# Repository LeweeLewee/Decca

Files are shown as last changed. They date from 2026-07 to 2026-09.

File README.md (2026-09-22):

# Decca music-centre restoration

ESP32 firmware, hardware and mechanical design for restoring a 1960s Decca
music centre while preserving its original controls and appearance.

The ESP32 provides control and user interface only. Audio remains outside it:
the locked Phase 2 path is **WiiM Pro → Fosi Audio ZA3 → passive speakers**.

## Current state

- Installed firmware is **v0.28.6-s1**, deployed by authenticated OTA on
  2026-09-21. TX power explicitly requests 20 dBm (19.5 dBm readback); Wi-Fi
  sleep remains disabled. Packet loss remains open as **FW-WIFI-01**. The
  following physical acceptance was recorded on v0.28.4. Digital and vinyl audio, metadata, volume/app
  synchronisation, left/right channels, logical standby/resume, source response,
  network recovery and direct WiiM-to-ZA3 trigger acceptance pass. The owner confirmed all formal noise/interference checks passed with no
  issues on 2026-09-21, completing Phase 2 physical acceptance.
- Security resource-limit update is deployed; fresh version discovery and OTA
  authentication rejection passed. The owner confirmed physical checks passed on 2026-09-22. See
  [deployment record](docs/OTA%20Candidate.md).
- Safe board initialisation and authenticated local-network OTA are implemented.
- Four analogue controls and the SH1106 OLED are bench-verified.
- The reliable VHF contact is the sole source input:
  VHF latched = Digital Streamer; every other selector position = Vinyl.
- GPIO25/D25 is assigned to the Stereo/Mono contact as a lighting request:
  Stereo open = lights on immediately; Mono closed = lights off immediately
  after the 25 ms debounce. Firmware logic is correct,
  but the retained physical switch is faulty and remains open as HW-SW-01.
- The display, buttons, pots, settings, lighting and logical power modules are
  implemented and independently tested.
- The Phase 2 WiiM module is implemented as a background HTTPS worker for source,
  direct absolute volume over a reusable connection, power-state and metadata
  coordination. Logical power-on sends a safe one-step downward volume pulse,
  then restores the requested value, so a stopped network session wakes the
  WiiM trigger without starting playback or exceeding the selected volume.
- The OLED reports controller Wi-Fi strength in the top-left header and
  distinguishes controller-network loss from an unresponsive WiiM. Passive
  telemetry updates while already in standby do not wake the sleeping panel.
- Production coordinates power, all four pots, the VHF-derived source state and
  the accepted OLED views, and 85% Stereo/off Mono dial lighting while
  continuously servicing authenticated OTA.
- USB-to-OTA, GPIO14 power, GPIO26 VHF source selection and the fitted display
  are complete. The DFR0457 replacement stage is installed and its initial
  steady-light test resolved the flicker. Firmware v0.28.4 retains immediate
  lighting transitions. Physical transition verification after HW-SW-01, WAGO
  distribution, pot stability, temperature and current remain open as
  HW-LGT-01. Normal Stereo lighting is 85%; Mono and logical standby request off.
- v0.27.4 removes the fade engine: Stereo/Mono and logical power changes now
  apply the required LED duty immediately.
- ESP32 controller housing Rev C was printed, fitted, wired and installed as a
  prototype on 2026-09-07. Its CAD/mesh gates pass; seven prototype and two
  installation gates remain before production release.
- IEC C14 mounting plate Rev B is the active corrected-profile design. Its
  15/15 CAD checks pass and the owner confirmed the profile drawing; physical
  fit remains pending. Rev A is rejected.
- The completed 2026-09-06 ADC/PWM noise report and its 12,000-row raw capture
  are retained under `diagnostics/` as historical v0.27.1 evidence.

Read [Development Handover](docs/Development%20Handover.md) before continuing
firmware work, then check [Open Issues](docs/Open%20Issues.md).

## Locked controller map

| Function | ESP32 | Status |
|---|---:|---|
| Volume | GPIO32/D32 | Bench-verified |
| Bass | GPIO33/D33 | Bench-verified |
| Treble | GPIO34/D34 | Bench-verified |
| Balance | GPIO35/D35 | Bench-verified |
| VHF source contact | GPIO26/D26 | Physically verified |
| OLED SDA | GPIO21/D21 | Bench-verified |
| OLED SCL | GPIO22/D22 | Bench-verified |
| On/off | GPIO14/D14 | Physically verified |
| Stereo/Mono lighting request | GPIO25/D25 | Firmware logic verified; physical switch fault open under HW-SW-01 |
| Dial lighting PWM | GPIO18/D18 | DFR0457 installed and operating; final checks open under HW-LGT-01 |

Final OLED loom: Brown GND, Red 3V3/VCC, Orange SCL and Yellow SDA.

## Repository guide

- [Specification](docs/Specification.md)
- [Firmware architecture](docs/Firmware%20Architecture.md)
- [Hardware architecture](docs/Hardware%20Architecture.md)
- [Authoritative wiring](docs/Wiring.md)
- [Build and commissioning guide](docs/Build%20Guide.md)
- [Parts list](docs/Parts%20List.md)
- [Decision records](docs/adr/)
- [Development handover](docs/Development%20Handover.md)
- [Open issues](docs/Open%20Issues.md)
- [Branch disposition register](docs/Branch%20Disposition.md)
- `src/`: firmware modules
- `test/`: PlatformIO suites
- `hardware/`: BOM, wiring and electrical design
- `mechanical/`: CAD, drawings and print files
- `diagnostics/`: completed diagnostic evidence; not production firmware

## Windows build tools

If `pio` is not recognised in PowerShell, use the executable installed by the
PlatformIO VS Code extension:

```powershell
$pio = "$env:USERPROFILE\.platformio\penv\Scripts\platformio.exe"
& $pio --version
& $pio run -e esp32dev
& $pio test -e esp32dev
```

The first OTA bootstrap and commissioning procedure is in the
[Build Guide](docs/Build%20Guide.md). Never commit `src/secrets.h`.

## Engineering rules

Firmware modules remain independent and are coordinated in `main.cpp`. Update
paths must be non-blocking, persisted state belongs in `settings`, and hardware
changes must be reconciled across the pin map, wiring, BOM and revision history.

See [CONTRIBUTING.md](CONTRIBUTING.md) for code and commit conventions.

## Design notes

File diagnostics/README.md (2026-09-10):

# Diagnostics archive

## ADC/PWM noise capture — 2026-09-06

The report, device summary and 12,000-row raw capture preserve the completed
controlled comparison between 85%/1 kHz PWM and constant-high operation. The
test ran diagnostic firmware v0.27.1 on the former GPIO25 lighting route.

The result is historical evidence, not current firmware: PWM switching was a
modest contributor to raw ADC noise, while the normal filter/deadband path
produced no UI-sized filtered excursions in either phase. No brightness or
production-filter change was justified by the result.

Current production firmware is v0.27.4, lighting PWM is on GPIO18, and all fade
logic has been removed. The diagnostic-only firmware hooks were intentionally
not copied into production because they depend on the superseded fade API and
old GPIO route. The report and raw data are the authoritative retained record.

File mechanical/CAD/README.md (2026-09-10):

# CAD

Source (editable, parametric) mechanical design files.

## ESP32 controller housing — Rev C installed prototype

Rev C is the current housing geometry. The owner printed, fitted, wired and
installed it on 2026-09-07; it fitted first time. The package remains a
prototype rather than a production release because seven prototype gates and
two installation gates remain open in the v1.7 specification.

- `Decca_ESP32_Controller_Housing_fusion.py` is the parametric generator.
- `Decca_ESP32_Controller_Housing_verify.py` independently verifies the STLs.
- `Decca_ESP32_Controller_Housing_slice.py` records slicer evidence.
- `Decca_ESP32_Controller_Housing.f3d` and the STEP files are the editable and
  neutral CAD deliverables.

Rev A and Rev B are superseded. The controlling documents are
`../Drawings/Decca_ESP32_Controller_Housing_Spec_v1.0.md` (content revision
v1.7) and `../Drawings/Decca_ESP32_Controller_Housing_Build_Report_revC.md`.

## IEC C14 mounting plate — Rev B active prototype

Rev B replaces the rejected rectangular Rev A opening with the measured
six-sided C14 profile. Its generated STEP/STL passed all 15 CAD checks and the
owner confirmed the drawn profile. Physical inlet/cabinet fit and rear terminal
clearance remain mandatory before release. Rev A sources are retained only for
traceability and must not be used for installation.

**Intended contents**
- Fusion 360 archives (`.f3d`) and/or OpenSCAD (`.scad`) source.
- Neutral exchange formats (STEP `.step`) for interop.

**Conventions**
- Keep source here; export print-ready meshes to `../STL/`.
- Parametric source is preferred so parts can be re-derived if dimensions change.
- Record revisions in `docs/Revision History.md`.

## Display bezel — current revision: **Q — COMPLETE, signed off 2026-08-31**

**Rev Q is bezel-only. The released Rev P.5 carrier is FROZEN and unchanged.**

Rev Q replaces the two Rev N side locating rails with **one continuous inset
masking wall** around the complete inside perimeter of the Perspex opening —
left, right, top, bottom and all four corners. The wall conceals the visible
cut edge and locates the bezel on an **interference fit on both axes**. It is
not a snap, not a clamp and carries no load. The two Rev N recessed adhesive
pads are DELETED at owner instruction, so retention is by the fit alone; if
adhesive is still wanted it goes on the flat seating face.

Built to brief commit `7b107f2` ("require two-loop inset wall"), then moved on
by four owner changes made on the model. Every wall carries **at least two
0.40 mm extrusion loops** — a minimum applied per side, not a fixed count.

> **THE PERSPEX OPENING HAS BEEN MEASURED, and it is not what this project
> believed.** For six revisions the model carried 35.20 × 15.30 from Rev C — a
> figure no released part had ever checked, because Rev N located on two side
> rails only. The owner printed the 35.400 × 15.450 insert, used it as a gauge
> block and read the slop: **1.34 mm horizontal, 1.00 mm vertical**. The opening
> is **36.74 × 16.45**, and the insert is now DERIVED from it:
> `insert outer = measured opening + declared interference`. Re-measuring is a
> two-number edit. Treat the reading as ±0.2 mm; a second iteration is expected.
> Build report §3.10.

| File | Role |
|---|---|
| `Decca_Display_Bezel_revQ_fusion.py` | **the generator — single source of truth for every Rev Q dimension** |
| `Decca_Display_Bezel_revQ_verify.py` | independent offline verification of the exported STL (numpy only) |
| `Decca_Display_Bezel_revQ_frozen_check.py` | proves the six frozen Rev P.5 files still match the Rev Q brief — run before and after any Rev Q work. Hashes text files as-is, forced LF and forced CRLF, so a line-ending difference cannot masquerade as tampering |
| `Decca_Display_Bezel_revQ.f3d` | **editable source** — named parameters, derived values written as real formulas |
| `Front_Bezel_revQ.step` | the bezel alone |
| `Decca_Display_Bezel_revQ_assembly.step` | bezel + measured Perspex + OLED glass proxy + the **unchanged Rev P.5 carrier**. Does **not** overwrite `Decca_Display_Mount_revP_assembly.step` |
| `Bezel_Fit_Gauge_revQ.step` | five-tab interference fit gauge — **print this before the bezel** |

Key dimensions, each verified by two independent tools:

| | mm |
|---|---:|
| Bezel face opening, at the front face | **34.440 × 15.000**, R3.000 |
| Aperture | a **straight bore** — identical at the front face and the seating plane, taper 0.00° |
| **Perspex opening, MEASURED 2026-08-31** | **36.740 × 16.450** |
| Inset-wall outer envelope | **36.940 × 16.600** — derived, opening + fit |
| Inset-wall inner envelope (derived) | 34.440 × 15.000 — **flush with the face opening on all four sides** |
| Wall | **1.250 sides** (3.125 loops) / **0.800 top+bottom** (2.000 loops) |
| Outer / inner corner radius | **R4.250** / R3.000 (derived from the side wall) |
| Wall depth | **2.800** into the 3.00 mm Perspex — 2.300 tried and reverted |
| Horizontal fit | **0.100 INTERFERENCE per side** |
| Vertical fit | **0.075 INTERFERENCE per side** |
| Entry lead-in | 0.200 × 45°, outer rear edge only — tip is 0.100 / 0.125 mm per side UNDER the opening |
| Rearmost material | z = **+0.200** — 0.200 clear of the Perspex rear face |
| Clearance to the OLED glass | **0.500** — the brief minimum, and the released Rev N/P value |
| Minimum distance to the Rev P.5 carrier | **0.339** — carry this forward |
| Effective clear optical opening | **34.440 × 15.000**, R3.000 |
| Seating face | one unbroken annulus, 210.867 mm² (adhesive pads deleted) |
| Volume | 0.5951 cm³ ≈ 0.76 g in PETG |

**52/52 gates PASS** in Fusion; **47/47 PASS** offline from the mesh. One shell,
one lump, zero slivers, no degenerate triangles; the wall's cross-section area
matches the analytic value to four decimals at three depths and in every region
including the corners; the interference is exactly 0.100 mm per side across and
0.075 mm up, nowhere more, and vanishes when the declared relief is applied;
zero interference with the OLED glass or the carrier; nothing behind the
Perspex rear face.

> ## Signed off — 2026-08-31
>
> **The bezel is complete.** Confirmed on printed parts: the interference
> fit, the opening corner (R4.25 a good match) and the opening dimensions
> themselves. A 2.30 mm insert depth was tried and **reverted** when the
> bottoming-out that prompted it turned out to be a printing issue rather
> than the geometry — the depth is back at the proven Rev N 2.80 mm.
>
> **Not separately reported at sign-off:** the slicer two-loop preview and
> the powered visibility test. Parts printed and fitted, so the wall
> evidently laid, but neither was run as a check.
>
> **One figure to carry forward:** the bezel passes within **0.339 mm** of
> the frozen Rev P.5 carrier. Zero interference, and it has been assembled,
> but worth re-checking if either part is reprinted on a different machine.
> Build report §3.11–§3.12.

> **The fit is the primary gate.** 0.100 / 0.075 mm per side is an ordinary
> press fit on paper, but acrylic is brittle and takes up interference by
> storing stress rather than deforming, the 1.25 mm side wall is ≈31× stiffer
> in bending than the original 0.40 mm, and **print tolerance is the same size
> as the fit** — ±0.10 mm on a small external dimension, so 0.100 mm intended
> arrives anywhere between 0.00 and 0.25 mm. No CAD check can touch that.
> **Print `Bezel_Fit_Gauge_revQ` first** — five tabs at
> 0.00/0.05/0.10/0.15/0.20 mm, which now brackets the declared value two either
> side, each carrying the real wall section, the full 16.60 mm height, the
> 2.80 mm depth and both R4.25 corners — and the sweep brackets the ±0.2 mm
> **measurement** error as well as the fit. Also plan on adhesive: **PETG
> creeps**, so a press fit slackens over months. Build report §8.1, §8.4.

> **The loop rule is a PRODUCTION gate, not a CAD one.** CAD proves the
> geometry admits the loops: sides 1.250/0.400 = 3.125, top and bottom
> 0.800/0.400 = 2.000 exactly, measured at all 720 stations (min 0.7950, max
> 1.2500) including 368 corner stations, loop centrelines 0.400 apart with
> corner radii 4.050 and 3.650 and no cusp — the easiest to slice at any issue.
> Only the slicer preview can prove it lays them. Build report §7.1 and §10
> Stage 0b.

> **The opening corner is largely closed — by a printed part.** The owner offered
> the R4.25 insert into the real opening and reports the corner **a good match**,
> retracting an earlier appearance-based revert in as many words. At R4.25
> against the measured opening the **flanks set the fit for every plausible
> opening corner**: penetration never leaves 0.100 mm from a sharp corner all the
> way to R4.00. `panel_open_corner_r` stays 0.00 in the model, because a
> qualitative match is evidence rather than a measurement and modelling the
> opening sharp keeps every figure at its worst case. Build report §8.3.

> **Seven owner changes on top of the brief, each recorded and each reversible.**
> (1) adhesive pads **deleted**; (2) outer corner **R2.00 → R3.00**; (3) aperture
> made **flush** on the left and right, loop rule clarified to **at least** two
> per side; (4) the **interference-fit refinement**, which appeared not to fit;
> (5) the **pull-back**; (6) the corner **reverted to R3.00** on the render;
> (7) **the opening measured** — which restored the corner to R4.25 on physical
> evidence, showed the recorded opening was 1.54 × 1.15 mm small, and made the
> insert derive from the measurement; (8) **the depth cut 2.80 → 2.30** after a
> printed part bottomed out before seating; and (9) that cut **reverted** when
> the cause proved to be a printing issue, followed by **sign-off**. Build report
> §3.5 to §3.12.

> **The wall no longer costs lit screen height.** The clear opening is
> 34.44 × 15.00, controlled by the skirt on all four sides with the face
> opening flush to it, and the visible active band goes 8.100 → **8.150 mm** —
> **above Rev N for the first time**, because the opening was always bigger than
> recorded. What is worth judging instead is the noticeably slimmer black
> border: the bezel flange is now 1.530 mm at the sides. Build report §5.

> **The aperture does not taper.** With the face opening flush to the skirt on
> all four sides there is nothing to blend, so the bore is straight from the
> front face through to the wall tip — no ledge, no set-back, no corner
> crescent. The forced Y taper earlier issues carried is designed out, and the
> generator **refuses to build** if the face opening drifts away from the skirt
> inner envelope. The window edge break is a 0.40 chamfer rather than the Rev N
> R0.40 fillet, because Fusion refuses a fillet on that edge at every radius.
> Build report §3.3 and §3.4.

### Rebuilding Rev Q

Inside Fusion (Utilities → Add-Ins → Scripts), point `OUT_DIR` at this clone's
`mechanical` folder and run `main()`, `import_carrier()`, `coupon()`,
`fit_study()`, `validate()`, `export()` and `snapshots()`. `main()` creates its
own new document and never opens, modifies or saves the Rev N, Rev O or Rev P
documents; `export()` refuses, in code, to write any path whose basename
contains `revN`, `revO` or `revP`. Then, offline:

```bash
python mechanical/CAD/Decca_Display_Bezel_revQ_verify.py
python mechanical/CAD/Decca_Display_Bezel_revQ_frozen_check.py
```

`Front_Bezel_revN.step` remains the last **released** bezel and is untouched.

---

## Display mount — current revision: **P.5 — RELEASED**

**The Rev P.5 carrier has been manufactured, installed and physically tested,
and every test passed:** Perspex fit and tolerances; OLED front insertion and
removal; all four sprung posts and retention; no collision with the original
Decca lighting unit; bottom / open connector-side clearance; the reduced
6.00 mm thickness; the enlarged 14.00 × 4.19 mm connector opening; the rear
closure and light-blocking features; the original fasteners and captive nuts;
49.00 mm horizontal pitch; the mounting points 7.00 mm lower giving the
required OLED position; and installed fit, screen position, stiffness,
retention, clearance and powered operation.

Rev P.2 is the corrected **flush-side-insertion** architecture, and it **passed**
its physical OLED-retention and Perspex-fit tests. **Rev P.3** amended only the
radio-side interface: the lighting-unit clearance cut and the original Decca
bolt / captive-nut interface that replaces the deleted M2 heat-set inserts.
**Rev P.4** makes two bounded corrections on top of that:

- the **synthetic lighting-unit keepout is deleted** — component, body,
  generator function, derived geometry, intersection checks and exports. Its
  boundary was asserted from the carrier's own pedestals, not measured off the
  radio, so it proved nothing and misrepresented the assembly. Nothing replaces
  it, and the physical rail cut it was invented to justify is kept exactly as
  printed. **Installed clearance is proven by physical test only** — see the
  build review §20.6;
- the **rear of the OLED bay is closed** by a 1.20 mm integral opaque light
  shield, part of the carrier, with a single local four-pin/header opening —
  build review §24.

**Rev P.5** is a mandatory amendment that changes load-bearing numbers:

- both **plain locating posts are deleted** and replaced by sprung
  locating-and-retaining posts — all four PCB mounting holes now hold a split
  sprung post, and no plain-post parameter, body, branch or probe survives;
- the complete OLED reference is rotated **180° in plane**, so the four-pin
  connector is at the **bottom**. The panel-fixed holes do not move. **The open
  lighting-unit end of the carrier travelled with the module, +Y → −Y**;
- both carrier fixing centres then move **7.00 mm toward that bottom** relative
  to the OLED group (`carrier_fix_y_from_previous = -7.00 mm`). The Perspex
  holes are untouched, so the equivalent — and the only implementation that
  lands the carrier holes *on* them — is to raise the OLED bay **+7.00 mm**.
  This **supersedes** the earlier active-area-bottom-to-opening-bottom rule and
  every PASS based on it;
- the carrier drops to **6.00 mm** deep, the finished rear opening grows 25 % to
  **14.00 × 4.19 mm**, and two integral **light-block** baffles are added
  beside it, running out into the sprung pedestals.

Nothing numeric is inherited: the depth reduction shortens every cantilever, so
the split slot goes 0.70 → 1.20 mm and the root relief 3.20 → 2.00 mm. Build
review §25.3 has the recalculation.

> **The screen is no longer fully visible.** Only **8.30 mm** of the 14.70 mm
> active height falls inside the Perspex opening; about **6.40 mm — 44 % —**
> sits behind the fascia above it, and the lowest 7.00 mm of the opening shows
> unlit board. Both tools **report** this and neither passes a check on it.
> Whether the intended screen information is still readable is a question only
> the powered fit test can answer. Build review §28.3.

> **The bonded-glass boundary is now THE print gate.** The two converted posts
> put a nose ahead of the PCB at holes the plain posts never reached, and the
> modelled glass envelope — which has never been measured, and which puts the
> glass over the mounting holes — says it fouls by 0.40 mm. Both tools report
> those checks as **BLOCKED**, not passed and not failed. Measure the boundary,
> enter it, set `oled_glass_measured` / `GLASS_MEASURED`, and they become
> ordinary hard gates. Build review §25.4.

The `.f3d` is the source of truth; the STEPs and the STL are derived exports.

| File | Role |
|---|---|
| `Decca_Display_Mount_revP.f3d` | **editable source of truth** — fully parametric, 192 named user parameters |
| `Decca_Display_Mount_revP_fusion.py` | the generator that builds the `.f3d`; single source of truth for every dimension |
| `Decca_Display_Mount_revP_verify.py` | independent offline verification of the exported STL (numpy only) |
| `Rear_Display_Carrier_revP.step` | the one structural part |
| `Decca_Display_Mount_revP_assembly.step` | carrier + Perspex + OLED + bezel + **original nuts / bolt envelope** references. **No lighting-unit keepout proxy** — Rev P.4 deleted it, and both tools assert its absence |
| `Hex_Pocket_Fit_Coupon_revP.step` | five-station captive-nut pocket fit coupon — print this **before** the carrier |
| `Front_Bezel_revN.step` | cosmetic bezel — **unchanged, still the file of record for Rev P**. Superseded for new work by the signed-off Rev Q above |

Rev N files are retained as the last front-loaded design:
`Decca_Display_Mount_revN.f3d`, `Decca_Display_Mount_revN_assembly.step`,
`Rear_Display_Carrier_revN.step`, `Retainer_Bar_revN.step`. The Rev P
architecture deletes the retainer bar, so `Retainer_Bar_*` has no Rev P
equivalent.

### Rebuilding

Inside Fusion (Utilities → Add-Ins → Scripts), point `OUT_DIR` at this clone's
`mechanical` folder and run `main()`, `validate()`, `import_bezel()`,
`snapshots()`, `export()`, and `coupon()`. `main()` creates its own new document
and never modifies the Rev N or Rev O files; `snapshots()` regenerates the five
Drawings PNGs from the live model; `coupon()` builds and exports the hex-pocket
fit coupon in its own document. Then, offline:

```bash
python mechanical/CAD/Decca_Display_Mount_revP_verify.py
```

It reads only the exported STL and exits non-zero on failure, so it works as a
gate. See `../Drawings/Decca_OLED_Display_Mount_CAD_Build_revP.md` §13 for why
it is deliberately not a second run of the same recipe — and for the silent
Fusion `createTorus` failure it caught.

> **Rev P.5 is RELEASED.** Every item that was outstanding here — the
> bonded-glass clearance, the original nut and bolt fit, the hex-pocket
> allowance, installed lighting-unit clearance, the light-leak test and the
> powered fit — was closed by the built and tested prototype. Both tools record
> them as `[TEST]`, and neither check was changed to get there.

> **What is still a modelling caveat, and is not a blocker.** Two inputs in
> the parameter table were never measured, and the prototype passing did not
> measure them:
>
> - `oled_glass_w` / `_h` / `_off_y` — the bonded-glass envelope is still the
>   placeholder that puts glass over the mounting holes. The built part clears
>   the real glass; the **model** does not describe it. `oled_glass_measured`
>   stays `False`;
> - *(resolved 2026-08-30 — `original_nut_hex_width` was here; the 3.80 mm
>   across-flats reading is **confirmed**, so it is a measured value now)*
> - the original bolt length under the head. The bolts engage and clamp; the
>   length itself was not recorded.
>
> These matter only if the geometry is regenerated with changed dimensions. As
> built, the part is proven. Anyone changing a post, a nose, the glass keep-out
> or the nut pocket must measure first.

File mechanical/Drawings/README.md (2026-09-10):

# Drawings

Dimensioned engineering drawings for fabrication, measurement, and reference.

## ESP32 controller housing — Rev C installed prototype

`Decca_ESP32_Controller_Housing_Spec_v1.0.md` is the controlling v1.7
specification. `Decca_ESP32_Controller_Housing_Build_Report_revC.md` records the
verified build and the owner's 2026-09-07 printed, fitted, wired and installed
prototype. It fitted first time, but seven prototype and two installation gates
remain open. The Rev B report is retained as superseded history.

## IEC C14 mounting plate — Rev B active / physical fit pending

`Decca_IEC_C14_Mounting_Plate_Spec_revB.md` and its Rev B build report control
the corrected six-sided inlet profile. All 15 CAD checks pass and the owner
confirmed the profile drawing. Rev A is rejected; its specification, report and
view remain only as an explicit failure record. Do not print or install Rev A.

**Intended contents**
- PDF drawings with critical dimensions and tolerances.
- Reference sketches for cabinet fit and mounting.

## Active OLED mount design direction

`Decca_OLED_Display_Mount_CAD_Review_revO.md` is the authoritative carrier
architecture brief. It includes the 2026-08-29 Rev P physical-retention
correction: flush-side insertion onto fixed rear PCB datums, positive sprung-post
handling retention, and no release until the corrected print passes physical
retention tests. The 2026-08-29 integration amendment additionally makes the
original Decca lighting unit a mandatory physical clearance interface and
deletes the continuous carrier end rail / cable-tie projection below the
sprung-post pair as installed.
The same open Rev P correction now also deletes the M2 heat-set inserts and
replacement M2 screws: the original non-standard-thread Decca front bolts and
their matching six-sided captive nuts are reused at the unchanged 49.00 mm pitch.
The Rev P.3 follow-up rejects the unmeasured synthetic lighting-unit keepout
component and requires an integral opaque rear wall over the OLED bay, with only
a local four-pin/header opening, to prevent cabinet-light contamination.
The Rev P.5 packaging correction reduces carrier depth from 8.00 to 6.00 mm,
enlarges the finished pin opening by 25% in both axes to 14.00 × 4.19 mm, adds
two internal side light blocks within the back-plate envelope, places the
four-pin side at the bottom and moves both carrier fixing points 7.00 mm toward
that bottom relative to the OLED group. The original Perspex holes remain fixed
at 49.00 mm pitch, so this raises the screen 7.00 mm relative to the earlier
bottom-edge-aligned datum.
The same Rev P.5 amendment converts the two remaining plain locating posts to
sprung retaining posts, giving four sprung posts subject to measured glass
clearance, combined-force, PCB-bow and deliberate-release validation.

The released Rev P.5 carrier is now frozen. The active follow-on work is the
**Rev Q bezel-only amendment** in
`Decca_OLED_Display_Bezel_CAD_Brief_revQ.md`: replace the Rev N side-only
locating rails with a continuous inset masking wall around the complete Perspex
opening. A brief amendment and four owner changes have since re-scoped it — to
an interference fit with rounded corners and a larger visible opening, to a wall
carrying **at least two continuous 0.40 mm loops per side** rather than the
single loop the original 0.40 mm wall produced, and finally to an aperture that
is **flush with the skirt on all four sides**. Rev Q must not change the
carrier.

## Display bezel — Rev Q, **COMPLETE — signed off 2026-08-31**

**Rev Q is built, modelled, validated, printed, fitted and signed off by the
owner on 2026-08-31.** Built to brief commit `7b107f2` ("require two-loop
inset wall") plus four owner changes made on the model. The bezel is one
connected manifold solid: the Rev N face, envelope and external radii are
carried over, and the two Rev N side rails are replaced by a single continuous
inset masking wall, 2.30 mm deep, around all four sides and all four corners.
The wall is **1.25 mm on the sides** — thick enough for its inner face to sit
flush with the face opening, with no set-back — and **0.80 mm top and bottom**.
The bezel face opening is flush with the skirt on all four sides, so the
aperture is a straight bore with no taper. The two Rev N recessed adhesive pads
are deleted at owner instruction, so the underside is one unbroken seating face.

> **The opening has been measured, and it was not what the project believed.**
> 36.74 × 16.45, not the 35.20 × 15.30 carried from Rev C — which no released part
> had ever checked. The skirt is now **36.94 × 16.60**, derived from that
> measurement plus 0.100 mm per side across and 0.075 mm per side up. Treat the
> reading as ±0.2 mm; a further iteration is expected. Build report §3.10.
>
> **It fits, and it is signed off.** Confirmed on printed parts: the fit, the
> opening corner and the opening dimensions. A 2.30 mm depth was tried and
> reverted — the bottoming-out was a printing issue, not the geometry. The slicer
> two-loop preview and the powered test were not run as checks and are recorded
> as not-run rather than passed. Build report §3.11–§3.12.

| File | Role |
|---|---|
| `Decca_OLED_Display_Bezel_CAD_Brief_revQ.md` | **governing Rev Q brief** — the controlled requirement |
| `Decca_OLED_Display_Bezel_revQ_Build_Report.md` | **Rev Q build report and validation record — start here** |
| `Decca_OLED_Display_Bezel_revQ_front.png` | front view |
| `Decca_OLED_Display_Bezel_revQ_rear.png` | rear view |
| `Decca_OLED_Display_Bezel_revQ_oblique.png` | oblique |
| `Decca_OLED_Display_Bezel_revQ_lip_oblique.png` | rear three-quarter — the wall as a continuous closed ring |
| `Decca_OLED_Display_Bezel_revQ_assembly.png` | seated on the measured Perspex, clear of both fixing holes |
| `Decca_OLED_Display_Bezel_revQ_section.png` | section on x = 0 |
| `Decca_OLED_Display_Bezel_revQ_section_detail.png` | **the wall masking the Perspex cut edge** |
| `Decca_OLED_Display_Bezel_revQ_optical.png` | the lit OLED area behind the aperture, to scale |

The eight PNGs are generated by `snapshots()` in the Rev Q generator, so they
document the geometry that is actually in `Decca_Display_Bezel_revQ.f3d`.

Validation: **52/52 gates PASS** in Fusion and **47/47 PASS** in the independent
offline mesh verifier. One shell, one lump, zero slivers, no degenerate
triangles. Continuity is proved by **cross-section area**, which matches the
analytic value to four decimals at three depths and in every region including
the four R4.25 corners — a stronger proof than point sampling, since any gap or
thin spot anywhere removes area.

| | mm |
|---|---:|
| Bezel face opening, at the front face | **34.440 × 15.000**, R3.000 |
| Inset-wall outer / inner envelope | **36.940 × 16.600** / 34.440 × 15.000 (flush, all four sides) |
| Wall / corner radii | **1.250 sides / 0.800 top+bottom** / R4.250 outer, R3.000 inner |
| Insert depth | **2.800** — 2.300 tried and reverted, the cause was a print issue |
| Aperture | a straight bore — taper 0.00° |
| Fit | **0.100 interference** per horizontal side, **0.075 interference** per vertical side |
| **Effective clear optical opening** | **34.440 × 15.000** |

> **Three things the prototype must settle, and CAD cannot.**
>
> 1. **The fit.** 0.100 / 0.075 mm per side is ordinary on paper, but acrylic
>    stores stress rather than deforming, the 1.25 mm side wall is about **31×
>    stiffer in bending** than the original 0.40 mm, and **print tolerance is the
>    same size as the fit**. Print `Bezel_Fit_Gauge_revQ` first; it is mandatory,
>    not advisable. Build report §8.1.
> 2. **The opening measurement**, at ±0.2 mm — twice the interference it sets.
>    The gauge sweep brackets it, so one print resolves both. The opening
>    **corner** is largely closed: the owner's offer-up found R4.25 a good match,
>    and at R4.25 the flanks set the fit for every plausible corner. Build report
>    §8.3, §8.4.
> 3. **The optical result.** The clear opening is 32.90 × 13.85, the lit band
>    goes 8.100 → **8.150 mm** — above Rev N for the first time. Judge the
>    noticeably slimmer black border instead. A powered-test decision. Build
>    report §5.

> **A forced modelling decision, since designed out.** While the face opening
> was taller than the whole wall, a straight-walled aperture would have left the
> top and bottom wall runs detached from the bezel face, so the aperture tapered
> in Y. Making the face opening flush with the skirt on all four sides removed
> the condition: the aperture is now a straight bore, and the generator refuses
> to build if the two drift apart. Build report §3.3.

> **Eight owner changes on top of the brief, each recorded and each reversible.**
> The adhesive pads **deleted**; the outer corner **R2.00 → R3.00**; the aperture
> made **flush on the left and right** with the loop rule clarified to **at
> least** two per side; the **interference-fit refinement**; the **pull-back**;
> the corner **reverted to R3.00** on the render; **the opening measured** —
> which restored R4.25 on physical evidence and made the insert derive from
> the measurement; the **depth cut 2.80 → 2.30 mm** after a printed part fitted
> but bottomed out; and that cut **reverted** when the cause proved to be a
> printing issue, followed by **sign-off**. Build report §3.5 to §3.12.

## Display mount

| File | Role |
|---|---|
| `Decca_OLED_Display_Mount_Spec_v1.0.md` | approved specification, **now at v1.2** (the filename keeps `v1.0` for link stability). §2 holds the **measured and locked** Decca interface geometry: opening 35.20 × 15.30, fixing pitch **49.00 mm**. §4 opens the Rev Q bezel-only amendment. |
| `Decca_OLED_Display_Bezel_CAD_Brief_revQ.md` | **governing Rev Q bezel brief** — continuous thin masking lip around the complete Perspex opening; Rev P.5 carrier frozen |
| `Decca_OLED_Display_Mount_CAD_Review_revN.md` | last front-loaded build (Rev N) |
| `Decca_OLED_Display_Mount_CAD_Review_revO.md` | **the governing brief**, as amended 2026-08-29 by the Rev P physical-retention correction |
| `Decca_OLED_Display_Mount_Topology_revP.md` | Rev P pre-CAD topology gate. **Rev P.2 corrected topology** — flush-side insertion, fixed rear datum pads, positive stops in both axial directions; §13 the Rev P.4 rear light shield; §14–§16 the Rev P.5 four-post conversion, 180° datum and 6.00 mm depth |
| `Decca_OLED_Display_Mount_CAD_Build_revP.md` | **Rev P.5 build review and validation record** — start here |
| `Decca_OLED_Display_Mount_revP_posts.png` | **Rev P.5 carrier from the front — FOUR split sprung posts, one in every PCB mounting hole. Connector at the bottom; the two light blocks flank the four-pin opening and run out into the bottom pedestals** |
| `Decca_OLED_Display_Mount_revP_views.png` | **Rev P.5 assembly, straight on through the Perspex — where the active area actually sits in the opening after the 7.00 mm mounting correction. Rendered with appearances so it can be read: green active area, translucent fascia** |
| `Decca_OLED_Display_Mount_revP_rear.png` | **Rev P.5 rear three-quarter — the continuous integral light shield, the four post relief bores, the enlarged 14.00 × 4.19 mm four-pin opening at the bottom, and the two fixing bosses sitting LOW relative to the connector-side carrier after the 7.00 mm correction. No lighting keepout component is present** |
| `Decca_OLED_Display_Mount_revP_sections.png` | Rev P.5 section at x = +15, through a sprung locating post, with the Perspex, glass and PCB |
| `Decca_OLED_Display_Mount_revP_nut.png` | Rev P.5 half-section through a fixing centre — the bolt bore, hex head seat, retaining ridge and the original nut |

The five PNGs are generated by `snapshots()` in the Rev P generator, so they
always document the geometry that is actually in the `.f3d`.

Current mechanical revision: **P.5 — RELEASED**.

**The carrier has been manufactured, installed and physically tested, and every
test passed:**

| Test | Result |
|---|---|
| Perspex fit and tolerances | **PASS** |
| OLED front insertion and removal | **PASS** |
| All four sprung posts, retention | **PASS** |
| No collision with the original Decca lighting unit | **PASS** |
| Bottom / open connector-side clearance | **PASS** |
| Reduced 6.00 mm carrier thickness | **PASS** |
| Enlarged 14.00 × 4.19 mm four-pin connector opening | **PASS** |
| Rear closure and light-blocking features | **PASS** |
| Original fasteners and captive nuts | **PASS** |
| Horizontal mounting-hole pitch 49.00 mm | **PASS** |
| Mounting points 7.00 mm lower — required OLED position | **PASS** |
| Installed fit, screen position, stiffness, retention, clearance | **PASS** |
| Powered operation | **PASS** |

Everything below is the design and validation trail that got here. Where it
describes a check as open, blocked or awaiting a test, **that item is closed by
the prototype** — build review §29.

**Rev P.2 passed physically** for OLED retention and Perspex fit. That
architecture — flush-side insertion, fixed rear datum pads, plain and sprung
locating posts, the snap retention and release, the OLED Z position and 0.30 mm
gap, active-area centring, the 35.20 × 15.30 aperture, the exact 49.00 mm pitch,
the carrier-to-Perspex hard stops and the existing bezel — is carried forward
**unchanged**.

**Rev P.3** was a bounded amendment to the radio-side interface only:

1. the continuous end rail below the sprung-post pair and its integral cable-tie
   projection collided with the retained original Decca lighting unit, and are
   **deleted** — the carrier is now an open-ended frame (build review §20);
2. the original front bolts have a **non-standard thread**, so the M2 heat-set
   insert architecture is **deleted** and the original bolts and their matching
   nuts are reused in captive hex pockets (build review §21).

**Rev P.4** corrects two things in Rev P.3, again without touching the validated
OLED architecture:

3. the **synthetic lighting-unit keepout is deleted** — `build_light_keepout()`,
   `REF_Lighting_Keepout`, `LIGHTING_UNIT_KEEPOUT`, the derived geometry that
   placed it, its intersection checks, the fastener checks against it and every
   mention in the drawings and exports. Its boundary was asserted from the
   carrier's own pedestals rather than measured off the radio, so it could never
   fail and it misrepresented the assembly. Nothing replaces it; the proven rail
   cut is kept exactly as printed (build review §20.6);
4. the **rear of the OLED bay is closed** by a 1.20 mm integral opaque light
   shield, part of the carrier, with a single local 11.20 × 3.35 mm
   four-pin/header opening and no other penetration (build review §24).

**Rev P.5** is a mandatory amendment, and unlike its predecessors it changes
load-bearing numbers:

5. both **plain locating posts are deleted** and replaced by sprung
   locating-and-retaining posts — **four sprung posts**, one per PCB mounting
   hole (build review §25);
6. the module is rotated **180° in plane**: connector at the **bottom**,
   panel-fixed holes unmoved. The carrier's open lighting-unit end travelled
   with it, +Y → −Y (§26);
7. the carrier drops to **6.00 mm**, the finished rear opening grows 25 % to
   **14.00 × 4.19 mm**, and two integral **light-block** baffles are added
   beside it (§27).

The depth reduction shortens every cantilever, so the split slot goes
0.70 → 1.20 mm and the root relief 3.20 → 2.00 mm; worst-case post strain rises
to 2.42 % against a 3.00 % limit and combined insertion force is 28.6 N.

8. both carrier fixing centres then move **7.00 mm toward that bottom**
   relative to the OLED group (`carrier_fix_y_from_previous = -7.00 mm`). The
   Perspex holes are untouched, so the equivalent — and the only implementation
   that lands the carrier holes *on* them — is to raise the OLED bay
   **+7.00 mm**. This **supersedes** the active-area-bottom-to-opening-bottom
   rule and every PASS based on it (§28).

**The screen is not fully visible, by design.** Only **8.30 mm** of the
14.70 mm active height falls inside the Perspex opening; about **6.40 mm —
44 %** — sits behind the fascia above it, and the lowest 7.00 mm of the opening
shows unlit board. Both tools report that geometry and neither passes a check on
it. **The powered fit test confirmed the resulting position is the required
one** and that the intended screen information is visible (§28.3).

*These were the gates before the build; all are now closed by the prototype.*
The powered fit and screen-position test (§28.3), the
bonded-glass boundary at all four holes (§25.4), the
nut across flats **and** across corners (§21.6), the original bolt length
(§21.6), and the hex-pocket fit coupon (§21.7). Gating release: installed
lighting-unit clearance (a **re-test**, not a regression check), rack/twist of
the open frame, the captive-nut and bolt tests, the four-post
seat/retain/release test, and the **powered light-leak test** with the carrier
printed in opaque black (§14.22).

**Neither CAD nor the mesh verifier proves the bonded-glass boundary,
lighting-unit clearance or freedom from light leakage.** None of the three was
ever measured — and all three were settled by the physical prototype instead,
which is what both tools always said would be required.

> **Modelling caveat, not a blocker.** The bonded-glass envelope and the
> original bolt length remain unmeasured placeholders in the parameter table.
> The built part works; the model does not describe those two. Measure before
> regenerating any post, nose or glass keep-out.
>
> The nut across-flats figure of **3.80 mm was confirmed on 2026-08-30** and is
> no longer a caveat.

Module preparation is unchanged — front-side solder protrusion ≤ 1.00 mm.

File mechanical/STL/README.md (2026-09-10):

# STL

Print-ready meshes exported from the CAD sources.

## ESP32 controller housing — Rev C installed prototype

Use `ESP32_Controller_Housing_Base.stl`,
`ESP32_Controller_Housing_Lid.stl`, and two copies of
`ESP32_Controller_Cabinet_Fastener_Cap.stl`. This set was printed, fitted,
wired and installed on 2026-09-07. It remains a prototype until the open gates
in the Rev C build report are closed.

## IEC C14 mounting plate — Rev B active prototype

Use `Decca_IEC_C14_Mounting_Plate_revB.stl` only for the next fit check. Rev B
is CAD-passed but physical-fit pending. `Decca_IEC_C14_Mounting_Plate_revA.stl`
is retained solely as the rejected physical-review record and must not be
printed for installation.

**Intended contents**
- `.stl` (or `.3mf`) files ready to slice and print.
- Optional print notes (orientation, supports, material) alongside each part.

**Conventions**
- STLs are derived artefacts — the editable source lives in `../CAD/`.
- Name files to match their CAD source and revision.

## Display bezel — current revision: **Q — COMPLETE, signed off 2026-08-31**

**Rev Q is bezel-only. The Rev P.5 carrier mesh below is FROZEN and unchanged.**

| File | Print notes |
|---|---|
| `Bezel_Fit_Gauge_revQ_GAUGE_I{000,005,010,015,020}.stl` | **Print these FIRST, with the production profile.** PETG, front face flat on the bed, no supports. Five end-tabs, notch-numbered 1…5, at **0.00 / 0.05 / 0.10 / 0.15 / 0.20 mm horizontal interference per side** — which brackets the declared 0.100 mm two either side. Each is the complete right-hand end of the real Rev Q wall — full **16.60 mm** height, both **R4.25** corners, the real **1.25 mm** side wall, the real **2.80 mm** depth. The sweep brackets the **±0.2 mm opening measurement** as well as the fit, so one print resolves both: a tab that drops in loose says the opening is bigger than measured, one that will not enter says it is smaller, and the notch number says by how much. ≈1.80 cm³ ≈ 2.3 g for all five. |
| `Front_Bezel_revQ.stl` | PETG, matt/satin **black**. **FRONT FACE FLAT ON THE BED, wall pointing up. No supports.** 40.00 × 20.30 × **4.00 mm**, 0.5951 cm³ ≈ 0.76 g. Every wall must slice as **at least two 0.40 mm loops** — see print gate 1. 4+ top/bottom layers or ironing on the bed face; it is the only surface anyone sees. |

> ### The fit, in one line
>
> The opening was **re-measured on 2026-08-31** and is **36.74 × 16.45**, not the
> 35.20 × 15.30 this project carried for six revisions — a figure no released part
> had ever checked. The inset wall is now **36.94 × 16.60**, derived from it:
> **0.100 mm per side across and 0.075 mm per side up**, both interference, with
> the 0.20 mm lead-in leaving the tip 0.100 / 0.125 mm per side *under* the
> opening so the part locates before it engages.
>
> Treat the measurement as **±0.2 mm** — twice the interference it sets. The fit
> gauge below brackets it. Build report §3.10, §8.4.
>
> **SIGNED OFF 2026-08-31.** The insert fits — confirmed on a printed part. A
> 2.30 mm depth was tried and reverted when the bottoming-out that prompted it
> proved to be a printing issue, so the depth is back at the proven Rev N
> **2.80 mm** and the part is 4.00 mm deep overall. Build report §3.11–§3.12.
>
> The **slicer two-loop preview** and the **powered test** below were not run as
> checks before sign-off. Parts printed and fitted, so the wall evidently laid,
> but the gates are recorded as not-run rather than passed — worth doing if the
> part is ever reprinted on a different machine or profile.

> ### Rev Q print gate 1 — AT LEAST TWO CONTINUOUS WALL LOOPS
>
> At 0.40 mm the slicer resolved the wall as a single loop, which is what the
> owner correction rejected. The rule is a **minimum of two, applied per side**;
> the sides and the top/bottom need not carry the same number, and they do not.
>
> | Setting | Value |
> |---|---|
> | Nozzle / extrusion width | **0.40 mm** |
> | Layer height | 0.15–0.20 mm |
> | Perimeters in the wall | **at least 2 on every side** — the sides take 3 (1.25 mm), the top and bottom 2 (0.80 mm) |
> | Thin-wall / gap fill | **OFF** if the slicer allows; 0.80 is a whole multiple and needs none |
> | Arachne / variable width | **acceptable and often helpful** — the two wall thicknesses differ, so a variable-width generator handles the 1.25 mm sides cleanly. Still confirm it lays ≥ 2 loops everywhere and does not merge either wall into one wide extrusion |
> | External perimeter speed | **≤ 25 mm/s** through the wall |
> | Cooling | 100 % |
> | Supports | **none** — the aperture is a straight bore and the wall is vertical |
>
> **Step through every layer of the wall in the slicer preview before
> printing.** Confirm at least two continuous 0.40 mm loops around the complete
> perimeter — three on the side runs, two on the top and bottom, and never fewer
> than two through **all four R4.25 corners**. **Reject** the profile on any of:
> a single variable-width wall, a missing second loop, gap fill substituted for
> a loop, or two loops locally merged into one wide extrusion. Fix the slicer —
> do not thicken `bezel_lip_wall_y` to work around it without recording why.
>
> **If your extrusion width is not 0.40 mm**, set `bezel_lip_wall_y` to at least
> **two** *actual* extrusion widths and regenerate; the side wall is derived
> from the flush requirement and is not yours to set. The inner envelope, corner
> radii, aperture and optical opening all follow, and the generator refuses to
> build any wall carrying fewer than two loops.

> ### Rev Q print gate 2 — THE INTERFERENCE FIT
>
> The wall is **0.100 mm per horizontal side and 0.075 mm per vertical side
> WIDER than the hole**. On paper that is an ordinary press fit. Three things
> keep it a physical gate: acrylic is **brittle** and takes up interference by
> storing stress rather than deforming; the 1.25 mm side wall is about **31×
> stiffer in bending** than the original 0.40 mm; and **print tolerance is the
> same size as the fit** — ±0.10 mm on a small external dimension means an
> intended 0.100 mm can arrive anywhere between 0.00 and 0.25 mm. Print the
> gauge first, find the largest interference that seats by hand and releases
> without marking or whitening the Perspex, and set `bezel_lip_outer_w` and
> `bezel_lip_outer_h` from the physical result before printing a bezel.
>
> **Plan on adhesive too.** PETG creeps, so a press fit that is snug on the day
> slackens over months. The recessed pads were deleted, so if the bezel must not
> drop out, adhesive goes on the flat seating face.

> ### Rev Q print gate 3 — THE OPENING CORNER
>
> **Largely closed.** The owner offered the printed R4.25 insert into the real
> opening and found the corner **a good match** — the first physical information
> about it in this project. At R4.25 against the measured opening the flanks set
> the fit for every plausible opening corner, from sharp all the way to R4.00, so
> the corner can no longer decide whether the part seats.
>
> Still worth a look on the offer-up: if a tab rocks on the corner rather than
> bedding on the flanks, the opening corner is larger than R4.25 and
> `bezel_lip_corner_r` has to go up again.

> ### What this print does optically
>
> The clear opening is **34.44 × 15.00 mm**, controlled by the skirt on all four
> sides with the bezel face opening flush to it — **larger than Rev N in both
> axes**. The visible lit band goes 8.100 → **8.150 mm**, above Rev N for the
> first time. Judge the noticeably slimmer black border instead: the bezel
> flange is 1.530 mm at the sides. The
> aperture corner is **R3.00**, restored with the R4.25 outer corner on the
> physical evidence of the offer-up.
>
> Full detail, the fit study and the test procedure:
> `../Drawings/Decca_OLED_Display_Bezel_revQ_Build_Report.md`.

> ### Nine owner changes since the brief
>
> 1. The two **recessed adhesive pads are deleted** — the underside is one
>    unbroken seating face. **Re-check removability** on the prototype.
> 2. The inset-wall outer corner went **R2.00 → R3.00**.
> 3. The aperture was made **flush on the left and right** — face opening out
>    1.00 mm per side to 32.90, side wall derived from it — and the loop rule was
>    clarified to **at least** two per side.
> 4. The **interference-fit refinement** added a loop outward on each side and
>    moved the top and bottom walls 1.00 mm out each. It overshot: 36.20 × 17.20
>    could not enter a 35.20 × 15.30 opening.
> 5. The **pull-back**: width −0.80, height −1.75, outer corner +25% to R4.25,
>    giving the 35.40 × 15.45 built here.
> 6. The corner **reverted to R3.00** on sight of the front view.
> 7. **The opening was measured** — 36.74 × 16.45, not 35.20 × 15.30 — which
>    restored the corner to R4.25 on physical evidence and made the insert derive
>    from the measurement.
> 8. **The depth was cut 2.80 → 2.30** after a printed part fitted but bottomed
>    out before the face seated.
> 9. That cut was **reverted** — the cause was a printing issue, not the geometry
>    — and the bezel was signed off. Build report §3.5 to §3.12.

`Front_Bezel_revN.stl` remains the last **released** bezel mesh and is
unchanged. The first issue's `Bezel_Corner_Gauge_revQ_*` meshes are deleted —
the corner radius is now set by the owner at R4.25, so the fit gauge
replaces the corner gauge.

---

## Display mount — current revision: **P.5 — RELEASED**

| File | Print notes |
|---|---|
| `Hex_Pocket_Fit_Coupon_revP.stl` | **Print this FIRST.** PETG, rear face flat on the bed, no supports. Five captive-nut pockets at 0.10/0.15/0.20/0.25/0.30 mm fit allowance, notch-numbered. Sets `nut_pocket_fit_allowance` from a physical part. 4.570 cm³. |
| `Rear_Display_Carrier_revP.stl` | PETG **in OPAQUE BLACK**. **Rear face flat on the bed, building forward.** No supports. 4+ top layers or ironing on the Perspex seating face. Print the **four** Ø2.80 split sprung posts slowly — they stand 4.40 mm tall on a 0.80 mm half-section (exactly two 0.40 mm perimeters). **Print the 1.20 mm rear light shield fully solid** — it is the first 6 layers, flat on the bed; solid perimeters, never sparse infill and never a single translucent skin. The two light blocks grow up off it. 56.60 × 39.15 × **6.00 mm**, 4.411 cm³ ≈ 5.6 g. |
| `Front_Bezel_revN.stl` | PETG, matt/satin black. **Unchanged for Rev P** — no revP-named file exists. Superseded for new work by the signed-off Rev Q above. |

> ## Rev P.5 is RELEASED — this mesh has been printed and tested
>
> The carrier printed from this mesh has been installed in the radio and passed
> every physical test: Perspex fit, OLED insertion and removal, four-post
> retention, lighting-unit clearance, connector-side clearance, the 6.00 mm
> thickness, the enlarged connector opening, the rear closure and light blocks,
> the original captive-nut fasteners, 49.00 mm pitch, the 7.00 mm lower
> mounting points and powered operation.
>
> Print it **in opaque black** with the rear light shield solid — that is a
> functional requirement, not a finish choice.
>
> <details><summary>The pre-build gates, retained for the record</summary>
>
> The **Rev P.2** print **passed** its OLED retention and Perspex-fit tests. This
> mesh is **Rev P.5**. Rev P.3 amended
> the radio-side interface — the lighting-unit-side end rail and cable-tie
> projection are deleted, and the M2 heat-set inserts are replaced by captive
> pockets for the original Decca nuts. Rev P.4 then deleted the synthetic
> lighting-unit keepout reference (it was asserted, never measured) and **closed
> the rear of the OLED bay** with a 1.20 mm integral opaque light shield,
> leaving only a local four-pin/header opening.
>
> **Rev P.5 then changed load-bearing numbers.** Both plain locating posts are
> deleted and replaced by sprung retaining posts — **four sprung posts now, one
> per mounting hole**. The module is rotated **180°**, putting the connector at
> the **bottom**, and both carrier fixing centres then move **7.00 mm toward
> that bottom** relative to the OLED group — which, with the Perspex holes
> untouched, raises the screen 7.00 mm in the assembly.
> The carrier drops to **6.00 mm**, the finished opening grows to
> **14.00 × 4.19 mm**, and two light blocks flank it. The shorter carrier forces
> the split slot to 1.20 mm and the root relief to 2.00 mm; worst-case post
> strain rises from 1.66 % to **2.42 %** against a 3.00 % limit, and combined
> insertion force is **28.6 N** across the four posts.
>
> **Four measurements gate this print**, and all four are in
> `../Drawings/Decca_OLED_Display_Mount_CAD_Build_revP.md`:
>
> 1. the OLED glass envelope at the two header-side mounting holes — at least
>    2.10 mm from each hole centre to the nearest bonded-glass edge (§9);
> 2. the original nut **across flats and across corners** — 3.80 mm is modelled
>    as across flats (§21.6);
> 3. the original bolt length under the head — between 5.00 and 15.00 mm (§21.6);
> 4. the **hex-pocket fit coupon**, printed first (§21.7);
> 5. **the powered fit and screen-position test (§28.3).** Install on the
>    original Perspex holes with the original bolts, confirm the open connector
>    side is at the bottom and both holes align without forcing or slotting,
>    power the OLED and **photograph** the visible active-area edges. Only
>    **8.30 mm** of the 14.70 mm active height falls inside the opening — about
>    **6.40 mm sits above it** and the lowest 7.00 mm of the opening shows
>    unlit board. CAD reports that; only the powered part can say whether it is
>    acceptable;
> 6. **the bonded-glass boundary at ALL FOUR holes (§25.4) — this one blocks the
>    print.** The two converted posts put a retaining nose ahead of the PCB at
>    holes the plain posts never reached. The modelled glass envelope says the
>    far pair fouls by 0.40 mm — and the same model puts the glass over the
>    mounting holes, which is impossible for a screw-mounted board. Measure hole
>    centre to nearest glass edge at all four holes, model it, and re-run both
>    tools. Until then the glass checks report **BLOCKED**, not passed.
>
> Then the carrier may be printed as an integration prototype — **in opaque
> black**, which is a functional requirement, not a finish choice: the rear
> light shield only works if the material does not transmit the cabinet
> lighting. If your nozzle or extrusion width is not 0.40 mm, raise
> `rear_light_shield_t` to at least three *actual* extrusion widths and
> regenerate before slicing.
>
> Release still needs, on a real part: installed clearance against the lighting
> unit — a **RE-TEST**, not a regression check, because the 180° transform moved
> the carrier's open end to the other side of the fixing bolts — a rack/twist
> check on the open frame, the captive-nut and bolt tests, the **four-post
> seat / retain / release test (§12.28)**, and the **powered light-leak test** — cabinet LEDs through their usable
> brightness range with the OLED showing black, dim and normal content, checking
> for rear glow, edge leakage, a bright patch at the pin opening, Perspex
> illumination around the aperture and any contrast loss.
>
> **No CAD or mesh check in this repository proves the bonded-glass boundary,
> lighting-unit clearance or freedom from light leakage.** None of the three has
> ever been measured; the synthetic keepout that implied otherwise was deleted
> at Rev P.4.
>
> </details>

**All six gates above are now closed by the built and tested part.** Both tools
record them as `[TEST]` and neither check was changed to get there.

> **What is still a modelling caveat, and is not a blocker.** The bonded-glass
> envelope and the original bolt length were never measured. The built part
> works; the **model** still carries placeholders for those two, and
> `oled_glass_measured` / `GLASS_MEASURED` stay `False`. Measure before
> regenerating any post, nose or glass keep-out.
>
> The nut across-flats figure of **3.80 mm was confirmed on 2026-08-30** and is
> no longer a caveat — the nut pocket can be regenerated as it stands.
>
> **One mandatory assembly-preparation step:** nothing on the OLED's display-side
> face may stand more than **1.00 mm** proud. The budget is
> `optical gap 0.30 + glass proud 0.80 = 1.10 mm`; 1.10 is the hard ceiling, aim
> for 1.00 or less. Preferred method — remove the pin header and solder the leads
> from the rear with the front-side joints dressed flush. This is a module
> preparation step, not a carrier issue: the carrier clears the tips at any
> length. See the build review §11.

Hardware is the **two original Decca bolts and their two original matching
nuts**. There are no heat-set inserts, no replacement screws and no adhesive.

Rev N meshes (`Rear_Display_Carrier_revN.stl`, `Retainer_Bar_revN.stl`) are
retained as the last front-loaded design. Rev P has no retainer bar.

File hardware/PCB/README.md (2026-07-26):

# PCB

PCB layouts and fabrication outputs for any **new** boards (e.g. a controller
carrier board), plus documentation of retained original boards.

> **Retained original selector PCB.** The original radio/source selector PCB is
> **retained in place as the mechanical carrier** for the interlocked selector
> mechanism (see ADR-0001 and `docs/Wiring.md`). It is **not disposable** and is
> not re-fabricated. Only its existing usable contact pairs are tapped.

**Intended contents (new boards only)**
- Source layout files (e.g. KiCad `.kicad_pcb`).
- Gerbers and drill files (zipped per revision) for fabrication.
- Optional 3D exports (STEP) for mechanical fit checks.

**Conventions**
- One subfolder or zip per fabrication revision; never overwrite a released set.
- Cross-reference the matching schematic revision.

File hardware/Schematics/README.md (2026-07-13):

# Schematics

Circuit schematics for the decca electronics.

**Intended contents**
- Source schematics (KiCad `.kicad_sch` / project files preferred; EasyEDA or
  other tools acceptable if noted).
- Exported PDFs for quick review without the CAD tool.

**Conventions**
- Keep source and exported PDF together and named consistently.
- Reflect any change here in `docs/Hardware Architecture.md` and, where it
  affects the ESP32, in `docs/Wiring.md` and `src/hardware.h`.
- Record revisions in `docs/Revision History.md`.

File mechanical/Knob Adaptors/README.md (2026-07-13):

# Knob Adaptors

Adaptors that mate the original front-panel knobs to modern potentiometer and
encoder shafts — preserving the period controls while using current parts
underneath.

**Intended contents**
- Parametric CAD source for each adaptor (shaft size, knob broach, tolerances).
- Print-ready STLs and per-part print notes.

**Conventions**
- Parametrise shaft diameter and fit so a variant can be produced quickly for a
  different knob or pot.

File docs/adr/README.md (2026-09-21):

# Architecture Decision Records (ADRs)

Short, immutable records of significant decisions. Each ADR captures the context,
the decision, and its consequences at the time it was made. Supersede rather than
rewrite: if a decision changes, add a new ADR and mark the old one `Superseded`.

Format: lightweight (Nygard). Status is one of `Proposed`, `Accepted`,
`Superseded`, `Deprecated`.

| ADR  | Title | Status |
|---|---|---|
| 0001 | Retain the original selector PCB as mechanical carrier | Accepted |
| 0002 | Use four 10k analogue potentiometers as position sensors | Accepted |
| 0003 | Reuse the original on/off switch and cable as a low-voltage input | Accepted |
| 0004 | Reuse VHF, MW, LW and Gram; defer SW | Superseded |
| 0005 | Leave Stereo/Mono unwired in Phase 1 | Superseded |
| 0006 | Keep WiiM Pro integration in Phase 2 | Accepted |
| 0007 | Present logical function and now-playing context | Accepted |
| 0008 | Lock WiiM Pro with separate power amplification | Accepted |
| 0009 | Omit legacy button labels from user-facing display views | Accepted |
| 0010 | Lock Fosi ZA3 and system power-control architecture | Accepted; lighting transitions superseded by 0017 and trigger implementation by 0018 |
| 0011 | Use Gram as the sole two-state source selector | Superseded |
| 0012 | Use authenticated local-network ArduinoOTA | Accepted |
| 0013 | Use VHF as the authoritative two-state source selector | Superseded |
| 0014 | Use TX2 Stereo/Mono as the dial-lighting command | Superseded |
| 0015 | Reassign dry-contact inputs for terminal-adapter routing | Superseded |
| 0016 | Finalise controller GPIO routing | Accepted |
| 0017 | Remove dial-lighting fades | Accepted |
| 0018 | Use the WiiM Pro trigger output for the ZA3 | Accepted |

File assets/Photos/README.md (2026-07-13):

# Photos

Build progress and reference photography — the visual record of the restoration.

**Intended contents**
- Before/after and in-progress build photos.
- Reference shots of original components, labels, and wiring as found.

**Conventions**
- Prefer descriptive, dated filenames (e.g. `2025-05-01-dial-removed.jpg`).

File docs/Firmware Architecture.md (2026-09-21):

# Firmware Architecture

This document defines how the decca firmware is organised and the rules that
keep it maintainable. It is the reference for both human contributors and
AI-assisted editing.

## Design Principles

1. **Independent modules.** Each module owns one responsibility and exposes a
   small, explicit interface. A change to one peripheral touches one module.
2. **No lateral coupling.** Modules do not call each other. Input modules
   (`buttons`, `pots`) never talk to output modules (`display`, `lighting`)
   directly. Coordination happens in `main`; shared state lives in `settings`.
3. **Non-blocking.** Every `update()` returns quickly. No `delay()` in the main
   path; timing is handled with millis()-style scheduling.
4. **Local-first.** The device is fully functional with no network. Networked
   features are strictly additive.
5. **Documented interfaces.** The header is the contract. Behaviour and
   dependencies are described in each `.h` file.

## Module Set

| Module | Responsibility | Depends on |
|---|---|---|
| `hardware` | Pin map and board-level init | — |
| `settings` | Persisted config + shared runtime state (NVS) | — |
| `buttons`  | Debounced on/off, sole VHF source selector and Stereo/Mono lighting request | `hardware`  |
| `pots` | Filtered ADC1 reads of the four position pots (Balance, Treble, Bass, Volume) | `hardware` |
| `display`  | OLED rendering and idle pixel protection | `hardware`, `settings`|
| `lighting` | Warm dial illumination (immediate PWM via MOSFET) | `hardware` |
| `power` | Pure logical on/standby state handling | — |
| `wiim` | WiiM Pro local-HTTPS control and status worker | `settings`, Wi-Fi |
| `ota` | Authenticated Wi-Fi firmware update service | Wi-Fi |

> The WiiM interface is implemented for Phase 2. Network requests run on a
> dedicated core-0 worker so local inputs, lighting, display and OTA coordination
> remain responsive when the streamer is slow or unavailable.

### Module notes (confirmed Phase 1 build)

- **`buttons`** reads the retained on/off switch on GPIO14/D14, the sole
  active-low VHF contact on GPIO26/D26 and the active-low Stereo/Mono contact on
  GPIO25/D25 with 25 ms software debounce. The on/off and VHF routes are
  physically verified. Stereo/Mono firmware logic is correct, while the faulty
  retained switch remains open as HW-SW-01. It exposes the stable VHF-derived source mode:
  closed = Digital Streamer; open = Vinyl. Press events do not repeat while held.
  The other interlocked positions release VHF and therefore select Vinyl
  (ADR-0016).
- **`pots`** treats the four pots as **position sensors only** (not in the audio
  path). It applies calibration, smoothing, deadband, and optional inversion, and
  emits values suitable for stable display updates (FR-POT-01..05). Sampling is
  fixed at 100 Hz; an integer low-pass filter precedes normalisation and output
  deadband so `update()` remains deterministic and non-blocking.
- **`lighting`** drives the warm dial illumination only (dial, not cabinet) via a
  logic-level N-channel MOSFET on GPIO18/D18 under PWM, with immediate duty
  updates, configurable idle brightness, and a safe boot state. It starts at
  duty 0. `main` selects the stored normal duty only when logically on and
  Stereo is requested; every change is written immediately. There is no fade
  state machine or lighting timer.
  `lighting` does not read buttons or power state directly.
- **`display`** drives the purchased 1.3-inch 128×64 SH1106 panel at I²C
  address 0x3C. Its presentation contract is defined by ADR-0007: a short
  non-blocking monochrome Decca-logo startup animation whose final frame shows
  the firmware version; standby; transient
  control views; diagnostics; and an explicit SW unavailable message. The
  production coordinator supplies all four pot values and persistent source
  state. Volume is presented as 0–100%; Bass/Treble use centred −50..0..+50;
  Balance uses L50..0..R50; each transient includes a compact monochrome icon.
  In Phase
  2 the default on-state view prioritises now-playing metadata, falls back to
  the mapped logical function, and omits legacy fascia labels from user-facing
  views under ADR-0009. The display consumes coherent state supplied by `main`;
  it does not call input or WiiM modules. It redraws only when its semantic
  frame changes, an animation frame advances, or a transient expires. Mapped
  names and metadata use fixed-size copied text fields, so Phase 2 can supply
  them without allocation or changing the display interface. The installed
  panel is rendered at Adafruit GFX rotation 2 (180 degrees) and contrast 0x80.
  Physical calibration established viewport X4–123/Y10–61; production content
  uses Y24–60 to avoid the upper viewing-angle/parallax zone. The accepted UI
  presents one priority at a time: identity/standby, a control value and bar,
  source confirmation, status, or title/artist metadata. A small bottom-right
  triangle or two-bar glyph communicates playing or paused without repeating a
  text label. A three-level controller Wi-Fi-strength glyph occupies the
  top-left header; long titles clip to its reserved text area. Connectivity
  status distinguishes controller Wi-Fi loss from an unresponsive WiiM. To
  limit OLED uneven ageing, activity runs at contrast 0x80, the
  panel dims to 0x20 after 60 seconds, and its pixels turn off after five minutes
  without activity. Standby is shown for ten seconds before pixels turn off.
  A power transition wakes the panel, and on-state activity keeps it current;
  passive telemetry changes while already in standby are retained without
  waking the sleeping panel. The
  non-blocking full-canvas calibration frame remains available as a service
  diagnostic and is subject to the same protection timer.
- **`power`** owns only the requested logical state. It converts the debounced
  on/off request supplied by `main` into On or Standby and reports transitions;
  it owns no GPIO and does not call display, lighting or network modules.
- **`wiim`** maps VHF to `switchmode:wifi`, released VHF to
  `switchmode:line-in`, the volume pot to 0-100 WiiM volume, and logical OFF to
  `stop`. It polls player state and active metadata over local HTTPS. Its worker
  owns all potentially blocking network operations; `main` exchanges only
  fixed-size requests and snapshots through short critical sections. Missing
  metadata falls back to the mapped function, and network failure never blocks
  local control.

## Data Flow

```
buttons ─┐                         ┌─> display
pots ────┼─> main ──> settings ──> ┤
         │   (glue)   (shared      └─> lighting
         │            state)
         └─────────────────────────────┘
```

- Input modules produce events/values.
- `main` interprets them and updates `settings`.
- Output modules render from `settings` (and from values `main` passes them).
- `settings` persists state to NVS; no module writes NVS directly.

## Interface Convention

Every module lives in the `decca::<module>` namespace and exposes at least:

```cpp
void init();     // one-time setup; call from setup() in dependency order
void update();   // non-blocking; call once per loop()
```

Modules add a small number of typed accessors (e.g. `buttons::nextEvent()`,
`pots::value()`, `lighting::setBrightness()`). See the headers in `src/`.

## Initialisation Order

`hardware` → `settings` → input modules → output modules. Enforced in
`main.cpp::setup()`.

## Phase Mapping

- **Phase 1 (Local control):** `hardware`, `settings`, `buttons`, `pots`,
  `display`, `lighting`; authenticated `ota` is brought forward before enclosure.
- **Phase 2 (WiiM):** the WiiM interface module makes VHF select digital playback,
  released VHF selects Line-In for Vinyl, and the phone controls digital
  content. Its core-0 worker reuses the secure control connection, resets it only
  on a real request/network failure, prioritises new physical source commands
  over wake activity, bypasses stale retry cooldown for revised controls and
  reconciles reported Line-In mode. Volume and metadata route through `settings`.
- **Phase 3 (Advanced):** configuration menus, automatic post-boot OTA rollback
  validation, richer UI and additional legacy controls.

## Evolving Toward `lib/`

Modules currently live in `src/`. As interfaces stabilise, self-contained
modules may migrate to `lib/` as PlatformIO libraries with their own unit tests
under `test/`, further enforcing independence. This is an intended path, not a
requirement for Phase 1.

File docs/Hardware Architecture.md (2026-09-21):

# Hardware Architecture

> **Status:** active. Reflects the confirmed Phase 1 physical build plus the
> locked Phase 2 audio and power-control architecture. Pot inputs GPIO32–35,
> OLED I²C GPIO21/22, on/off GPIO14, VHF GPIO26 and lighting PWM GPIO18 are
> physically verified. Stereo/Mono uses GPIO25/D25; firmware logic is correct,
> while the retained switch fault remains open as HW-SW-01.
> The MOSFET/lamp electrical load is physically installed and operating;
> other pins are unassigned. See
> `docs/Wiring.md` for the authoritative
> controller interconnect detail and ADR-0008 / ADR-0010 for the streamer,
> amplifier and power-control decisions.

Describes the electrical system: the boards, how power flows, and how the ESP32
connects to the front panel, display, lighting, streamer and external audio path.

## Scope Boundary

The ESP32 is a **control and user-interface system only**. It **must not process
or carry audio**. All potentiometers are position sensors read by the ADC; the
audio signal path is separate from the controller.

## System Block Diagram

```
                 ┌──────────────────────────────────────────┐
                 │                ESP32 DevKit               │
                 │        (control + UI only, no audio)      │
                 └───┬───────┬───────┬────────┬───────┬──────┘
       ADC1 (H1) │       │ H2    │ H3     │ H4    │ H5 (PWM)
        4× 10k   │       │ on/off│ source │ I²C   │ MOSFET gate
     ┌───────────┴──┐ ┌──┴───┐ ┌─┴─────┐ ┌┴─────┐ ┌┴──────────┐
     │ Balance/Treble│ │orig. │ │ VHF   │ │ OLED │ │ 3× 5V     │
     │ Bass/Volume   │ │switch│ │contact│ │128x64│ │ E10 LEDs  │
     │ (position)    │ │Red/Grn│ │2-state│ │ SH1106│ │ (N-ch FET)│
     └───────────────┘ └──────┘ └───────┘ └──────┘ └───────────┘

                  local network control / metadata
                 ESP32  <-------------------->  WiiM Pro
                                                   │
                                                   │ line-level audio
                                                   ▼
                                             Fosi Audio ZA3
                                                   │
                                                   ▼
                                           Passive speakers

                 WiiM Pro trigger out -> trigger lead/adaptor -> ZA3 trigger in
```

## Locked Audio Architecture

The audio-path architecture is locked by ADR-0008 and ADR-0010 as:

`WiiM Pro -> Fosi Audio ZA3 -> passive speakers`

- **Streamer:** WiiM Pro, specifically. This is a locked model decision.
- **Power amplifier:** **Fosi Audio ZA3 stereo amplifier**, locked.
- **Dual monoblocks:** rejected for the current build unless requirements change.
- **Integrated WiiM amplifier variants:** WiiM Amp / Amp Pro are not substitutes
  for the selected architecture without a new ADR.
- **Cabinet thermal constraint:** none for normal hi-fi amplifier selection. The
  Decca cabinet has ample rear ventilation, so thermal performance is not a
  differentiating selection criterion beyond the amplifier's normal operating
  requirements.
- The ESP32 communicates with the WiiM Pro only for control and metadata. It never
  sits in the audio signal path.
- User volume is controlled by the original Decca volume potentiometer as an ESP32
  position input, with the ESP32 commanding WiiM output volume. The ZA3 volume/gain
  control is set during commissioning as a fixed hardware ceiling rather than used
  as the normal user volume control.

## Power

- Controller/lighting architecture is locked to a **single regulated 5 V control
  rail** plus **3.3 V** from the ESP32 board regulator for logic, ADC references
  and the OLED where applicable.
- The 5 V rail powers the ESP32 board input and the three dial-lighting lamps.
- The dial lighting does **not** receive a separate 6 V or 6.3 V rail. A dedicated
  lamp-only supply is explicitly rejected unless a later hardware constraint
  requires an ADR change.
- The 5 V supply is **selected and installed**: **Phihong PSA15R-050P** switching
  adapter, rated **5.0 V DC at 3.0 A (15 W)**. Its enclosed mains side remains
  intact; its low-voltage output lead is soldered directly into the Decca wiring
  through the reused inline fuse holder. The former panel DC socket route is
  obsolete.
- ESP32 and dial-lighting **grounds are common**.
- The original Decca on/off switch remains a **low-voltage ESP32 input only**; it
  does not carry 230 V mains.

### Whole-system mains distribution — active implementation

- The rear inlet is the acquired IEC C14 part measured by the owner. Its
  corrected Rev B six-sided mounting plate passes 15/15 CAD checks and the owner
  confirmed the profile drawing; physical fit and rear terminal clearance remain
  open before release.
- The external UK C13 lead and enclosed Masterplug four-gang internal distribution
  block are ordered. Their delivery, secure mounting, cable routing, earthing and
  final inlet connection remain installation gates.
- Rev A of the C14 plate is rejected and must not be installed.
- The original front-panel switch remains a logical input; it does not interrupt
  the mains feed.

### WiiM Pro power behaviour — locked

- The **WiiM Pro remains continuously powered** from its own supply in normal use.
- The WiiM is **not hard power-cycled** by the Decca front-panel on/off control.
- WiiM **automatic standby** is the preferred idle/off-state behaviour so that the
  unit remains network-aware and can wake without a full boot cycle.
- Turning the Decca on does not require mains switching of the WiiM. Playback or a
  supported WiiM/network control action may wake it from standby.
- Phase 2 firmware issues supported source, volume and stop commands over the
  local HTTPS API. The hardware design does not depend on hard power cycling.
- On Decca off, the ESP32 should stop playback or issue an appropriate supported
  control action where useful, then allow WiiM auto-standby to provide the normal
  idle state.

### Fosi Audio ZA3 power behaviour — locked

- The ZA3 is the locked stereo power amplifier for this build.
- The ZA3 is **not mains-switched by the original Decca switch**.
- Its PSU may remain energised; amplifier operating state is controlled through
  the ZA3's **12 V trigger input**.
- The WiiM Pro trigger output connects directly to the ZA3 trigger input through
  the correct trigger lead/adaptor (ADR-0018).
- The ESP32 has no electrical connection to the 12 V trigger line.
- No ESP32-controlled 230 V relay is required for the amplifier in the locked
  architecture.

### Front-panel power-state behaviour — locked

The original Decca on/off control is a **system-state command**, not a mains
switch.

**ON sequence**
1. Original switch closes and the ESP32 detects the active state.
2. ESP32 restores the selected WiiM source and volume over the local network.
3. WiiM playback/wake state asserts its direct trigger output to the ZA3.
4. ESP32 switches the three dial lamps to their stored commissioning brightness.
5. ESP32 enables the OLED and runs the normal startup/dashboard sequence.

**OFF sequence**
1. ESP32 detects the original switch opening.
2. ESP32 stops playback / sends an appropriate WiiM control action where useful;
   WiiM then uses its own automatic standby behaviour.
3. ESP32 switches the dial lamps immediately to zero.
4. ESP32 blanks the OLED.
5. WiiM standby removes its direct trigger output so the ZA3 enters standby; the
   observed delay is a physical acceptance item.
6. ESP32 and its 5 V control supply remain powered so the next switch-on can be
   detected immediately.

The cabinet's existing rear ventilation is adequate and imposes no additional
thermal-design restriction.

## Controller

- **ESP32 DevKit** (dual-core, Wi-Fi, LEDC PWM, ADC).
- The physical board used is the **30-pin DevKit V1 / DOIT-style layout** on a
  matching 30-pin screw-terminal adapter. Documentation therefore records both
  the logical GPIO number and the **silkscreen label printed on the board**.
- **ADC1 is used for all analogue inputs** because Wi-Fi is enabled in Phase 2
  and **ADC2 is unavailable while Wi-Fi is active** (Specification `HW-02`).
- Strapping pins (0, 2, 5, 12, 15) are avoided for driven/reset-sensitive lines
  (`HW-03`). GPIO34–39 are input-only with no internal pull-ups (`HW-04`).

## Inputs

### Potentiometers (H1)
Four installed **AB Elektronik / TT Electronics ABW1 10K linear** pots (CPC
order code **RE04644**) for Balance, Treble, Bass and Volume, wired GND / wiper /
3.3 V (Brown / White / Red). Wipers read on ADC1. Firmware applies calibration,
smoothing, deadband, and optional inversion (see Firmware Architecture).
Bench-verified assignments and board labels are:

| Control | GPIO | Printed board label |
|---|---|---|
| Volume  | GPIO32 | **D32** |
| Bass | GPIO33 | **D33** |
| Treble  | GPIO34 | **D34** |
| Balance | GPIO35 | **D35** |

Each channel measured 0 anticlockwise, approximately 2047 at centre, and 4095
clockwise on 2026-08-24, so the default 0–4095 calibration remains applicable.

### On/off switch (H2)
Retained original switch and cable, active conductors **Red** and **Green**. A
simple open/close contact read as a **low-voltage digital input** with the ESP32
**internal pull-up** enabled on physically verified GPIO14, board label **D14**.
**Not a mains switch.** Closed = logical ON; open = logical STANDBY. Both
directions were physically accepted on 2026-08-30. Its logical state drives the
locked system-power sequence documented above.

### Source button bank (H3)
The original selector PCB and interlocked mechanism are retained as the
mechanical carrier (ADR-0001), but unreliable soldering/contact behaviour makes
multi-button electrical reuse unsuitable.

Only the reliable VHF-derived dry-contact state is connected to GPIO26 / D26
with the internal pull-up and software debounce. Closed/latched VHF selects
Digital Streamer; every other interlocked position releases VHF and selects
Vinyl. GPIO13, GPIO16, GPIO17, GPIO19 and GPIO23 are released. A new button panel remains
a deferred fallback (ADR-0016).

The Stereo/Mono contact uses GPIO25/D25 with the internal pull-up. Open/HIGH in
Stereo requests dial lights on and closed/LOW in Mono requests them off. It is a command input
only; GPIO18 and the lighting load remain separately gated. The switch behaviour
was physically accepted on the previous GPIO17/TX2 route. GPIO25 input logic is
correct, but the retained switch requires repair under HW-SW-01 (ADR-0016).

## Outputs

### OLED display (H4)
Purchased Pi Hut 1.3-inch white 128×64 SH1106 I²C panel (SKU 105630), powered
from 3.3 V at address 0x3C. SDA GPIO21 / board label **D21** and SCL GPIO22 /
board label **D22** were bench-verified on 2026-08-25 with the on-target display
suite and a visual layout inspection.

The fitted panel uses firmware protection against uneven OLED ageing: normal
contrast dims after 60 seconds without activity, pixels turn off after five
minutes, and the standby confirmation turns off after ten seconds. Activity
wakes the panel immediately; this does not remove power from the ESP32.

### Dial lighting (H5)
The purchased lamp set is **ShuoHui ASIN B0CFTLZFGT**: ten E10 miniature
screw LEDs rated 6 V AC/DC, 0.2 W and 3000 K; three are required. The lamps were
bench-confirmed functional at **5 V** on 2026-08-29, validating compatibility with
the locked 5 V lighting rail. The assembled three-lamp electrical path passed
PWM testing on 2026-08-31. Physical holder fit, final brightness and measured
three-lamp current remain commissioning checks.

The final switch is one **DFRobot Gravity MOSFET Power Controller, DFR0457**,
now installed. It accepts the 5 V lamp rail and 3.3 V logic/control, with a
specified switching range of 0–1 kHz. GPIO18/D18 drives the controller input and
firmware PWM is set to 1 kHz. The initial steady-light test resolved the visible
flicker. The earlier v0.27.1 fade observations are superseded because installed
LEDs held brightness until a delayed final switch. Deployed v0.27.4 removes the
fade engine and applies changed duties immediately. Immediate-transition, WAGO
distribution, pot-stability, temperature and current checks remain under
HW-LGT-01. The previously tested DAOKAI pack is retained as superseded test
stock.

Brightness is a commissioning/configuration value rather than a permanent front-
panel user control. The owner-approved normal value is 85% / duty 217. Firmware
stores it in non-volatile settings and applies it only while logically on and in
Stereo. Debounced Stereo/Mono and logical power changes apply duty 217 or zero
immediately. The unused aerial control may be used as a
temporary commissioning input if convenient, but it is not reserved as a
permanent lighting control. Behaviours: immediate switching, configurable stored
brightness and safe boot state.

### ZA3 trigger connection
The WiiM Pro **12 V trigger output** connects directly to the ZA3 trigger input
with the correct 2.5 mm-to-3.5 mm lead/adaptor (ADR-0018). The ESP32 must not
source, receive or sense this trigger line. Final installation requires physical
verification of polarity, wake, standby and silence.

## Networking (Phase 2)

Wi-Fi is used now for authenticated local-network firmware updates and in Phase
2 for **WiiM Pro local API** integration. OTA uses the ESP32 standard dual-app
partition layout and requires no additional hardware. Digital service, station,
playlist and track selection remain in the WiiM app. This is the reason ADC1 is mandated
for all analogue inputs. See Firmware Architecture → WiiM interface, ADR-0006,
ADR-0008 and ADR-0010.

## Revisions

Track board/electrical revisions in [Revision History](Revision History.md).

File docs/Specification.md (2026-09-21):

# decca — Project Specification

## Document Control

| Field | Value |
|---|---|
| Project  | decca — ESP32 music centre restoration |
| Status | Draft. Firmware v0.28.4 from source commit `3195c95` is installed by authenticated OTA. Digital and vinyl audio, metadata, volume/app synchronisation, channel, logical-power, source-response, direct-trigger and outage-recovery acceptance pass. Phase 2 physical acceptance is complete: the owner confirmed all formal noise/interference checks passed with no issues on 2026-09-21. Phase 1 lighting and retained-switch issues remain tracked separately. |
| Version  | 0.28.4 |
| Owner | LeweeLewee |
| Related  | `README.md`, `docs/Development Handover.md`, `docs/Firmware Architecture.md`, `docs/Hardware Architecture.md`, `docs/Wiring.md`, `docs/adr/` |

Requirements are identified as `FR-*` (functional), `NFR-*` (non-functional),
`HW-*` (hardware), and `IF-*` (interface). IDs are stable once assigned so they
can be referenced from issues, commits, and tests.

---

## 1. Purpose

Define what the decca system must do, the constraints it must respect, and the
criteria by which each build phase is judged complete. This specification is the
agreed scope against which design, implementation, and testing are measured.

## 2. Scope

decca converts a restored 1960s Decca music centre into a modern, network-capable
audio appliance while preserving the original cabinet, controls, and dial. The
system covers the ESP32 firmware, the supporting electronics, and the mechanical
integration. It does **not** cover the audio amplification path or speakers,
which remain analogue and outside the controller's responsibility except where a
networked source is introduced in Phase 2.

## 3. System Overview

An ESP32 reads the restored front-panel controls, drives an OLED behind the dial
glass and the warm dial illumination, and persists user state. The ESP32 handles
**control and user interface only and does not process or carry audio**. From
Phase 2 it also controls a WiiM Pro streamer over its local API. The firmware is
built from independent modules coordinated by a top-level scheduler, as defined
in `docs/Firmware Architecture.md`.

Confirmed Phase 1 front-panel controls:

- Four rotary controls as 10 kΩ position sensors: **Balance, Treble, Bass, Volume**.
- Retained original **on/off switch** (low-voltage logic input).
- Original **source button bank** retained mechanically. Only **VHF** provides a reliable electrical state: VHF latched = **Digital Streamer**; every other selector position = **Vinyl**.
- Original **Stereo/Mono** contact assigned to GPIO25/D25: Stereo open requests
  lights on; Mono closed requests lights off. Firmware logic is correct, but the
  retained switch requires repair under HW-SW-01.
- **OLED** display and **warm dial illumination**.

See `docs/Wiring.md` and the ADRs in `docs/adr/` for the confirmed detail.

## 4. Definitions

| Term | Meaning |
|---|---|
| Module | A self-contained firmware unit with one responsibility |
| Front panel | The original, restored physical controls of the music centre |
| Streamer | WiiM Pro networked audio source (Phase 2+) |
| NVS | ESP32 non-volatile storage used for persisted settings |
| Local-first | Full core function without any network or companion device |

---

## 5. Functional Requirements

### 5.1 Core / System

| ID | Requirement | Phase |
|---|---|---|
| FR-SYS-01 | The system shall initialise all modules in dependency order at power-on. | 1 |
| FR-SYS-02 | The system shall run a non-blocking main loop; no operation may stall it. | 1 |
| FR-SYS-03 | Local hardware controls shall remain usable without a network; digital content and track selection are delegated to the WiiM app. | 1 |
| FR-SYS-04 | The system shall restore its last persisted state on boot. | 1 |
| FR-SYS-05 | The system shall degrade gracefully if the streamer is unavailable. | 2 |

### 5.2 Buttons

| ID | Requirement | Phase |
|---|---|---|
| FR-BTN-01 | The system shall debounce the retained on/off switch and the sole VHF source contact. | 1 |
| FR-BTN-02 | The system shall expose the stable VHF state continuously and emit one event per confirmed press without hold repeats. | 1 |
| FR-BTN-03 | Closed/latched VHF shall select Digital Streamer; open/released VHF shall select Vinyl. | 1 |
| FR-BTN-04 | SW, MW, LW and Gram shall have no individual ESP32 input; their authoritative effect is to release VHF and select Vinyl through the original interlock. A replacement button panel is a deferred fallback only. | 1 |
| FR-BTN-05 | The system shall debounce the Stereo/Mono contact on GPIO25 and expose its stable lighting request continuously: Stereo open/high = on; Mono closed/low = off. | 1 |

> Digital service, station, playlist and track selection remain in the WiiM app.
> In Phase 2 the ESP32 maps Vinyl to WiiM Line-In and Digital Streamer to the
> phone-controlled network playback path (ADR-0016).

### 5.3 Potentiometers

| ID | Requirement | Phase |
|---|---|---|
| FR-POT-01 | The system shall read the four rotary controls (Balance, Treble, Bass, Volume) as position sensors via ADC1. | 1 |
| FR-POT-02 | Pot readings shall be filtered (smoothing) so a settled knob yields a stable value. | 1 |
| FR-POT-03 | Pot values shall be exposed on a normalised scale (0–1000). | 1 |
| FR-POT-04 | The system shall support per-pot calibration, deadband, and optional inversion. | 1 |
| FR-POT-05 | Pot changes shall produce stable display updates without flicker or jitter.  | 1 |

> The potentiometers are **position sensors only** and are **not in the audio
> path** (ADR-0002).

### 5.4 Display

| ID | Requirement | Phase |
|---|---|---|
| FR-DSP-01 | The system shall render system on/off state and the four control values (volume, bass, treble, balance). | 1 |
| FR-DSP-02 | The system shall show a transient control view for approximately 2 s when a pot is adjusted. Volume uses 0–100%; Bass and Treble use a centred −50..0..+50 scale; Balance uses L50..0..R50. Each view includes a control icon and bar. Source/function changes shall receive transient confirmation and diagnostic messages shall remain available. | 1 |
| FR-DSP-03 | While a streaming source is playing, the default on-state view shall show available now-playing information, including mapped function/source, title and artist. If metadata is absent, it shall fall back to the mapped function rather than a blank or stale now-playing view. | 2 |
| FR-DSP-04 | The display shall render configuration menus. | 3 |
| FR-DSP-05 | The display shall present SW as **unavailable / no function**, not as a working selector. | 1 |
| FR-DSP-06 | Cold startup and OTA reboot shall show a short, non-blocking monochrome Decca-logo animation, followed by the firmware version in the calibrated visible area. Logical standby/wake shall not replay it. | 1 |
| FR-DSP-07 | The display shall identify the mapped logical function prominently. Legacy fascia button labels shall not consume space in normal, now-playing or function-confirmation views. | 2 |
| FR-DSP-08 | The OLED shall reduce uneven ageing by dimming after inactivity, turning pixels off after extended inactivity and while logically off, and waking immediately on relevant user/system activity. Passive telemetry changes while already in standby shall not wake it. | 1 |
| FR-DSP-09 | The normal header shall show controller Wi-Fi strength without obscuring source/title text, and connectivity diagnostics shall distinguish controller Wi-Fi loss from an unresponsive streamer. | 2 |

### 5.5 Lighting

| ID | Requirement | Phase |
|---|---|---|
| FR-LGT-01 | The system shall drive the warm dial illumination via PWM through a logic-level N-channel MOSFET. | 1 |
| FR-LGT-02 | Lighting shall support configurable idle brightness and standby dimming. | 1 |
| FR-LGT-03 | Every lighting transition shall apply its requested PWM duty immediately, without a fade or delayed final step. | 1 |
| FR-LGT-04 | Lighting shall adopt a defined safe state at boot. | 1 |
| FR-LGT-05 | While logically on, a debounced Stereo change shall apply the stored normal dial-light duty immediately and Mono shall apply duty 0 immediately. Logical power-on and standby shall likewise apply their lighting duty immediately. | 1 |

> Confirmed Phase 1 lighting is the **dial illumination** only. Cabinet lighting
> is not part of the confirmed Phase 1 build.

### 5.6 Settings

| ID | Requirement | Phase |
|---|---|---|
| FR-SET-01 | The system shall persist volume and brightness to NVS. Source shall be derived from the physical VHF state and shall not be persisted. | 1 |
| FR-SET-02 | Settings shall be the single point through which modules exchange state. | 1 |
| FR-SET-03 | Persistence shall be write-limited to protect flash endurance. | 1 |

### 5.7 Streamer Integration (WiiM)

| ID | Requirement | Phase |
|---|---|---|
| FR-WIM-01 | The system shall connect to the WiiM Pro over the local network. | 2 |
| FR-WIM-02 | VHF shall select the phone-controlled digital playback path; every other selector position shall select WiiM Line-In for Vinyl. | 2 |
| FR-WIM-03 | Front-panel volume and streamer volume shall be synchronised. | 2 |
| FR-WIM-04 | The system shall retrieve and display now-playing metadata. | 2 |

### 5.8 Advanced (Phase 3)

| ID | Requirement | Phase |
|---|---|---|
| FR-ADV-01 | The system shall provide on-device configuration menus. | 3 |
| FR-ADV-02 | The system shall support authenticated local-network OTA firmware updates. Interrupted or rejected transfers shall leave the running firmware bootable. | 1 |
| FR-ADV-03 | The system shall support reuse of additional original controls. | 3 |
| FR-ADV-04 | The system shall automatically roll back after a fully received firmware image fails post-update boot validation. | 3 |

---

## 6. Non-Functional Requirements

| ID | Requirement |
|---|---|
| NFR-01 | Main loop responsiveness: a button press shall register within 50 ms. |
| NFR-02 | The firmware shall use no dynamic allocation in the steady state. |
| NFR-03 | Modules shall have no lateral coupling (see `docs/Firmware Architecture.md`). |
| NFR-04 | The codebase shall build with `pio run` with no errors or warnings. |
| NFR-05 | Each module shall have a unit-test suite exercising its public interface. |
| NFR-06 | Builds shall be reproducible via the pinned PlatformIO toolchain. |
| NFR-07 | Public interfaces shall be documented in their headers. |
| NFR-08 | The device shall reach an operable state within 3 s of power-on (Phase 1). |
| NFR-09 | Network features shall never block core local control. |
| NFR-10 | No secrets (Wi-Fi credentials, tokens) shall be committed to the repository. |

---

## 7. Hardware Requirements & Constraints

| ID | Requirement |
|---|---|
| HW-01  | Controller shall be an ESP32 DevKit (dual-core, Wi-Fi, ≥ 4 MB flash). |
| HW-02  | **All potentiometers shall be wired to ADC1 pins (GPIO 32–39).** ADC2 is unavailable while Wi-Fi is active and must not be used for analogue inputs. |
| HW-03  | Buttons and any pin driven at reset shall avoid ESP32 strapping pins (0, 2, 5, 12, 15). |
| HW-04  | Input-only pins (GPIO 34–39) shall be used only for inputs and require external pull-ups where needed. |
| HW-05  | Lighting outputs shall use LEDC (hardware PWM) channels. |
| HW-06  | The pin map in `src/hardware.h` shall match `docs/Wiring.md` at all times. |
| HW-07  | Power supply shall provide stable 5 V and 3.3 V rails sized to the load budget. |
| HW-08  | Original controls shall be preserved and reused; modifications shall be reversible where practical. |
| HW-09  | The retained on/off switch shall be interfaced as a **low-voltage logic input only** (internal pull-up). It shall **not** switch 230 V mains. |
| HW-10  | The original source-selector **PCB shall be retained** as the mechanical carrier for the interlocked selector mechanism (ADR-0001); it shall not be discarded. |
| HW-11  | Proposed GPIO assignments (see `docs/Wiring.md`) shall be treated as **proposed** until bench-verified, and `src/hardware.h` reconciled to them (HW-06). |
| HW-12  | Dial lighting shall be switched by a logic-level N-channel MOSFET under ESP32 PWM, with ESP32 and lighting grounds common. |

---

## 8. External Interfaces

| ID | Interface |
|---|---|
| IF-01  | **Front panel:** four 10 kΩ pots on ADC1; retained on/off switch on GPIO14/D14; sole debounced VHF source contact on GPIO26/D26; pulled-up Stereo/Mono lighting-request contact on GPIO25/D25. VHF closed = Digital Streamer; VHF open = Vinyl. Stereo open/high = lights requested on; Mono closed/low = off. The retained Stereo/Mono switch fault is tracked as HW-SW-01. |
| IF-02  | **Display:** purchased Pi Hut 1.3-inch white 128×64 **SH1106** OLED over **I²C** at address 0x3C, powered from 3.3 V and mounted behind the dial glass. |
| IF-03  | **Lighting:** GPIO18/D18 PWM-driven warm dial illumination via logic-level N-channel MOSFET (dial only in Phase 1). |
| IF-04  | **WiiM Pro local API (Phase 2):** two-state Line-In/digital-path switching, volume control, and metadata/playback-state feedback. Digital content selection remains in the WiiM app. |
| IF-05  | **Serial console:** 115200 baud for diagnostics and bring-up. |

---

## 9. Constraints & Assumptions

- The original cabinet, dial, and controls are available and restorable.
- The WiiM Pro exposes a stable local HTTP API on the same LAN as the ESP32.
- Wi-Fi credentials are provisioned locally and never committed (see NFR-10).
- The amplifier and speaker path remain analogue and outside firmware control.
- One ESP32 handles all responsibilities; no secondary microcontroller is assumed.

## 10. Out of Scope

- Audio DSP, equalisation, or amplification within the firmware.
- Cloud services, remote/off-LAN control, or mobile applications.
- Multi-unit / multi-room orchestration (may be revisited post-Phase 3).

---

## 11. Acceptance Criteria

### Phase 1 — Local Control
- FR-SYS-01..04, all FR-BTN, FR-POT, FR-DSP-01/02/05/06/08, FR-LGT, FR-SET satisfied.
- Local controls and vinyl selection remain available without a network; digital content selection requires the WiiM app/network.
- **Confirmed 2026-08-30:** all eight `esp32dev` on-target suites passed, 53/53 tests after power, controls, VHF source integration and OLED protection.
- **Confirmed 2026-08-30:** after TX2 Stereo/Mono integration, the release build
  passed and all eight on-target suites passed 55/55 (buttons 11, display 15,
  hardware 3, lighting 7, OTA 5, pots 6, power 5, settings 3).
- **Confirmed 2026-08-30:** one USB bootstrap flash and one authenticated OTA upload both succeeded; after reboot serial reported `[OTA] ready at 192.168.x.x (decca.local)`.
- Interrupted-transfer behaviour is verified to retain the previous bootable firmware.
- **Confirmed 2026-08-30:** the final `esp32dev` release build passed cleanly (RAM 49,760 bytes / 15.2%; flash 833,321 bytes / 63.6%).

### Phase 2 — WiiM Integration
- FR-WIM-01..04 and FR-DSP-03/07 satisfied.
- VHF-to-digital and released-VHF-to-Line-In switching, volume sync and metadata are verified against a live WiiM Pro.
- Loss of the streamer does not impair local control (FR-SYS-05, NFR-09).
- **Confirmed 2026-09-11:** the acquired WiiM Pro answered live HTTPS
  `getStatusEx` and `getPlayerStatus` requests. The idle player reported no
  active mode, `status=none`, volume 35 and unmuted; idle `getMetaInfo` returned
  an empty response body.
- **Confirmed 2026-09-11:** active TIDAL playback reported `vendor=Tidal`,
  `mode=10`, `status=play`, 96 kHz structured metadata, and matching title and
  artist through both hex player fields and plain-text `getMetaInfo` fields.
  The published mode table is not used to identify TIDAL because this live
  firmware reports mode 10 rather than the documented historical mode 32.
- **Confirmed 2026-09-12:** v0.28.0 from source commit `d06e357` built at
  52,328 bytes RAM (16.0%) and 1,017,193 bytes flash (77.6%); all nine target
  suites compiled, authenticated OTA passed and the controller returned without
  USB intervention. Live tests passed both source directions, matching OLED
  metadata/play state, direct absolute volume/app reflection through a reusable
  HTTPS connection, logical standby/resume and persistent outage/recovery
  behavior. Exact 10%, 20% and 30% volume targets matched in WiiM Home, and the
  owner confirmed the final response was much more responsive.
- **Confirmed 2026-09-19:** v0.28.0 from source commit `36d84d1` built at
  52,328 bytes RAM (16.0%) and 1,016,977 bytes flash (77.6%), uploaded to 100%
  by authenticated OTA and returned without USB intervention. Digital TIDAL
  audio and correct left/right routing pass through the ZA3 and B&W DM601 S3
  speakers. With WiiM automatic standby set to 30 seconds, OFF removes the
  direct trigger. ON uses a safe one-step downward volume pulse followed by
  requested-volume restoration to wake the WiiM and ZA3 without app interaction
  or automatic playback.
- **Confirmed 2026-09-20:** v0.28.4 from source commit `3195c95` built at
  52,336 bytes RAM (16.0%) and 1,018,373 bytes flash (77.7%), passed authenticated
  OTA and returned on the unique `decca-esp32` hostname. Vinyl playback passed.
  After an installed 30–60+ second source-delay regression, the worker restored
  secure-connection reuse, prioritised physical source commands, bypassed stale
  retry cooldown for new input and reconciled Line-In state; the owner confirmed
  approximately one-second switching. The top-left header now shows controller
  Wi-Fi strength and distinguishes controller-network loss from an unresponsive
  WiiM. Standby shows for ten seconds, blanks, and remains off despite passive
  telemetry updates. WiiM and display target suites compiled without execution.
- **Confirmed by the owner 2026-09-21:** all formal noise checks passed with no
  hum, buzz, clipping, switching thumps or OLED/control interference. Phase 2
  physical acceptance is complete. The owner approved PR #11 for review and explicitly authorised merge on 2026-09-21.

### Phase 3 — Advanced Features
- FR-ADV-01, FR-ADV-03, FR-ADV-04 and FR-DSP-04 satisfied.
- OTA update demonstrated with a successful rollback.

---

## 12. Traceability

- **Requirements → design:** `docs/Firmware Architecture.md` (modules, phase map).
- **Key decisions:** `docs/adr/` (ADR-0001 retained PCB, 0002 pots as sensors, 0003 on/off input, 0004 superseded multi-button plan, 0005 superseded Stereo/Mono deferral, 0006 WiiM Phase 2, 0007 display presentation, 0008 streamer/separate-amplifier architecture, 0009 function-only display hierarchy, 0010 Fosi ZA3 and system power, 0011 superseded Gram-only source selection, 0012 authenticated local OTA, 0013 VHF-authoritative two-state selection, 0014 superseded TX2 Stereo/Mono routing, 0015 superseded interim routing, 0016 final controller routing).
- **Requirements → hardware:** `docs/Hardware Architecture.md`, `docs/Wiring.md`.
- **Requirements → verification:** test suites under `test/`, one per module.
- **Change history:** `docs/Revision History.md`.

Requirement IDs should be cited in commit messages and pull requests when work
implements or verifies them (e.g. `feat(pots): filtered ADC reads [FR-POT-02]`).

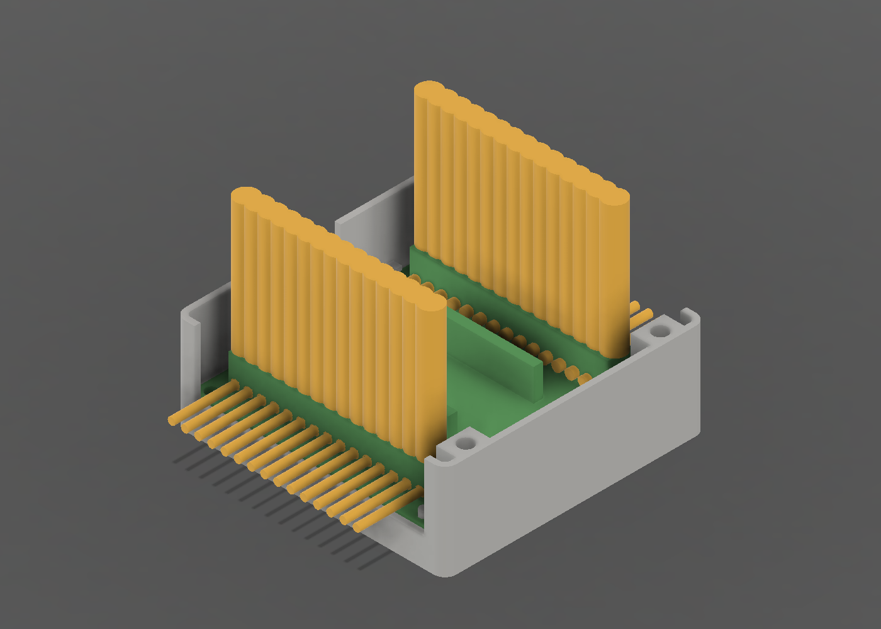
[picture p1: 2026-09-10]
mechanical/Drawings/Decca_ESP32_Controller_Housing_revC_08b_screw_access_iso.png

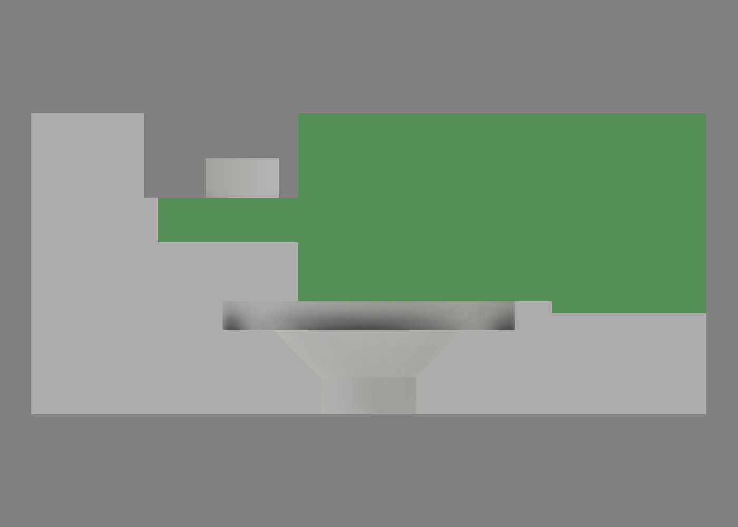
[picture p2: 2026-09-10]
mechanical/Drawings/Decca_ESP32_Controller_Housing_revC_12b_cabinet_fixing_section.png

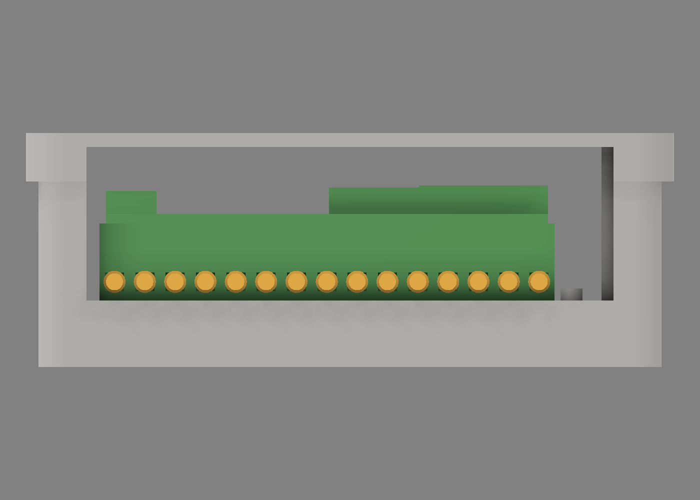
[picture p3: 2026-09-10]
mechanical/Drawings/Decca_ESP32_Controller_Housing_revC_06_terminal_entry_long_side.png

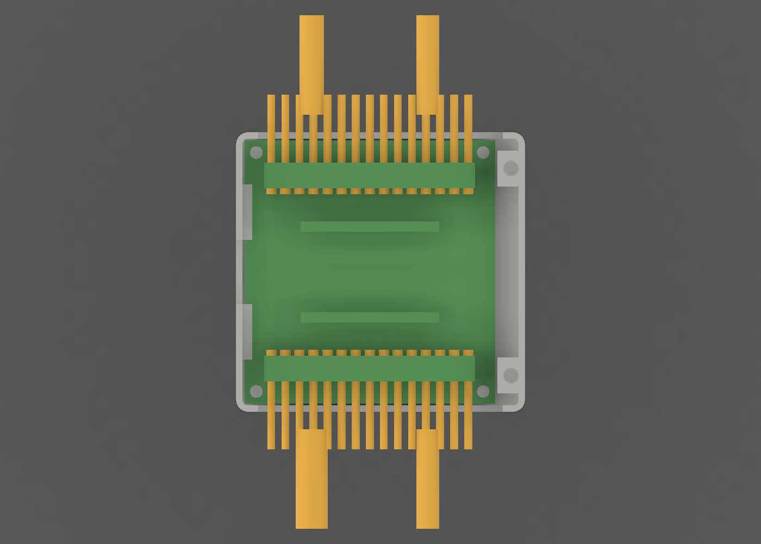
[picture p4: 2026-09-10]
mechanical/Drawings/Decca_ESP32_Controller_Housing_revC_10_harness_grouping.png

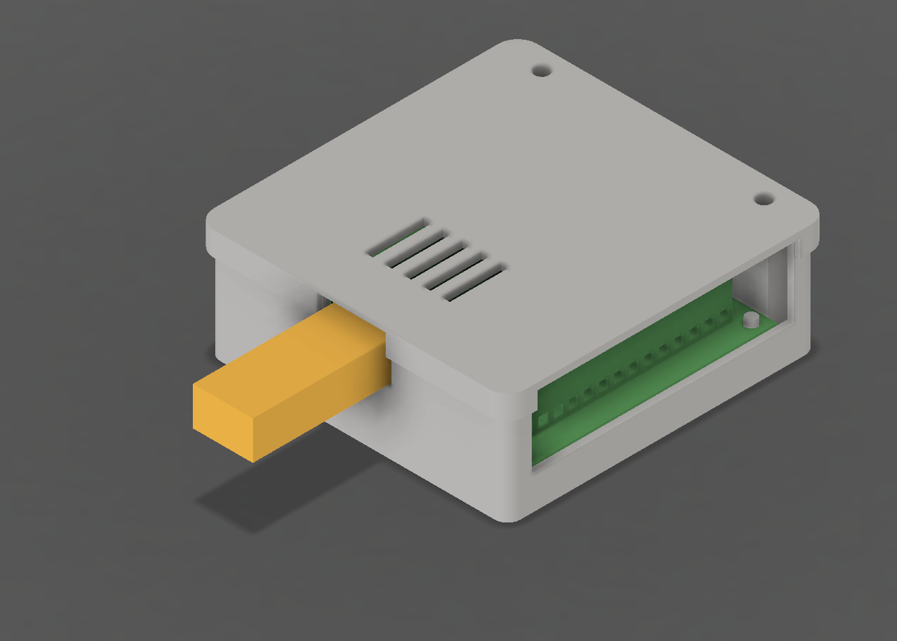
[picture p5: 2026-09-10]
mechanical/Drawings/Decca_ESP32_Controller_Housing_revC_11_usb_access.png

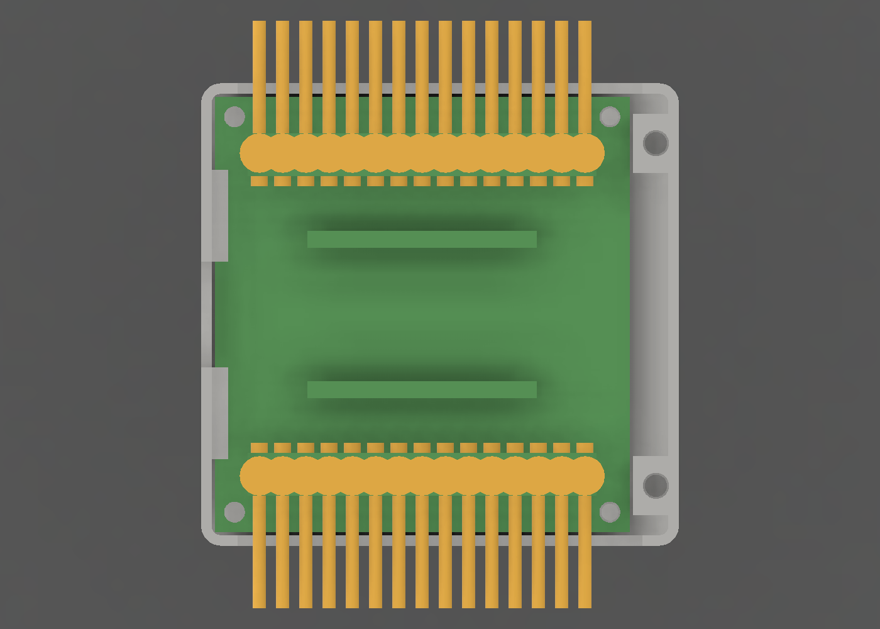
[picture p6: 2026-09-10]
mechanical/Drawings/Decca_ESP32_Controller_Housing_revC_08_screw_access_top.png

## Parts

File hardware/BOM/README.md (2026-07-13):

# BOM

Formal bills of materials for ordering and assembly.

**Intended contents**
- Machine-readable BOM (`.csv`) with designators, values, quantities, and
  supplier/part numbers.
- Optional supplier-specific import files.

**Conventions**
- The `.csv` here is authoritative; `docs/Parts List.md` is the readable summary
  and must be kept consistent with it.

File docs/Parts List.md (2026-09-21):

# Parts List

> **Status:** active. Human-readable summary; the formal BOM lives in
> `hardware/BOM/`. Reflects the confirmed build decisions. A selected model that
> has not yet been bought is kept separate from a genuinely open selection.

## Electronics (Phase 1)

Status meanings: **OPEN** = selection or purchase is still required; **CHECK** =
the named item is already selected or purchased but a physical or electrical
validation remains.

| Item | Qty | Status | Spec / Notes | Source |
|---|-----|---|---|---|
| ESP32 DevKit | 1 | **ACQUIRED — USB→OTA VERIFIED** | 30-pin DevKit V1 / DOIT-style board. Authenticated `esp32dev-ota` upload and post-reboot readiness were physically verified on 2026-08-30; dual application partitions are in use. | Existing stock |
| ESP32 screw-terminal adapter | 1 | **ACQUIRED** | Matching 30-pin terminal adapter used for the installed controller. | Existing stock |
| ABW1 10K linear potentiometers | 4 | **INSTALLED / VERIFIED** | AB Elektronik / TT Electronics ABW1 10K, CPC order code RE04644. Position sensors for Balance, Treble, Bass and Volume; not in the audio path. | CPC |
| OLED display | 1 | **INSTALLED / VERIFIED** | Pi Hut SKU 105630; 1.3-inch white 128×64 SH1106, four-pin I²C, 3.3 V. | The Pi Hut |
| DAOKAI MOSFET driver modules | Pack of 10; 1 previously tested | **RETAINED TEST STOCK — SUPERSEDED** | ASIN B09YYH2BTF. One module passed the earlier GPIO25 bench test on 2026-08-31. Retain the pack as test stock; DFR0457 is selected for the final installation. | Amazon / DAOKAI |
| DFRobot Gravity MOSFET Power Controller | 1 | **INSTALLED — FLICKER PASS / IMMEDIATE SWITCH + FINAL CHECKS OPEN** | DFR0457; control input is on GPIO18/D18. Earlier v0.27.1 fade observations are superseded because the installed LEDs held brightness until a delayed final switch. v0.27.4 removes the fade engine. Mono/off re-verification after HW-SW-01, immediate power-transition verification, pot stability, temperature and current remain before closure. | The Pi Hut |
| ShuoHui E10 warm-white LED lamps | Pack of 10; 3 required | **THREE-LAMP ELECTRICAL LOAD VERIFIED / FIT CHECK** | ASIN B0CFTLZFGT; E10, AC/DC 6 V, 0.2 W, 3000 K. Three parallel lamps passed even 5 V PWM illumination on 2026-08-31. Physical holder fit, final brightness and total bank current remain open. | Amazon / ShuoHui |
| 5 V regulated control supply | 1 | **CONNECTED — SHARED RAIL / USB REMOVED** | Phihong PSA15R-050P switching adapter; 5.0 V DC at 3.0 A (15 W). Now feeds the ESP32 at VIN/5V and the lighting rail; USB was removed before external power was connected. Previously powered the accepted three-lamp PWM test on 2026-08-31. | Existing stock |
| TopHomer panel-mount DC input sockets | Pack of 5 | **PURCHASED — OBSOLETE / NOT REQUIRED** | ASIN B08HGXYS4J; previously intended for the Phihong input. The installed PSU output is soldered directly into the low-voltage wiring, so no panel DC socket is used. | Amazon / TopHomer |
| Low-voltage inline fuse holder | 1 | **REUSED / IMPLEMENTED** | Original Decca holder installed in the +5 V conductor immediately after the soldered PSU output connection and before distribution. | Original Decca hardware |
| 2 A fuse | 2 | **PURCHASED** | One fitted and one spare. Recheck the final rating against measured lamp current during commissioning. | Purchased |
| WAGO 221-415 five-way distribution connectors | Pack of 3; 2 required | **ORDERED — DELIVERY / INSTALLATION CHECK** | Pi Hut SKU 104130. Use one connector as the +5 V star point and one as the common-GND star point; retain the third as a spare. Each five-way connector makes every port common and accepts the selected 22–24 AWG wiring. | The Pi Hut |
| Lyeteung JST-XH 4-pin harness set | 15 pairs | **PURCHASED — CHECK PHYSICAL STOCK** | ASIN B0CBWX98NF; 2.54 mm male/female connectors with 150 mm 22 AWG leads. Use where a four-way removable low-voltage harness is suitable. | Amazon / Lyeteung |
| 22–24 AWG stranded power wire and ferrules | 1 lot | **CHECK STOCK** | Orange for +5 V and Brown for GND; ferrules sized for the ESP32 terminal adapter and distribution connectors. | Existing stock / _TBD_ |
| IEC C14 panel-mount mains inlet | 1 | **ACQUIRED / MEASURED — REV B FIT CHECK OPEN** | 250 V AC, 10 A class. The owner supplied the physical profile dimensions and confirmed the Rev B drawing; the corrected six-sided Rev B plate passes 15/15 CAD checks. Verify inlet fit, both fixing patterns, flat clamping and rear terminal/wire clearance before mains energisation. | Amazon |
| UK mains to IEC C13 lead | 1 | **ORDERED — DELIVERY CHECK** | Appropriately fused BS 1363 UK plug to IEC C13 female lead for the rear C14 inlet. | Amazon |
| Internal 4-gang mains distribution block | 1 | **ORDERED — INSTALLATION DESIGN OPEN** | Enclosed Masterplug four-socket extension block. Retain its enclosure and verify secure mounting, routing, earthing and the final C14 connection before energisation. | Amazon / Masterplug |

## Reused Original Components (Phase 1)

| Item | Notes |
|---|---|
| Original on/off switch  | Retained with original solder joints and cable. Low-voltage logic input only (Red/Green). Not switching mains. |
| Original selector PCB | **Retained** as mechanical carrier for the interlocked selector (ADR-0001). Not disposable. |
| Original source buttons | Original mechanism retained. Only VHF has a reliable electrical state: closed = Digital Streamer, open = Vinyl. SW/MW/LW/Gram mechanically release VHF and have no individual GPIO; replacement panel deferred (ADR-0016). |
| Original Stereo/Mono control | Retained on GPIO25/D25. Open Stereo requests lights on; closed Mono requests lights off. Firmware logic is correct, but the physical switch contact is faulty and open under HW-SW-01 (ADR-0016). |
| Original Decca knobs | Retained via mechanical adaptor strategy (see `mechanical/Knob Adaptors/`). |

## Audio Path / Phase 2

| Item | Qty | Decision / procurement status | Notes | Source |
|---|-----|---|---|---|
| WiiM Pro | 1 | **ACQUIRED / INSTALLED / API VERIFIED** | Delivered 2026-09-10 and commissioned on the live local API. EQ is off and the WiiM volume limit is set to 70%. ESP32 restores the digital path when VHF is latched and selects Line-In for Vinyl when VHF is released; phone controls digital content. Continuously powered with automatic standby. Do not substitute WiiM Amp / Amp Pro without a new ADR. | Amazon |
| Fosi Audio ZA3 | 1 | **ACQUIRED / INSTALLED** | Delivered 2026-09-10 with the 48 V / 5 A supply. WiiM Pro line output feeds the ZA3; its gain/volume becomes a commissioning ceiling and its operating state is controlled by the 12 V trigger. | Amazon |
| B&W DM601 S3 speakers | 2 | **ACQUIRED / MOUNTED / FIT VERIFIED** | Installed in the original speaker bays on spikes. The front ports and tweeters are aligned with openings in the retained speaker-cover construction; the surrounding bay air space is intentionally left unpacked. | Used purchase |
| ZA3 12 V trigger driver and source | 0 | **REMOVED — NOT REQUIRED** | Superseded by direct WiiM Pro trigger-out to ZA3 trigger-in connection under ADR-0018. The ESP32 is not electrically connected to the trigger. | n/a |
| WiiM-to-ZA3 trigger lead/adaptor | 1 | **INSTALLED / ACCEPTED** | Direct 2.5 mm-to-3.5 mm connection under ADR-0018. Thirty-second standby and switch-only wake passed; no ESP32 electrical connection to the 12 V line. | WiiM / Fosi |
| Stereo RCA interconnect | 1 | **ACQUIRED / ACCEPTED** | Supplied WiiM stereo RCA lead retained for the WiiM Pro line-output connection to the ZA3; no audiophile replacement is required unless a fault, interference or unsuitable final length is found. | Supplied with WiiM Pro |
| Turntable-to-WiiM analogue interconnect | 1 | **PURCHASED / DELIVERED / IN USE** | UGREEN RCA-to-3.5 mm stereo phono/mini-jack lead, 1 m, ASIN B015PZ7QO2. Connects the turntable analogue output to the WiiM Pro Line-In. Replacement cable ordered for £6.28 after the first example was returned as defective; delivered 2026-09-15. | Amazon / UGREEN |
| QED Profile 79 Strand speaker cable | 3 × 1 m | **PURCHASED / DELIVERED — TERMINATION / INSTALLATION CHECK** | Black 2 × 2.5 mm² OFC cable, model C-79/100B-1M. Three separate 1 m lengths purchased for the two short ZA3-to-speaker runs plus one spare; delivered 2026-09-16. Order total £6.30 with free postage. | eBay / Inta Audio |
| QED Screwloc Forte banana plugs | 4 | **PURCHASED / DELIVERED — INSTALLATION CHECK** | Gold-plated 4 mm Screwloc Forte plugs for amplifier/speaker binding posts; delivered 2026-09-18. Four plugs are sufficient to terminate one end of both stereo runs; the opposite ends remain bare wire unless four additional plugs are later purchased. | Amazon |
| Monoblock power amplifiers | 2 | **REJECTED** | Added cost and complexity are not justified for the current build. | n/a |

**Locked signal architecture:** `WiiM Pro -> Fosi Audio ZA3 -> passive speakers`.

See ADR-0008 and ADR-0010 for the locked streamer, amplifier and system-power
decisions.

## Whole-system mains boundary

The Phihong adapter's enclosed mains side remains intact. Its isolated 5 V output
lead is soldered directly into the Decca low-voltage wiring, through the reused
inline fuse holder; the purchased TopHomer panel DC socket is obsolete.

The whole-system one-mains-lead arrangement is now an active implementation:
an IEC C14 inlet, UK C13 lead and enclosed Masterplug four-gang distribution
block are ordered. The corrected Rev B C14 mounting plate has passed CAD checks
but remains physical-fit pending; mains wiring, earthing, secure mounting and
rear terminal clearance must be verified before energisation.

## Mechanical / Fasteners

- Knob adaptors (printed — see `mechanical/Knob Adaptors/`)
- Display mount / bezel
- ESP32 controller housing Rev C: printed, fitted, wired and installed as a
  prototype on 2026-09-07; it fitted first time. Seven prototype and two
  installation gates remain before production release.
- IEC C14 mounting plate Rev B: 15/15 CAD checks pass and the owner confirmed
  the corrected profile drawing; physical fit remains open. Rev A is rejected.
- Standoffs, screws, brackets

## Consumables / Harness

- Wire per the colour standard in `docs/Wiring.md` (Brown GND, Red 3.3 V, Orange 5 V, White signal), except the installed H4 OLED loom: Orange = SCL and Yellow = SDA; both are signals and must never be connected to 5 V
- Removable connectors at the controller end (harnesses H1–H6), including the purchased Lyeteung JST-XH 4-pin set where appropriate
- Heat-shrink, solder, ferrules and strain-relief materials

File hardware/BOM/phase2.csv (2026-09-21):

designator | item | quantity | manufacturer | model | status | notes
A1 | Network streamer | 1 | WiiM | WiiM Pro | ACQUIRED-INSTALLED-API-VERIFIED | Delivered 2026-09-10 and commissioned against the live local API. EQ off; volume limit 70%. Line-level source only; continuously powered with automatic standby. Do not substitute WiiM Amp/Amp Pro without a new ADR.
A2 | Stereo power amplifier | 1 | Fosi Audio | ZA3 | ACQUIRED-INSTALLED | Delivered 2026-09-10 with 48 V / 5 A power supply. Separate analogue power amp; gain/volume is fixed as the commissioning ceiling while user volume is controlled through WiiM. Power-state control remains through the locked 12 V-trigger architecture.
A3L/A3R | Passive speakers | 2 | Bowers & Wilkins | DM601 S3 | ACQUIRED-MOUNTED-FIT-VERIFIED | Installed in the original speaker bays on spikes. Front ports and tweeters are aligned with openings in the retained speaker-cover construction; surrounding bay air space is intentionally left unpacked.
A4 | ZA3 trigger driver and 12 V source | 0 | Not required | Not required | REMOVED | Superseded by ADR-0018. Do not connect the ESP32 to the 12 V trigger line.
A5 | WiiM-to-ZA3 trigger lead or adaptor | 1 | WiiM/Fosi | 2.5-mm-to-3.5-mm trigger connection | INSTALLED-ACCEPTED | Direct WiiM Pro trigger out to ZA3 trigger in under ADR-0018. Physical acceptance passed: 30-second standby and switch-only wake. No ESP32 electrical connection to the 12 V line.
A6 | Stereo RCA interconnect | 1 | WiiM | Supplied stereo RCA lead | ACQUIRED-ACCEPTED | Retained for WiiM Pro line output to ZA3 input. No audiophile replacement is required unless a fault, interference or unsuitable final length is found.
A6B | Turntable-to-WiiM analogue interconnect | 1 | UGREEN | RCA to 3.5 mm stereo phono/mini-jack lead 1 m (ASIN B015PZ7QO2) | PURCHASED-DELIVERED-IN-USE | Connects the turntable analogue output to WiiM Pro Line-In. Replacement cable ordered for GBP6.28 after the first example was returned as defective; delivered 2026-09-15.
A7 | Speaker cable and internal harness | 3 x 1 m | QED | Profile 79 Strand C-79/100B-1M | PURCHASED-DELIVERED-INSTALLATION-CHECK | Black 2 x 2.5 mm2 OFC cable; three separate 1 m lengths provide two short ZA3-to-speaker runs plus one spare. Delivered 2026-09-16 from Inta Audio via eBay; GBP6.30 total with free postage.
A7B | Speaker cable plugs | 4 | QED | Screwloc Forte 4 mm gold-plated banana plugs | PURCHASED-DELIVERED-INSTALLATION-CHECK | Pack of four delivered 2026-09-18 from Amazon; sufficient to terminate one end of both stereo runs. Opposite ends remain bare wire unless four additional plugs are purchased.
A8 | Turntable | 1 | Audio-Technica | AT-LP120X | ACQUIRED-EXISTING | Existing turntable selected for the Decca installation; no turntable purchase required. Verify physical fit and final mounting/clearance in the original turntable bay before installation.

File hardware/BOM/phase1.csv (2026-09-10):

item | quantity | specification | supplier | part_number | status
ESP32 DevKit | 1 | 30-pin DevKit V1 / DOIT-style; Wi-Fi; at least 4 MB flash; control/UI only; authenticated OTA bootstrap implemented, physical USB-to-OTA acceptance pending | Existing stock | TBD | acquired-ota-acceptance-pending
ESP32 screw-terminal adapter | 1 | matching 30-pin terminal adapter for installed controller | Existing stock | TBD | acquired
10 kOhm linear potentiometer | 4 | ABW1 10K linear position sensor; Balance, Treble, Bass and Volume; not in audio path | CPC / AB Elektronik / TT Electronics | ABW1 10K / CPC RE04644 | installed-and-verified
OLED display | 1 | 1.3-inch; white; 128x64; SH1106; four-pin I2C; 3.3 V | The Pi Hut | SKU 105630 | installed-and-verified
N-channel MOSFET driver module (existing test stock) | 10 (1 previously tested) | DAOKAI 3.3 V / 5 V PWM MOSFET driver module with cable; one module passed the earlier GPIO25 bench test on 2026-08-31; retained as test stock but superseded for the final installation by DFR0457 | Amazon / DAOKAI | ASIN B09YYH2BTF | retained-test-stock-superseded
MOSFET power controller | 1 | DFRobot Gravity MOSFET Power Controller installed on GPIO18/D18 for final dial-lamp switching; 5-36 V DC load input; 3.3-10 V logic/control; 1 kHz and 85% duty; steady illumination passed without flicker; deployed firmware v0.27.4 removes the ineffective fade engine and applies changed duties immediately; immediate power-transition and Mono/off re-verification after HW-SW-01 plus pot-stability, temperature and current pending | The Pi Hut | DFRobot DFR0457 | installed-immediate-firmware-deployed-final-checks-pending
E10 warm-white LED lamps | 10 (3 required) | ShuoHui AC/DC E10 miniature screw LED bulbs; 6 V; 0.2 W; 3000 K; 5 V operation verified; ten purchased and required lamps fitted | Amazon / ShuoHui | ASIN B0CFTLZFGT | purchased-and-fitted
5 V regulated control supply | 1 | Phihong switching adapter; input 100-240 V AC 50-60 Hz 0.5 A; output 5.0 V DC 3.0 A (15 W); PSU output lead is now soldered directly into the Decca low-voltage wiring, eliminating the panel DC socket; shared 5 V control rail feeds the ESP32 at VIN/5V with USB removed; previously powered the accepted three-lamp PWM test on 2026-08-31 | Phihong | PSA15R-050P | soldered-direct-shared-rail-usb-removed
Panel-mount DC input socket | 5 (1 required) | TopHomer two-terminal threaded-nut female panel sockets; 5.5 mm OD x 2.1 mm ID; previously intended for the Phihong input but no longer required because the PSU output is soldered directly into the Decca low-voltage wiring | Amazon / TopHomer | ASIN B08HGXYS4J | obsolete-not-required
Low-voltage inline fuse holder | 1 | original Decca inline fuse holder reused in the +5 V conductor immediately after the soldered PSU output connection and before distribution | Original Decca hardware | TBD | implemented
2 A fuse | 2 | one fitted and one spare; recheck final rating against measured lamp current during bench commissioning | Purchased | TBD | purchased
5 V and GND distribution connectors | 3 (2 required) | WAGO 221-415 five-way lever connectors; use one as the +5 V star point and one as the common-GND star point, with the third retained as a spare; accepts the selected 22-24 AWG wiring | The Pi Hut | WAGO 221-415 / SKU 104130 | ordered-pending-delivery-verification
JST-XH removable connector harnesses | 15 pairs | Lyeteung 4-pin male/female JST-XH 2.54 mm connectors with 150 mm 22 AWG leads; use where a four-way removable low-voltage harness is suitable | Amazon / Lyeteung | ASIN B0CBWX98NF | ordered-pending-delivery-verification
22-24 AWG stranded power wire and ferrules | 1 lot | stranded production-build power wiring and suitable ferrules for ESP32 terminal adapter and distribution connectors | The Pi Hut / TBD | TBD | ordered-pending-delivery-verification
IEC C14 panel-mount mains inlet | 1 | rear-panel IEC C14 male appliance inlet; 250 V AC; 10 A class; acquired part measured by the owner for the corrected six-sided Rev B mounting profile; Rev B passes 15/15 CAD checks and the owner confirmed the profile drawing; physical inlet fit, fixing alignment, flat clamping, insulation and rear terminal/wire clearance remain mandatory before mains energisation | Amazon | TBD | acquired-measured-revb-cad-pass-physical-fit-pending
UK mains to IEC C13 lead | 1 | BS 1363 UK plug to IEC C13 female detachable mains lead; appropriately fused UK plug; provides removable external mains connection to rear C14 inlet | Amazon | TBD | ordered-pending-delivery-verification
Internal 4-gang mains distribution block | 1 | Masterplug four-socket 13 A UK extension block for internal distribution to the Decca mains-powered modules; retain intact enclosure and confirm secure mounting, cable routing, earthing and final connection method to the C14 inlet before installation | Amazon / Masterplug | TBD | ordered-pending-delivery-verification

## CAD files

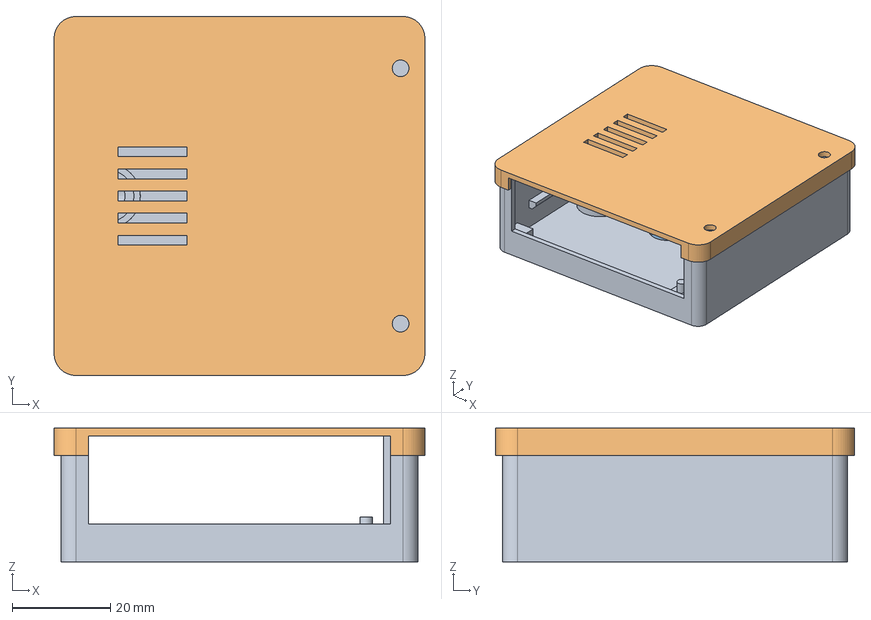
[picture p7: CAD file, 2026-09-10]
mechanical/CAD/Decca_ESP32_Controller_Housing_assembly.step
75.5 x 73.1 x 27.2 mm
Housing_Base
Housing_Lid
Cabinet_Fastener_Caps

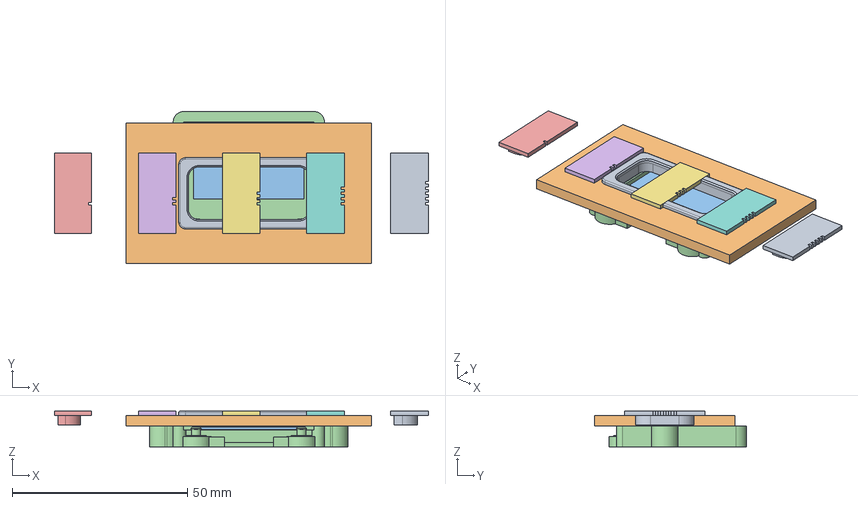
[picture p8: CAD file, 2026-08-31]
mechanical/CAD/Decca_Display_Bezel_revQ_assembly.step
106.6 x 43.3 x 10.2 mm
Front_Bezel_revQ
REF_Decca_Panel
REF_OLED_Glass
Rear_Display_Carrier
Bezel_Fit_Gauge_revQ

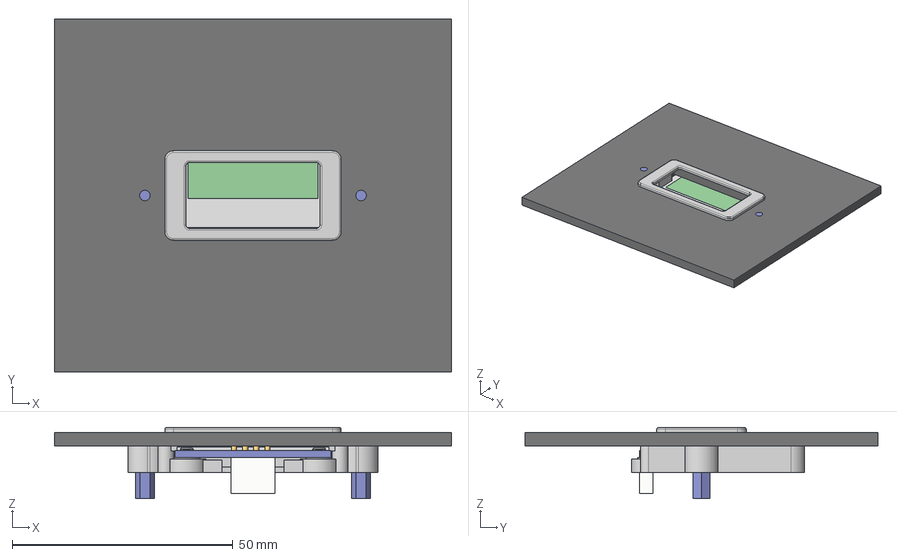
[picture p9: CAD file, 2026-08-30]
mechanical/CAD/Decca_Display_Mount_revP_assembly.step
90.0 x 80.0 x 16.2 mm
REF_Decca_Panel
REF_SH1106_1P3
Rear_Display_Carrier
REF_Decca_Fasteners
REF_Front_Bezel_revN

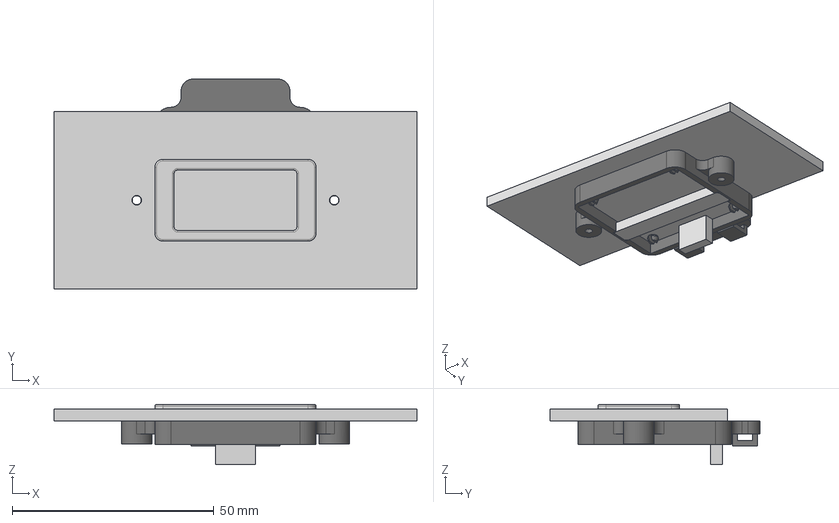
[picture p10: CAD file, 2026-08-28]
mechanical/CAD/Decca_Display_Mount_revN_assembly.step
90.0 x 52.0 x 15.0 mm
REF_Decca_Panel
Front_Bezel
REF_SH1106_1P3
Rear_Display_Carrier
Retainer_Bar

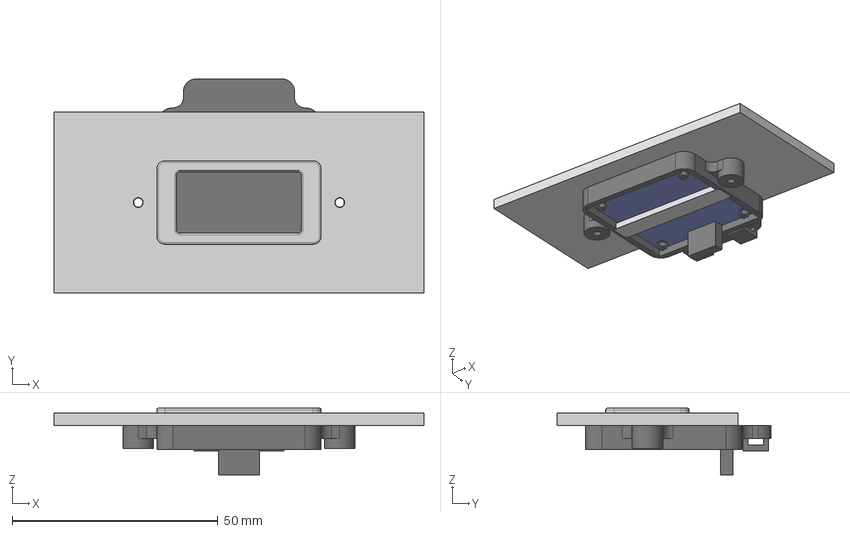
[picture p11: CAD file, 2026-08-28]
mechanical/CAD/Decca_Display_Mount_revL_assembly.step
90.0 x 52.0 x 16.2 mm
REF_Decca_Panel
Front_Bezel
REF_SH1106_1P3
Rear_Display_Carrier
Retainer_Bar

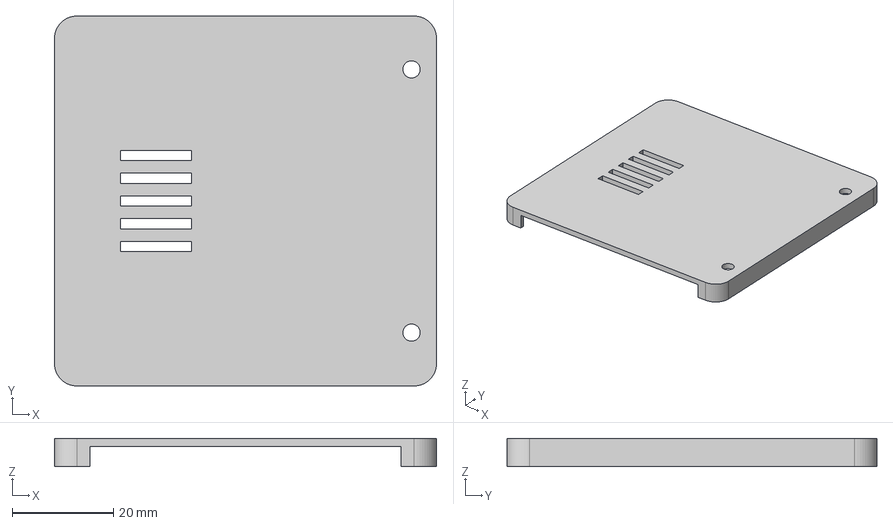
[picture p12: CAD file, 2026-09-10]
mechanical/CAD/ESP32_Controller_Housing_Lid.step
75.5 x 73.1 x 5.60 mm

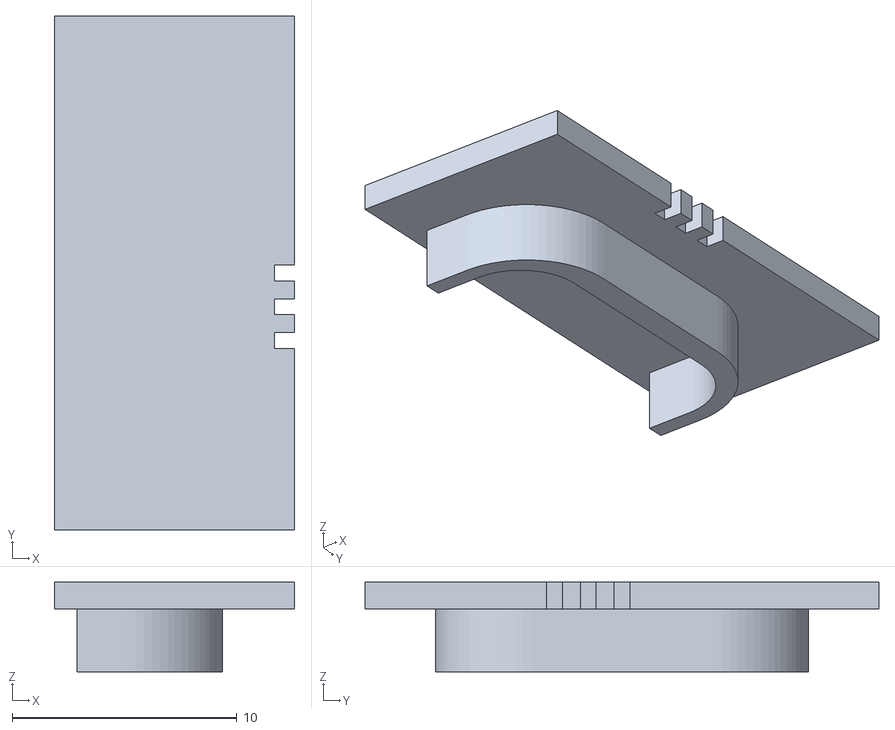
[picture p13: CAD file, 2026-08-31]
mechanical/STL/Bezel_Fit_Gauge_revQ_GAUGE_I010.stl
10.7 x 22.9 x 4.00

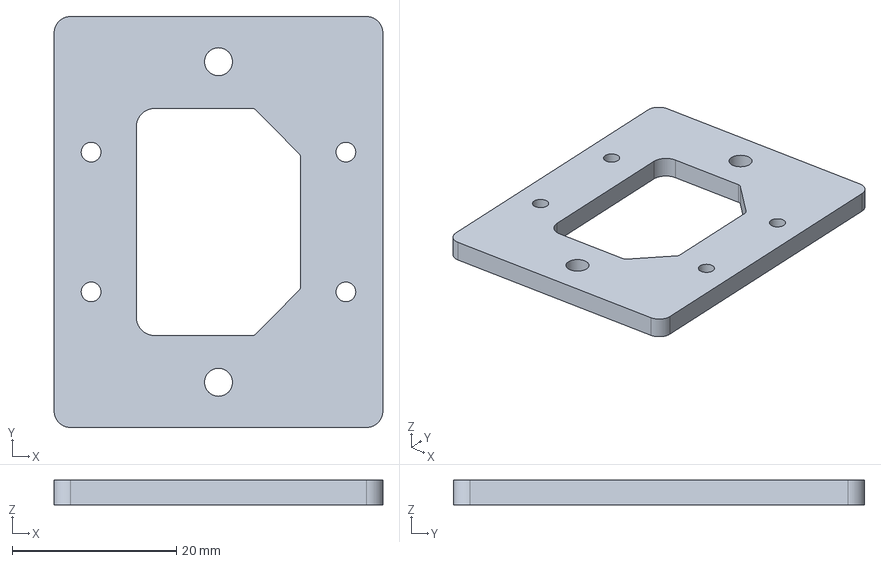
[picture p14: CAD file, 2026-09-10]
mechanical/CAD/Decca_IEC_C14_Mounting_Plate_revB.step
40.0 x 50.0 x 3.00 mm

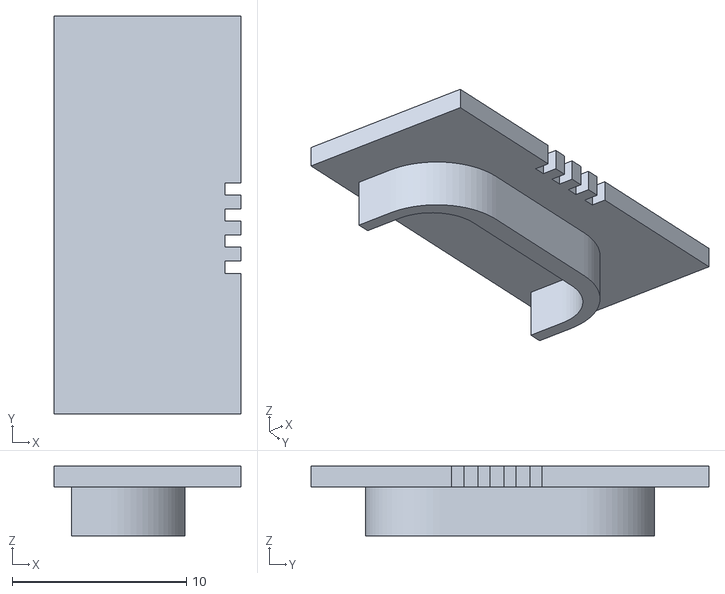
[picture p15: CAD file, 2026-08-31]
mechanical/STL/Bezel_Fit_Gauge_revQ_GAUGE_I015.stl
10.7 x 22.9 x 4.00

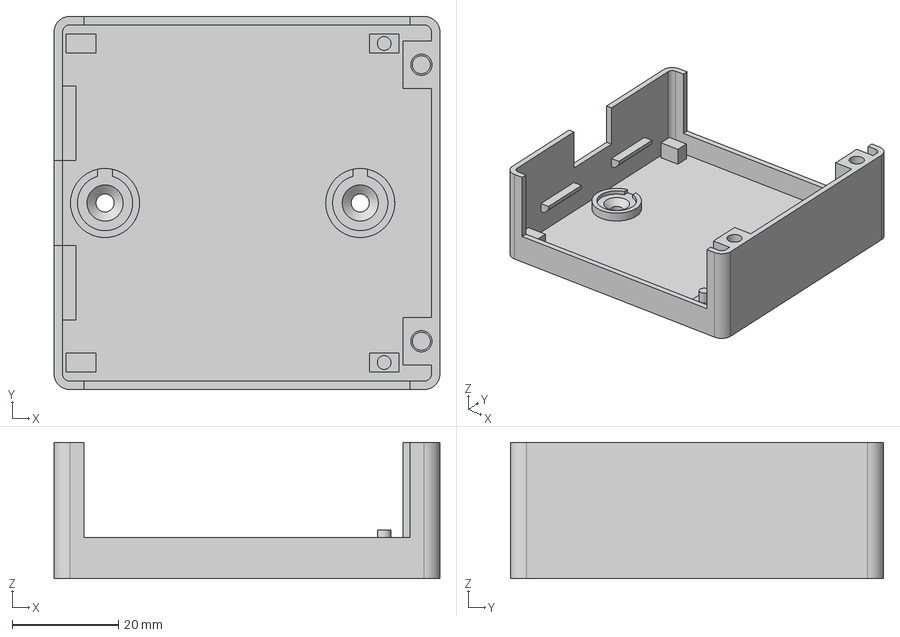
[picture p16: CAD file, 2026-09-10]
mechanical/CAD/ESP32_Controller_Housing_Base.step
72.6 x 70.2 x 25.6 mm

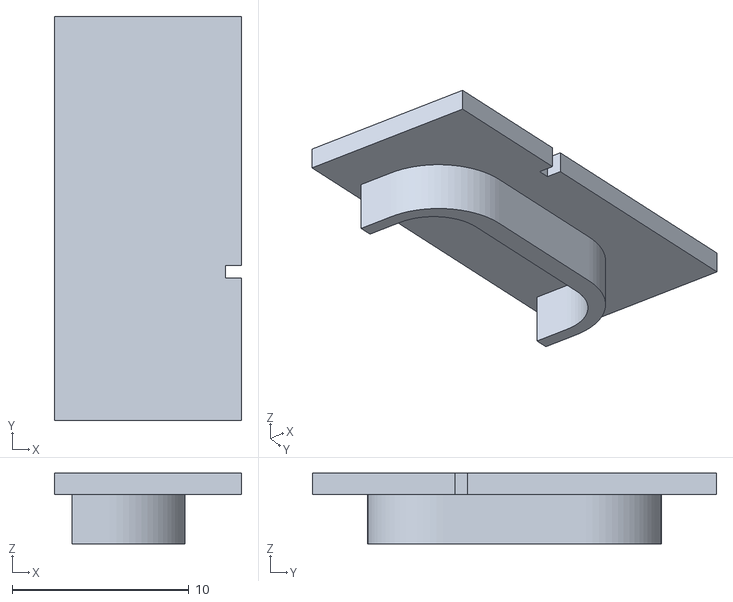
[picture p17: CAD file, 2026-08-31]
mechanical/STL/Bezel_Fit_Gauge_revQ_GAUGE_I000.stl
10.6 x 22.9 x 4.00

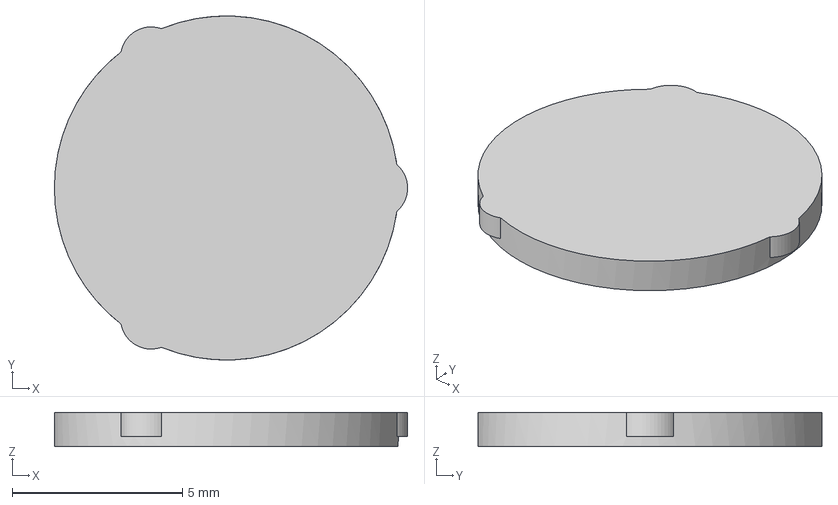
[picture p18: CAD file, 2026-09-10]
mechanical/CAD/ESP32_Controller_Cabinet_Fastener_Cap.step
10.4 x 10.1 x 1.00 mm

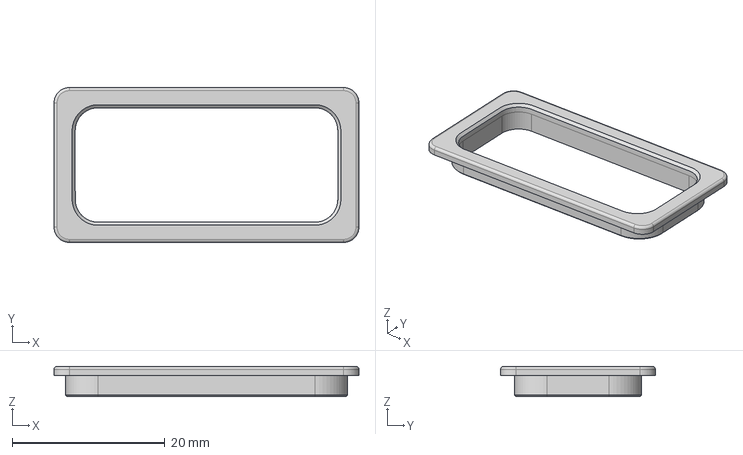
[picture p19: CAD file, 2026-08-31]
mechanical/CAD/Front_Bezel_revQ.step
40.0 x 20.3 x 4.00 mm

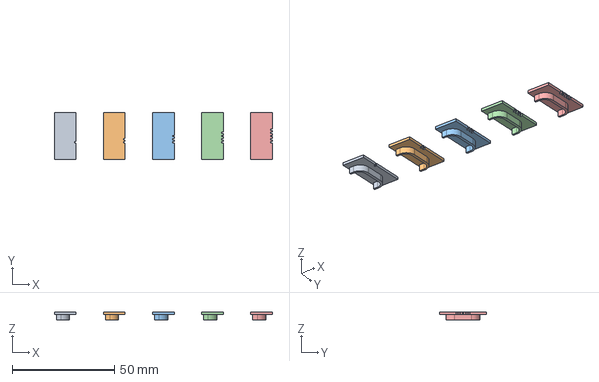
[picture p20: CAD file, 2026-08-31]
mechanical/CAD/Bezel_Fit_Gauge_revQ.step
106.6 x 22.9 x 4.00 mm

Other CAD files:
mechanical/STL/Bezel_Fit_Gauge_revQ_GAUGE_I020.stl
mechanical/STL/Bezel_Fit_Gauge_revQ_GAUGE_I005.stl
mechanical/CAD/Rear_Display_Carrier_revP.step
mechanical/CAD/Hex_Pocket_Fit_Coupon_revP.step
mechanical/CAD/Decca_Display_Bezel_revQ.f3d
mechanical/CAD/Decca_Display_Mount_revN.f3d
mechanical/CAD/Decca_Display_Mount_revP.f3d
mechanical/CAD/Decca_ESP32_Controller_Housing.f3d
mechanical/CAD/Decca_IEC_C14_Mounting_Plate_revA.step
mechanical/CAD/Front_Bezel_revE.step
mechanical/CAD/Front_Bezel_revN.step
mechanical/CAD/Rear_Display_Carrier_revL.step
mechanical/CAD/Rear_Display_Carrier_revN.step
mechanical/CAD/Retainer_Bar_revL.step
mechanical/CAD/Retainer_Bar_revM.step
mechanical/CAD/Retainer_Bar_revN.step
mechanical/STL/Decca_IEC_C14_Mounting_Plate_revA.stl
mechanical/STL/Decca_IEC_C14_Mounting_Plate_revB.stl
mechanical/STL/ESP32_Controller_Cabinet_Fastener_Cap.stl
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

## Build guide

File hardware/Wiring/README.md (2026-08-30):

# Wiring

Harness and interconnect diagrams — how modules physically connect inside the
cabinet.

**Intended contents**
- Point-to-point wiring diagrams and harness drawings for H1–H5.
- Connector pinout tables.

**Harnesses** (see `docs/Wiring.md` for the authoritative detail)
- H1 — potentiometer harness
- H2 — original on/off switch harness
- H3 — radio/source button harness
- H4 — OLED harness
- H5 — dial-lighting harness

**Conventions**
- The authoritative textual pin map and colour standard live in `docs/Wiring.md`
  and must be reconciled with `src/hardware.h` before any build. Diagrams here
  illustrate that map.
- Colour standard: Brown = GND, Red = 3.3 V, Orange = 5 V, White = signal. The
  original on/off switch keeps its original Red/Green conductors as a documented
  exception.
- H4 OLED loom exception: Orange = SCL (GPIO22) and Yellow = SDA (GPIO21).
  Both are signal conductors; never connect either to 5 V.

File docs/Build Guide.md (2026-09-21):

# Build Guide

> **Status:** placeholder. Populate as the physical build progresses.

Step-by-step guide to reproducing the decca build, from bare cabinet to working
music centre. This document should let a competent maker rebuild the project
from parts.

## 1. Before You Start
- Tools required
- Skills assumed (soldering, basic CAD/printing, PlatformIO)
- Safety notes (mains, dust, original finish)

## 2. Preparing the Cabinet
- Assessment and restoration of the original piece
- What is preserved vs. replaced
- Cleaning and refinishing notes

## 3. Electronics Assembly
- ESP32 and peripheral mounting
- Wiring the front-panel controls
- Power supply and rails
- Cross-references: [Wiring](Wiring.md), [Parts List](Parts List.md)

## 4. Mechanical Fit-Out
- Display mounting behind the dial glass
- Knob adaptors (see `mechanical/Knob Adaptors/`)
- Lighting placement

## 5. Firmware Flashing and OTA Bootstrap

Complete both the USB and wireless uploads before mounting the ESP32 where USB
access is difficult. OTA code being present is not proof that the installed
network and credentials work.

### 5.1 Prepare PlatformIO on Windows

In a normal PowerShell window, `pio` may not be on PATH even when the
PlatformIO VS Code extension is installed. Use its executable directly:

```powershell
$pio = "$env:USERPROFILE\.platformio\penv\Scripts\platformio.exe"
& $pio --version
& $pio device list
```

If the first command fails, install or repair the PlatformIO IDE extension in
VS Code before continuing.

### 5.2 Create the private configuration

```powershell
git pull origin main
if (-not (Test-Path src\secrets.h)) {
    Copy-Item src\secrets.example.h src\secrets.h
}
notepad src\secrets.h
```

Replace the four placeholders locally. Use a long unique OTA password. Never
commit, paste into chat or publish `src/secrets.h`; it is gitignored.

### 5.3 Test and flash once by USB

Connect the ESP32 and rerun `device list`. Set the real port shown by
PlatformIO. The example below assumes COM5. Do **not** type the literal
placeholder `COM_PORT`, and do not add a backslash before the port name.

```powershell
$port = "COM5"
& $pio test -e esp32dev -f test_ota
& $pio run -e esp32dev -t upload --upload-port $port
& $pio device monitor --port $port -b 115200
```

Wait for:

```text
[OTA] ready at 192.168.x.x (decca.local)
```

Record the IP address, then exit the serial monitor with Ctrl+C.

### 5.4 Prove authenticated wireless upload

Set the same private OTA password used in `src/secrets.h`, perform one wireless
upload, then clear it from the PowerShell process:

```powershell
$env:DECCA_OTA_PASSWORD = "THE SAME PRIVATE OTA PASSWORD"
& $pio run -e esp32dev-ota -t upload
Remove-Item Env:DECCA_OTA_PASSWORD
```

If mDNS cannot resolve `decca.local`, use the address printed by the ESP32:

```powershell
$env:DECCA_OTA_PASSWORD = "THE SAME PRIVATE OTA PASSWORD"
& $pio run -e esp32dev-ota -t upload --upload-port 192.168.x.x
Remove-Item Env:DECCA_OTA_PASSWORD
```

The computer and Decca must be on the same local network. Guest-network
isolation or a VPN may block OTA. Do not expose the OTA service to the internet.

Pass criteria:

- `test_ota` passes on the ESP32;
- the USB bootstrap upload succeeds;
- serial reports `[OTA] ready`;
- an authenticated wireless upload succeeds and the ESP32 reboots;
- the device reports ready again after the OTA reboot.

Recorded result (2026-08-30): the authenticated `esp32dev-ota` upload succeeded.
After the ESP32 rebooted, serial reported
`[OTA] ready at 192.168.x.x (decca.local)`. USB-to-OTA physical acceptance is
complete.

The dual application slots protect against interrupted or rejected transfers.
Automatic rollback after a fully received image fails to boot remains a Phase 3
hardening item, so preserve a practical USB recovery route even after OTA passes.

Recorded result (2026-09-12): firmware v0.28.0 from source commit `d06e357`
passed the credential-enabled build and authenticated OTA. One upload interrupted
while the controller was also polling the WiiM; the previous image remained
bootable, and the retry completed with the WiiM temporarily powered off. The
streamer and controller currently share an mDNS label, so the commissioning
upload used the controller's reserved address without recording it in Git.
The installed build reuses its secure WiiM connection for direct absolute-volume
commands; exact 10%, 20% and 30% setpoints were confirmed in WiiM Home.

Recorded result (2026-09-19): source commit `36d84d1` built at 52,328 bytes RAM
(16.0%) and 1,016,977 bytes flash (77.6%) and was installed by authenticated
OTA; the transfer reached 100% and the controller returned without USB
intervention. The final logical-power acceptance used a 30-second WiiM standby
timer. OFF removed the direct trigger and placed the ZA3 in standby. ON sent a
safe one-step downward volume pulse, restored the requested value and woke the
WiiM and ZA3 without app interaction or automatic playback.

## 6. First Power-On
- Bring-up checklist
- Smoke-test procedure
- Common issues

## 7. Commissioning

### 7.1 Potentiometer bench verification

This procedure passed on 2026-08-24, confirming the four GPIO assignments. Keep
it as the commissioning method after any harness rework or controller
replacement. Keep the Decca disconnected from mains; power only the ESP32 and
the low-voltage pot harness by USB during this test.

1. With the harness disconnected, measure each 10 kΩ linear pot:
   - resistance between the two outside lugs should remain approximately 10 kΩ;
   - resistance from centre wiper to each outside lug should change smoothly
     and in opposite directions through the full travel.
2. Viewed from the rear of each installed pot, connect left lug to GND (Brown),
   centre wiper to its ADC1 pin (White), and right lug to 3.3 V (Red). On the
   30-pin ESP32 DevKit used in this build, the terminal adapter exposes the same
   printed labels as the board. Use the **printed board label** shown below when
   locating each ADC terminal:

   | Control | Bench-verified GPIO | Printed board label |
   |---------|---------------------|---------------------|
   | Volume  | GPIO32              | **D32**             |
   | Bass    | GPIO33              | **D33**             |
   | Treble  | GPIO34              | **D34**             |
   | Balance | GPIO35              | **D35**             |

   Therefore the four White wiper wires connect to **D32, D33, D34 and D35**
   respectively. The Red wires go to 3V3 and the Brown wires go to GND.
3. Set all four controls fully anticlockwise, connect the ESP32 by USB, and run:

   ```powershell
   pio test -e esp32dev -f test_pots
   ```

4. Record the four raw readings from the line beginning `POT_SNAPSHOT`.
5. Repeat with all four controls centred, then fully clockwise.
6. Verify direction and channel identity with four more runs: set one control
   fully clockwise and the other three fully anticlockwise, changing the
   clockwise control each run.

Pass criteria:

- each named reading responds only to its matching physical control;
- readings change monotonically through the travel without large discontinuities;
- each control reaches at least below 250 and above 3800 raw counts;
- the midpoint is broadly central (typically 1600–2500 raw counts);
- the physical snapshot test and all five deterministic behavioural tests in
  the suite pass on the ESP32.

Record the observed low/high endpoints before applying per-pot calibration.
If a control is electrically sound but its value falls as it turns clockwise,
use the firmware's per-pot `inverted` calibration option rather than placing the
ESP32 in any audio path.

Recorded result (2026-08-24):

| Control | GPIO | Board label | Anticlockwise | Approx. centre | Clockwise | Direction |
|---|---|---|---|---|---|---|
| Volume  | 32 | D32 | 0 | 2047 | 4095 | Increasing clockwise |
| Bass | 33 | D33 | 0 | 2047 | 4095 | Increasing clockwise |
| Treble  | 34 | D34 | 0 | 2047 | 4095 | Increasing clockwise |
| Balance | 35 | D35 | 0 | 2047 | 4095 | Increasing clockwise |

All six `test_pots` cases passed. Midpoint variation is expected because the
controls have no centre detent. The default 0–4095 calibration is retained with
no inversion.

### 7.2 VHF two-state source verification

Only the reliable VHF-derived two-Black-conductor pair is used. Keep the Decca
disconnected from mains and power only the ESP32 by USB.

1. Connect one Black conductor of the VHF-derived pair to GPIO26 / board label
   D26 and the other Black conductor to GND; the dry-contact pair may be
   swapped. This routing was physically verified on 2026-09-08.
2. Leave SW, MW, LW and Gram conductors disconnected and individually insulated.
   Do not connect them to GPIO13, GPIO16, GPIO17, GPIO19 or GPIO23.
3. Run:

   ```powershell
   pio test -e esp32dev -f test_buttons
   ```

4. With VHF latched, expect:

   ```text
   BUTTON_SNAPSHOT pressed onoff=<0-or-1> vhf=1 source=digital
   ```

5. Press any other fascia source button to release VHF and rerun. Expect
   `vhf=0 source=vinyl`.

Pass criteria:

- VHF closed reports Digital Streamer;
- VHF open reports Vinyl;
- all nine behavioural tests pass;
- SW, MW, LW and Gram have no individual reported input.

The former LW solder repair is no longer required. If the VHF contact itself
later becomes unreliable, the deferred fallback is a purpose-built replacement
button panel.

### 7.3 Original on/off switch verification

This procedure passed on GPIO19/D19 on 2026-08-30 and on the final GPIO14/D14
route on 2026-09-08, confirming the retained H2 Red/Green cable. Keep the Decca disconnected from mains and power only the
low-voltage ESP32 controller by USB.

1. Connect H2 Red to GPIO14 / board label D14 and H2 Green to GND. GPIO14 uses
   the ESP32 internal pull-up; do not connect either conductor to 3.3 V or 5 V.
2. Run:

   ```powershell
   pio test -e esp32dev -f test_buttons
   pio test -e esp32dev -f test_power
   ```

3. Restore the production firmware, open the 115200-baud serial monitor and move
   the retained switch through both positions.

Pass criteria:

- closed reports `[POWER] state=ON` and shows the normal on-state display;
- open reports `[POWER] state=STANDBY` and shows the standby confirmation;
- returning to closed wakes the display immediately;
- all button and power tests pass without using the switch for mains voltage.

Recorded result: both switch directions were physically accepted on D14 with
v0.27.3. No logical inversion is required.

### 7.4 OLED bench verification

This procedure passed on 2026-08-25, confirming GPIO21 and GPIO22. Keep it as
the commissioning method after any display, harness or controller replacement.
Keep the Decca disconnected from mains and power only the ESP32 by USB.

1. Read the labels printed beside the delivered OLED header. Do not infer its
   physical pin order from another module or online photograph.
2. Connect the purchased Pi Hut SH1106 panel:
   - OLED GND → ESP32 GND (Brown);
   - OLED VCC → ESP32 3V3 (Red), never 5 V for this build;
   - OLED SDA → GPIO21 / board label D21 (Yellow);
   - OLED SCL → GPIO22 / board label D22 (Orange).

   H4 is a documented colour-standard exception: its Orange conductor is SCL
   and its Yellow conductor is SDA. Both are signals; never connect either to
   the 5 V rail.
3. In the PlatformIO terminal run:

   ```powershell
   git pull origin main
   pio test -e esp32dev -f test_display
   ```

4. Confirm the OLED reveals the `DECCA` wordmark from left to right over roughly
   1 s, then holds `MUSIC CENTRE v0.27.4` for roughly 2.2 s in the lower
   calibrated area before showing `VINYL` prominently without a legacy button
   label and a local dashboard with Volume 75% and the other three controls at
   50%.
5. Confirm the output contains:

   ```text
   DISPLAY_SNAPSHOT controller=SH1106 address=0x3C ready=1
   ```

Pass criteria:

- the panel is detected at 0x3C;
- all five startup frames and the dashboard are upright, complete and not
  offset;
- white pixels are clear with no persistent noise or clipped columns;
- all fifteen display tests pass, including inactivity dim, pixel-off sleep and
  immediate wake behaviour.

Production protection policy: contrast 0x80 while active, contrast 0x20 after
60 seconds without activity, pixels off after five minutes, and standby pixels
off after ten seconds. Relevant state/control/status activity wakes the panel.

Recorded result (2026-08-25): the purchased SH1106 panel was detected at 0x3C,
all ten `test_display` cases passed, and the animated startup and revised
dashboard were upright, complete, unclipped and free of persistent display
artefacts. GPIO21 (SDA) and GPIO22 (SCL) are bench-verified. Final loom
orientation was physically confirmed on 2026-08-30: Brown = GND, Red = VCC,
Orange = SCL and Yellow = SDA.

Fitted-aperture refinement (2026-08-30): photographs through the final Perspex
opening established a logical visible viewport of X4–123 and Y10–61. Normal UI
content deliberately uses the more conservative Y24–60 band because the upper
part becomes difficult to read at the installed viewing angle. Firmware rotates
the output 180 degrees, sets panel contrast to 0x80 to reduce optical bloom and
uses focused single-purpose views rather than a crowded permanent dashboard.
The accepted layouts cover identity/standby, control value and bar, source
confirmation, status/diagnostics, and title/artist metadata with a bottom-right
play or pause glyph. The full 128×64 calibration pattern remains available as a
service diagnostic but is not shown during normal startup.

If the panel is blank, disconnect USB before checking VCC/GND order and the
SDA/SCL labels.

### 7.5 Stereo/Mono input verification

Keep GPIO18 and the lamp load disconnected for this input-only test.

1. Connect the Stereo/Mono contact between GPIO25 / board label D25 and GND. Do
   not connect 3.3 V or 5 V to the switch.
2. Connect the ESP32 by USB and run:

   ```powershell
   pio test -e esp32dev -f test_buttons
   ```

3. Capture the `BUTTON_SNAPSHOT` once in each stable position. Stereo must show
   `stereo_mono_contact=0 lights=on`; Mono must show
   `stereo_mono_contact=1 lights=off`.
4. Confirm all eleven button tests pass. If the two physical positions are
   reversed, stop and correct the documented contact/polarity before enabling
   any lighting output.

Recorded result (2026-09-08): GPIO25 firmware logic is correct, but the retained
switch did not produce the Mono closed/LOW state. Repair the switch under
HW-SW-01, then repeat steps 3–4 before accepting end-to-end operation.

### 7.6 Dial-lighting bench verification

GPIO18 is the installed DFR0457 PWM route. Keep the Decca disconnected
from mains. Use only the isolated low-voltage 5 V lighting supply and USB power
for the ESP32.

1. Check the MOSFET stage before applying power:
   - GPIO18 / board label D18 connects only to the DFR0457 control input;
   - the MOSFET source connects to GND;
   - the dial-light negative lead connects to the MOSFET drain;
   - the dial-light positive lead connects to 5 V;
   - the ESP32 and 5 V lighting supply share GND.
2. Confirm there is no direct connection from the dial-light load to GPIO18 and
   no connection to the Decca mains wiring.
3. Connect the ESP32 by USB and run:

   ```powershell
   pio test -e esp32dev -f test_lighting
   ```

4. Observe the dial lighting. It should switch immediately from off to the test
   duty and immediately back to off, without flashing at full brightness or
   waiting before the final change.
5. Confirm the output contains `LIGHTING_SNAPSHOT duty=217`, the lamps hold at
   the approved 85% duty for five seconds, and all six tests pass.

Pass criteria:

- the light starts and finishes fully off;
- brightness changes immediately in both directions;
- no full-brightness flash occurs at reset or test start;
- the MOSFET and wiring remain cool;
- all six behavioural tests pass.

Recorded result (2026-08-31): GPIO25, the DAOKAI MOSFET stage and the three-lamp
electrical load passed. Brightness comparisons at 70%, 80% and 100% resulted in
owner approval of 90% / duty 230. The lamps fade smoothly, hold evenly and fade
fully off with no flash, flicker, abnormal heat or smell.

Current route (2026-09-08): the installed DFR0457 control input is on GPIO18.
Firmware v0.27.3 established safe-off before other setup, authenticated OTA
succeeded, the device returned at `decca.local`, and the owner confirmed the D18
path reached the fully-on target. Mono/off re-verification awaits HW-SW-01.

Current firmware (2026-09-09): v0.27.4 removes all fades and was deployed by
authenticated OTA from commit `19c16b6`; `decca.local` returned at
its reserved address. Physical immediate-transition verification remains open.

### 7.7 Remaining commissioning

- Confirming final holder fit and measuring the installed three-lamp current

### Wi-Fi reliability update — 2026-09-21 (v0.28.5)

The installed controller is the 30-pin ESP32 DevKit V1/DOIT-style board using
Arduino/PlatformIO, not ESPHome or ESP32-C3. The current OTA target is
`decca-esp32.local`; the older `decca.local` examples above are historical.

Power saving was already disabled and remains intentionally disabled with
`WiFi.setSleep(false)` / `WIFI_PS_NONE` (equivalent to ESPHome
`power_save_mode: none`). TX power was previously implicit. v0.28.5 requests an
explicit **20.0 dBm ceiling** through `esp_wifi_set_max_tx_power(80)` after
association and on reconnection, to improve Wi-Fi reliability in the permanently
mains-powered installation. The installed ESP-IDF 4.4.7 header documents 80 in
quarter-dBm units as the maximum 20 dBm level. Actual RF output remains subject
to PHY, modulation and country limits. No credentials or unrelated settings change.

The existing `_arduino._tcp` service advertises `firmware`, `tx_power_qdbm`,
`power_save`, `rssi_at_connect` and `uptime_ms_at_connect`. These are snapshots
when the OTA service starts, not continuous telemetry; power-save value 0 means
`WIFI_PS_NONE`, and TX value 80 means 20 dBm. Getter failures omit the respective
field. Setter failures are logged on serial. No new remote control endpoint is added.

Baseline: the authenticated OTA service was reachable; four ping replies had
0% loss, 32–224 ms (mean 164 ms). Numeric RSSI, runtime TX/power-save readback
and uptime were not exposed by v0.28.4. Source inspection confirms sleep disabled,
but is not a runtime measurement. Authenticated OTA succeeded (114.14 s, uploader result OK). The rebooted
`decca-esp32.local` advertised firmware 0.28.5, power_save=0 and TX readback
78 quarter-dBm = **19.5 dBm** despite the accepted 20 dBm request. Thus 20 dBm
is the requested ceiling; the running radio clamps it to 19.5 dBm. Do not claim
20 dBm actual output, or an increase over the old implicit TX setting: no old
runtime readback exists. Connection-time RSSI was **-48 dBm**, at uptime 1321 ms.
The readbacks demonstrate the new application booted and reached connected OTA
service state. ESPHome/API checks do not apply to this Arduino firmware.

Validation: credential-enabled production build passed (52,336 bytes RAM,
1,020,161 bytes flash); test_ota compiled successfully without upload/execution.
Private Phase 2 settings were preserved and remain gitignored. No USB was used.
Serial boot/watchdog/power logs are not available over this firmware's LAN
interface; absence of those faults cannot be certified from discovery and ping.
Before/after numeric RSSI comparison is unavailable. Continue monitoring for
reconnects and control/audio symptoms; RSSI alone does not prove improvement.

Post-update observation: first 30 pings returned 28 replies (2 lost), 5-327 ms,
mean 108 ms. A second 30 returned 26 replies (4 lost), 7-646 ms, mean 154 ms.
Combined loss was 6/60 (10%). Fresh mDNS queries through 13:24 local time
continued to return v0.28.5 and the same connection snapshot. No persistent
outage was observed, but reliability is NOT resolved. The four-packet baseline
is too small to establish improvement or regression. Next diagnostic: compare
access-point client retry/disconnect counters and a longer simultaneous LAN
latency sample; inspect antenna placement/interference if loss persists. Obtain
boot/watchdog/power logs if resets or functional symptoms occur. Do not increase
power beyond the driver-supported ceiling or make unrelated recovery changes.

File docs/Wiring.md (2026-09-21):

# Wiring

> **Status:** active. This is the authoritative interconnect reference. Pin
> assignments marked **(proposed)** are documented intent and have **not** been
> bench-verified. Confirmed items reflect the physical build.

Records every physical connection so the build is reproducible. The firmware pin
map (`src/hardware.h`) must be reconciled against this document before any build
(see Specification `HW-06`). `hardware.h` matches the status recorded below: the
four pot inputs, OLED I²C GPIO21/22, on/off GPIO14, VHF GPIO26 and lighting PWM
GPIO18 are physically verified. Stereo/Mono firmware logic is assigned to
GPIO25; the retained switch fault remains open under HW-SW-01.

## Wiring Colour Standard

New control wiring follows a fixed colour standard:

| Colour  | Meaning |
|---|---|
| Brown | GND |
| Red | 3.3 V |
| Orange  | 5 V |
| White | Analogue signal / controlled return where documented |

**Exception — original on/off switch.** The retained original on/off switch uses
its original conductors, **Red** and **Green**. These are pre-existing and are
**not** to be recoloured or reinterpreted under the general loom standard above.
See the on/off section.

**Exception — H3 VHF dry-contact pair.** The installed VHF source-selector pair
uses **two Black conductors**. They form an isolated dry contact, so colour does
not distinguish signal from return and either Black conductor may be connected
to GPIO26 with the other connected to GND. See the H3 section.

**Exception — H4 OLED harness.** The installed and bench-verified screen loom
uses **Orange for SCL** and **Yellow for SDA**. These are signal conductors in H4
and must **never** be connected to the 5 V rail. H4 retains Red for 3.3 V and
Brown for GND. This final orientation was physically confirmed on 2026-08-30. See the OLED section.

H3 now uses only the reliable VHF-derived dry-contact pair. It has its own
return and no common-return conductor. All other selector conductors are left
disconnected and individually insulated at the controller end.

## Harnesses

Each harness is removable at the controller end where practical.

| ID  | Harness |
|-----|---|
| H1  | Potentiometer harness |
| H2  | Original on/off switch harness |
| H3  | Radio/source button harness |
| H4  | OLED harness |
| H5  | Dial-lighting harness |
| H6  | WiiM-to-ZA3 trigger lead |

## Pin Map

All ESP32 pin numbers below are **(proposed)** unless stated otherwise. The
**Board label** column records the silkscreen text printed beside the pin on the
30-pin ESP32 DevKit used in this build. For the four ADC inputs the printed
labels are simply `D32`, `D33`, `D34` and `D35` respectively.

| Signal | ESP32 Pin | Board label | Type | Harness | Notes |
|---|---|---|---|---|---|
| Volume pot wiper | GPIO32 (bench-verified) | **D32** | ADC1 | H1 | ADC1 required (Wi-Fi in Phase 2) |
| Bass pot wiper | GPIO33 (bench-verified) | **D33** | ADC1 | H1 | ADC1 required |
| Treble pot wiper | GPIO34 (bench-verified) | **D34** | ADC1, in-only | H1 | ADC1; input-only pin, no pull-up needed  |
| Balance pot wiper | GPIO35 (bench-verified) | **D35** | ADC1, in-only | H1 | ADC1; input-only pin |
| On/off switch (Red) | GPIO14 (physically verified) | D14 | Digital in | H2 | Internal pull-up; closed = ON |
| Source selector: VHF | GPIO26 (physically verified) | D26 | Digital in, pull-up | H3 | Closed = Digital Streamer; open = Vinyl |
| SW / MW / LW / Gram  | — | — | No individual GPIO | H3 | Mechanical positions release VHF and select Vinyl |
| Stereo/Mono | GPIO25 (logic verified; switch fault open) | D25 | Digital in, pull-up | H3 | Open Stereo = lights requested on; closed Mono = off |
| OLED SDA | GPIO21 (bench-verified) | D21 | I²C | H4 | Pi Hut SH1106, address 0x3C |
| OLED SCL | GPIO22 (bench-verified) | D22 | I²C | H4 | Pi Hut SH1106, address 0x3C |
| Dial lighting PWM | GPIO18 (physically verified) | D18 | PWM (LEDC), 1 kHz | H5 | Installed DFRobot DFR0457 control input; three-lamp bank |

> GPIO14, GPIO25 and GPIO26 support the required internal pull-ups and avoid the
> project's excluded ESP32 strapping pins GPIO0, GPIO2, GPIO5, GPIO12 and
> GPIO15. GPIO13, GPIO16, GPIO17, GPIO19 and GPIO23 are released; do not connect the unreliable
> source-selector contacts to them.

## H1 — Potentiometers

Four modern **10 kΩ linear** potentiometers used as **position sensors only**.
They are **not in the audio path**. Original Decca knobs are retained via a
mechanical adaptor strategy.

Controls: **Balance, Treble, Bass, Volume.**

Each potentiometer uses three conductors. Viewed from the **rear** of the
installed potentiometer:

| Lug | Conductor | Function |
|---|---|---|
| Left | Brown | GND |
| Centre  | White | Wiper / analogue signal |
| Right | Red | 3.3 V |

At the ESP32 terminal adapter, connect each **White centre/wiper conductor** to
the terminal carrying both the GPIO number and matching DevKit silkscreen label:

| Control | ESP32 GPIO | Printed board label |
|---|---|---|
| Volume  | GPIO32 | **D32** |
| Bass | GPIO33 | **D33** |
| Treble  | GPIO34 | **D34** |
| Balance | GPIO35 | **D35** |

Termination (confirmed): ends soldered directly to the lugs, insulated with
heat-shrink, mechanically strain-relieved, and terminated through a removable
connector at the controller end.

Bench verification completed 2026-08-24 with each control connected to its
named ADC1 channel. All readings increased clockwise and the on-target
`test_pots` suite passed all six test cases.

| Control | GPIO | Board label | Anticlockwise | Approx. centre | Clockwise |
|---|---|---|---|---|---|
| Volume  | 32 | D32 | 0 | 2047 | 4095 |
| Bass | 33 | D33 | 0 | 2047 | 4095 |
| Treble  | 34 | D34 | 0 | 2047 | 4095 |
| Balance | 35 | D35 | 0 | 2047 | 4095 |

The controls have no centre detent, so the centre readings vary slightly with
manual positioning. The observed endpoints match the firmware's default
0–4095 calibration; no per-pot endpoint override or inversion is required.

In Phase 2, the **Volume** position is translated by the ESP32 into WiiM output
volume. The Fosi ZA3's own level control is set during commissioning as a fixed
hardware ceiling and is not the normal user-volume control.

## H2 — Original On/Off Switch

The original Decca on/off switch is retained, including its **original solder
joints and original cable**. It is a simple open/close switch.

- Active conductors (confirmed): **Red** and **Green**.
- Interface (physically verified): **Red → ESP32 GPIO14 / board label D14** input
  with **internal pull-up enabled**; **Green → GND**.
- This is a **low-voltage logic input only**. It does **not** switch 230 V mains.
- Confirmed logic: closed/active-low = ON; open = STANDBY. Both directions were
  physically accepted on the former D19 route on 2026-08-30 and on D14 with
  v0.27.3 on 2026-09-08.
- The switch is a **system-state command**. ON makes the ESP32 restore the WiiM
  source/volume, illuminate the dial and enable the OLED. OFF stops WiiM playback,
  reverses the local actions and allows WiiM automatic standby to remove its
  direct trigger output to the ZA3.

## H3 — Radio/Source Button Bank

The original PCB and interlocked selector mechanism are retained mechanically
(ADR-0001). Repeated soldering and contact tests showed that multi-button
electrical reuse is not reliable. ADR-0016 retains the VHF behaviour established
by ADR-0013 while superseding its GPIO routing.

Only the physically accepted **VHF-derived two-Black-wire dry-contact pair** is
connected:

| VHF-derived pair | ESP32 termination | Status |
|---|---|---|
| Black conductor | GPIO26 / board label D26 | **Physically verified 2026-09-08** |
| Black conductor | GND | Existing dry-contact return; physically verified |

The two Black conductors may be swapped because this is an isolated dry contact.
GPIO26 uses the ESP32 internal pull-up and 25 ms software debounce. Do not connect
either conductor to 3.3 V or 5 V.

Authoritative source logic:

| Debounced VHF state | Logical source | Phase 2 WiiM action |
|---|---|---|
| Closed / latched | Digital Streamer | Restore phone-controlled digital playback |
| Open / released | Vinyl | Select Line-In |

Pressing SW, MW, LW or Gram releases VHF through the retained interlock. Those
positions have no individual ESP32 input; the open VHF state authoritatively
selects Vinyl. Their former conductors are disconnected and individually
insulated at the controller end. GPIO13, GPIO16, GPIO17, GPIO19 and GPIO23 are not
assigned.

A purpose-built replacement button panel is a deferred fallback if the two-state
scheme later proves insufficient. No LW solder repair is required for the
current design.

## Stereo/Mono Control

**GPIO25 / D25** is the active-low digital input with the ESP32
internal pull-up. Wire the isolated contact only:

| Stereo/Mono contact | ESP32 termination |
|---|---|
| Contact that closes in Mono | GPIO25 / board label D25 |
| Common / return | GND |

Do not connect either contact to 3.3 V or 5 V. Open/HIGH means **Stereo** and
requests dial lights on; closed/LOW means **Mono** and requests them off. The
switch behaviour was accepted on the previous GPIO17/TX2 route on 2026-08-30.
The GPIO25 firmware input and requested lighting logic are correct, but the
retained switch does not currently close in Mono; repair is open as HW-SW-01.
GPIO18 and the lamp load are commissioned separately. See ADR-0016.

## H4 — OLED Display

Purchased panel: Pi Hut SKU 105630, 1.3-inch white 128×64 **SH1106 I²C** OLED
with a pre-soldered four-pin header. Expected address: **0x3C**.

- VCC → 3.3 V (Red)
- GND → GND (Brown)
- SDA → GPIO21 / board label **D21** (Yellow, bench-verified)
- SCL → GPIO22 / board label **D22** (Orange, bench-verified)

The H4 Orange and Yellow signal colours are a documented exception to the
general loom colour standard. Orange is the SCL signal and Yellow is the SDA
signal; neither conductor is a power rail.

Check the labels printed on the delivered module before applying power because
four-pin OLED modules do not all use the same physical pin order.

Bench verification completed 2026-08-25. The panel responded as an SH1106 at
0x3C on GPIO21/GPIO22, all ten on-target `test_display` cases passed, and visual
inspection confirmed the startup and revised dashboard were upright, complete,
unclipped and free of persistent display artefacts. Final loom orientation was
physically confirmed on 2026-08-30: Brown = GND, Red = VCC, Orange = SCL and
Yellow = SDA.

## H5 — Dial Illumination

- Purchased lamp set: **ShuoHui E10 miniature screw LEDs**, ASIN
  **B0CFTLZFGT**, pack of 10; **6 V AC/DC, 0.2 W, 3000 K**. Three are required.
- The three-lamp bank is electrically accepted from the locked 5 V rail.
  Final holder fit, operating brightness and measured total current remain
  installation/commissioning checks.
- Wire the three validated lamps **in parallel**.
- Installed final switch: one **DFRobot Gravity MOSFET Power Controller,
  DFR0457**. Its 3.3 V control input is driven by ESP32 **GPIO18 / board label
  D18** and firmware PWM is set to its 1 kHz DC switching limit.
- Steady-light testing reports no flicker. The earlier v0.27.1 fade observations
  are superseded: installed LEDs held brightness and then switched only after the
  delay. Deployed v0.27.4 removes the fade engine and writes on/off duties
  immediately. Repeat the immediate transition, pot-stability, temperature and
  lamp-current checks before closing HW-LGT-01.
- The previously tested DAOKAI pack is retained as test stock but is superseded
  for the final installation.
- ESP32 and lighting grounds are **common**.
- Normal brightness is owner-approved at **85% / duty 217**, stored in
  non-volatile settings and treated as a setup value rather than a normal user
  control. Mono and logical standby command zero. The unused
  aerial control may be used temporarily for commissioning if convenient, but is
  not reserved permanently for lighting.

Expected behaviours: immediate Stereo/Mono and logical power response,
stored/configurable brightness and safe boot state. Firmware
support is implemented. GPIO18, the MOSFET stage and the
three-lamp electrical load passed the dial-lighting bench procedure on
2026-08-31. Subsequent 70%, 80% and 100% comparisons established the approved
normal level is now 85%; Mono and standby are off. Final DFR0457 integration and
installed-holder checks remain open.

## H6 — Fosi ZA3 12 V Trigger

- The **Fosi Audio ZA3** is the locked stereo power amplifier.
- H6 connects the WiiM Pro **12 V trigger output** directly to the ZA3 trigger
  input using the correct 2.5 mm-to-3.5 mm lead/adaptor (ADR-0018).
- The ESP32 must **not** connect to, source or sense the trigger voltage.
- WiiM awake/activity asserts the trigger and enables the ZA3; WiiM automatic
  standby removes it. Physical acceptance on 2026-09-19 passed with a 30-second
  WiiM standby timer. Firmware commit `36d84d1` creates safe wake activity with
  a one-step downward volume pulse and immediately restores the requested value.
- No ESP32-controlled 230 V mains relay is required for the amplifier.

## Power Distribution

The approved low-voltage controller path is:

`external Phihong adapter -> soldered low-voltage connection -> reused inline 2 A fuse on +5 V -> +5 V / GND distribution -> ESP32 and H5 lighting`

- Locked controller architecture: **one regulated 5 V control rail**, with 3.3 V
  derived by the ESP32 board regulator for logic/ADC and the OLED as documented.
- Selected/acquired supply: **Phihong PSA15R-050P**, **5.0 V DC at 3.0 A
  (15 W)**.
- The adapter's enclosed mains side remains intact. Its isolated low-voltage
  output lead is soldered directly into the Decca low-voltage wiring; the
  purchased TopHomer panel DC sockets are obsolete and must not be fitted for
  this route.
- The original Decca inline fuse holder is implemented in the +5 V conductor
  immediately after that soldered connection and before distribution. One 2 A
  fuse is fitted and one is retained as a spare; recheck the rating against
  measured total lamp current during commissioning.
- Use two **WAGO 221-415 five-way lever connectors** from Pi Hut pack SKU
  **104130**: one as the +5 V star point and one as the common-GND star point.
  Retain the third connector in the pack as a spare.
- The +5 V distribution branches to the ESP32 **5V/VIN** terminal and the positive
  side of all three E10 lamps. Never connect this rail to the ESP32 **3V3**
  terminal.
- The GND distribution branches to ESP32 GND and the lighting MOSFET source/GND.
  The lamp negatives return through the MOSFET switched output; they must never
  be driven directly from GPIO18.
- Use 22–24 AWG stranded Orange wire for +5 V and Brown wire for GND, with
  correctly sized ferrules at screw and lever terminals.
- **No dedicated 6 V/6.3 V lighting rail** is required or planned.
- The WiiM Pro remains continuously powered and uses its own automatic standby.
- The Fosi ZA3 PSU may remain energised; the amplifier state is controlled by the
  direct WiiM-to-ZA3 H6 trigger connection.
- The single-mains-lead cabinet arrangement is an active implementation using an
  acquired IEC C14 inlet, an ordered UK C13 lead and an ordered enclosed
  Masterplug four-gang distribution block. The Rev B mounting plate is the only
  active plate design; it is CAD-passed but physical-fit pending. Do not use the
  rejected Rev A plate, and do not energise mains until inlet fit, fixing
  alignment, flat clamping, enclosure retention, earthing, terminal insulation
  and rear wire clearance have been verified.
- The ESP32 remains powered when the Decca front-panel switch is OFF so it can
  detect the next state change.
- The ESP32 carries **control and UI only**. It does **not** process or carry
  audio.

## Diagrams

Point-to-point harness diagrams are held in `hardware/Wiring/`.

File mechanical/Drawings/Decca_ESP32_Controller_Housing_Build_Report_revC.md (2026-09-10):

# Decca ESP32 Controller Housing — Rev C build report

> **Status: PROTOTYPE — PRINTED AND FITTED, NOT PRODUCTION APPROVED.**
> **PROTOTYPE PRINTED, FITTED AND INSTALLED — 2026-09-07.** See §10.
> Rev C is the first housing revision with measured hardware in it and the
> first ever to be printed. It fitted first time. It is **not production
> approved**: v1.7 §14 acceptance is outstanding, seven prototype gates and
> two installation gates remain open, and several §3 values it was built
> on are still starting values rather than measurements.

**Controlling document:** `Decca_ESP32_Controller_Housing_Spec_v1.0.md` — whose
content is specification revision **v1.7**. The filename is retained for link
stability.
**Generator:** `../CAD/Decca_ESP32_Controller_Housing_fusion.py`
**Independent verifier:** `../CAD/Decca_ESP32_Controller_Housing_verify.py`
**Slicer harness:** `../CAD/Decca_ESP32_Controller_Housing_slice.py`
**Date:** 2026-09-06 · **Material:** PETG / PETG-HF · **Method:** FDM, 0.40 mm
nozzle, 0.20 mm layers, **no support material on any part**

**Rev A and Rev B are both superseded. Their build report, exports and renders
are design history only and must not be printed.**

---

## 1. Why Rev C exists

Rev A was rejected for bulk: 105.00 × 77.00 × 38.30 mm and about 68 cm³ to hold
a board 66 × 63 mm, with all eighteen of its gates passing.

Rev B was rejected for something worse. It passed thirty gates and **could not
be wired**. It routed grouped harnesses over the tops of the terminal blocks,
because nobody had established how the acquired DORHEA adapter actually
connects. It connects from the **sides**: fifteen green screw terminals per long
side, screws operated from above, external conductors entering **horizontally**
through outward-facing ports. The two black vertical sockets carry the ESP32 and
are not wiring points at all.

Twice now a revision has satisfied every check it was given and still been the
wrong design, because the checks were written against the wrong picture. Rev C
starts from measured hardware.

## 2. What is measured, and what is not

The first housing revision with any measured hardware in it.

| Dimension | Value | Source |
|---|---:|---|
| Complete adapter + fitted ESP32, overall height | **20.00 mm** | owner, 2026-09-05 |
| Adapter PCB outline | **63 mm along the rows × 66 mm across them** | owner, 2026-09-06, axis corrected same day |
| Terminal blocks, outer face to outer face | **55.00 mm** | owner, 2026-09-06 |
| Terminal-block row length | **53.00 mm** | owner, 2026-09-06 |
| Terminal-block height | **9.00 mm** | owner, 2026-09-06 |
| Mounting-hole centre pitch | **60 mm across × 57 mm along** | owner, 2026-09-06; re-measured the same day, superseding 58 × 56 |
| Corner mounting-hole size | **M3** | owner, 2026-09-06 |
| Conductor entry position | just above the block base | owner, 2026-09-06 |

**The 66 mm is measured across the board, from one connector side to the
other**, and the 63 mm runs along the rows. Rev C as first built had these two
the wrong way round; the owner corrected it the same day, and the corrected
reading is also the self-consistent one:

| | correct | the wrong way round |
|---|---:|---:|
| Clear board outboard of each block face | (66 − 55) ÷ 2 = **5.50 mm** | (63 − 55) ÷ 2 = 4.00 mm |
| Clear board beyond each row end | (63 − 53) ÷ 2 = **5.00 mm** | (66 − 53) ÷ 2 = 6.50 mm |

Two ~5 mm margins is what a real board looks like. One 4.00 and one 6.50 was the
tell, and it was there to be noticed before the correction arrived.

Rev B had all three of these wrong anyway: blocks starting *at* the edge,
10.00 mm tall, spanning 49.00 mm.

Everything else — PCB thickness, the below-board protrusion, block depth in Y,
the USB position, conductor and ferrule sizes, the heat-set insert, the cabinet
screw head — remains a **STARTING** value, tagged as such in the generator's own
`STARTING` tuple and listed in §7.

### 2.1 Three assumptions, recorded so they cannot pass as measurements

| Assumption | If it is wrong |
|---|---|
| The terminal rows are centred along the 63.00 mm along-row dimension | the 5.00 mm clear ends move; one parameter |
| The USB connector is centred on its short edge | the notch is cut 16.00 mm wide against a 14.00 mm requirement to absorb it |
| The 9.00 mm block height is the block's own body height | if it was taken from the resting surface the block top drops, and the long walls are unaffected either way, because they are set by the board top face |

### 2.2 The hole pitch, first recorded as 58 × 56, re-measured as 60 × 57

The pitch was first given as 58 across × 56 along, on the grounds that it put
all four mounting holes at an equal inset from the nearest board edge. It did
not quite: on a 66 × 63 board that pair gives 4.00 mm across and 3.50 mm along,
0.50 mm short of equal, which meant one of the four numbers had to be 1.00 mm
out. Rather than pick one, the discrepancy was recorded and the owner re-took
the reading against a dimensioned top view.

**60.00 mm across × 57.00 mm along.** It closes exactly:

| | inset from the nearest edge |
|---|---:|
| across — (66 − 60) ÷ 2 | **3.00 mm** |
| along — (63 − 57) ÷ 2 | **3.00 mm** |

Equal on both axes with nothing left over — and it is the only resolution that
corrects both numbers at once instead of adjusting one of the four by 1.00 mm.
The holes also land clear of the terminal blocks in both directions: each hole
centre sits 2.50 mm outboard of the nearest block face, since the block faces
are 5.50 mm inboard of the long edges.

**No geometry moved.** `mount_pitch_x` and `mount_pitch_y` are recorded values
only — they appear in the generator's measured block and in the verifier's
constants, and are referenced by no derivation, no body and no gate. Retention
was the fixed ledge and an adjustable clamp on the short edges. Under v1.7
§4.6 the clamp is gone and the +X end is located by two posts through these
holes — see §2.4 and §5.3.

### 2.3 The holes take M3, and the corner clearance is better than it looks

Reported by the owner on 2026-09-06. That is the **screw size, not a calliper
reading of the bore**, so `mount_hole_d` is recorded as a 3.20 mm starting value
— Ø3.00 is equally common and nothing here distinguishes them. Nothing in this
design uses it.

The orthogonal margins understate the real clearance, and it is worth writing
down why. A hole centre sits 2.00 mm beyond the row end and 2.50 mm outboard of
the block face — but it is outboard on **both** axes at once, so the nearest
block material is the block's **corner**, 3.202 mm away diagonally:

| At a corner hole | to the block corner | to the board edge |
|---|---:|---:|
| M3 socket cap, Ø5.50 | **+0.45 mm** | +0.25 mm |
| M3 pan, Ø5.60 | +0.40 mm | +0.20 mm |
| M3 countersunk, Ø6.00 | +0.20 mm | 0.00 mm |
| M3 with a DIN 125 washer, Ø7.00 | **−0.30 mm** | −0.50 mm |

So a plain M3 head fits and a washer does not. Separately — and this was not
designed in — **the four existing support pads already sit under the four
mounting holes.** Each pad spans x 23.00–31.00, y 28.75–31.75; each hole centre
is at (28.50, 30.00), inside that footprint. §2.4 is what was done about it.

### 2.4 The clearance that actually decided it — and it is not the block

The M3 reading made screw-down retention look obvious, and the terminal block
does not stop it. What stops it is the **outermost conductor**.

The last terminal in each row sits at x 24.733 and the corner hole at 28.500 —
**3.767 mm apart**. Against the declared 2.60 mm ferrule:

| At a corner hole | clear of the outermost conductor |
|---|---:|
| M3 pan head, r 2.80 | **−0.33 mm** |
| M3 socket cap, r 2.75 | **−0.28 mm** |
| M2.5 socket cap, r 2.25 | +0.22 mm |
| **Ø2.60 locating post, r 1.30** | **+1.17 mm** |

No M3 head fits, and the M2.5 margin of 0.22 mm is not a margin at all when the
wire and ferrule sizes are themselves starting values. A post does fit, with
room to spare. So **the holes are used for location, not fastening** — v1.7
§4.6a now records the prohibition and the reason, so nobody re-proposes screws
without re-deriving this number against the conductors actually installed.

## 3. The one design move that decides everything

The owner reported the entry as "just above the base of the terminal block" and
ruled the port bore and internal depth out of scope, because they do not drive
housing geometry. **That is correct, and it is better than a measurement,
because it removes the dependency instead of pinning it.**

The only thing a port height was ever needed for was *how high can the long-side
wall rise before it stands in front of a terminal mouth*. "Just above the base"
answers it: **no useful wall height exists above the board on the long sides at
all.**

So v1.7 §5.3 requires the housing to clear the **entire 9.00 mm block height,
across the full 53.00 mm row, on both long sides.** Wherever the port actually
sits inside that block, nothing this housing owns is ever in front of it. **A
later port measurement cannot invalidate the geometry**, and the cost is nil,
because a wall in that band was never available.

Everything else follows:

- the base's long walls **stop at z 6.10**, the adapter's top face, leaving
  **17.90 mm of open side** above them;
- the lid carries **no long-side skirt** — one would have to be dragged through
  the fitted conductors to get the lid off;
- **all** retention, fastening and lid support move to the two short ends, into
  the 5.00 mm of clear board the measured rows leave there.

What replaces the port measurement is a **declared routing value** this design
owns: `straight_run` = **12.00 mm** from the block's outward face before a
conductor may bend. It is parameterised, gated and reported. The conductor
envelope follows the wire and ferrule actually installed, not the terminal bore.

## 4. Envelope and material

| Metric | Rev A | Rev B | Rev C, clamped | **Rev C, v1.7** | limit | preferred |
|---|---:|---:|---:|---:|---:|---:|
| Outside length | 105.00 | 81.60 | 78.10 | **75.50 mm** | ≤85 | — |
| Outside width | 77.00 | 70.10 | 73.10 | **73.10 mm** | ≤75 | — |
| Closed height | 38.30 | 35.30 | 27.20 | **27.20 mm** | ≤36 | — |
| Housing_Base | 49.66 | 16.85 | 18.65 | **17.94 cm³** | — | ≤15 |
| Housing_Lid | 14.84 | 16.07 | 9.56 | **9.25 cm³** | — | ≤18 |
| PCB_Clamp_Adjustable | 1.58 | 1.12 | 0.99 | **deleted** | — | — |
| Cabinet_Fastener_Cap × 2 | — | 0.16 | 0.16 | **0.16 cm³** | — | — |
| **Production total** | **67.93** | **34.20** | 29.36 | **27.36 cm³** | **≤35** | **≤30** |
| **Full-solid PETG mass** | **86.3** | **43.4** | 37.3 | **34.7 g** | **≤45** | **≤38** |

**Three production parts, not four**, and comfortably inside the preferred
targets rather than scraping them: 27.36 cm³ against a 30 cm³ preference and
34.7 g against 38 g. Rev A's 68 cm³ is down by 60%.

The length came from deleting the clamp. The +X floor beyond the board was a
7.50 mm clamp zone sized by a slot, the material beyond it, wall clearance at
full travel and an insert bore. With the clamp gone it carries nothing but the
two lid-screw bosses, so it is sized by **them** and nothing else — 5.40 mm, the
7.00 mm boss less the 1.60 mm end wall it merges into.

### 4.3 The 0.50 mm that was hiding in the lid-screw boss

Found while answering a question about the heat-set insert, and **it predates
the retention change** — Rev C carried it from the day it was built.

The boss was 6.00 mm deep with its screw 3.50 mm in from the outer face. That
leaves 1.50 mm of wall outboard of a Ø4.00 insert bore and **0.50 mm inboard** —
about one extrusion width, on the boss's free face. A heat-set insert expands
the plastic radially as it is driven in, so that face is exactly where the boss
splits, and this is the least proven fastener in the design.

The screw is now **centred** in a **7.00 mm** boss: **1.50 mm of wall in every
direction**, against a new v1.7 §4.12 minimum of 1.20 mm, gated in gate 12. It
costs 1.00 mm of enclosure length — 74.50 to 75.50 mm — against 9.50 mm of
remaining headroom to the 85 mm limit. Cheap.

The width is still the tightest dimension at 73.10 mm against a 75 mm limit,
because the 66 mm runs across the board and the terminal corridors are on that
axis.

The height did it. Rev B's 35.30 mm closed height came from an unverified
24.00 mm "above PCB" assumption; the measured 20.00 mm overall, applied from the
assembly's own lowest underside feature, gives **27.20 mm** — 8.10 mm shorter,
and the lid falls from 16.07 to 9.56 cm³ because it is a flat cover instead of a
deep box.

### 4.1 Height chain, from the measured 20.00 mm

```
floor 1.60 | datum A 2.00 | PCB 4.50–6.10 | block top 15.10
          | assembly top 22.00 | cavity 24.00 | lid top 25.60
```

Datum A is the assembly's own lowest underside feature — the surface it rests on
— and the measured 20.00 mm runs from there to its highest point. **It is not
converted into an above-PCB value**, and Rev B's `assembly_above_pcb_h` does not
exist in this generator in any form.

### 4.2 Real slicer evidence

The solid-volume figure above is a conservative **design gate** and stays one. It
is not spool consumption. The set was sliced with the Bambu Studio CLI via
`../CAD/Decca_ESP32_Controller_Housing_slice.py` against a declared profile:
**Bambu Lab P1S, Generic PETG-HF, 0.40 mm nozzle, 0.20 mm layers, 3 perimeters,
15% infill, no supports, textured PEI plate**, each part in its stated
orientation.

| Part | Qty | Filament each | g total | Print time each |
|---|---:|---:|---:|---:|
| Housing_Base | 1 | 20.65 g | 20.65 | 1 h 7 m 44 s |
| Housing_Lid | 1 | 11.30 g | 11.30 | 22 m 57 s |
| Cabinet_Fastener_Cap | 2 | 0.19 g | 0.38 | 2 m 22 s |
| **Production total** | | | **32.33 g** | **1 h 35 m 25 s** |

**Support usage: none.** `enable_support = 0` and the slicer emitted **zero
support features on all three parts**, which is the operational confirmation of
the geometric claim in §6. Every slice returned `return_code 0, "Success."` with
no warnings.

## 5. Architecture as built

**Housing_Base**, printed floor-down. Ten structures, each with a stated purpose
and a numbered gate. There is nothing else on the part.

| # | Feature | Purpose | Gate |
|---|---|---|---|
| 1 | Continuous 1.60 mm insulating floor | isolates the carrier from the cabinet | 2 |
| 2 | **Low long walls, stopping at z 6.10** | the whole architecture: nothing in front of a terminal mouth | 7, 8, 22 |
| 3 | Full-height short end walls + four corner returns | carry the lid, clear of the rows by 1.00 mm | 12, 17 |
| 4 | Four support pads at (±28.50, ±30.00) | carry the board, **centred on the measured mounting holes** | 3, 13 |
| 5 | One integral fixed ledge, −X, 2.00 mm grip | retains the −X short edge | 13, 15 |
| 6 | **Two Ø2.60 locating posts, +X** | locate the carrier by its own mounting holes | 5, 13, 14, 15 |
| 7 | Two lid-screw bosses, **vertical** M3 inserts, screw **centred**, 1.50 mm wall, **2.00 mm bolt relief beneath** | lid retention at +X | 12, 17 |
| 8 | Two locating rebates, −X | lid location and capture | 17 |
| 9 | USB notch, open to the end-wall top | ≥14 × 9 service access with no bridge | 10 |
| 10 | Two recessed, capped cabinet fixings | cabinet mounting inside the footprint | 2, 16, 25, 26 |

### 5.3 Retention: one ledge, two posts, and no fastener at all

The −X short edge sits under the fixed ledge, 0.20 mm clear of the board top.
The +X end drops onto **two Ø2.60 posts through the two measured mounting
holes**. That is the whole retention system.

| | |
|---|---:|
| Post diameter in a bore reported as M3 | Ø2.60, **0.30 mm** radial clearance at 3.20 — and 0.20 at 3.00 |
| Engagement through the carrier | 1.60 mm, its full thickness |
| Proud of the carrier top | 1.40 mm |
| Clear of the outermost conductor | **1.17 mm** |
| Fitting tilt needed to clear the posts | 2.73°, lifting the ledge end **0.095 mm** inside its 0.20 mm gap |

**Only the +X pair carries a post, and that is not an economy.** The −X edge has
to slide in under the ledge at its final height, and it cannot do that with a
post already standing in a hole. The two −X holes are left empty, and the
assembly keep-out over them is left solid on purpose, so a stray feature there
still fails gate 5. The posts are bored out of that keep-out only where the
design is permitted to occupy it.

Fitting is: tilt the +X end up about 3 mm, slide the −X edge under the ledge,
lower the +X end onto the posts. Removal is the reverse — a deliberate two-part
motion, which is why the board is not going to walk off the posts on its own.

**What this deleted:** the whole `PCB_Clamp_Adjustable` part, two plinths, two
slotted M3 screws, two heat-set inserts, the clamp slot, the clamp travel, the
carrier-width range and 3.60 mm of enclosure length. Gate 15 is now a stronger
statement than it was: no fastener bears on this board anywhere, so there is
nothing left that could be over-tightened onto it.

**Housing_Lid**, printed **top-face-down**: flat 1.60 mm cover, skirts at the
**short ends and corners only**, two vertical M3 screws at +X (y ±26.00), two
locating lugs at −X, a USB notch open at the skirt's free edge, and five modest
top vents clear of the antenna keep-out.

**The lid screws are vertical.** Rev B had to use horizontal inserts because its
base wall was shallow; here the short end walls are full height, so the least
proven fastener in the whole programme is simply not needed.

### 5.1 Terminal entry, in detail

| | |
|---|---|
| Terminals | 15 per side, **3.533 mm pitch** over a measured 53.00 mm row |
| Block faces | 5.50 mm inboard of the long PCB edge, from the measured 55.00 mm across a 66.00 mm board |
| Corridor | the **whole** 9.00 mm block height, z 6.10 → 15.10, over the **whole** row, from the block face out past the enclosure |
| Long wall top | z 6.10, the board top face, leaving 17.90 mm of open side |
| Declared straight run | 12.00 mm to y 39.50; the outermost enclosure face is at 36.55, so a conductor is clear of the housing after **9.05 mm** and free for the remaining 2.95 |
| Grouping | conductors stay individual to y ±39.50; the four named bundles begin only beyond that |
| Screw access | 30 Ø6.00 mm corridors from z 15.10 upward, none obstructed, with representative wires fitted |

All **thirty** terminals are modelled with corridors and conductors, not only
the ones `docs/Wiring.md` uses, because the physical left-to-right terminal order
has not been recorded. Thirty is the superset, so the gates cannot be passed by
choosing convenient terminals.

### 5.2 Strain relief: none, and none justified

v1.7 §5.9 requires housing-mounted restraint to be shown unnecessary before it is
omitted. It is: the grouped cabinet wiring is secured immediately outside the
housing, nothing printed sits between a terminal mouth and the exterior, and
gate 22's 5 022 probes find **no printed feature of any kind** above the board
plane over either terminal row. No pull test, load test or anchor coupon is
required, and none exists.

## 6. Verification

Two independent suites. The in-CAD suite works on the BRep solids; the offline
suite reads **only** the exported STLs and re-derives every claim from triangles
against values typed in by hand. Neither imports the other's numbers.

```
30 CAD checks,  0 failed, 7 prototype open, 12 closed by the fitted prototype
29 mesh checks, 0 failed, 6 prototype, 2 installation, 12 closed by the fitted prototype
```

The two open counts differ by one because the suites classify the antenna
differently — the in-CAD suite calls it a prototype gate, the offline one an
installation gate. That is a deliberate difference, not drift: the suites are
independent, and 75 of the offline verifier's hand-typed constants were
cross-checked against the generator's derived chain with no disagreement.

Together they cover all thirty v1.7 §13 gates.

### 6.1 What verification caught, and it was a lot

Three of the six below concern the adjustable clamp, which v1.7 has since
deleted. They are kept as history: they are why the clamp cost what it cost, and
that is part of the case for replacing it.

Every item below is a design change the checks forced. None was fixed by moving
a threshold.

- **A blanket underside keep-out left nowhere for a cabinet fixing.** Gates 3
  and 5 rejected the two recessed fixings the moment they were placed. A board
  does not have solder under all of it; the model now carries the **four actual
  joint rows** — two terminal blocks, two ESP32 sockets — and the fixings sit on
  the clear centreline between them. That the centreline really is clear
  underneath is a prototype gate, not a measurement.
- **The fixed ledge needed support.** Gate 18 measured 1.75 mm of unsupported
  reach against a 1.50 mm limit. The 45° lead-in went from 0.80 to 1.40 mm;
  reach is now 1.25 mm.
- **The cabinet pad was exactly tangent to the cavity wall.** At `cab_x` 27.00
  the 13.00 mm pad touched x −33.50 on a single line. Fusion reported a valid
  solid; the exported mesh had a **non-manifold edge** there and mesh gate 1
  failed. This is the same tangency trap the Rev B chamfer hit. Moving the
  fixings to x ±26.00 designs it out rather than checking for it.
- **The lid-screw bosses reached into the clamp bar.** The two suites
  disagreed — the offline verifier's hand-typed `LID_SCREW_Y` was the intended
  26.00 while the generator still had 22.00 — and the interference was real,
  about 38 mm³. That is exactly what hand-typing the expected values is for.
  CAD gate 14 now fails on the interference as well as the grip.
- **The clamp bar hit the +X wall at full travel.** Caught twice, once at rest
  and once at the 67.00 mm carrier. The fix is not a shorter bar but a bound:
  `bar_x1` is now derived from the wall position **at full travel**, and the
  clamp zone widened from 6.00 to 7.50 mm because four constraints — slot
  length, material beyond the slot, wall clearance at travel, and the insert
  bore staying inside the plinth — cannot all be met in 6.00 mm.
- **The clamp plinths reached under the board.** Bounded to the clamp zone.
- **Five bugs in the verifier itself**, all found by running it: a slot scan
  that measured the scan window instead of the slot; a plinth probe that landed
  down the insert bore; two radial profiles marching outward when they should
  have marched inward; a screw-hole probe sitting on the tessellation seam; and
  an `overhang_report` unpacked with the wrong arity.

## 7. Prototype gates — seven still open, twelve closed by the fitted print

**The axis correction.** Rev C was first built with the 66 mm along the rows
and the 63 mm across. The owner corrected it the same day. The parametric model
absorbed it in one edit and every gate was re-run; the envelope changed from
81.10 × 70.10 to 78.10 × 73.10 mm and the volume by 0.01 cm³. It also improved
two clearances — the support pads gained 0.75 mm of margin in their strip — and
forced two consequential changes: the corner returns shortened from 6.00 to
4.00 mm to stay clear of the row ends, and the cabinet fixings moved from
x ±26.00 to ±24.00 to stay off the −X cavity wall. The clamp's adjustable range
was re-centred at that point from the legacy 65–67 mm to 62–64 mm; v1.7 has
since deleted the clamp and the range with it, because a measured board and a
measured hole pitch leave nothing for an adjustment to absorb.

**Twelve of these were closed on 2026-09-07 by the fitted prototype — see §10.**
What follows is what is left.

**Hardware still unmeasured:** PCB thickness (1.60) and the below-board
protrusion (2.50) — the fitted print shows the 4.50 mm pad height *works*, but
not what the two numbers behind it are; terminal-block
depth in Y (6.50); the heat-set insert **bore** (4.00 × 5.00 — the part is now
identified as **Hanglife M3 threaded**, owner 2026-09-06, the first time this
fastener has had a name anywhere in this repository, but its length and outer
diameter are still unmeasured and those are what the bore has to match); the
acquired cabinet screw's head against the declared
6.20 mm maximum envelope; the USB connector position; real conductor and ferrule
sizes; EN and BOOT positions, so no holes are cut; and the mounting holes'
exact bore, recorded at 3.20 from the reported M3 and used by nothing.

**Behaviour nothing geometric can settle:** that nothing sits under the board
outside the four modelled joint rows; the 0.25 mm lid fit on this printer and
filament; the 0.12 mm cap nib interference; PETG print quality with no support;
antenna performance with the lid fitted.

**Plus the one assumption left in §2.1** — the USB connector centred on its
short edge. The other two were closed by the fitted print (§10.1).

**Installation gates:** cabinet fixing centres and the surface behind them; that
the grouped cabinet wiring is secured outside the housing; antenna performance.

## 8. Printing

| Part | Orientation | Filament | Time |
|---|---|---:|---:|
| Housing_Base | **floor down** | 20.65 g | 1 h 7 m 44 s |
| Housing_Lid | **top face down** — makes the USB notch and vents print with no bridge | 11.30 g | 22 m 57 s |
| Cabinet_Fastener_Cap | flat, **2 off** | 0.19 g ea | 2 m 22 s ea |

No supports on any part. Worst unsupported reach 1.25 mm (CAD) / 0.75 mm (mesh)
against a self-declared 1.50 mm limit.

**It has been printed** — see §10 — and it is still **not production approved**.
v1.7 §14.0 makes a prototype print of a part this small a legitimate
instrument rather than something that has to wait for callipers, and §10
records gate by gate what the fitted print established and what it did not.

## 9. Files

**Current:** `../CAD/Decca_ESP32_Controller_Housing.f3d`, the assembly STEP,
three part STEPs, three print-ready STLs, this report, and twenty-one
`..._revC_*.png` renders — including `..._14b_locating_posts.png`, the two posts
standing in the two +X mounting holes with the two −X holes left empty.

**Removed as superseded:** `ESP32_Controller_PCB_Clamp_Adjustable.step` and
`.stl`, all Rev B STLs and STEPs for the two prototype coupons, and all
twenty-three `..._revB_*.png` renders. The generator deletes
them on every run, and both verifiers fail if a forbidden mesh reappears. The
Rev A and Rev B build reports are retained as history with superseded banners.

## 10. First physical validation — 2026-09-07

The owner printed this geometry, fitted the adapter, closed the lid and
installed the housing in the Decca. **It fitted first time.** No revision of
this housing had ever been printed before; Rev A and Rev B never got near a
printer.

The print was made ahead of the §3 starting values behind it being measured.
That is now explicitly allowed — v1.7 §14.0, added the same day — because on a
20 g part that prints in about an hour, the print is the faster and better
instrument: callipers on a populated board give the nominal, a fitted print
answers whether it seats.

### 10.1 What the fit closes

Eight gates, listed in both suites under **CLOSED BY PHYSICAL EVIDENCE** with
the observer and date on each:

| Closed | What the fit demonstrates |
|---|---|
| **The two locating posts enter the real mounting holes** | Ø2.60 posts at the measured 60 × 57 pitch went into the actual bores and the board seated. The single most novel thing in the design, and nobody had tried it. It also **confirms the re-measured pitch over the 58 × 56 first reported** — 58 × 56 would not have accepted these posts. |
| **The carrier fits** | Ledge, tilt-and-drop, posts and pads all worked as a sequence. |
| **The lid closes on the assembly** | Exercises the 0.25 mm per face fit, the 4.00 mm overlap at the ends and corners, and the whole height chain from the measured 20.00 mm assembly under a 24.00 mm ceiling. **Rev B died on a height assumption**; this is the first time one has been closed by a closed lid. |
| **The enclosure installs in the Decca** | The 75.50 × 73.10 mm envelope was accepted in the actual cabinet space. |
| **Nothing under the board outside the modelled joint rows** | The board seated on its four pads and over both cabinet pads with nothing fouling. Rev B's blanket keep-out is now disproved by a fitted board, not just by a gate. |
| **The terminal rows are centred on the 63.00 mm dimension** | Was an assumption. Ledge, pads and both posts all cleared, which they could not have done otherwise. |
| **The 9.00 mm block height is the block's own body height** | Was an assumption. The lid closed over the assembly, which is the consequence that was at risk. |
| **PETG prints this geometry with no support material** | On the owner's printer and filament. The slicer harness had independently emitted zero support features on all three parts. |

### 10.2 What it does not close, and the distinction matters

A board that seats proves the **4.50 mm pad height works**. It does not measure
the **PCB thickness** or the **below-board protrusion** it was derived from, and
those two still set the underside clearance. The same holds for the mounting-hole
**bore**: a Ø2.60 post demonstrably fits the real hole, but the bore is still
unmeasured and it is what decides how much play the board has.

That distinction is the whole of v1.7 §14.0 point 3, and both suites state it on
each entry rather than letting a fit against an unmeasured value pass for a fit
against a measured one.

**Seven prototype gates and two installation gates remain open**, and several
things this print will have exercised are simply **not yet reported**: whether
the heat-set inserts drove into their bosses and the lid screws pulled the lid
down; whether the terminals are wired, which would close the entry corridors,
the screwdriver access and cover-removal-while-wired in one go; whether the two
cabinet fixings and their caps were used; and surface quality and cleanup.

### 10.3 Second report, same day — four more closed, and one change demanded

The inserts drove and the lid screws pulled the lid down. **The terminals are
wired.** Both cabinet fixings and both insulating caps are fitted. The finish
was *"nice simple finish, no issues"* — no sag, no cleanup, nothing deburred.

That closes four more, taking the total to **twelve**:

| Also closed | What it settles |
|---|---|
| **The heat-set inserts drive and the lid screws pull the lid down** | Hanglife M3 inserts into the Ø4.00 bores, on the 1.50 mm walls §4.3 had just widened from 0.50 |
| **The terminals are WIRED** | The entry corridors, top screwdriver access, the ferrule envelope and cover-removal-with-wiring-connected — **the gates this whole revision exists for**, since Rev B could not be wired at all |
| **Cabinet fixings and caps** | Both screws recessed inside the declared 6.20 mm head envelope; both caps held on their 0.12 mm nib interference. This also closes the installation gate for the fixing centres |
| **Surface finish** | Reported clean, which is the operational confirmation of the zero-support claim |

### 10.4 The one change the fit demanded

Tightening the real bolts showed what no geometric gate had: past the insert,
**the bolt has nowhere to go**. It tightens against solid plastic before it
pulls the cover down.

**v1.7 §4.13 now requires 2.00 mm of relief beneath each insert**, narrower than
the insert bore so the insert stays supported along its whole length. It is
built, and it is gated on both sides — CAD gate 12 checks the derivation, and
mesh gate 17 measures the relief floor off the exported triangles at
**z 17.00 / 17.00** against 17.00.

**This is the first change on this design to come from a fitted prototype rather
than from a gate**, which is the case for §14.0 made in a single edit: thirty
geometric gates could not have found it, and one hour of printing did.

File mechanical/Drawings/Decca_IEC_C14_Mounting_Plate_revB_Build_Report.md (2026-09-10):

# Decca IEC C14 Mounting Plate Rev B — CAD Build Report

**Status:** CAD PASS / profile geometry owner-confirmed / printed fit pending  
**Supersedes:** Rev A, rejected for incorrect rectangular inlet opening  
**Build date:** 2026-09-06

## 1. Correction made

Rev A used the 27.14 × 19.50 mm measured inlet envelope only to create a rectangular clearance opening. Physical review showed that this did not properly enclose the actual C14 profile.

Rev B promotes the owner-supplied **16.00 mm** and **14.00 mm** readings to governing profile datums and reconstructs the actual six-sided form.

Native profile:

- long flat / overall width **27.14 mm**;
- overall height **19.50 mm**;
- short flat **16.00 mm**;
- straight side **14.00 mm**;
- long-flat corners **R2.00**;
- other four corners **R0.40**.

Derived angled section per side:

- run **5.57 mm**;
- rise **5.50 mm**;
- diagonal length **7.828 mm**;
- native angle **44.638°**.

The production opening is the measured profile offset outward by **0.25 mm normal clearance**, then rotated 90° into the existing plate layout. Cut-out radii therefore become **R2.25** and **R0.65**.

## 2. Unchanged interfaces

- plate **40.00 × 50.00 × 3.00 mm**, R2 corners;
- four Decca holes Ø2.40 at `(±15.50, ±8.50)`, exact 31.00 × 17.00 grid;
- two C14 fixing holes Ø3.40 at `(0, ±19.50)`, exact 39.00 pitch.

## 3. Generated files

- `mechanical/CAD/Decca_IEC_C14_Mounting_Plate_revB_cadquery.py`
- `mechanical/CAD/Decca_IEC_C14_Mounting_Plate_revB_verify.py`
- `mechanical/CAD/Decca_IEC_C14_Mounting_Plate_revB_drawing.py`
- `mechanical/CAD/Decca_IEC_C14_Mounting_Plate_revB.step`
- `mechanical/STL/Decca_IEC_C14_Mounting_Plate_revB.stl`
- `mechanical/Drawings/Decca_IEC_C14_Mounting_Plate_revB_views.png`

## 4. Clean exported-geometry validation

The committed Rev B source was rebuilt in GitHub Actions using CadQuery 2.8.0. The generated STEP and STL were then independently verified.

| Gate | Result | Evidence |
|---|---|---|
| Plate envelope | **PASS** | 40.000000 × 50.000000 × 3.000000 mm |
| One connected STEP solid | **PASS** | 1 solid |
| Correct profile topology | **PASS** | 6 straight edges + 6 circular arcs |
| Rotated profile envelope | **PASS** | 20.000000 × 27.640000 mm |
| Cut-out corner radii | **PASS** | 2 × R2.25, 4 × R0.65 |
| Angled sections | **PASS** | two equal lines; native 44.637701°, rotated 45.362299° |
| M2 pattern | **PASS** | `(±15.5, ±8.5)` |
| M3 pattern | **PASS** | `(0, ±19.5)`, 39.00 mm pitch |
| No opening/fixing intersection | **PASS** | minimum edge gap 3.980000 mm |
| Minimum ligament ≥3 mm | **PASS** | M2 min 4.300000; M3 min 3.980000 mm |
| STL envelope | **PASS** | 40 × 50 × 3 mm |
| STL manifold | **PASS** | watertight and winding-consistent |
| STL body count | **PASS** | 1 |
| Hidden fastening features | **PASS** | none |
| Support-dependent geometry | **PASS** | none; broad-face no-support print |

**Result: 15/15 Rev B CAD checks PASS.**

STEP volume: **4325.997401 mm³**  
STL volume: **4326.486776 mm³**

## 5. Clean-build checksums

- CadQuery source: `9059de6e1bbab96b47661f52f4956d324f0525bc6c3a7dd28f094467b303c1b3`
- STEP: `88490a052b2ffc9eee2647a45866b8bced727ce17cc5107601133e631fd2de1e`
- STL: `f8f2b5cd85442c2af8480e3f829a39a151d1d11ab3b5c1a89496b39c6e7720e2`

## 6. Owner profile-geometry confirmation — 2026-09-06

The owner reviewed the Rev B profile drawing and **confirmed that the six-sided outline, calculated angled sections and corner treatment match the intended IEC C14 socket geometry**.

This closes the **profile-definition/design-intent gate** that caused Rev A to fail.

It does **not** constitute full physical release because the Rev B part has not yet been printed and fitted. The remaining release gate is the actual printed-part test below.

## 7. Physical release gate

Rev B is **not released** until a printed part confirms:

1. the complete C14 profile enters without forcing and the plate visibly encloses the socket profile as intended;
2. both M3 fixings align without slotting;
3. all four Decca M2 holes align without forcing;
4. the plate clamps flat without cracking or distortion;
5. rear terminal and wire clearance is acceptable before mains energisation.

If Rev B fails, record the failed physical interface and amend the measured-profile model. Do not file, slot or drill the reference part to make a failure appear to pass.

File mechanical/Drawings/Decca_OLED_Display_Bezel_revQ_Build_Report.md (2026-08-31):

# Decca OLED Display Bezel — Rev Q Build Report

Status: **COMPLETE — signed off by the owner, 2026-08-31.** Bezel-only; the
released Rev P.5 carrier is untouched throughout.

Date: 2026-08-31
Controlled requirements: `Decca_OLED_Display_Bezel_CAD_Brief_revQ.md` at commit
`7b107f2389b2ce128c18bef2f5195ef5ab468890` ("require two-loop inset wall"),
which supersedes `ebfa277` via `edab34b` ("define Rev Q interference fit"),
plus **nine owner changes made on the model, recorded in §3.5 to §3.12**
Specification: `Decca_OLED_Display_Mount_Spec_v1.0.md` v1.2, §2 and §4
Carrier: **Rev P.5, RELEASED and FROZEN — unchanged, and proved unchanged (§9)**

> **THE PERSPEX OPENING HAS BEEN MEASURED, and it is not what this project
> believed.** For six revisions the model carried 35.20 × 15.30 from Rev C. The
> owner printed the 35.400 × 15.450 insert, used it as a gauge block and read the
> slop: **1.34 mm horizontal, 1.00 mm vertical**. The opening is therefore
> **36.74 × 16.45** — 1.54 mm wider and 1.15 mm taller than recorded. Every fit
> figure before §3.10 was computed against a number nothing had ever checked.
>
> The insert is now **derived from that measurement**, not entered: `insert
> outer = measured opening + declared interference`. Re-measuring is a
> two-number edit. The owner reports the reading as hard to take and expects a
> further iteration; treat it as ±0.2 mm.
>
> **The first Rev Q print is an integration prototype, not a release part.**
> Three things it must settle and CAD cannot: whether the 0.100 / 0.075 mm per
> side interference seats without stressing the Perspex; whether the production
> slicer lays **at least two continuous 0.40 mm loops** all the way round; and
> whether the re-measured opening is right. Nothing in this report is a claim
> about appearance.
>
> ## Signed off
>
> **The bezel is signed off as complete by the owner, 2026-08-31.**
>
> Confirmed on printed parts and offer-ups: the **interference fit**, the
> **opening corner** (R4.25 a good match), and the **opening dimensions**
> themselves (36.74 × 16.45, gauge-block method, §3.10). A 2.30 mm insert depth
> was tried and **reverted** when the bottoming-out that prompted it was traced
> to a printing issue rather than the geometry — the depth is back at the proven
> Rev N 2.80 mm (§3.12).
>
> **Not separately reported at sign-off:** the slicer two-loop preview (§10
> Stage 0b) and the powered visibility test (§10 Stage 4). Parts printed and
> fitted, so the wall evidently laid, but neither check was run as such. They are
> recorded here as not-run rather than passed.
>
> **One figure to carry forward:** the bezel passes within **0.339 mm** of the
> frozen Rev P.5 carrier. Zero interference, and it has now been assembled, but
> two FDM parts at ±0.1 mm each make that a real number — worth knowing if either
> part is ever reprinted on a different machine or profile. §6.1.

---

## 1. What Rev Q changes---

## 1. What Rev Q changes---

## 1. What Rev Q changes

The Rev N pair of side locating rails is deleted and replaced by a single
continuous rearward inset wall around the **complete** inside perimeter of the
Perspex opening — left, right, top, bottom and all four corners.

```text
front
BEZEL FACE
──────────────  seats against the Perspex front face,  z = +3.000
       │
       │  continuous inset wall, 2.80 mm rearwards,
       │  1.25 mm at the sides / 0.80 mm top and bottom
PERSPEX│
───────┘        wall rear tip,                         z = +0.200
rear
```

The wall is a **masking and locating skirt**. It is not a snap, not a clamp
and not a structural feature, and it carries no load. It runs on an
**interference on both axes** — 0.100 mm per horizontal side and 0.075 mm per
vertical side against the measured opening (§3.10) — with the thinner top and
bottom wall deliberately taking the smaller figure. The two Rev N recessed
adhesive pads are DELETED at owner instruction (§3.5), so retention is by the
fit alone; if adhesive is still wanted it goes on the flat seating face, and
**PETG creep means a press fit will slacken over months** — plan on adhesive if
the bezel must not drop out.

### 1.1 What the amendments and the owner changes did

| | first issue (`ebfa277`) | brief amendment (`7b107f2`) | **as built now** |
|---|---:|---:|---:|
| **Perspex opening (measured)** | 35.20 × 15.30 | 35.20 × 15.30 | **36.74 × 16.45** |
| Bezel face opening | 30.40 × 14.90 | 30.90 × 15.35 | **34.44 × 15.00** |
| Inset-wall outer envelope | 34.90 × 15.00 | 35.40 × 15.20 | **36.94 × 16.60** |
| Horizontal fit | 0.15 clearance/side | 0.10 INTERFERENCE/side | **0.100 INTERFERENCE/side** |
| Vertical fit | 0.15 clearance/side | 0.05 clearance/side | **0.075 INTERFERENCE/side** |
| Wall | 0.40 (one loop) | 0.80 (two loops) | **1.25 sides / 0.80 top+bottom** |
| Outer corner radius | R0.60, UNRESOLVED | R2.00 | **R4.25** |
| Inner corner radius | R0.20 | R1.20 | **R3.00** (derived from the side wall) |
| Recessed adhesive pads | two, preserved | two, preserved | **deleted** (owner) |
| Wall inner envelope | 34.10 × 14.20 | 33.80 × 13.60 | **34.44 × 15.00** |
| Aperture | straight | tapered in Y | **straight bore, flush all four sides** |
| Effective optical opening | 30.40 × 14.20 | 30.90 × 13.60 | **34.44 × 15.00** |
| Visible lit band | 8.100 (Rev N) | 7.450 | **8.150** |
| Insert depth | 2.80 | 2.80 | **2.80** — 2.30 tried and reverted, §3.11–§3.12 |

Two things settled themselves at §3.10, both from one printed part. The
**opening** is measured for the first time. The **corner** went to R4.25, back
to R3.00 on appearance, and back to R4.25 again when the owner offered the
printed part into the opening and found the corner "a good match" — the first
physical information about it anywhere in this project.

For the first time the clear opening is **larger than Rev N in both axes**, and
the visible lit band is **above** Rev N's rather than below it. The open risks
now, in order: whether the **re-measured opening** is right, whether the
interference seats without stressing the Perspex, and the **slicer**.

---

## 2. Verified facts

### 2.1 Recovered from the released Rev N bezel — read-only evidence

`Front_Bezel_revN.step` was parsed as a BREP and every figure below was
measured out of it. The file was **not** opened for edit, not regenerated and
not re-exported.

| Recovered feature | Value | How |
|---|---|---|
| Overall envelope | 40.000 × 20.300 × 4.000 mm | vertex bounding box |
| X / Y extents | ±20.000 / ±10.150 mm | vertex bounding box |
| Z levels present | +0.200, +3.000, +3.300, +3.800, +4.200 | vertex Z census |
| External corner radius | **R2.000** at (±18.000, ±8.150) | cylindrical surfaces |
| Front edge break | **R0.400**, torus major 1.600 at the corners | toroidal surfaces |
| Visible window | 30.400 × 14.900, **R0.800** at (±14.400, ±6.650) | planes + cylinders |
| Window edge break | **R0.400**, torus major 1.200 | toroidal surfaces |
| Adhesive pads | x ±12.000, y 7.850…9.850 and −9.850…−7.850 | planes |
| Adhesive pad depth | 0.300 (floor at z = +3.300) | plane at z = 3.300 |
| **Locating rails — TWO ONLY** | x 15.300…17.450 and mirror, **y −4.000…+4.000** | R0.600 cylinders |
| Rail depth | z +0.200 … +3.000 = **2.800 mm** | plane pair |

Cross-checked against the Rev P build review §16, which independently states
40.00 × 20.30 × 4.00, a 2.80 mm lip depth, rearmost material at z = +0.200 and
0.500 mm clearance to the OLED glass. Both sources agree exactly.

> Note on the brief's `bezel_window_h` derivation. Brief §4 annotates
> 15.35 mm as "Rev N 15.10 + 0.25". 15.10 is the **v1.0 design-intent**
> figure from Spec §4; the **as-built** Rev N window measures **14.900 mm**
> in the released STEP. The 15.35 mm target itself is taken as authoritative
> and is built exactly; only the annotation's starting point is superseded.
> The width annotation ("Rev N 30.40 + 0.50") matches the as-built part.

### 2.2 The Z-chain — unchanged from Rev N and Rev P.5

```text
z = +4.200   bezel front face
z = +3.000   Perspex FRONT face  == bezel seating plane
z =  0.000   Perspex REAR face   == DATUM A, carrier hard stop
z = -0.300   OLED glass front face
             wall rear tip at z = +0.200
             -> 0.200 mm clear of the Perspex rear face
             -> 0.500 mm clear of the OLED glass  (the RELEASED value)
```

### 2.3 What the Rev N rails proved, and what they did not

* **PROVED:** the 2.80 mm engagement depth. It was briefly cut to 2.30 (§3.11)
  and reverted when the bottoming-out proved to be a print issue (§3.12), so it
  has now survived a physical offer-up on Rev Q as well. Also that a
  34.90 mm outer envelope
  clears the opening in X.
* **NOT PROVED — anything in Y.** The rails span only y −4.000…+4.000. No Rev N
  surface has ever touched the top or bottom of the Perspex opening.
* **NOT PROVED — anything at any corner.** Rev G's note that the rail design
  "tolerates opening corner radii to R3.65" is the giveaway: that architecture
  was chosen *precisely so the unknown corner form would not matter*. Rev Q is
  the first bezel geometry that has to go into those corners.

### 2.4 Measured fascia geometry — Spec v1.2 §2

| Parameter | Value | Source |
|---|---:|---|
| Display opening | **36.74 × 16.45 mm** | **measured 2026-08-31** (was 35.20 × 15.30, Rev C, never corroborated — §3.10) |
| Perspex thickness | **3.00 mm** | measured |
| Opening corner radius | **NOT RECORDED** | — see §8 |

The released Rev P generator models the opening as a **sharp-cornered box**.
Rev Q's reference panel does the same, so the two representations stay
identical. That is a modelling convention, not a measurement, and this report
never treats it as one.

---

## 3. Named parameters

Created before any dependent geometry and mirrored into Fusion user parameters,
the derived ones as real formulas so the derivation is visible in the UI.
Source of truth is the `P` dict in
`../CAD/Decca_Display_Bezel_revQ_fusion.py`.

### 3.1 Controlling parameters

| Parameter | Value | Class | Note |
|---|---:|---|---|
| `panel_open_w` | **36.74 mm** | **MEASURED** | 2026-08-31, gauge-block method — **drives the whole insert**, §3.10 |
| `panel_open_h` | **16.45 mm** | **MEASURED** | 2026-08-31, gauge-block method — **drives the whole insert**, §3.10 |
| `bezel_lip_interf_x` | **0.100 mm** | **SPEC** | per side, INTERFERENCE — entered, not derived |
| `bezel_lip_interf_y` | **0.075 mm** | **SPEC** | per side, INTERFERENCE — the thinner wall takes less |
| `panel_t` | 3.00 mm | MEASURED | |
| `panel_open_corner_r` | 0.00 mm | **UNRESOLVED** | modelled sharp, as the released Rev P reference. Not a measurement. |
| `bezel_w` / `bezel_h` | 40.00 / 20.30 mm | PRESERVED | Rev N |
| `bezel_face_t` | **1.20 mm** | **PRESERVED** | Rev N — how far the bezel stands proud of the Perspex; **entered**, so the total follows the insert (§3.11) |
| `bezel_t` | **4.00 mm** | **DERIVED** | `bezel_face_t + bezel_lip_depth` |
| `bezel_outer_r` | 2.00 mm | PRESERVED | Rev N external corner |
| `bezel_edge_break` | 0.40 mm | PRESERVED | front face break |
| `bezel_window_w` | **34.44 mm** | **DERIVED** | = skirt inner width, i.e. flush — §3.10 |
| `bezel_window_h` | **15.00 mm** | **DERIVED** | = skirt inner height, i.e. flush — §3.10 |
| `bezel_window_r` | **3.00 mm** | **DERIVED** | = skirt inner corner, i.e. flush — §3.10 |
| `pads_enabled` | **False** | **OWNER** | the two recessed adhesive pads are DELETED — §3.5 |
| `pad_*` | 12.00 / 7.85 / 9.85 / 0.30 mm | retained | Rev N values, kept only so the pads can be restored |
| **`bezel_lip_outer_w`** | **36.94 mm** | **DERIVED** | `panel_open_w + 2 × interf_x` — §3.10 |
| **`bezel_lip_outer_h`** | **16.60 mm** | **DERIVED** | `panel_open_h + 2 × interf_y` — §3.10 |
| **`bezel_lip_depth`** | **2.80 mm** | PROVEN | Rev N rail depth; 2.30 tried and reverted — the cause was a print issue, §3.12 |
| **`bezel_lip_wall_y`** | **0.80 mm** | **OWNER** | top/bottom, 2 loops — unchanged since the brief amendment |
| **`bezel_lip_wall_x`** | **1.25 mm** | **OWNER** | sides, 3.125 loops — now entered, the clear width derives from it (§3.10) |
| **`bezel_lip_corner_r`** | **4.25 mm** | **OWNER** | R2.00 (brief) → R3.00 (§3.5) → R3.40 (§3.7) → R4.25 (§3.8) → R3.00 (§3.9) → **R4.25 restored on physical evidence** (§3.10) |
| **`bezel_lip_lead`** | **0.20 mm** | PROVISIONAL | minimum entry lead-in |
| **`extrusion_width`** | **0.40 mm** | PRODUCTION | every wall is at least two of these |
| `ap_root_relief` | **0.00 mm** | MODELLING | anti-tangency — no longer needed, §3.4 |

### 3.2 Derived — never entered twice

| Parameter | Formula | Value |
|---|---|---:|
| `bezel_lip_interf_x` | `(bezel_lip_outer_w − panel_open_w) / 2` | **+0.100 mm** (interference) |
| **`bezel_lip_outer_w`** | `panel_open_w + 2 × bezel_lip_interf_x` | **36.940 mm** |
| **`bezel_lip_outer_h`** | `panel_open_h + 2 × bezel_lip_interf_y` | **16.600 mm** |
| `bezel_lip_clear_y` | `−bezel_lip_interf_y` | **−0.075 mm** — negative, because it is an interference |
| `bezel_lip_inner_w` | `bezel_lip_outer_w − 2 × bezel_lip_wall_x` | **34.440 mm** = the face opening, i.e. flush |
| `bezel_lip_inner_h` | `bezel_lip_outer_h − 2 × bezel_lip_wall_y` | **15.000 mm** = the face opening, i.e. flush |
| `bezel_lip_inner_r` | `bezel_lip_corner_r − bezel_lip_wall_x` | **3.000 mm** = the face opening corner, i.e. flush |
| `bezel_window_w` / `_h` / `_r` | the three skirt inner values above | **34.440 / 15.000 / 3.000** |
| `wall_loops_x` / `wall_loops_y` | `wall / extrusion_width` | **3.125** / **2.000** |
| `aperture_rear_h` | `bezel_lip_inner_h` | 15.000 mm |
| `bezel_face_t` | `bezel_t − bezel_lip_depth` | 1.200 mm |
| **`bezel_t`** | `bezel_face_t + bezel_lip_depth` | **4.000 mm** |
| `z_lip_rear` | `z_panel_front − bezel_lip_depth` | **+0.200 mm** |

Three constraints are enforced in code and refuse to build if violated:

* every wall must be **at least two** `extrusion_width`s. It is a minimum,
  applied per side, and the sides and the top/bottom are free to carry
  different numbers — the owner's clarification, §3.6. Below two the slicer
  cannot resolve the wall as complete loops and substitutes gap fill or a
  variable-width wall, which is what the brief amendment exists to stop;
* `bezel_lip_corner_r ≥ bezel_lip_wall_x`, since the inner corner radius is
  `corner_r − wall_x` and cannot go negative;
* `bezel_window_h` and `bezel_window_r` must **equal** the derived skirt inner
  height and corner radius. That is what keeps the aperture flush on all four
  sides (§3.7); if a driver is changed so they drift apart, the generator
  refuses to build rather than quietly producing a set-back or a ledge;
* no export path may write a file whose name contains `revN`, `revO` or `revP`.

### 3.3 The aperture no longer tapers — and why it used to

**Kept because the reasoning still governs the constraint the generator
enforces**, even though the feature it produced has now been designed out.

The brief's amended face opening was **15.35 mm** high while the entire inset
wall was only **15.20 mm** high, so the face opening was 0.075 mm taller *per
side than the outside of the wall*, and at the top and bottom the wall footprint
fell entirely inside it. A straight-walled face opening would have left the top
and bottom runs of the wall **detached from the bezel face** — roughly 31 mm of
free-standing cantilever floating in the aperture, unprintable and not one sound
solid. The fix was to taper the aperture in Y, from the wall inner opening at
the seating plane out to the face opening at the front face, at 36.10° — inside
the 45° self-supporting threshold.

**The owner's fourth change removed the condition entirely.** The face opening
is now flush with the skirt inner envelope on all four sides (§3.7), so:

| | value |
|---|---:|
| Aperture at the seating plane (z = +3.000) | 34.440 × 15.000, R3.000 |
| Aperture at the front face (z = +4.200) | 34.440 × 15.000, R3.000 |
| Taper angle from vertical | **0.00° — a straight bore** |
| Wall root landing on solid face material | the full 0.800 mm |

The generator still derives the taper rather than assuming zero, and the
validator still measures it, so re-opening the face beyond the skirt would
bring the taper back automatically instead of producing a detached wall. What
is *not* automatic, and is now enforced, is flushness: `bezel_window_h` and
`bezel_window_r` must equal the derived skirt inner height and corner radius or
the build is refused (§3.2).

One thing was lost with the taper. Spec v1.2 §4 asks for a flared aperture "to
reduce tunnel effect through the 3 mm Perspex", and a straight bore does not
flare. It is a **declared deviation**: flush was the owner's explicit
instruction, and a flare can only be reintroduced by cutting the face opening
*larger* than the skirt, which is exactly the set-back the owner rejected.

### 3.4 Two small modelling measures, both declared

**`ap_root_relief` — introduced at 0.02 mm, now back to 0.00.** It made the
aperture stop 0.02 mm per side *outside* the wall inner opening rather than
exactly on it. Landing it exactly on
y = ±6.800 makes the tapered wall tangent to the wall's inner face along a line
at z = 3.000, and the tessellator answers that with a seam of zero-area
triangles — **52 of them in the first export, all at exactly z = 3.0000**.
Backing the aperture off cured it at the time. The **real** cause was that the
two profiles coincided along the straight runs but differed at the corners; now
that the aperture's rear section carries the skirt's own corner radius (§3.6)
the profiles match exactly, there is no mismatch left to relieve, and the
relief is back to **0.00** with no degenerate triangles (minimum triangle area
3.484 × 10⁻³ mm²).

**The window edge break is a chamfer, not a fillet.** The outer envelope keeps
the Rev N R0.40 *fillet* exactly. The window edge cannot: the tapered aperture
is a single NURBS surface whose front edge is one closed NURBS curve with a
varying dihedral — 90° down the vertical left and right walls, 53.9° where the
top and bottom lean back, sweeping between the two through the corners. Fusion
refuses a fillet there at **every radius tried (0.40, 0.30, 0.20, 0.10 — all
`ASM_BL_UNFIN_SHEET`)**, whole-loop and per-edge alike. A **0.40 × 45°
chamfer** succeeds cleanly and is what is built. At 0.40 mm on a matt black
part the two are indistinguishable by eye, and the window had already been
re-dimensioned and flared by the amendment, so its section could not have been
carried over from Rev N unchanged in any case. **This is a declared deviation
and the only one in the visible face detail.**

### 3.5 Two owner changes made on the model

Both were directed after inspecting the built model, and both are **deviations
from the controlled brief**. Both are single named parameters, so either can be
reversed without touching anything else.

**1. The two recessed adhesive pads are deleted.** `pads_enabled = False`.
Brief §3.1 lists the "recessed adhesive pads" among the Rev N features to
preserve, and Rev N has two: 24.00 × 2.00 mm, 0.30 mm deep into the seating
face at y ±7.85…9.85. The owner identified them as the "two rectangle cut outs
on the underside" and directed their removal.

The deviation is defensible on its own terms. Rev N located on two side rails
with a **clearance** fit and needed adhesive to stay put. Rev Q is held by an
**interference** fit on both axes — 0.100 mm per side across and 0.075 mm up as
built (§3.8) — which makes bonded pads redundant, and a pocket in the seating
face is a place for the bezel to rock or for adhesive to squeeze out. The
seating face is now one unbroken annulus of **210.867 mm²**. Note the caveat in
§8.1: PETG creep will slacken a press fit over months, so if the bezel must not
drop out, adhesive on the flat face is the reliable retention.
Set `pads_enabled = True` to restore them exactly; the Rev N pad dimensions are
retained in the parameter table for that purpose.

**Consequence for retention:** the bezel is now retained by the interference fit
alone. If adhesive is still wanted it goes on the flat seating face rather than
into pads. **Removability must be re-checked on the prototype** — §10 Stage 1.

**2. The inset-wall outer corner radius is raised 50%, R2.00 → R3.00.** The
owner judged R2.00 not to match the real Perspex opening corner. Brief §2 and §4
state 2.00, but §7 explicitly allows the named corner parameters to be changed
when the fit needs it, so this is observation superseding a provisional value —
which is the whole point of an OPEN revision.

The inner corner radius follows from it and is not entered separately:
`bezel_lip_inner_r = 3.00 − 0.80 = 2.20` at the time. Both numbers moved
again under §3.6 to §3.10. After a revert and a re-revert the outer corner
stands at **R4.25** with the inner at **R3.00**, restored on the physical
evidence of an offer-up (§3.10) — which is the direction this section set.

It makes the part strictly more robust where it matters and slightly worse where
it does not:

| | R2.00 | **R3.00** |
|---|---:|---:|
| Deepest penetration, any plausible opening corner | 0.100 up to R_panel 2.05 | **0.100 across the whole range** |
| Tightest wall-loop radius at the corner | 1.400 | **2.400** — easier to slice |
| Unmasked corner gap, sharp opening | 0.562 | **0.836** |
| Ring cross-section area | 76.2025 mm² | 74.8290 mm² (85.5432 §3.6, 102.1057 §3.7, 83.4857 §3.8, 86.1682 §3.9, **88.8247** after §3.10) |

A corner that is too **square** jams before the bezel seats; a corner that is
too **round** merely leaves a little cut edge visible at each corner. The change
trades the first failure mode for the second, which is the safer direction while
the opening corner remains unmeasured. §8.3 has the full table.

---

### 3.6 Third owner change — the flush aperture and the split wall

> **Superseded in part by §3.7 and §3.8.** The reasoning here is what
> established the flush rule and the non-uniform wall, and both still
> govern. The figures moved out under §3.7 and then most of the way back
> under §3.8; as built the side wall is **1.25 mm** again, the corner pair is
> **R4.25 / R3.00** (§3.10), and the clear opening is 34.44 × 15.00 — larger than
> this section could reach, because the opening itself turned out to be bigger
> than recorded.

Directed after inspecting the model: *"increase the horizontal opening by 1 mm
each side, expand the thickness of the perspex insert wall to make it flush
with the opening, no change to the outer dimension"* — and, on the meaning of
flush, *"not set back as in the current design on the left and right side."*

That set-back was real. The face opening was 30.90 and the skirt inner was
33.80, so looking in through the window the skirt stood **1.45 mm outboard**
on each side — a visible rearward ledge.

**The three constraints solve uniquely, and they collided with the loop rule.**
Opening 32.90 and a fixed 35.40 outer envelope force a wall of
`(35.40 − 32.90)/2 = 1.25 mm`. At a 0.40 mm extrusion that is **3.125 loops** —
not a whole number. Worse, applying 1.25 mm uniformly would have dragged the
vertical clear opening from 13.60 to 12.70 and cost another 0.45 mm of lit
band, which the owner ruled out.

**The owner then clarified the rule itself:** it is **at least** two loops, and
**the sides and the top/bottom need not carry the same number**. That releases
the wall from having to be uniform, and all three constraints can be met at
once:

| | value | loops | why |
|---|---:|---:|---|
| Side wall (X) | **1.250 mm** | 3.125 | **derived** from the flush requirement |
| Top/bottom wall (Y) | **0.800 mm** | 2.000 | entered — holds the 13.600 clear height |
| Through the corners | 0.800 → 1.193 mm | ≥ 2.000 | sweeps between the two |

The inner corner radius follows the **thicker** wall,
`R1.75 = R3.00 − 1.25`. That is not a free choice: it puts the inner corner arc
centre on the same x as the outer arc centre, so the wall sweeps smoothly and
reaches its minimum exactly at the top/bottom tangent. **Any smaller inner
radius squares the corner off and thins the wall below 0.800** — at R0 it
collapses to 0.189 mm. R1.75 is the smallest value that keeps two full loops
all the way round, and `validate()` re-measures it rather than trusting the
derivation.

**What it costs: nothing vertically.** The clear opening goes
30.90 × 13.60 → **32.90 × 13.60**. The height is untouched, so the visible lit
band stays at **7.450 mm**. The aperture gains 2.00 mm of width and loses the
side ledge entirely.

**What it costs: insertion force.** The interference is horizontal, so it is
resisted by the *side* wall — the one that just went to 1.25 mm. Bending
stiffness scales with thickness cubed, so that wall is **≈31× stiffer than the
original 0.40 mm** and **≈3.8× stiffer than the 0.80 mm** it replaced on the
sides. Brief §3.8 wants the printed wall to take the deflection and the Perspex
to be left unstressed; at 1.25 mm that is a materially harder ask. **This makes
the fit gauge mandatory rather than advisable** — see §8.1.

**Two knock-on model fixes**, both found by the validator and both fixed at the
root rather than waived:

* the aperture's rear section used to over-run 0.05 mm below the seating plane.
  Harmless while the aperture was 30.90 wide inside a 33.80 skirt; with the
  side flush the two share a width, and the over-run bit the top of the wall at
  all four corners — **0.84 mm² of ring area missing at z = 2.95** while
  z = 0.45 and 1.60 measured correctly. The rear section now stops exactly on
  the seating plane.
* the aperture's rear corner radius was the window's R0.80 against the skirt's
  R1.75, so it bulged outside the skirt corner and left a crescent-shaped 90°
  ledge hanging over the aperture — **3.40 mm² of unsupported overhang** across
  the four corners. The rear section now carries the skirt's own R1.75. With
  the profiles matching exactly, `ap_root_relief` is back to **0.00** — the
  0.02 mm anti-tangency dodge existed only to paper over that mismatch.

---

### 3.7 Fourth owner change — the interference fit

> **Superseded by §3.8, and kept because the finding is the point.** This
> change put the skirt 1.00 mm oversize across and 1.90 mm oversize up
> against the measured opening, which could not be assembled. It was
> reported as such by the generator, the validator and the offline verifier
> rather than softened, and the owner then pulled the geometry back in §3.8.
> **The flush rule, the straight bore and the loop accounting introduced
> here all survive unchanged.**

Directed after inspecting the model: *"the refinement now is to create the
interference fit. 1) without changing the size of the horizontal opening add a
single vertical wall loop to each of the outer faces of the perspex insert.
2) increase the vertical opening by 2 mm, ie moving the top and bottom perspex
insert walls up and down by 1 mm."*

Scope was confirmed with the owner before modelling: the extra loop goes on the
**left and right outer faces only**, and the bezel face opening is opened with
the skirt so the vertical clear opening gains the full 2.00 mm.

**Move 1 — one extra 0.40 mm loop on each side, added outward.**

| | before | after |
|---|---:|---:|
| Outer envelope width | 35.400 | **36.200** |
| Side wall | 1.250 (3.125 loops) | **1.650 (4.125 loops)** |
| Outer corner radius | R3.000 | **R3.400** |
| Opening width and inner corner | 32.900, R1.750 | **32.900, R1.750 — unchanged** |

The loop is applied at the corners as a **true outward offset**, and that is not
decoration. The inner corner radius is `corner_r − wall_x`, so holding the outer
corner at R3.00 while the wall went 1.25 → 1.65 would have dragged the *opening*
corner from R1.75 to R1.35. The instruction was to leave the horizontal opening
alone, so the outer corner absorbs the loop and the opening comes through
bit-for-bit identical.

**Move 2 — the top and bottom walls move 1.00 mm out each.**

| | before | after |
|---|---:|---:|
| Outer envelope height | 15.200 | **17.200** |
| Top/bottom wall | 0.800 (2.000 loops) | **0.800 — translated, not thickened** |
| Inner envelope height | 13.600 | **15.600** |

**The face opening had to follow.** At 15.35 it would have become the new
limiter and delivered +1.83 mm of vertical opening instead of the +2.00 mm
asked for, so it goes to **15.60** — and its corner radius goes to **R1.75** as
well. That second part is not cosmetic tidying: at R0.80 the face corner is
*fuller* than the skirt's R1.75, so once the two share the same extents the face
corner would have become the visible one and sharpened the clear opening from
R1.75 to R0.80. R1.75 leaves what the eye actually sees exactly as it was.

**What it buys — the aperture becomes one straight flush bore.** Face opening,
skirt inner envelope and corner radius are now identical, so the taper is gone
(§3.3), the wall root lands on its full 0.800 mm of face material, and there is
no ledge, set-back or corner crescent anywhere in the bore. The offline verifier
measures the opening at three heights — two in the face plate, one down in the
skirt — and gets 32.9000 × 15.6000 at every one, spread 0.0000 mm.

**What it buys optically.** The clear opening goes 32.90 × 13.60 →
**32.90 × 15.60**, and for the first time the lip gives opening back rather than
costing it: the visible lit band goes **7.450 → 8.450 mm**, which is 0.350 mm
*more* than Rev N ever showed. §5 has the full accounting.

**What it costs, and this is the finding of the whole change.** Both moves push
material outward into the Perspex opening:

| | skirt | measured opening | fit |
|---|---:|---:|---|
| Width | 36.200 | 35.200 | **+0.500 mm per side, interference** |
| Height | 17.200 | 15.300 | **+0.950 mm per side, interference** |

The vertical figure was a 0.050 mm *clearance* before this change. It is now a
0.950 mm interference, and **that is not a press fit — the skirt is 1.90 mm
taller than the hole and cannot enter it.** PETG will not give that up, and the
0.20 mm entry lead-in no longer buys free entry either: even at the tip the
skirt is 0.60 mm over the opening width, so the interference is resisted from
first contact.

Two readings are possible and CAD cannot choose between them:

* `panel_open_h = 15.30` is a **MEASURED Rev C** value that no Rev N surface
  ever touched (§2.3, §8.4). If the real opening is taller than recorded, the
  figures above are wrong and the fit may be reasonable. **Re-measure the
  Perspex opening before printing a bezel.**
* Or the 1.00 mm per side vertical move overshoots and should be reduced.

The measured panel figures are **deliberately not adjusted** to make the numbers
look right. The generator, the validator and the offline verifier all state the
interference plainly and all three refuse to soften it. This triggers the
brief's second stop condition — see §11.

**Everything else is unchanged**: the 40.00 × 20.30 × 4.00 envelope, the 2.80 mm
depth, the 0.20 mm lead-in, the 0.80 mm top/bottom wall, the two-loop minimum,
and all Rev P.5 carrier geometry and files.

---

### 3.8 Fifth owner change — pulling the fit back into range

Directed after reading §3.7: *"increase the perspex corner radius by 25%,
reduce the perspex insert width by 0.8 mm, decrease insert height by 1.75 mm."*
The dimensions were cross-checked with the owner before modelling.

| | before | change | **after** |
|---|---:|---:|---:|
| Outer width | 36.200 | −0.800 | **35.400** |
| Outer height | 17.200 | −1.750 | **15.450** |
| Outer corner radius | R3.400 | ×1.25 | R4.250 — **reverted to R3.000, §3.9** |

**This is the fit the revision needed.** Against the measured 35.20 × 15.30
opening:

| | insert | opening | per side |
|---|---:|---:|---|
| Width | 35.400 | 35.200 | **+0.100 interference** |
| Height | 15.450 | 15.300 | **+0.075 interference** |

Both figures land inside the **0.05–0.15 mm** band a thin printed wall takes up
by flexing rather than by pushing on the acrylic, and the smaller vertical
figure is deliberate — it is resisted by the thinner 0.80 mm wall. Two things
matter as much as the numbers:

* the **0.20 mm lead-in now buys free entry again**. At the tip the skirt is
  35.000 × 15.050, which is **0.100 mm per side under** the opening across and
  **0.125 mm per side under** it up, with the full section restored by
  z = +0.400. The part locates before it engages, instead of fighting from
  first contact as §3.7 left it;
* **print tolerance is the same size as the fit.** A well-tuned FDM machine
  holds roughly ±0.10 mm on a small external dimension and tends to run over
  nominal, so an intended 0.100 mm interference realistically arrives anywhere
  between 0.00 and 0.25 mm. That is the real reason the value cannot be picked
  from theory and the fit gauge exists.

**The side wall returns to 1.250 mm.** The −0.800 mm on the width exactly undoes
the outward loop §3.7 added, so the wall is back to the 3.125 loops §3.6 derived
from the flush requirement, and the interference is now resisted by a wall
≈31× stiffer in bending than the original 0.40 mm rather than ≈70×.

**The corner argument — superseded by §3.9, and kept because the trade is
real.** The two failure modes are asymmetric: an insert corner **squarer** than
the opening corner touches before the flanks do, so the part jams and never
seats — a hard failure. An insert corner **rounder** than the opening merely
leaves a crescent of cut edge visible at each corner apex — cosmetic. On that
basis every unit of uncertainty in the unmeasured opening corner should be spent
on the round side, and R4.25 covered opening corners all the way to R4.00. The
owner then looked at the front view and rejected what R4.25 does to the visible
aperture, and reverted it (§3.9). The argument is not withdrawn — it is now the
first item in §8.3.

**What it costs optically.** The clear opening goes 32.90 × 15.60 →
**32.90 × 13.85**, because the wall thickness is unchanged and the face opening
is flush to it, so the aperture tracks the insert height exactly. The lit band
goes 8.450 → **7.575 mm**, which is 0.525 mm less than Rev N. That is the +2.00
of §3.7 coming back off, less 0.25. §5 has the full accounting.

**And the aperture corner opened to R3.00**, derived as R4.25 − 1.25. That is
not a free choice — the flush rule makes the face opening carry the skirt's own
corner — so a rounder insert corner necessarily gives a rounder window. At R3.00
on a 13.85 mm tall opening only 7.85 mm of the height is straight and the rest is
arc, and the aperture read as a distinctly rounded slot rather than a rectangle.
**That is what the owner rejected on sight, and §3.9 reverses it.**

**Unchanged**: the 40.00 × 20.30 × 4.00 envelope, the 2.80 mm depth, the 0.20 mm
lead-in, the 0.80 mm top and bottom wall, the flush rule, the straight bore, the
two-loop minimum, and all Rev P.5 carrier geometry and files.

---

### 3.9 Sixth owner change — reverting the corner

> **REVERSED by §3.10, on physical evidence.** The owner printed the R4.25
> part, offered it into the real opening, found the corner "a good match"
> and retracted this change in as many words: *"I was wrong."* R4.25 is
> restored. The reasoning below is kept because the appearance trade it
> describes is real and was correctly identified — it was simply outweighed
> by a physical measurement that did not exist at the time.

Directed on seeing the front view, without a print: *"I can see without printing
that is wrong. Revert the corner radiuses, keep the other amends."*

| | §3.8 | **reverted** |
|---|---:|---:|
| Outer corner radius | R4.250 | **R3.000** |
| Visible aperture corner | R3.000 | **R1.750** |
| Everything else from §3.8 | — | unchanged |

**R3.00 is the consistent revert, not an arbitrary one.** The R3.40 that R4.25
was built from only ever existed as R3.00 *plus the outward loop*, and §3.8
removed that loop when it took 0.80 mm off the width. So both radii return to
exactly the pair they last held with a 1.25 mm side wall — outer R3.00, visible
corner R1.75 — which is the value the owner themselves set in §3.5 and the
geometry §3.6 derived from it.

**What it buys.** The aperture reads as a rectangle with modest rounded corners
again: at R1.75 on a 13.85 mm tall opening, **10.35 mm of the height is
straight** where R3.00 left only 7.85 mm. Corner masking also improves — against
a plausible R2.50 opening the unmasked crescent falls from 0.601 to **0.084 mm**,
and against a sharp opening from 1.147 to **0.780 mm**.

**What it costs, and this is now the tightest margin in the part.** The insert
corner must stay at least as round as the opening corner or it jams before the
flanks touch. R4.25 covered opening corners to R4.00; **R3.00 covers them only
to about R2.50**:

| assumed opening corner | deepest penetration | verdict |
|---:|---:|---|
| ≤ R2.50 | +0.100 | flanks set the fit |
| R3.00 | +0.125 | flanks set the fit, no margin left |
| R3.50 | **+0.331** | **jams** |
| R4.00 | **+0.538** | **jams** |

`panel_open_corner_r` is still **UNRESOLVED** — a drill-shank estimate was
offered during this work and withdrawn — so nothing in the model depends on it,
but the part now does. **This is the first thing the fit gauge must answer**, and
it answers it without any measuring equipment: offer a tab into the corner of the
real opening, and if it beds on the flanks with a light gap at the corner apex,
R3.00 is round enough. If it rocks on the corner and will not seat, the opening
corner is larger than R3.00 and `bezel_lip_corner_r` has to go back up — at which
point the appearance trade has to be made again with a real number in hand
instead of an estimate. §8.3.

**Unchanged from §3.8**: the 35.400 × 15.450 outer envelope, the 0.100 / 0.075 mm
per side fit, the 1.250 / 0.800 mm wall, the 32.900 × 13.850 clear opening and
its 7.575 mm lit band, the straight bore, the flush rule and the two-loop
minimum.

---

### 3.10 Seventh owner change — the opening is measured, and everything follows

*"I was wrong. I actually printed one and the corner radius before you reverted
are a good match... Based on the measured Perspex opening dimension set the
Perspex insert dimensions for an interference fit."*

This is the change that put the revision on a measured footing. Three things
happened at once.

#### The corner is restored to R4.25, on evidence

The owner printed the §3.8 part, offered it into the real opening, and found the
R4.25 corner **a good match** — explicitly retracting the §3.9 revert. That is the
first physical information about the opening corner anywhere in this project,
and it outranks every calculation in this file. The visible aperture corner
returns to R3.00 with it.

#### The opening is measured for the first time

| | recorded (Rev C) | **measured 2026-08-31** | difference |
|---|---:|---:|---:|
| Width | 35.20 | **36.74** | **+1.54** |
| Height | 15.30 | **16.45** | **+1.15** |

**Method — the printed part as a gauge block.** The §3.8 insert is exactly
35.400 × 15.450. Pushed to one side, the slop that opens opposite reads
**1.34 mm horizontal and 1.00 mm vertical**, so the opening is 35.400 + 1.34 and
15.450 + 1.00.

This closes the longest-standing hole in the project. §2.3 records that Rev N
located on **two side rails only**, so no released surface had ever touched the
top or bottom of the opening — `panel_open_h` had no corroboration from any part
ever made, and `panel_open_w` only an envelope. Every fit figure in §3.1 to §3.9
was computed against numbers nothing had checked, which is precisely why §3.7
looked impossible and §3.8 pulled back from a fit that was in fact achievable.

**Accuracy.** The owner reports the reading as hard to take and expects a further
iteration. Two error sources stack: the slop measurement itself, and the printed
part being *nominally* rather than actually 35.400 × 15.450 — a well-tuned FDM
machine holds about ±0.10 mm and tends to run over. **Treat these as ±0.2 mm.**
They remain an enormous improvement on a figure nothing had ever checked.

#### The insert is now DERIVED from the opening, not entered

```text
    insert outer = measured opening + declared interference
    36.940 = 36.74 + 2 x 0.100        16.600 = 16.45 + 2 x 0.075
```

Until now the envelope was entered and the fit reported back, so re-measuring the
opening left the envelope stale and silently changed the fit. That inversion is
exactly what produced the §3.7/§3.8 whipsaw. Now `panel_open_w` and
`panel_open_h` drive everything: envelope, split wall, clear opening, both corner
radii, the fit gauge and both validators. **Re-measuring is a two-number edit.**

The side wall changed hands at the same time. It used to be derived, absorbing
whatever the flush requirement left over; against the real 36.74 opening that
would have forced **2.02 mm** — five extrusion loops and roughly 130× the bending
stiffness of the original 0.40 mm wall, the opposite of what brief §3.8 asks
for — while pinning the clear width the owner had asked to grow. So both walls
are now entered (1.25 sides, 0.80 top and bottom) and **all three face-opening
values derive from the skirt**, which also keeps X and Y symmetric for the first
time.

#### What comes out

| | value |
|---|---:|
| Insert outer | **36.940 × 16.600**, R4.250 |
| Insert inner = face opening = clear opening | **34.440 × 15.000**, R3.000 |
| Fit | **0.100 mm/side across, 0.075 mm/side up** |
| Tip after the lead-in | 36.540 × 16.200 — 0.100 / 0.125 mm per side **under** the opening |

**The clear opening is now larger than Rev N in both axes** — 34.44 × 15.00
against 30.40 × 14.90 — and the visible lit band goes 8.100 → **8.150 mm**, above
Rev N for the first time in the revision. That is what the owner was asking for
when they said to revert the opening to the larger size; it arrives from the
measurement rather than from a guess.

#### Two things that got tighter

**Clearance to the frozen carrier: 0.939 → 0.339 mm** — *since recovered to
0.754 mm by the shorter insert, §3.11.* Still zero interference,
but the larger skirt has spent two thirds of that margin, and two FDM parts at
±0.1 mm each make 0.339 mm a real number rather than a comfortable one. The
carrier cannot move — it is released and frozen — so if this becomes a problem it
is the bezel that gives. §6.1.

**Bezel flange outboard of the skirt: 1.530 mm at the sides**, 1.850 top and
bottom, and the bezel covers the Perspex opening by 1.630 / 1.925 mm. Still
sound, but the black border is visibly slimmer than at any earlier issue — see
`Decca_OLED_Display_Bezel_revQ_front.png` and judge it before printing.

---

### 3.11 Eighth owner change — the insert fits, but it is 0.5 mm too deep

> **REVERTED by §3.12.** The depth reduction below was undone the same day when
> the owner traced the bottoming-out to a **printing issue**, not the geometry.
> The depth is back at 2.80 mm. The **fit confirmation** in this section stands
> — that is what closed the interference gate — and so does the reasoning about
> `bezel_face_t`, which is why the revert cost nothing.

*"Fits! We need to reduce the depth of the insert by 0.5 mm, it is preventing
full insertion, no other changes."*

**The fit is confirmed on a printed part.** The §3.10 geometry — 36.940 × 16.600
into the measured 36.740 × 16.450 opening, 0.100 / 0.075 mm per side — goes in.
That closes the interference question that has been the primary gate since the
brief amendment.

One correction: at 2.80 mm the insert **bottoms out before the bezel face seats
against the Perspex**, so the depth comes down to **2.30 mm**.

| | before | after |
|---|---:|---:|
| Insert depth | 2.800 | **2.300** |
| Wall rear tip | z = +0.200 | **z = +0.700** |
| Clear of the Perspex rear face | 0.200 | **0.700** |
| Clearance to the OLED glass | 0.500 | **1.000** |
| Total part depth | 4.000 | **3.500** |

**Where 2.80 came from, and why it was wrong here.** It is the Rev N rail
engagement depth, recovered from the released STEP and carried through this
revision as PROVEN (§2.3). It *was* proven — for two 2.15 mm-long rails on the
side flanks. A continuous wall around the whole perimeter is a different thing:
it can foul anything anywhere behind the opening, and it has 100 mm of perimeter
to find something with, where the rails had 8.6 mm. The Rev N figure was good
evidence for Rev N and merely a starting point for Rev Q, and this is the first
time anything physical has tested it.

**One relationship had to be inverted to honour "no other changes."** The model
had `bezel_face_t = bezel_t − bezel_lip_depth`, with `bezel_t` entered at 4.00.
Shortening the insert under that arrangement would have pushed the bezel front
face from **+4.200 to +4.700** — the bezel standing half a millimetre prouder of
the Perspex, which is a visible external change and precisely what "no other
changes" rules out.

So `bezel_face_t` is now **entered at 1.20** (it is the whole of the Rev N
external appearance) and `bezel_t` is **derived** as face + insert depth.
Shortening the insert now shortens the *part*, 4.000 → 3.500, and the face stays
where it was. Same pattern as §3.10: enter what matters, derive what follows.

**What it buys elsewhere.** The shorter skirt reaches less far behind the
Perspex, so two clearances improve without being asked to:

* **carrier clearance 0.339 → 0.754 mm** — this recovers most of what the wider
  §3.10 skirt had spent against the frozen Rev P.5 carrier, and takes that off
  the watch list;
* **OLED glass clearance 0.500 → 1.000 mm**, double the brief's minimum.

**What it costs.** The insert covers **2.30 of the 3.00 mm** Perspex thickness
instead of 2.60, leaving 0.70 mm of the cut edge unmasked at the *back* of the
opening rather than 0.20. That is invisible from the front — the masking that
matters is at the front face, and it is unchanged — but it is a real reduction in
engagement: **18 % less wall in contact**, so slightly less grip and slightly less
resistance to rocking. The interference volume falls 16.610 → 13.465 mm³ for the
same reason.

**Unchanged**: the 40.00 × 20.30 outer envelope, the 1.20 mm face, the
36.940 × 16.600 insert outer, the 34.440 × 15.000 clear opening and its 8.150 mm
lit band, R4.250 / R3.000 corners, the 1.250 / 0.800 wall, the 0.100 / 0.075 mm
fit, the 0.200 mm lead-in, the flush rule, the straight bore and the two-loop
minimum.

---

### 3.12 Ninth owner change — the depth reduction is reverted, and sign-off

*"Undo that last 0.5 mm insertion reduction, the cause was a printing issue.
Once reverted the bezel is signed off as complete."*

`bezel_lip_depth` returns to **2.80 mm**, the Rev N engagement depth recovered
from the released STEP in §2.3 and carried unchanged through this revision until
§3.11 briefly cut it. Everything the reduction moved moves back:

| | §3.11 | **reverted** |
|---|---:|---:|
| Insert depth | 2.300 | **2.800** |
| Wall rear tip | z = +0.700 | **z = +0.200** |
| Total part depth | 3.500 | **4.000** |
| Clear of the Perspex rear face | 0.700 | **0.200** |
| Clearance to the OLED glass | 1.000 | **0.500** |
| Minimum distance to the Rev P.5 carrier | 0.754 | **0.339** |
| Perspex covered by the insert | 2.300 of 3.000 | **2.600 of 3.000** |

**A printing issue, not a design one — and the distinction matters.** §3.11
reasoned from the bottoming-out that 2.80 might be wrong for a continuous wall
even though it was proven for two short Rev N rails. That reasoning was sound but
the premise was false: the obstruction was in the print, not in the geometry.
2.80 has now survived a physical offer-up, which is the first time it has been
tested outside Rev N.

**The §3.11 restructure is kept, and it is why this revert was free.**
`bezel_face_t` stays **entered** at 1.20 mm with `bezel_t` **derived** as face +
insert depth. Putting the depth back therefore returns the total to exactly
4.000 mm on its own, with the bezel face still standing 1.20 mm proud of the
Perspex. Had the old arrangement survived, the revert would have had to move two
numbers in step and could have left the face in the wrong place.

**Engagement is restored**: the insert covers 2.600 of the 3.000 mm Perspex
thickness again, so the 18 % of wall contact §3.11 gave up comes back, along with
the grip and the resistance to rocking.

**Two clearances go back to their tighter values**, and both are recorded rather
than waived: the OLED glass at **0.500 mm**, which is exactly the brief minimum
and the released Rev N/P value; and the frozen Rev P.5 carrier at **0.339 mm**.
The carrier figure is the one to carry forward — see the sign-off note at the
top of this report.

**Unchanged**: everything else. The 40.00 × 20.30 envelope, the 1.20 mm face, the
36.940 × 16.600 insert outer, the 34.440 × 15.000 clear opening and its 8.150 mm
lit band, R4.250 / R3.000 corners, the 1.250 / 0.800 wall, the 0.100 / 0.075 mm
fit, the 0.200 mm lead-in, the flush rule, the straight bore and the two-loop
minimum.

**With that reverted the owner signed the bezel off as complete.**

---

## 4. Exact resulting dimensions

| | mm |
|---|---:|
| **Perspex opening, MEASURED 2026-08-31** | **36.740 × 16.450** × 3.000 thick |
| Bezel envelope | **40.000 × 20.300 × 4.000** — depth derived as face + insert |
| Bezel face thickness | **1.200** — PRESERVED, entered; the total follows it |
| External corner radius | R2.000 |
| Front edge break, outer | R0.400 fillet |
| Front edge break, window | 0.400 × 45° chamfer (§3.4) |
| Seating plane (Perspex front) | z = +3.000 |
| Bezel front face | z = +4.200 |
| **Bezel face opening, at the front face** | **34.440 × 15.000**, R3.000 |
| Aperture at the seating plane | **34.440 × 15.000**, R3.000 — identical, i.e. flush |
| Aperture taper | **0.00° — a straight bore** |
| **Inset-wall outer envelope** | **36.940 × 16.600** |
| **Inset-wall inner envelope** | **34.440 × 15.000** — flush with the face opening on all four sides |
| **Wall thickness** | **1.250 sides / 0.800 top and bottom**; corners sweep 0.800 → 1.216, never below 0.800 |
| **Wall depth** | **2.800** (z +3.000 → +0.200) — 2.300 tried and reverted, §3.12 |
| Outer corner radius | **R4.250** |
| Inner corner radius | **R3.000** |
| Entry lead-in | 0.200 × 45°, outer rear edge only |
| Section at the tip, after the lead-in | 36.540 × 16.200 — **0.100 / 0.125 mm per side UNDER the opening** |
| Bezel flange outboard of the skirt | **1.530** sides / **1.850** top and bottom |
| Bezel cover over the Perspex opening | 1.630 sides / 1.925 top and bottom |
| **Horizontal fit** | **0.100 INTERFERENCE per side** |
| **Vertical fit** | **0.075 INTERFERENCE per side** |
| Interference volume, as modelled | **16.610 mm³** |
| Rearmost material | z = **+0.200** — 0.200 clear of the Perspex rear face |
| Clearance to OLED glass front face | **0.500** — the brief minimum, and the released Rev N/P value |
| **Minimum distance to the Rev P.5 carrier** | **0.339** — carry this forward, §3.12 |
| **Effective optical opening** | **34.440 × 15.000**, R3.000 |
| Seating face | one unbroken annulus, **210.867 mm²** (no adhesive pads) |
| Perspex covered by the insert | **2.600 of 3.000** — 0.200 unmasked at the rear |
| Solid volume | 0.5951 cm³ (mesh 594.615 mm³) |
| Mass in PETG @ 1.27 g/cm³ | ≈ **0.76 g** |
| Mesh | 3590 triangles, 1795 vertices, closed, manifold, no degenerates |

---

## 5. Optical masking introduced by the wall

**After §3.10 the wall no longer costs anything optically.** For the first time
the clear opening is larger than Rev N in *both* axes, and the visible lit band
is above Rev N's rather than below it. That is not a design improvement so much
as the correction of a bad input: the opening was always 1.54 mm wider and
1.15 mm taller than the model believed.

| | Rev N | Rev Q | change |
|---|---:|---:|---:|
| Clear opening width | 30.400 | **34.440** | **+4.040** |
| Clear opening height | 14.900 | **15.000** | **+0.100 total, +0.050 per side** |
| Corner radius | R0.800 | **R3.000** | the skirt corner, now shared by the face |

The clear opening is controlled by the **skirt inner envelope on all four
sides**, with the bezel face opening flush to it, so neither one masks the other.
A continuous wall still has to exist at the top and bottom of the opening and
still has to have a thickness — that cost has not gone away, it is simply
outweighed by an opening 1.15 mm taller than recorded.

The history, since the direction of travel is the story of this revision:

| | opening believed | clear opening | lit band |
|---|---:|---:|---:|
| Rev N | 35.20 × 15.30 | 30.40 × 14.90 | 8.100 |
| Rev Q, 0.40 mm wall | 35.20 × 15.30 | 30.90 × 14.20 | 7.750 |
| Rev Q, 0.80 mm wall | 35.20 × 15.30 | 30.90 × 13.60 | 7.450 |
| Rev Q, flush sides (§3.6) | 35.20 × 15.30 | 32.90 × 13.60 | 7.450 |
| Rev Q, walls out (§3.7) | 35.20 × 15.30 | 32.90 × 15.60 | 8.450 |
| Rev Q, pull-back (§3.8) | 35.20 × 15.30 | 32.90 × 13.85 | 7.575 |
| **Rev Q as built (§3.10)** | **36.74 × 16.45** | **34.44 × 15.00** | **8.150** |

### 5.1 Effect on the powered image

Taking the OLED position from the **released Rev P.5** model — active area
29.42 × 14.70 mm, active centre at y = +6.70 mm after the Rev P.5 +7.00 mm rise:

| | Rev N | Rev Q at §3.8 | **Rev Q as built** |
|---|---:|---:|---:|
| Visible active width | 29.420 | 29.420 | **29.420** (unchanged throughout) |
| Visible active height | 8.100 | 7.575 | **8.150** |
| Active height versus Rev N | — | −0.525 | **+0.050** |
| Unlit board visible below | 6.800 | 6.275 | **6.850** |

The aperture is 34.440 wide against a 29.420 active width, so the **full active
width has been visible throughout** and the extra 4.04 mm of opening reveals
unlit glass and board, not screen. Vertically the active area's own bottom edge
sits at y = −0.650 mm, well inside the aperture, so the bottom of the wall costs
no active area at all — the whole ±0.050 mm swing is at the top.

For context, the already-released Rev P.5 condition still dominates: only
8.30 mm of the 14.70 mm active height falls inside the Perspex opening at all.
Rev Q now returns 0.050 mm of that rather than taking 0.525 mm off it.

`Decca_OLED_Display_Bezel_revQ_optical.png` shows this to scale.

> **CAD does not get a vote on whether this is acceptable.** It reports the
> geometry. Whether the intended screen content is readable through a
> 34.44 × 15.00 mm aperture, and whether the noticeably slimmer black border
> around it looks right, are settled by the powered test in §10 and by nothing
> else.

---

## 6. Validation results

Two independent tools. Neither check was altered, relaxed or removed.

### 6.1 In Fusion — `validate()` — **52/52 PASS**

| Group | Result |
|---|---|
| Solid integrity | one body, closed solid, **1 shell, 1 lump**, 0 sliver faces < 0.001 mm², 0 sliver edges < 0.005 mm; 45 faces, 108 edges |
| Envelope | 40.00000 × 20.30000 × **4.00000**; front face +4.20000; rearmost **+0.20000** |
| **Wall continuity, by AREA** | full ring **88.8247 mm²** at z = 0.45, 1.60 and 2.95 — matching the analytic value to four decimals |
| Continuity by region | top **22.7520**, bottom **22.7520**, right **10.1250**, left **10.1250**, corners **23.0707 mm²** — every one exact |
| Outer envelope | exactly 36.9400 × 16.6000 |
| Clear width derivation | 34.440 = 36.94 − 2 × 1.25, i.e. from the entered side wall |
| **Flush, all four sides** | skirt inner **34.4400 × 15.0000 R3.0000** == face opening **34.4400 × 15.0000 R3.0000** — three separate gates |
| Wall through the R4.25 corners | sweeps **0.8000 → 1.2164 mm**, never below the 0.80 top/bottom wall, never above the 1.25 side wall |
| Loop rule, per side | sides **3.125** loops, top/bottom **2.000** loops, corners never below **2.000**; corner loop radii **4.050** and **3.650**, no cusp; centrelines exactly **0.4000** apart |
| **Interference present** | **16.6102 mm³** of overlap |
| Interference bounded | deepest **0.1000 mm** in X and **0.0750 mm** in Y — exactly the declared values, nowhere more |
| Interference located | confined to the lip depth, z 0.3000…3.0000 — below +0.300 the lead-in holds the section clear |
| Relief test | with 0.100/0.075 mm relief applied, overlap falls to **0.000000 mm³** |
| Behind the Perspex rear face | **0.000000 mm³** |
| OLED glass | 0.000000 mm³; clearance 0.5000 mm |
| **Rev P.5 carrier** | **0.000000 mm³**; minimum distance **0.3394 mm** — see below |
| Optical opening, plug test | a 34.40 × 14.96 plug passes clean through (0.000000 mm³); a 34.48 × 15.04 plug does not |
| Aperture | 34.440 × 15.000 at both the seating plane and the front face — taper **0.00°** |
| Print orientation | wall worst overhang **0.000°**; 0.0000 mm² of >45° overhang outside the bed-adjacent break; bed contact 215.443 mm² |

> **Carrier clearance is 0.339 mm — carry this forward.** The §3.10 skirt, sized
> to the re-measured opening, cut it from 0.939 mm. The §3.11 depth reduction
> briefly recovered it to 0.754, and §3.12 reverted that. It is a **pass** — zero
> interference — and the assembly has been made, but two FDM parts at roughly
> ±0.1 mm each make 0.339 mm a real number rather than a comfortable one. The
> carrier is released and frozen, so if it ever bites it is the bezel that
> changes. Worth re-checking if either part is reprinted on a different machine
> or profile.

Two gates are reports rather than pass/fail: the fit summary, and the **entry
clearance at the tip** — 0.100 mm per side across and 0.125 mm per side up,
stated every run so the lead-in's contribution cannot quietly disappear.

Continuity is proved by **cross-section area**, not by point sampling.
`BRepBody.pointContainment` is not trustworthy on this body — containment
reported the middle of the open aperture as solid and scattered points inside
the wall as void. Area, taken by boolean intersection with a thin slab, is
exact, and it is the **stronger** proof: any break, thin spot or gap anywhere in
the ring removes area, and an exact match leaves nowhere for one to hide.

### 6.2 Offline from the mesh — `Decca_Display_Bezel_revQ_verify.py` — **47/47 PASS**

Reads only `../STL/Front_Bezel_revQ.stl`, numpy only, exits non-zero on
failure. It re-derives every claim from triangles and compares against figures
typed in by hand from the controlled documents — deliberately *not* imported
from the generator.

```text
1. MESH TOPOLOGY       every edge shared by exactly 2 triangles; consistent
                       winding; ONE connected component; no orphan vertices;
                       NO degenerate triangles; 3590 triangles,
                       volume 594.6145 mm3
2. ENVELOPE            40.0000 x 20.3000 x 4.0000; front +4.2000; rear +0.2000
3. BEHIND THE PERSPEX  lowest z = +0.2000; 0.2000 clear of the rear face;
                       0.5000 clear of the OLED glass
4. WALL SECTIONS       36.9400 x 16.6000 at z = 0.45, 1.60 and 2.95
5. WALL CONTINUITY     720/720 stations x 3 depths, 0 voids
                       left 88/88  right 88/88  top 88/88  bottom 88/88
                       corner 368/368
                       wall MEASURED at 720 of 720 stations, none skipped
                       min 0.8000  max 1.2500  mean 1.0019
5b. LOOP RULE          sides 3.125 loops, top/bottom 2.000; corner loop radii
                       4.05 / 3.65, no cusp; centrelines 0.4000 apart;
                       inner corner R3.00; FLUSH
6. ENVELOPE + FIT      inner 34.4400 x 15.0000; depth 2.8000;
                       INTERFERENCE +0.1000/side X and +0.0750/side Y
7. FACE + OPTICAL      15.0000 at z = 3.70, 3.20 and 1.60, spread 0.0000;
                       34.4400 wide at all three; taper 0.000 deg;
                       EFFECTIVE 34.4400 x 15.0000; vs Rev N +4.040 / +0.100
8. LEAD-IN             tip 36.5400 vs 36.7400 opening, +0.100 mm per side
                       UNDER it; full section by z = +0.400, so 2.600 of
                       the 3.000 mm Perspex is covered at full section
RESULT: 47/47 PASS
```

> **Two defects in this verifier were found and fixed at §3.7, and one
> invalidated a figure published before that.** The inward wall walk stopped at
> 0.600 mm, less than even the 0.80 mm top wall, so it never found an exit,
> dropped every station and left the wall array **empty** — the three gates that
> depend on it were never created at all, which is not the same as passing.
> Separately, the even-odd inside test double-counted a ray landing exactly on a
> tessellation seam. Both are fixed and a gate now fails unless all 720 stations
> return a figure.

### 6.3 Sprung-post and module corridors

Covered rigorously rather than by inspection. A synthetic solid spanning
**everything behind the Perspex rear face** (the full opening footprint and far
beyond, z from −30 to 0) was intersected with the bezel: **0.000000 mm³**.

Every corridor of concern — the four sprung posts and their noses (forward-most
at z = −0.400), the module insertion and removal path, the glass, the PCB and
the carrier itself — lies entirely at z < 0. The bezel's rearmost material is at
z = +0.200 and it does not reach z = 0. It therefore cannot enter any of them,
and this is proved without needing to model any of them individually.

---

## 7. Print orientation and settings

**Orientation: bezel FRONT FACE flat on the bed, wall pointing up. No supports.**

In this orientation:

* the wall is a **vertical wall** — measured worst overhang across all 26 wall
  faces is **0.000°**;
* the wall is printed **last**, standing on the already-solid bezel face, so it
  is supported at its root for its entire 2.80 mm height;
* the 0.20 mm entry lead-in is at the **top** of the print and tapers *inward*,
  so it is self-supporting;
* the aperture is a **straight bore** — there is no taper left to check against
  the 45° threshold, and no ledge anywhere in it;
* bed contact is **215.4 mm²** of flat cosmetic face.

The alternative (rear face down) is wrong: the wall would print first as an
unsupported free-standing ring, and the bezel face would then be a full 90°
overhang over it.

### 7.1 The wall loops — at least two, per side

The loop rule is **at least two 0.40 mm loops, applied per side** — the sides
and the top/bottom are free to carry different numbers (§3.6). The first issue's
0.40 mm wall resolved as a single loop, which is what the brief amendment fixed.
The side wall has since been 1.25 (§3.6), 1.65 (§3.7) and is **1.25 again**
(§3.8), so it carries three; the top and bottom have been 0.80 throughout.

What CAD can prove, and does:

| Property | Value |
|---|---|
| Side wall / extrusion width | **1.250 / 0.400 = 3.125 loops** |
| Top/bottom wall / extrusion width | **0.800 / 0.400 = 2.000 loops exactly** |
| Measured wall, 720 stations | min **0.8000**, max **1.2500**, mean **1.0019** — every station measured, none skipped |
| Measured wall through the corners | 368 stations, **0.8000 → 1.2500**, never below two loops |
| Corner wall sweep, analytic | **0.8000 → 1.2164 mm** across the arc; the full 1.250 is carried on the straight side runs |
| Outer loop centreline radius at the corner | 4.25 − 0.20 = **4.050** |
| Inner loop centreline radius at the corner | 4.25 − 0.60 = **3.650** |
| Loop centreline separation | **0.400** — one extrusion, everywhere |
| Smallest offset radius | **3.650** — no cusp, no self-intersection |

With an R4.25 outer and R3.00 inner corner both loop centrelines remain smooth
closed curves the whole way round, and neither collapses or merges at the
corners. The tightest loop radius is **3.650 mm** — the easiest at any issue, and
a quiet benefit of the owner's repeated corner increases.

> **CAD cannot prove what the slicer does.** It proves the geometry *admits*
> the loops. The production slicer preview is a separate, physical gate — see
> §10 Stage 0b.

| Setting | Value | Why |
|---|---|---|
| Nozzle / extrusion width | **0.40 mm** | the wall *is* two of these |
| Layer height | 0.15–0.20 mm | 14–19 layers up the wall |
| Perimeters | **at least 2** in every wall | the sides take 3, the top and bottom 2 — a variable-width generator such as Arachne is HELPFUL here, not a hazard, because the two thicknesses differ |
| Thin-wall / gap fill | **OFF** if it can be | 0.80 is exactly two extrusions and needs none; if the slicer inserts gap fill in the top or bottom wall, the setting is wrong |
| Arachne / variable width | acceptable, but **check the preview** | Arachne may merge 0.80 into one 0.8 mm-wide extrusion — that is a single loop and **fails** the requirement |
| External perimeter speed | ≤ 25 mm/s in the wall | a 2.80 mm tall standing ring |
| Cooling | 100 % over the wall | tiny per-layer loop |
| Material | PETG / PETG-HF, matt or satin **black** | as Rev N |
| Supports | **none** | nothing needs them |
| Bed face | 4+ top/bottom layers or ironing | it is the visible cosmetic face |

> **If your extrusion width is not 0.40 mm**, set `bezel_lip_wall_y` to at
> least **two** *actual* extrusion widths and regenerate. The side wall is
> derived from the flush requirement and is not yours to set. Everything
> downstream — `bezel_lip_inner_w/h`, `bezel_lip_inner_r`, the aperture and
> therefore the optical opening — follows automatically, and the generator
> refuses to build any wall carrying fewer than two loops.

---

## 8. Open risks
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

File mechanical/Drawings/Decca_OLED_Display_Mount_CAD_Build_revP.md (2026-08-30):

# Decca OLED Display Mount — CAD Build Review (Rev P)

Supersedes Rev N. Implements the corrected flush-side-insertion architecture,
the lighting-unit / original-fastener amendments and the integral rear light
shield required by `Decca_OLED_Display_Mount_CAD_Review_revO.md` §8.1, §8.2,
§5.3, §8.3, §8.4, §9, §10 and §12 as amended 2026-08-29
(`main` @ `d7ac584`).
Platform: Autodesk Fusion 360, script-generated parametric build.

> ## Status: Rev P.5 — RELEASED. Prototype built, installed and physically validated
>
> **What is proven.** The printed **Rev P.2** carrier **passed** its physical
> tests for **OLED retention and Perspex tolerance**. Flush-side insertion, the
> fixed rear PCB datum pads, the plain and sprung locating posts, the sprung-post
> retention and release behaviour, the OLED Z position, the 0.30 mm Perspex gap,
> active-area centring, the 35.20 × 15.30 mm aperture, the exact 49.00 mm fixing
> pitch, the carrier-to-Perspex hard stops and the existing bezel are all
> validated hardware and are **carried into Rev P.3 unchanged**.
>
> **What this amendment changes.** Two integration failures against the radio,
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

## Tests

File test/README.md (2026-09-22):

# test

On-target unit tests using [Unity](https://docs.platformio.org/en/latest/plus/unit-testing.html),
PlatformIO's default framework. One suite per module, exercising the public
interface declared in each module's header.

## Layout

```
test/
├── unity_runner.h          shared setup()/loop() runner (included by each suite)
├── test_hardware/          hardware::init()
├── test_settings/          state defaults + RAM/NVS round-trips
├── test_buttons/           active-low debounce, state + event queue
├── test_pots/              ADC mapping, smoothing, calibration + deadband
├── test_display/           SH1106 frames, timing, refresh + physical bring-up
├── test_lighting/          PWM safe-off and immediate switching behaviour
├── test_power/             pure logical on/standby transitions
├── test_ota/               non-blocking authenticated OTA lifecycle
└── test_wiim/              WiiM response parsing and source-command mapping
```

## Running

```
pio test                       # all suites
pio test -f test_settings      # a single suite
pio test -e esp32dev-debug     # against the debug build
```

These are **on-target** tests: they build for the ESP32 and run on a connected
board. `pio test` builds them without hardware, but running the suites needs a
board attached.

## How the build is wired

- `test_build_src = yes` (in `platformio.ini`) compiles the modules in `src/`
  alongside each test runner, so tests call the real module code.
- `main.cpp` is wrapped in `#ifndef PIO_UNIT_TESTING` so its `setup()`/`loop()`
  don't collide with the runner each suite provides via `unity_runner.h`.

## Status

Phase 1 is in progress. The settings suite exercises real NVS persistence using
a test-only namespace. The pots suite injects deterministic ADC samples to
exercise mapping, normalisation, smoothing, calibration, inversion and deadband.
The buttons suite injects digital levels to exercise active-low debounce, bounce
rejection, stable latching state, re-arming and fixed-queue ordering. The pots
and buttons suites also report physical snapshots through Unity for bench
verification. The lighting suite exercises real immediate on/off writes for
physical bring-up and injects its PWM writer for deterministic safe-off,
unchanged-duty and invalid-zone coverage. The display suite
injects its clock, panel initialiser and semantic frame writer to exercise the
five-frame startup animation, standby/source dashboards, persistent mapped
function identity,
copied now-playing metadata and fallback, all four control values, two-second
control overlays, function confirmation, change-only refresh, diagnostics,
SW-unavailable presentation and safe initialisation failure. It also performs a
real SH1106 address/frame snapshot for H4 bench verification and covers the
persistent 180-degree fitted-aperture calibration frame, inactivity dimming,
pixel-off sleep and activity wake. The power suite covers initial state and
one-shot transitions independently of GPIO ownership. Keeping one suite
per module reinforces the low-coupling design in
`docs/Firmware Architecture.md`.

## Future: native tests

Logic with no hardware dependency can move to a faster `native` environment
(no board required) once modules are decoupled from `Arduino.h` — for example
by testing extracted libraries under `lib/`. Not required for Phase 1.

## OTA suite

`pio test -e esp32dev -f test_ota` covers disabled operation, non-blocking connection, timed retry, service start/handling and Wi-Fi-loss recovery. Physical acceptance is one USB bootstrap flash followed by one authenticated wireless upload.

USB-to-OTA physical acceptance passed on 2026-08-30: the authenticated
`esp32dev-ota` upload succeeded and, after reboot, serial reported
`[OTA] ready at 192.168.x.x (decca.local)`. Interrupted-transfer acceptance
remains a separate outstanding check.

Full on-target result (2026-08-30): the `esp32dev` release build passed cleanly
and all seven suites passed on the physical ESP32 — buttons 9/9, display 10/10,
hardware 3/3, lighting 7/7, OTA 5/5, pots 6/6 and settings 3/3 (43/43 total).
The production safe-bootstrap image was restored by USB after testing and serial
reconfirmed `[OTA] ready at 192.168.x.x (decca.local)`.

Display-refinement increment (2026-08-30): the persistent 180-degree calibration
frame, calibrated viewport contract, safe content band and retained paused
metadata expanded `test_display` to 12/12. Physical photographs were used to
accept the final fitted-Perspex layouts, including the corner play/pause glyph.
The calibration frame remains available as a service diagnostic; production
startup returns to the accepted standby view while OTA remains continuously
serviced. The final release build passed and the complete physical run passed
45/45: buttons 9/9, display 12/12, hardware 3/3, lighting 7/7, OTA 5/5, pots 6/6
and settings 3/3. Production was restored by USB and serial reconfirmed
`[OTA] ready at 192.168.x.x (decca.local)`.

Power/protection increment (2026-08-30): GPIO19 was physically accepted in both
positions and the production coordinator now maps the debounced switch to ON or
STANDBY display state. The OLED dims after 60 seconds, turns pixels off after
five minutes, and blanks standby after ten seconds; relevant activity wakes it.
The release build passed and all eight physical suites passed 52/52: buttons
9/9, display 14/14, hardware 3/3, lighting 7/7, OTA 5/5, pots 6/6, power 5/5 and
settings 3/3. Production was restored over COM3; serial reported
`[POWER] state=ON` and `[OTA] ready at 192.168.x.x (decca.local)`.

Controls/source refinement (2026-08-30): production now samples all four pots
and the sole VHF state. VHF closed maps to Digital Streamer; VHF open maps to
Vinyl. The mapped source remains on the normal dashboard until metadata takes
priority. Control overlays use Volume 0–100%, Bass/Treble −50..0..+50 and
Balance L50..0..R50 with centred bars and monochrome icons; balance readings
that round to centre display plain `0`. Physical interaction and fitted-screen
appearance were accepted. The release build passed and all eight suites passed
53/53: buttons 9/9, display 15/15, hardware 3/3, lighting 7/7, OTA 5/5, pots 6/6,
power 5/5 and settings 3/3. Production was restored over COM3.

Stereo/Mono assignment (2026-08-30): TX2/GPIO17 was included in the buttons
suite as a pulled-up lighting request. Stereo open/high maps to on; Mono
closed/low maps to off. The credential-enabled production firmware builds
successfully (RAM 49,880 bytes / 15.2%; flash 837,497 bytes / 63.9%) and all
eight test suites compile without uploading. The
expanded buttons suite passed 11/11 on target in both physical positions:
`stereo_mono_contact=0 lights=on` in Stereo and
`stereo_mono_contact=1 lights=off` in Mono.
The final release build passed and the complete physical run passed 55/55:
buttons 11/11, display 15/15, hardware 3/3, lighting 7/7, OTA 5/5, pots 6/6,
power 5/5 and settings 3/3.

The final 2026-09-08 reassignment uses GPIO14/D14 for on/off, GPIO26/D26 for
VHF, GPIO25/D25 for Stereo/Mono and GPIO18/D18 for lighting PWM. Automated pin-map coverage follows the new
constants and now includes compile-time guards against duplicate GPIO allocation
and use of the project's excluded strapping pins. The production build passed
and all eight on-target suites compiled in PlatformIO; they were not executed
because no ESP32 was attached. Firmware v0.27.3 was then uploaded by
authenticated OTA and returned at `decca.local` / its reserved address. Owner testing
accepted the routing and firmware logic. The retained Stereo/Mono switch fault
is tracked separately as HW-SW-01.

GPIO25 load acceptance (2026-08-31): the physical lighting snapshot fades to
the owner-approved duty 230 (90%), holds for five seconds and fades fully off.
Comparisons at 70%, 80% and 100% informed the selected level. The DAOKAI MOSFET
stage and three parallel lamps passed with smooth transitions, even light and no
flash, flicker, abnormal heat or smell; the lighting suite passed 7/7.
Integrated production acceptance then confirmed Mono commands target 0 and
holds the lamps fully off, while Stereo commands target 230 and lights the dial
at the approved 90% level. OTA remained ready throughout normal operation.
The final credential-enabled production build passed (RAM 49,936 bytes / 15.2%;
flash 839,253 bytes / 64.0%) and the complete on-target run passed 55/55.

DFR0457 release candidate (2026-09-05): the normal target changes to duty 217
(85%), settings schema v4 ensures the earlier persisted 90% value cannot
override it, and the historical GPIO25 PWM changes from 5 kHz to the controller's 1 kHz limit.
That v0.27.1 release used a 20 ms/count fade and approximately 4.34-second
transitions. v0.27.4 supersedes it with immediate writes. Physical OTA and
integration acceptance are tracked as HW-LGT-01 in `docs/Open Issues.md`.

v0.27.1 physical result (2026-09-05): authenticated OTA and reboot succeeded;
the owner approved the 2.2-second firmware-version hold and both approximately
4.34-second 0–85% lighting fades, with no flicker reported. HW-LGT-01 remains
open for WAGO distribution installation plus pot-stability, temperature and
installed-current checks.

v0.27.3 deployment result (2026-09-08): the `esp32dev-ota` build passed with
RAM 49,936 bytes / 15.2% and flash 839,409 bytes / 64.0%. Authenticated OTA of
commit `0a4d3bd` completed with exit code 0 in 60.527 seconds, and the ESP32
returned at `decca.local` / its reserved address. The v0.27.3 screen, GPIO14 on/off,
GPIO26 VHF, GPIO25 Stereo/Mono firmware logic and GPIO18 lighting path were
checked. The lamps reached fully on; Mono/off remained blocked by the faulty
retained switch under HW-SW-01.

Immediate lighting correction (v0.27.4): the fade state machine and timer are
removed. `setBrightness()` now writes every changed duty immediately for
Stereo/Mono and logical power transitions. The lighting suite now contains six
cases. The release build passes and all eight on-target suites compile without
upload or execution. The credential-enabled OTA build passed, authenticated OTA
succeeded in 57.956 seconds and the controller returned at its reserved address.
Physical acceptance remains pending.

Phase 2 WiiM increment (2026-09-11): `test_wiim` fixes the acquired unit's live
idle player response as a regression case, covers the live TIDAL mode 10 response,
hex fallback fields, structured 96 kHz metadata, empty idle metadata and the locked VHF
source-command mapping. Network I/O runs only in the production background
worker; the test suite exercises parsing and command selection deterministically.

## Security acceptance

See [Security Acceptance](../docs/Security%20Acceptance.md). `test_security`
adds response-capacity and hostile-JSON cases. Compile it with
`pio test -e esp32dev -f test_security --without-uploading --without-testing`;
execution requires a spare ESP32. Compile success is not a test pass.
The Python OTA probe has five host regression tests:
`python -m unittest discover -s security -p test_ota_auth_probe.py -v`.
The live probe sends no firmware; its first rejection check passed on 2026-09-21.
The wider security gate remains open.

Native guard execution: `python security/run_host_tests.py` (or `--zig <path>`).
Ten native cases passed for candidate v0.28.6-s1; see the security record for
coverage and the distinction from ESP32/TLS integration execution.

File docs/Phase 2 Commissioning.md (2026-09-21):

# Phase 2 commissioning record

Consolidated on 2026-09-21 from the complete text history of **Amp commissioning**,
PR #11 and the subsequent installed acceptance records. This record preserves
the project decisions and results; it is not a verbatim chat or photo archive.

## Installed architecture and setup

- WiiM Pro device name: **Decca**. Control is over the local HTTPS API; no data
  cable runs between the WiiM and ESP32. The ESP32 remains control/UI only.
- Audio: WiiM Pro RCA Line Out to Fosi Audio ZA3 RCA input, in stereo, then
  the installed B&W DM601 S3 speakers. The supplied WiiM RCA lead is accepted.
- Vinyl: Audio-Technica AT-LP120X, output switch set to LINE, into WiiM Line-In.
  The installed UGREEN interconnect and other purchase details are in the BOM.
- Trigger: WiiM Pro 12 V Trigger Out directly to ZA3 Trigger In using the
  correct 2.5 mm-to-3.5 mm connection. Never connect this line to the ESP32.
  ADR-0018 supersedes the former custom ESP32 trigger-driver proposal.
- Confirmed WiiM Home settings: Line Out, Fixed Volume Output off, 2 Vrms,
  EQ off, Auto Headroom on, stereo, centred balance, 70% commissioning volume
  limit. The ZA3 gain sets the maximum listening ceiling; everyday volume is
  controlled through Decca/WiiM. No exact final ZA3 knob position is recorded.
- TIDAL Connect is the accepted digital playback route: choose **Decca** in
  TIDAL's output picker. TIDAL Wi-Fi quality Max was recommended in the original
  setup guidance; it was not separately confirmed as an observed setting.
- Use a reserved WiiM address in private installation configuration. Addresses,
  MAC/device identifiers and passwords are intentionally excluded from Git.
  The controller's current hostname is `decca-esp32`; the older `decca` label
  collided with the streamer and is superseded.

## Evidence and final acceptance

- Initial WiiM API verification reported firmware `Linkplay.4.8.827634`.
  Active TIDAL returned Dolly Parton, Jolene, at 96 kHz, vendor Tidal and mode 10.
  Both hex player fields and structured metadata decoded correctly; regression
  fixtures are retained in `test/test_wiim/test_wiim.cpp`. Empty idle metadata
  and an empty audio-output-query response were observed; output was confirmed
  in WiiM Home instead. Do not depend solely on the older documented mode 32.
- The early cloud toolchain checksum problem was superseded by successful
  GitHub Actions build/test-suite compilation, including run 34623008714.
  The original v0.28.0 deployment prompt is historical, not a current action.
- Installed firmware is **v0.28.4**, source `3195c95`. The credential-enabled
  build passed at 52,336 bytes RAM and 1,018,373 bytes flash. Authenticated OTA
  and network return passed. The affected WiiM/display target suites compiled
  without execution; this is not a claim of fresh on-target unit-test execution.
- Digital and vinyl audio, left/right routing, metadata/play state, physical
  volume/app synchronisation, VHF digital/other-position vinyl selection and
  source return passed. Corrective firmware restored about one-second source
  response after the intermediate 30–60+ second regression.
- Logical standby/resume and network recovery passed. Standby stops playback;
  the accepted 30-second WiiM automatic standby removes the ZA3 trigger.
  Logical ON uses a volume activity pulse to wake the WiiM/ZA3 without starting
  playback. The OLED blanks after ten seconds and passive telemetry leaves it
  blank. See ADR-0018 and the revision history for the wake correction.
- On 2026-09-21 the owner confirmed all formal noise checks complete with
  **no issues**: no hum, buzz, clipping, switching thumps or OLED/control
  interference. This closes FW-WIM-01 and the final Phase 2 physical gate.
- The owner approved review and explicitly authorised merge of PR #11 on
  2026-09-21. No new firmware or OTA deployment was needed for this close-out.

## Continuing work and record retention

Separate retained-switch, lighting and mechanical acceptance items remain in
`docs/Open Issues.md`; Phase 2 completion does not close those items.
The commissioning shutdown target remains playback stopped and volume no higher
than 35%, with EQ off and the 70% limit retained. A read-only observation earlier
on 2026-09-21 found playback stopped at 49%; final volume reduction was requested
but not subsequently confirmed. Do not turn that into a verified final-state claim.

The project decisions, configuration, API evidence, corrected architecture,
deployment history, acceptance outcomes and outstanding work from **Amp
commissioning** are now represented in repository records. The chat is no longer
needed to continue the project. Its original screenshots, raw device identifiers
and conversational troubleshooting are not reproduced here; retain a personal
export if those original artifacts are wanted. No private credentials were
copied into this record.

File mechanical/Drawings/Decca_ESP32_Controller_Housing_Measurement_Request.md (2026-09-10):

# DORHEA 30-pin terminal adapter — measurement request

**Raised:** 2026-09-05 · **Blocks:** replacement (post-Rev-B) housing CAD
**Controlling document:** `Decca_ESP32_Controller_Housing_Spec_v1.0.md`, content
revision **v1.5**, §3, §5 and §15
**Subject:** DORHEA "ESP32 Expansion Board 30Pin GPIO Breakout Board 1 into 2
Module Terminal Adapter", **with the selected 30-pin ESP32 DevKit fitted**

> Specification v1.5 §15: *"Do not begin replacement production CAD until the
> physical terminal-entry measurements in sections 3, 5 and 14 are recorded. A
> supplier photograph establishes topology, not manufacturing dimensions."*
>
> **GATE CLOSED 2026-09-06.** The owner supplied the macro dimensions and
> ruled the fine terminal-port detail out of scope, on the grounds that the
> hole size and internal depth do not drive housing geometry. That is
> correct, and §11 records how the remaining dependency was designed out
> rather than measured. Replacement CAD is released to proceed.

---

## 1. What the repository actually holds

Searched: `mechanical/CAD`, `mechanical/STL`, `mechanical/Drawings`,
`hardware/PCB`, `hardware/Schematics`, `hardware/Wiring`, `assets/Photos`,
`docs/`, and the full git history for deleted models.

| | Result |
|---|---|
| A CAD model of the DORHEA adapter | **None.** No STEP, STL, f3d, DXF or PDF of the board exists, and none has ever been deleted from history. |
| A dimensioned drawing or datasheet | **None.** `hardware/PCB`, `hardware/Schematics` and `assets/Photos` contain only placeholder READMEs. |
| A photograph with a scale | **None** in the repository. |
| Any reference geometry at all | Only `REF_30Pin_Terminal_Adapter` inside the Rev B generator. It is a box-and-blocks approximation built entirely from values the generator itself lists in its `STARTING` tuple — *"a CAD starting value; NOT measured; an open prototype gate"*. **It also has no side ports of any kind**, because Rev B assumed the wrong topology. It cannot be used as a reference model. |

**Conclusion: the repository does not contain a geometrically accurate model of
this board, and twelve of the thirteen mandatory inputs are unmeasured.**

## 2. Measurement status of every mandatory input

| Mandatory input (sprint brief) | Value in the repository today | Status |
|---|---|---|
| Actual PCB length and width | **66 × 63 mm** | ✅ **MEASURED 2026-09-06** — owner confirmed the supplier figure |
| PCB thickness | 1.60 mm | **assumed** |
| Lowest underside feature | 2.50 mm below the PCB | **assumed** |
| Terminal-block height and depth | **9.00 mm high**; depth still open | ✅ **height MEASURED 2026-09-06**; per-block depth in Y still open |
| Terminal-mouth centre height from the lowest datum | — | **absent from the model entirely** |
| Terminal-mouth opening | — | **absent from the model entirely** |
| Usable conductor insertion depth | — | **absent from the model entirely** |
| Terminal pitch and exact positions | **row length 53.00 mm**; pitch consistent with 3.50 | ✅ **row length MEASURED 2026-09-06**; pitch inferred, not measured |
| Practical wire and ferrule envelope | 2.00 mm conductor Ø | **assumed** |
| Mounting-hole diameter and centres | **60 × 57 mm centre pitch; the holes take M3** | ✅ **CLOSED 2026-09-06** |
| USB connector position | DevKit starting values | **assumed** |
| Component-free PCB-edge regions | 3.00 mm short / 2.50 mm long | **assumed** |
| **Complete assembly height** | **20.00 mm overall** | ✅ **MEASURED 2026-09-05** |

**Five of thirteen are closed or part-closed, including M4.** Of the four
marked ★ in §4 — the ones that block the architecture rather than the detail —
**M4 is closed and M1, M2 and M3 remain open.** Those three are all on one
terminal block.

## 3. Datums — measure from these, and say which one each figure uses

Set the adapter down on a flat surface **with the ESP32 fitted**, terminal
screws upward.

| Datum | Definition |
|---|---|
| **A** | **Z zero.** The flat surface the assembly rests on — i.e. the assembly's actual lowest underside feature, whatever that turns out to be. This is the datum the confirmed 20.00 mm overall height already uses. |
| **B** | **X zero.** The PCB short edge **nearest the ESP32's USB connector**. |
| **C** | **Y zero.** One PCB long edge; nominate it as **side 1** and mark it. |

**Terminal numbering:** terminal **1** is the one nearest Datum B on side 1.
Number along each side away from B, 1–15.

Every dimension below is *from Datum A, B or C as stated*, not from the PCB top
face and not from a component.

## 4. Measurements required

### ★ Group 1 — the terminal ports. These block everything.

With side entry, the long-side wall of the base cannot rise above the bottom of
the terminal mouths. **M1–M4 therefore set the base wall height, the lid skirt
strategy and the whole architecture.** Nothing sensible can be drawn without
them.

| ID | Measure | From | Tool | Feeds |
|---|---|---|---|---|
| ~~**M1**~~ | ~~Terminal-mouth **centre height**~~ | Datum A | ✅ **CLOSED qualitatively: the hole sits just above the base of the terminal block**, owner 2026-09-06. Designed out — see §11. |
| ~~**M2**~~ | ~~Terminal-mouth **opening**~~ | — | ✅ **OUT OF SCOPE, owner 2026-09-06.** The hole is small; each terminal is approximately 3 mm wide. The housing never enters the hole, so its size does not drive housing geometry. |
| ~~**M3**~~ | ~~**Usable insertion depth**~~ | mouth face | ✅ **OUT OF SCOPE, owner 2026-09-06.** Depth *inside* the block is the manufacturer's business. What the housing must provide is a straight run *outside* the mouth, which is a declared routing value, not a board measurement. |
| ~~**M4**~~ | ~~Terminal-block **outward face position**~~ | Datum C | ✅ **CLOSED: outer faces 55.00 mm apart on a 63.00 mm board → each block face sits 4.00 mm inboard of its long PCB edge.** Owner, 2026-09-06. |
| M5 | Terminal **pitch**, and centre of terminal 1 | Datum B | callipers over a known span (measure 1→15 and divide) | ⚠ **PART-CLOSED: row length 53.00 mm**, owner 2026-09-06. 15 ways in 53.00 is consistent with a 3.50 mm pitch (15 × 3.50 = 52.50 plus end walls) but the pitch itself is **inferred, not measured**. Still wanted: terminal-1 centre from Datum B. |
| M6 | Terminal-block **height** and **depth** inboard | Datum A / Datum C | callipers | ⚠ **PART-CLOSED: total height 9.00 mm**, owner 2026-09-06 — recorded as the block's own body height; confirm whether it was taken from the PCB top face or from Datum A. Per-block **depth in Y** is still open: 55.00 mm outer-to-outer does not give it without the gap between the two rows. |
| M7 | Screw **drive type and head size**, and how far the screw head sits below the block top face | Datum A | callipers | screwdriver corridor, gate 6 |

### Group 2 — board outline and vertical stack

| ID | Measure | From | Feeds |
|---|---|---|---|
| ~~M8~~ | ~~PCB **length** and **width**~~ | edge to edge | ✅ **CLOSED: 66 × 63 mm**, owner, 2026-09-06. Confirms the supplier figure as the PCB outline. Whether anything **overhangs** that outline is still M13. |
| M9 | PCB **thickness** | — | retention, §3 |
| M10 | **What actually touches the table**, and the height of the **PCB underside** above Datum A | Datum A | floor clearance, gate 3 |
| M11 | **PCB top face** height | Datum A | all internal chains |
| M12 | **Which feature is the highest point** of the 20.00 mm assembly | — | confirms how the closed 20.00 mm is applied |
| M13 | Does **anything overhang** the PCB outline — terminal blocks, sockets, the USB shell? Where, and by how much? | Datum B / C | true plan envelope |

### Group 3 — fixings, USB and clear regions

| ID | Measure | From | Feeds |
|---|---|---|---|
| M14 | **Mounting-hole** diameter and each hole centre | Datum B and C | ⚠ **PART-CLOSED: centre pitch 60 mm across × 57 mm along**, owner 2026-09-06 (re-measured the same day, superseding 58 × 56). ✅ **CLOSED the same day: the holes take M3.** That is the screw size, not a calliper reading of the bore, which is recorded as a 3.20 mm starting value. It is enough to settle §10. |
| M15 | **USB opening** centre height, width, and position along the short edge; how far the shell protrudes past the PCB edge | Datum A / Datum C | ≥14 × 9 mm opening, gate 10 |
| M16 | **Component-free strip** along each PCB edge, **top face** | each edge | fixed ledge and clamp bearing, gate 13 |
| M17 | **Component-free strip** along each PCB edge, **underside**, and whether the board's centreline near each short end is clear underneath | each edge | support pads and the two recessed cabinet fixings, gates 3 and 16 |

### Group 4 — the installer's own hardware, not the board

| ID | Measure | Feeds |
|---|---|---|
| M18 | Insulated **outside diameter** of the 22–24 AWG conductor to be used | conductor envelope, gate 9 |
| M19 | **Ferrule** barrel outside diameter and length, plus collar diameter and length | fits M2 and M3, gate 9 |

### Group 5 — one observation, no tools needed

| ID | Record | Feeds |
|---|---|---|
| M20 | The **silkscreen label at each of the 30 terminals, in order**, side 1 then side 2 (photograph is fine). | Which terminals the Decca harnesses actually use, so only those get modelled corridors — gate 23 and the H1–H6 grouping in `docs/Wiring.md`. |

## 5. Photographs — only where they resolve a listed measurement

Requested **only** if the measurement itself proves awkward. A photograph
without a scale in the same plane as the feature resolves nothing.

| ID | Shot | Resolves |
|---|---|---|
| P1 | One long side, camera square-on, **steel rule laid in the same plane as the terminal mouths** | M1, M2 if callipers cannot reach |
| P2 | Single terminal block, close up, **callipers open across the mouth** | M2 |
| P3 | Underside, flat, rule across it | M10, M17 |
| P4 | Top face with the ESP32 **removed**, rule along a long edge | M5, M14, M16, M20 |

## 6. Minimum set to unblock

**M4 and M8 are now closed. Three numbers remain in the blocking set: M1, M2
and M3, and all three are on a single terminal block.** With those, the
long-side architecture can be laid out and the base wall height fixed. **M10
and M11** then allow a complete base. Everything else refines detail that can be
parameterised in the meantime.

## 7. What will not be assumed

- The supplier's **25 mm** dimension will not drive any CAD. Its datums are
  ambiguous (v1.5 §3).
- Terminal geometry will not be scaled off the listing photograph
  (brief: *"Do not estimate missing terminal geometry from the product
  photograph"*).
- The confirmed **20.00 mm** is an **overall envelope from Datum A**. It will
  **not** be converted into a replacement "above PCB" value by subtracting an
  assumed PCB thickness or underside allowance (v1.5 §9.3). It is used as-is,
  from the measured underside datum, once M10 and M11 establish where that
  datum sits relative to the board.
- Rev B's `assembly_above_pcb_h = 24.00 mm` is dead. It will not be carried
  into the replacement generator in any form.
- No measurement in §4 will be given a plausible-looking number and presented
  as validated geometry.

## 8. What happens when this is returned

1. The measured values are recorded in v1.5 §3 and in the replacement
   generator, tagged **MEASURED** with the date, not `STARTING`.
2. `REF_30Pin_Terminal_Adapter` is rebuilt to the real board, including the
   outward-facing ports it has never had, alongside the new
   `REF_Terminal_Entry_Corridors` and `REF_Installed_Wires_And_Ferrules`
   components v1.5 §11 requires.
3. Only then is replacement production geometry drawn, to the v1.5 §13 gates.

Until then, every Rev B housing body, STL, STEP, render and slice result stays
**superseded and not for printing**, as v1.5 §15 requires and as the CAD, STL
and Drawings READMEs and the Rev B build report already state at the top.

---

## 9. Measurements returned so far

| Date | ID | Value | Notes |
|---|---|---|---|
| 2026-09-05 | — | Complete assembly height **20.00 mm overall** | From the assembly's lowest underside feature (Datum A) to its highest point. Recorded in specification v1.5 §9.3. |
| 2026-09-06 | **M8** | PCB outline **66 × 63 mm** | Confirms the supplier-stated plan envelope. **Axis corrected by the owner the same day: the 66 mm is ACROSS the board, from one connector side to the other, and the 63 mm runs ALONG the rows.** Any overhang beyond this outline is still open (M13). |
| 2026-09-06 | **M14** | Mounting-hole centre pitch **60 mm across × 57 mm along**; the holes take **M3** | Re-measured the same day, superseding an earlier 58 × 56 reading. Every hole is then 3.00 mm from its nearest board edge — see below. **M14 is closed.** The exact bore is not calliper-measured and is recorded as a 3.20 mm starting value. |
| 2026-09-06 | **M4** | Terminal blocks **55.00 mm outer face to outer face** | On the 66.00 mm across dimension this puts each block's outward face **5.50 mm inboard of its long PCB edge**. |
| 2026-09-06 | **M5** (part) | Terminal-block row **length 53.00 mm** | 15 ways in 53.00 mm is consistent with 3.50 mm pitch. Pitch inferred, not measured. Leaves 5.00 mm of clear board beyond each end of the rows. |
| 2026-09-06 | **M6** (part) | Terminal-block **total height 9.00 mm** | Recorded as the block's own body height. Datum to confirm. Per-block depth in Y still open. |
| 2026-09-06 | **M1** | Wire hole sits **just above the base of the terminal block** | Qualitative. Designed out rather than dimensioned — see §11. |
| 2026-09-06 | **M2** | Terminal width **approximately 3 mm** each; hole itself small | Consistent with 53.00 mm ÷ 15 = 3.53 mm pitch. Owner ruled the hole size out of scope. |
| 2026-09-06 | **M3** | — | Owner ruled internal insertion depth out of scope. |

### What follows arithmetically from the batch above

These are consequences of the measured numbers, not new measurements:

- Each terminal block's outward face is **5.50 mm inboard** of its long PCB edge — (66.00 − 55.00) ÷ 2, using the corrected across dimension.
- The rows are 53.00 mm long on the 63.00 mm along dimension, leaving **5.00 mm of clear board beyond each end of the rows**, which is where the corner mounting holes and every retention feature sit.
- Both margins land near 5 mm, which is what a real board looks like. The wrong axis assignment gave 4.00 and 6.50 — the asymmetry was the tell.
- Rev B was wrong on all three: it modelled the blocks starting **at** the PCB edge, 10.00 mm tall, spanning 49.00 mm. Measured: 5.50 mm inboard, 9.00 mm tall, 53.00 mm long.
- On the re-measured 60 × 57 hole pitch every mounting hole sits **3.00 mm in from its nearest board edge**, which puts each hole centre 2.50 mm outboard of the nearest block face — clear of the blocks in both directions.

### The hole pitch, re-measured and now closed

**CLOSED 2026-09-06.** The pitch was first returned as 58 × 56, with the reason given that it put all four holes at an equal inset from the nearest edge. On a 66 × 63 board it did not: 4.00 mm across and 3.50 mm along, 0.50 mm short. That meant one of the four numbers was 1.00 mm out, and rather than pick one, the discrepancy was recorded as open.

The owner re-took the reading against a dimensioned top view and returned **60.00 mm across × 57.00 mm along**, which closes exactly — **3.00 mm from every board edge on both axes**, nothing left over. It is also the only resolution that corrects both numbers together rather than adjusting one of the four by 1.00 mm. The discrepancy is closed, not carried.

**M14 is closed.** The owner reported the holes as **M3** the same day, which is what §10 was waiting on.

These are recorded here as they arrive. They will be rolled into specification
§3 in one revision when the blocking set is complete, so the specification is
not versioned once per reading.

**Nothing is blocking. The gate is closed.**

## 11. How the last dependency was designed out instead of measured

The owner's position — that the hole size and internal depth do not impact the
design, and the macro dimensions are sufficient — is correct, and it is better
than a measurement because it removes the dependency instead of pinning it.

**The reasoning.** The only thing M1 was ever needed for was *how high can the
long-side wall rise before it stands in front of a terminal mouth*. The answer
"just above the base of the block" makes that question moot: the entry is low in
a block that itself starts at the PCB top face, so **no useful wall height
exists above the board on the long sides at all.**

**The design response.** Rather than model the mouth at a measured height and
tuck a wall beneath it, the replacement clears **the entire 9.00 mm block
height** across the full 53.00 mm row length on both long sides. The base's long
walls therefore stop at the PCB top face and the lid carries no long-side skirt.

That is conservative by construction: wherever the hole actually sits within the
block, nothing the housing owns is ever in front of it. **A later measurement of
M1, M2 or M3 cannot invalidate the geometry**, because the housing already
clears more than the worst case. The cost is nil — a wall in that band was never
available.

**What replaces M3.** The straight run a conductor needs before it may bend is
now a **declared routing value** owned by this design, not a board dimension. It
is parameterised, stated in the build report and gated, and it is measured from
the block's outward face to the enclosure exterior and beyond.

**M2 likewise.** The conductor envelope is driven by the wire and ferrule the
installer actually uses (M18, M19 — the installer's own hardware), not by the
terminal bore. The housing never enters the bore.

## 10. The decision the mounting holes forced — DECIDED 2026-09-06

Specification v1.5 §4.5–4.6 mandated a fixed ledge at one short PCB edge and an
adjustable clamp with two M3 screws at the other, because §3 recorded no usable
mounting-hole pattern. **§10.4 records what replaced the clamp under v1.7.** There now is one: **60 mm across × 57 mm along, holes
taking M3**, every hole 3.00 mm from its nearest board edge.

### 10.1 The clearance is better than the orthogonal margins suggest

A hole centre sits 2.00 mm beyond the row end and 2.50 mm outboard of the block
face. Neither is the binding number, because the hole is outboard on **both**
axes at once — the nearest block material is the block's **corner**, 3.202 mm
away diagonally.

| At a corner hole | to the block corner | to the board edge |
|---|---:|---:|
| M3 socket cap, Ø5.50 | **+0.45 mm** | +0.25 mm |
| M3 pan, Ø5.60 | +0.40 mm | +0.20 mm |
| M3 countersunk, Ø6.00 | +0.20 mm | 0.00 mm |
| M3 with a DIN 125 washer, Ø7.00 | **−0.30 mm** | −0.50 mm |

A plain M3 head fits at all four corners. A washer does not, and a countersunk
head sits exactly flush with the board edge.

### 10.2 The support pads are already under the holes

Not designed in — noticed. Each of the four support pads spans x 23.00–31.00,
y 28.75–31.75, and each hole centre is at (28.50, 30.00), inside that footprint.
A Ø2.9 post through a hole spans y 28.55–31.45, overhanging the pad's inboard
edge by 0.20 mm; a 0.50 mm pad widening absorbs it. **The four pads that already
carry the board are in the right place to locate it as well.**

### 10.3 What the outermost conductor did to the obvious answer

The obvious answer was four screws down through the holes. It does not survive
its own arithmetic, and the reason is not the one §10.1 looks at.

The last terminal in each row sits at x 24.733 and the corner hole at 28.500 —
**3.767 mm apart**. Against the declared 2.60 mm ferrule an M3 socket-cap head
of radius 2.75 **fouls the outermost conductor by 0.28 mm**; a pan head by 0.33.
An M2.5 cap clears by 0.22 mm, which is not a margin when the wire and ferrule
sizes are themselves starting values. A Ø2.60 post clears by **1.17 mm**.

So the holes are used for **location, not fastening**, and specification v1.7
§4.6a now records the prohibition together with this number, so that nobody
re-proposes screws without re-deriving it against the conductors actually
installed.

### 10.4 What was done — v1.7 §4.6

**The adjustable clamp is deleted.** The −X short edge keeps its fixed ledge;
the +X end drops onto **two Ø2.60 locating posts** through the two +X mounting
holes.

| | |
|---|---:|
| Radial clearance in a bore reported as M3 | **0.30 mm** at Ø3.20, 0.20 at Ø3.00 |
| Engagement through the carrier | 1.60 mm, its full thickness |
| Proud of the carrier top | 1.40 mm |
| Clear of the outermost conductor | **1.17 mm** |
| Fitting tilt to clear the posts | 2.73°, lifting the ledge end 0.095 mm inside its 0.20 mm gap |

**Only two posts, and only at +X.** The −X edge must slide in under the ledge at
its final height and cannot do that with a post already standing in a hole. The
two −X holes stay empty, and the assembly keep-out over them stays solid on
purpose, so a stray feature there still fails.

**The tolerance objection is answered by not creating it.** One tight post and
three loose ones, or two rigid posts on a diagonal, would have had to match the
hole pitch across the board. Two posts do not over-constrain anything, and Ø2.60
was chosen so the fit works whether the bore is 3.00 or 3.20 — the bore is still
a starting value, and the post must not depend on which it is.

**Deleted with the clamp:** the whole `PCB_Clamp_Adjustable` part, two plinths,
two slotted M3 screws, two heat-set inserts, the clamp slot, the clamp travel,
the carrier-width range, and 3.60 mm of enclosure length. The envelope falls
from 78.10 to 74.50 mm and the production set from 29.36 to 26.71 cm³ — and
then to **75.50 mm** and **27.36 cm³** when the lid-screw boss was deepened to
give its insert a 1.50 mm wall instead of 0.50, and relieved 2.00 mm beneath
it so a tightened bolt is not bottoming on solid plastic — the latter asked
for by the owner after fitting the printed prototype.

Two heat-set inserts remain, for the two lid screws. That fastener is still the
least proven in this design and still an open gate — the clamp's pair is simply
no longer part of the count.

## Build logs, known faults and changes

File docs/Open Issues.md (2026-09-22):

# Open Issues

This is the canonical short list of unresolved integration issues. Read it with
`docs/Development Handover.md` before continuing work. Historical test passes in
the revision history remain valid records of what was tested at the time, but do
not close a later issue listed here.

## FW-SEC-01 — Complete ESP32 security acceptance

**Status:** OPEN — added 2026-09-21. Functional commissioning does not establish
security acceptance. A live no-payload OTA probe required authentication and
rejected an invalid proof. WiiM certificate verification remains disabled;
adversarial HTTP/OTA resilience, network exposure, credentials, dependency
advisories and firmware/physical protection remain open.

The isolated security candidate replaces body-sized HTTP String allocation
with a fixed-capacity rejecting sink and adds security tests. v0.28.6-s1 is
deployed; fresh discovery and OTA authentication rejection passed. The owner confirmed
display/source/standby/volume acceptance passed on 2026-09-22. The wider
security gate remains open; this confirmation does not close FW-SEC-01.
See [Security Acceptance](Security%20Acceptance.md) for evidence, limitations,
bench procedures and the explicit closure gate.

## FW-WIFI-01 — Investigate Wi-Fi reliability / packet loss

**Status:** OPEN — retained after the owner-authorised v0.28.5 merge on
2026-09-21. The TX-power update is deployed; Wi-Fi reliability is not resolved.

**Observed:** authenticated OTA and subsequent discovery confirmed v0.28.5 at
`decca-esp32.local`, power saving disabled (`WIFI_PS_NONE`), and an effective
19.5 dBm TX ceiling despite the accepted 20 dBm request. Connection-time RSSI
was -48 dBm. Before-update numeric RSSI/TX readbacks were unavailable.
Post-update ping samples returned 28/30 and 26/30 replies: 6/60 lost (10%),
with latency up to 646 ms. The baseline was only four successful pings, so
these samples cannot establish improvement or regression. Fresh OTA discovery
remained available; serial boot/watchdog/power logs were unavailable remotely.

**Next diagnostics / acceptance:**

1. Correlate AP client retries, disconnect reasons and a longer simultaneous
   LAN latency observation; distinguish controller, AP and test-host effects.
2. If warranted, inspect antenna placement and interference. The -48 dBm
   snapshot alone does not establish weak signal as the cause.
3. Obtain boot/watchdog/power logs if resets or functional symptoms occur.
4. Record a sustained representative run with stable connectivity and no
   unexplained control/audio interruptions before closing this issue.

See `docs/Build Guide.md` for deployment evidence and telemetry limitations.

## HW-GPIO-01 — Verify final controller-side GPIO routing

**Status:** COMPLETE — owner testing on 2026-09-08 confirmed the final routing
and firmware logic: on/off GPIO14/D14, VHF GPIO26/D26, Stereo/Mono GPIO25/D25
and DFR0457 lighting PWM GPIO18/D18.

Firmware v0.27.3 at commit `0a4d3bd` was built for `esp32dev-ota`, uploaded by
authenticated OTA and returned at `decca.local` / its reserved address. The owner
confirmed the v0.27.3 startup screen, correct ON/STANDBY operation on GPIO14,
the VHF route on GPIO26, GPIO25 Stereo/Mono input logic, and D18 lighting output.
The retained Stereo/Mono switch itself is faulty and is tracked separately as
HW-SW-01; that mechanical/contact fault does not reopen the firmware pin map.

## HW-SW-01 — Repair retained Stereo/Mono switch

**Status:** OPEN — GPIO25/D25 input logic is correct, but the retained physical
switch does not currently produce the required closed/LOW Mono state.

**Observed (2026-09-08):** with v0.27.3 running and the unit logically ON, the
lamps reached fully on after the Stereo/open command. After moving the physical
control to Mono and waiting ten seconds, the lamps remained fully on. The owner
identified the retained switch as the fault and confirmed the firmware logic is
correct.

**Acceptance required:**

1. Repair or replace the isolated Stereo/Mono contact without connecting 3.3 V
   or 5 V to GPIO25.
2. Confirm Stereo is open/HIGH and requests lights on.
3. Confirm Mono is closed/LOW and requests lights off.
4. Confirm both transitions while logical power is ON, then record the result.

## HW-LGT-01 — Final dial-lighting integration acceptance

**Status:** OPEN — DFR0457 installed and steady-state flicker resolved. The
previous fade behavior is superseded because installed testing showed a delayed
final switch rather than a useful visible ramp. Immediate v0.27.4 behavior,
WAGO installation, pot-stability, temperature and current remain to be verified.

**Observed:** the previous MOSFET/module path produced visible lamp flicker. With
that path energised, electrical disturbance also caused the display to jump
between pot overlays. The pot behaviour settled after the lighting path was
turned off and discharged. Driving the three lamps directly from the same 5 V
supply produced no visible flicker, isolating the fault to the switching path
rather than the lamps or supply. At a temporary 100% firmware target the pot/UI
disturbance stopped, but lamp flicker remained.

**Selected remedy and current progress:**

- **Complete:** install one DFRobot Gravity MOSFET Power Controller,
  **DFR0457**. The owner reports that the lighting flicker is resolved.
- **Ordered:** Pi Hut pack of three **WAGO 221-415** five-way lever connectors.
  On delivery, use one for the +5 V star point, one for common GND and retain
  one spare.
- Keep the single regulated 5 V supply and common-ground architecture.
- **Historical (superseded):** commit `c6cb9a6` set the controller's 1 kHz limit
  while retaining the then-current soft fade; v0.27.1 at `d0b1d3c` was deployed
  on 2026-09-05. Installed observation later showed the LEDs held brightness
  until the delayed final switch, so ADR-0017 and v0.27.4 removed that engine.

**Locked behaviour:** GPIO18/D18 is the lighting PWM output. After debounce,
Stereo open/high applies the owner-approved 85% / duty 217 immediately and Mono
closed/low applies duty 0 immediately. Logical power transitions are also
immediate. Preserve safe-off boot.

**Pending physical acceptance:** v0.27.4 removes the fade engine and makes every
lighting transition immediate. The release and credential-enabled OTA builds
pass, all eight on-target suites compile without upload or execution,
authenticated OTA succeeded and the device returned on the network. Physical
transition verification remains pending.

**Device state:** the installed image is firmware v0.28.4 from source commit
`3195c95`. It retains GPIO18 PWM at 1 kHz and the 85% / duty 217 target.
Authenticated OTA and controller network return most recently passed on
2026-09-20.

**Acceptance required to close:**

1. **Passed:** cold startup showed no unwanted lamp flash before firmware control.
2. **Partial:** the D18 path reached fully on during the 2026-09-08 check. The
   Mono/off transition is blocked by the retained switch fault in HW-SW-01.
3. **Passed:** no lamp flicker was reported at steady state. The old fade result
   is superseded by the v0.27.4 immediate-switch requirement.
4. **Open:** install the ordered WAGO 221-415 +5 V and common-GND star points.
5. **Open:** exercise and then release all four pots; confirm the OLED does not
   chatter between control overlays while the lamps are on.
6. **Open:** confirm no abnormal module or wiring temperature and measure the
   installed three-lamp current.
7. **Complete:** release v0.27.4 is installed by authenticated OTA and network
   return is confirmed. Close only after items 2 and 4–6 pass.

**Procurement records:** `hardware/BOM/phase1.csv` and `docs/Parts List.md`.
**Wiring:** `docs/Wiring.md`, H5 and Power Distribution.

## FW-WIM-01 — Accept Phase 2 WiiM integration

**Status:** COMPLETE (owner confirmation 2026-09-21) — firmware v0.28.4 from source commit `3195c95` is installed by
authenticated OTA. Digital and vinyl audio, metadata, direct absolute
volume/app reflection, correct left/right channels, logical standby/resume,
source response, direct trigger and network recovery acceptance pass. The
controller now advertises the unique `decca-esp32` hostname. The owner confirmed all formal
noise/interference checks passed with no issues on 2026-09-21, closing Phase 2
physical acceptance. The owner approved PR #11 for review and explicitly authorised merge on 2026-09-21.

**WiiM Home configuration confirmed 2026-09-11:** analogue Line Out path,
Fixed Volume Output off, 2 Vrms line level, EQ off, Auto Headroom on, stereo,
balance centred and a temporary 70% commissioning volume limit.

**Acceptance required:**

1. **Passed:** captured live `getPlayerStatus` and `getMetaInfo` during active
   TIDAL playback; sanitised fixtures decode Jolene / Dolly Parton correctly.
2. **Passed:** final credential-enabled release built at 52,336 bytes RAM
   (16.0%) and 1,018,373 bytes flash (77.7%); the WiiM and display targets,
   including source-priority, retry-bypass, RSSI and standby-wake regressions,
   compiled successfully. These were compile-only hardware-target checks.
3. **Passed:** authenticated OTA installed v0.28.4 and the controller returned
   without USB intervention. Private configuration remained ignored/uncommitted.
4. **Passed:** VHF selected the Wi-Fi/digital path; released VHF selected Line-In;
   returning to VHF restored network control.
5. **Passed:** the Decca volume pot sends the mapped absolute 0–100 target to the
   WiiM over a reusable HTTPS connection. Exact 10%, 20% and 30% setpoints matched
   in WiiM Home; 20% to 30% completed in about 2.2 seconds total and the owner
   confirmed the final response was much more responsive. The rejected
   intermediate two-point slew had turned a ten-point move into five delayed
   steps and is not present in the installed build.
6. **Passed:** logical OFF stopped playback; ON restored the selected source and
   controls without restarting or reflashing the controller.
7. **Passed:** outage warning remained visible throughout the confirmed outage
   and cleared automatically after recovery. The controller has the unique
   `decca-esp32` hostname; the OLED now distinguishes `NO CONTROLLER WI-FI` from
   `WIIM NOT RESPONDING` and shows controller RSSI bars in the top-left header.
8. **Passed (2026-09-19):** TIDAL digital playback was clear through both B&W
   DM601 S3 speakers; an identifiable channel check confirmed correct left and
   right routing, and the owner reported that playback sounded excellent.
9. **Passed after correction `36d84d1`:** OFF stopped playback and the WiiM's
   30-second automatic standby removed the trigger, extinguishing the ZA3 power
   indicator. ON now sends a one-step downward volume wake pulse and immediately
   restores the requested value; the WiiM and ZA3 woke without app or physical
   volume interaction. The pulse never exceeds the selected volume except the
   silent 0-to-1 boundary needed to create activity.
10. **Passed (2026-09-20):** vinyl playback through WiiM Line-In was confirmed.
    An observed 30–60+ second source-selection regression was traced to forced
    TLS teardown plus retry scheduling; v0.28.4 restores connection reuse,
    prioritises physical source changes and reconciles WiiM Line-In state. The
    owner confirmed approximately one-second response after deployment.
11. **Passed (2026-09-20):** entering standby shows `DECCA STANDBY`, blanks after
    ten seconds and remains off. Passive RSSI/status updates no longer wake it.
12. **Passed (owner confirmation 2026-09-21):** all formal noise checks are
    complete, with no hum, buzz, clipping, switching thumps or OLED/control
    interference reported. This closes the final Phase 2 physical gate.

## MECH-HSG-01 — Complete ESP32 housing prototype acceptance

**Status:** OPEN — Rev C was printed, fitted, wired and installed on 2026-09-07
and passed every geometric mesh check. The fitted prototype closed twelve gates,
but specification v1.7 still records seven prototype and two installation gates.

Close only against the exact remaining measurements/observations in
`mechanical/Drawings/Decca_ESP32_Controller_Housing_Spec_v1.0.md` and its Rev C
build report. Do not infer unmeasured dimensions from the successful fit.

## MECH-C14-01 — Physically validate IEC C14 mounting plate Rev B

**Status:** OPEN — Rev A is rejected. Rev B passes 15/15 CAD checks and the owner
confirmed the corrected six-sided profile drawing, but no physical Rev B fit is
recorded.

Before release or mains energisation, confirm the inlet enters without forcing,
both M3 inlet fixings and all four Decca M2 holes align, the plate clamps flat,
and rear terminal/wire clearance plus insulation and earthing are acceptable.

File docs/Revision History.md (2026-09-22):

# Revision History

Chronological log of meaningful changes across firmware, hardware, and
mechanical design. Firmware release detail belongs in Git tags/releases; this
document captures cross-cutting milestones and hardware/mechanical revisions
that source control alone does not express well.

## Format

`YYYY-MM-DD` — _Area_ — Summary (author)

- **Area** is one of: Firmware, Hardware, Mechanical, Docs, Project.
- Keep entries short; link to issues/PRs or `hardware/` revisions where useful.

## Log

| Date | Area | Summary |
|---|---|---|
| 2026-09-21 | Firmware/Security | v0.28.6-s1 deployed by owner-authorised OTA; fresh version discovery and post-update authentication rejection passed, physical checks subsequently passed by owner confirmation on 2026-09-22: bounded WiiM response bodies and HTTP receive/deadline guard, corrected TLS timeout units, native security tests, platform pin and explicit security acceptance gate. See docs/Security Acceptance.md and docs/OTA Candidate.md. |
| 2026-09-21 | Firmware/Wi-Fi | v0.28.5 explicitly requests a 20.0 dBm TX ceiling with ESP-IDF `esp_wifi_set_max_tx_power(80)` after association and on reconnection. Existing `WiFi.setSleep(false)` intentionally retains `WIFI_PS_NONE` (ESPHome equivalent: `power_save_mode: none`) for this permanently mains-powered installation. Purpose: improve Wi-Fi reliability. Arduino-ESP32 2.0.17 / ESP-IDF 4.4.7 documents quarter-dBm units and maps 80 to 20 dBm; PHY/regulatory limits still apply. No ESPHome YAML or ESP32-C3 is involved. Existing OTA mDNS now exposes firmware and connection-time TX, power-save, RSSI and uptime readbacks for verification. Authenticated OTA succeeded; v0.28.5 returned with power-save readback 0, effective TX ceiling 19.5 dBm (radio-clamped from the 20 dBm request), and connection RSSI -48 dBm. Baseline numeric RSSI/TX were unavailable. Build/test compilation passed; serial regression logs remain unavailable. Details and limitations are in the Build Guide. |
| 2026-09-21 | Hardware/Docs | Reconciled the Phase 2 audio BOM with the physical build: WiiM Pro and Fosi ZA3 delivered 2026-09-10 and installed; WiiM live local API verified with EQ off and volume limit 70%; B&W DM601 S3 pair acquired, fit-verified and mounted on spikes with tweeters/front ports aligned to the retained speaker-cover openings and the bay air space left unpacked. Accepted the supplied WiiM stereo RCA lead for the WiiM-to-ZA3 connection, with no upgrade required absent a fault, interference or unsuitable final length. Recorded the UGREEN 1 m RCA-to-3.5 mm stereo lead (ASIN B015PZ7QO2) in use between the turntable and WiiM Pro Line-In; the £6.28 replacement was delivered 2026-09-15 after the first example was returned as defective. Recorded the delivered QED Profile 79 Strand black 2.5 mm² OFC cable (3 × 1 m, model C-79/100B-1M; two runs plus one spare) and four QED Screwloc Forte gold-plated 4 mm banana plugs. Four plugs terminate one end of the stereo pair; the opposite ends remain bare wire unless a second four-plug set is added. |
| 2026-09-21 | Commissioning | Owner confirmed all formal noise checks complete with no issues: no hum, buzz, clipping, switching thumps or OLED/control interference. This closes FW-WIM-01 and the final Phase 2 physical acceptance gate for installed v0.28.4 (source `3195c95`). Documentation only; no new build or OTA deployment. The owner subsequently approved review and explicitly authorised merge on 2026-09-21. Separate lighting, switch and mechanical acceptance issues remain open. |
| 2026-09-20 | Firmware/Commissioning | Confirmed vinyl playback, then diagnosed an installed 30–60+ second source-selection regression introduced while adding diagnostics: source commands were forcing secure-connection teardown and could be delayed behind wake/retry work. Firmware v0.28.4 at commit `3195c95` restores worker-lifetime connection reuse, resets only after real failures, prioritises revised physical source commands, bypasses stale retry cooldown and reconciles WiiM Line-In state. The owner confirmed approximately one-second response. The controller now advertises `decca-esp32`; the OLED shows top-left controller RSSI bars plus distinct controller-Wi-Fi/WiiM faults. Passive telemetry no longer wakes standby: owner acceptance confirms `DECCA STANDBY`, blank after ten seconds, then continuously off. Final build passed at 52,336 bytes RAM (16.0%) and 1,018,373 bytes flash (77.7%); WiiM/display targets compiled without execution and authenticated OTA passed. The WiiM remained strongly associated on 5 GHz after the access point returned to its original orientation, while controller latency remained variable during diagnosis. Only the formal noise/interference sweep remains open for Phase 2; the PR stays draft. |
| 2026-09-19 | Firmware/Commissioning | Completed installed ZA3 digital-audio, left/right-channel and direct-trigger acceptance. WiiM automatic standby at 30 seconds correctly removed the trigger, but logical ON initially left a stopped TIDAL Connect session and the ZA3 asleep. Verified that WiiM `play` and `resume` are no-ops for that stopped external session, while a real volume change wakes the trigger. Commit `36d84d1` therefore sends a safe one-step downward volume pulse and immediately restores the requested value on logical power-on. The final build passed (RAM 52,328 bytes / 16.0%; flash 1,016,977 bytes / 77.6%), the WiiM target compiled, authenticated OTA reached 100%, controller reboot recovery passed, and switch-only ZA3 wake passed. Vinyl and the formal noise/interference sweep remain open; the PR stays draft. |
| 2026-09-12 | Firmware/Commissioning | Deployed firmware v0.28.0 from source commit `d06e357` by authenticated OTA after a clean credential-enabled build (RAM 52,328 bytes / 16.0%; flash 1,017,193 bytes / 77.6%) and successful compilation of all nine target suites. The WiiM worker now retains and reuses its secure connection and sends the Decca pot's direct absolute 0–100 target. Exact 10%, 20% and 30% setpoints matched in WiiM Home; 20% to 30% completed in about 2.2 seconds total and the owner confirmed the response was much more responsive. Source, metadata/play state, logical standby/resume and outage/recovery acceptance remain passed. Private configuration remains ignored. The controller/streamer mDNS label collision and ZA3-dependent audio, channel, noise and trigger checks remain open; the PR stays draft. |
| 2026-09-11 | Firmware/Commissioning | Installed testing found and corrected the live-request reset and false-outage faults: the HTTPS worker stack was doubled to 16 KiB; transient failures use a 3 s timeout and three-failure hysteresis with a persistent outage screen. An intermediate two-point volume slew was rejected after a ten-point move took five delayed steps and was superseded by the reusable-connection implementation on 2026-09-12. Live acceptance passed VHF/network and released-VHF/Line-In selection, matching TIDAL metadata/play state, logical standby/resume and outage/recovery. |
| 2026-09-11 | Firmware/Hardware | Began Phase 2 WiiM integration on the acquired WiiM Pro. Live HTTPS identity, idle player and active TIDAL metadata probes passed on firmware `Linkplay.4.8.827634`; active playback returned matching hex and structured Jolene / Dolly Parton fields, vendor Tidal, mode 10 and 96 kHz. WiiM Home commissioning settings were confirmed as variable 2 Vrms Line Out, EQ off, Auto Headroom on, stereo, centred balance and a temporary 70% volume limit. Added a core-0 background client for VHF source switching, physical-volume synchronisation, logical-OFF stop, player/metadata polling and fixed-size OLED snapshots, plus deterministic live-fixture parser/mapping tests. Installation IP and device identifiers remain local-only. ADR-0018 replaces the unnecessary ESP32 trigger driver with direct WiiM Pro trigger-out to ZA3 trigger-in; control commands, OTA deployment and end-to-end audio/trigger behaviour remain physical gates. |
| 2026-09-10 | Docs/Mechanical | Reconciled the branch-only evidence into current main without merging stale firmware: archived the completed 2026-09-06 ADC/PWM diagnostic report, summary and 12,000-row raw capture; added the ESP32 housing Rev C source/exports/reports/renders that record the owner's 2026-09-07 print, fit, wiring and installation; and added IEC C14 mounting-plate Rev A failure evidence plus the active Rev B CAD package. Rev C housing remains a fitted prototype with seven prototype and two installation gates open. C14 Rev B is 15/15 CAD-passed and owner-confirmed in profile, with physical fit pending. Reconciled the human-readable power documents to the installed direct-solder Phihong output, reused inline fuse holder, obsolete TopHomer socket, and ordered whole-system C14/C13/four-gang components already recorded in the formal BOM. |
| 2026-09-09 | Firmware | Released v0.27.4 after installed behaviour showed that the fade did not visibly ramp: the LEDs stayed bright and then switched off only after the fade interval, creating a confusing delay. Removed the fade state machine and its timer entirely. Stereo/Mono changes apply immediately after the existing 25 ms contact debounce, and logical power changes are also immediate. Reworked the lighting suite around direct on/off writes. The release build passed (RAM 49,928 bytes / 15.2%; flash 838,049 bytes / 63.9%); the credential-enabled OTA build passed (RAM 49,928 bytes / 15.2%; flash 839,241 bytes / 64.0%); and all eight on-target suites compiled without upload or execution. Authenticated OTA of source commit `19c16b6` completed successfully in 57.956 seconds, and the device returned at `decca.local` / its reserved address. Physical transition verification remains pending. |
| 2026-09-08 | Firmware/Hardware | Finalised controller routing as on/off GPIO14/D14, VHF GPIO26/D26, Stereo/Mono GPIO25/D25 and DFR0457 lighting PWM GPIO18/D18. Firmware v0.27.3 at commit `0a4d3bd` establishes D18 safe-off before other setup. The `esp32dev-ota` build passed (RAM 49,936 bytes / 15.2%; flash 839,409 bytes / 64.0%); the affected display and hardware suites compiled without upload or execution. Authenticated OTA completed with exit code 0 in 60.527 seconds and the ESP32 returned at `decca.local` / its reserved address. Owner testing confirmed the v0.27.3 screen, D14 ON/STANDBY, D26 VHF, D25 firmware logic and D18 lighting output; the lamps reached fully on. The retained Stereo/Mono switch failed to produce Mono/LOW and is open as HW-SW-01. HW-GPIO-01 is complete; HW-LGT-01 remains open for Mono/off re-verification after switch repair plus the existing installation checks. Specification advanced to v0.27.3. |
| 2026-09-05 | Firmware/UI | Released v0.27.1 at commit `d0b1d3c`: extended the final startup/version frame by exactly one second, from 1.2 s to 2.2 s, and doubled the non-blocking lighting step interval from 10 ms to 20 ms so both 0–85% transitions take approximately 4.34 s. The production build and affected display/lighting suite compilations passed; authenticated OTA succeeded and the device returned at `decca.local`. The owner then physically approved the startup/version timing and both fade directions with no flicker. HW-LGT-01 remains open for ordered WAGO distribution installation plus pot-stability, temperature and current checks. Specification advanced to v0.27.1. |
| 2026-09-05 | Firmware/Display | Added `src/version.h` as the single firmware-version source, starting at v0.27.0. Cold startup and OTA reboot retain the non-blocking Decca reveal and hold `MUSIC CENTRE v0.27.0` in the lower calibrated visible area before the normal dashboard; logical standby/wake does not replay the sequence. Boot serial also reports `[SYSTEM] firmware=0.27.0` for OTA identification. The production build and display-suite compilation passed; commit `1ae242e` uploaded by authenticated OTA and the device returned at `decca.local`. Specification advanced to v0.27. |
| _TBD_ | Project | Repository foundation created |
| _TBD_ | Docs | Specification baselined (v0.1) |
| _TBD_ | Docs | Phase 1 wiring facts documented; Wiring, Hardware Architecture, Parts List, Firmware Architecture, README and Specification (v0.2) updated; ADR-0001..0006 added. Proposed GPIOs labelled proposed. |
| 2026-07-26 | Firmware | Reconciled named firmware pin constants with the proposed Phase 1 wiring map; assignments remain unverified. |
| 2026-07-26 | Firmware | Reconciled source, button, lighting, and shared-state contracts with the confirmed Phase 1 controls. |
| 2026-07-26 | Firmware | Implemented versioned settings persistence and behavioural NVS round-trip coverage (Specification v0.3). |
| 2026-07-26 | Firmware | Implemented board initialisation for assigned Phase 1 inputs, ADC1, I²C and safe-off dial-lighting PWM (Specification v0.4); all GPIO assignments remain proposed. |
| 2026-07-26 | Firmware | Implemented four-channel ADC1 pot sampling, normalisation, smoothing, deadband, calibration/inversion and behavioural tests (Specification v0.5); added the bench-verification procedure. |
| 2026-08-24 | Firmware | Routed the physical pot snapshot through Unity diagnostics so PlatformIO retains the four raw ADC readings during bench verification. |
| 2026-08-24 | Hardware | Bench-verified Volume GPIO32, Bass GPIO33, Treble GPIO34 and Balance GPIO35 across the full 0–4095 ADC range; default calibration retained (Specification v0.6). |
| 2026-08-24 | Firmware | Assigned proposed active-low source inputs VHF GPIO16, MW GPIO17, LW GPIO18 and Gram GPIO23 with internal pull-ups (Specification v0.7); assignments remain unverified. |
| 2026-08-24 | Firmware | Implemented 25 ms active-low debounce, stable latching state, fixed press-event queue, behavioural coverage and source-button bench diagnostics (Specification v0.8). |
| 2026-08-24 | Docs | Recorded the locked H3 colour code and the controller board labels for the proposed source-button GPIOs (HW-06, ADR-0004). |
| 2026-08-24 | Docs | Corrected H3 from an unsupported common-return colour map to four photographed, isolated two-wire pairs in provisional physical order; bench verification remains required (HW-06, ADR-0004). |
| 2026-08-24 | Hardware | Bench-verified VHF Yellow/Green on GPIO16, MW Purple/Blue on GPIO17 and Gram Yellow/Green on GPIO23; corrected LW to Yellow/Orange and retained GPIO18 as proposed pending solder repair and retest (Specification v0.9, HW-06, ADR-0004). |
| 2026-08-24 | Firmware | Implemented safe-off dial PWM, persisted idle target, non-blocking 10 ms fade steps and behavioural/physical test coverage (Specification v0.10, FR-LGT-01..04, HW-05). GPIO25 remains proposed pending bench verification. |
| 2026-08-24 | Firmware | Locked the purchased Pi Hut SH1106 panel and implemented non-blocking startup, standby/dashboard, status, SW-unavailable and diagnostic frames with change-only refresh and behavioural/physical coverage (Specification v0.11, FR-DSP-01/02/05, IF-02). GPIO21/22 remain proposed pending bench verification. |
| 2026-08-24 | Docs | Locked the revised display presentation contract: animated Decca startup, transient control overlays, mapped function prioritised over legacy button label, and Phase 2 now-playing metadata with mapped-function fallback (Specification v0.12, ADR-0007, FR-DSP-02/03/06/07). |
| 2026-08-24 | Firmware | Implemented ADR-0007 display presentation: five-frame Decca wordmark animation, mapped-function hierarchy, fixed-size Phase 2 metadata state and fallback, two-second control overlays, function confirmation and expanded behavioural/physical coverage (Specification v0.13, FR-DSP-01/02/03/06/07, NFR-02/03/05). |
| 2026-08-25 | Hardware | Locked Phase 2 audio architecture as **WiiM Pro -> separate stereo power amplifier -> passive speakers**; WiiM Pro model is locked, separate amplification is architecturally locked, exact amplifier model remains explicitly open, and dual monoblocks are rejected for the current build (ADR-0008; `hardware/BOM/phase2.csv`). |
| 2026-08-25 | Firmware | Removed legacy fascia-button labels from normal, now-playing and function-confirmation views after physical OLED review; reclaimed the line for mapped function, metadata and control spacing while retaining source identity in state (Specification v0.14, ADR-0009, FR-DSP-07). |
| 2026-08-25 | Hardware | Bench-verified the Pi Hut SH1106 OLED at 0x3C on SDA GPIO21 / SCL GPIO22; all ten on-target display tests passed and visual inspection confirmed the revised layout was upright, complete and unclipped (Specification v0.15, HW-06, IF-02). |
| 2026-08-27 | Mechanical | Built the Rev B parametric Fusion 360 CAD for the OLED display mount from Display Mount Spec v1.0: front bezel and rear OLED carrier, reference Decca panel and SH1106 module. Validated interference-free with the 0.30 mm glass-to-Perspex gap and the active area exactly centred on the opening. Three SH1106 reference dimensions remain assumed pending physical measurement (see the CAD review note). |
| 2026-08-27 | Mechanical | Rev C display mount after the Rev B print test. Corrected two spec-locked panel dimensions from physical measurement: fixing pitch 48.00 -> 49.00 mm and opening 35.50 x 15.80 -> 35.20 x 15.30 mm. Root-caused the PCB not seating flush to the header's display-side solder protrusions fouling a 0.60 mm relief pocket; the relief is now a full through-slot. Replaced the broken split snap pegs with four plain locating posts, two rigid bottom hooks and one top leaf spring. Bezel lip resized to fit the true opening. |
| 2026-08-27 | Hardware | Locked dial-lighting architecture: three identical ~24 mm E10/MES warm-white LEDs, parallel on the single regulated 5 V control rail, switched/dimmed together by ESP32 PWM through a logic-level N-channel MOSFET. No dedicated 6/6.3 V lamp rail. Brightness is a commissioning value stored in NVS; exact 5 V PSU and lamp part numbers remain open procurement items. |
| 2026-08-27 | Hardware | Locked WiiM Pro power behaviour: WiiM remains continuously powered and uses its automatic standby state rather than being hard power-cycled by the Decca front-panel switch. The ESP32 may stop playback or issue supported control/wake commands, but the hardware does not depend on an undocumented API wake path. Amplifier power switching remains a separate open design item. |
| 2026-08-27 | Hardware | Locked Fosi Audio ZA3 as the stereo amplifier and completed the system power architecture (ADR-0010): original Decca switch is a low-voltage ESP32 system-state input; WiiM remains continuously powered with auto-standby; ZA3 is controlled through its 12 V trigger; dial lamps fade via PWM; OLED blanks when off; ESP32 remains powered. Exact 12 V trigger driver/source and GPIO remain open implementation items. |
| 2026-08-27 | Mechanical | Rev D display mount after the Rev C fit test. Removed the Rev C top leaf spring and its anchor legs, which sat rigidly across the PCB insertion path and blocked the board entirely. Reverted bottom retention from rigid lips to the sprung snap pegs, stiffened to 1.88x bending stiffness at 0.67x deflection (shaft 2.80, slot 0.70, barb 3.20). Bezel locating lip deepened 0.70 -> 2.80 mm so it actually engages the 3.00 mm Perspex. Fixing pitch 49.00 confirmed correct on the print. |
| 2026-08-27 | Mechanical | Rev E display mount. Redesigned the cable-tie anchor: the Rev D slots were cut through the flange in Z, which is the Perspex seating face, so no tie could be threaded. Replaced with two stand-off bar anchors on the flange rear face whose 3.70 x 1.60 mm aperture runs along X and is open at both ends. Flange deepened 3.00 -> 7.00 mm to carry them. Verified by sweeping a 3.5 x 1.4 mm tie section through both anchors. |
| 2026-08-27 | Mechanical | Rev F display mount. Aesthetic reshaping of the carrier with no functional change: tray corners R2.5 -> R4.0, boss arms from 12.00 mm rectangular slabs to a 7.50 mm stadium bar whose R3.75 ends are centred on the bolts and tangent to the bosses, R2.50 concave blends at the arm and flange junctions, tie flange narrowed 40.0 -> 27.0 mm with R3.0 corners, tie bars radiused. Mass 3.908 -> 3.448 cm3. All clearances, interference results and the tie and insertion paths re-validated unchanged. |
| 2026-08-27 | Mechanical | Rev G display mount. Corrected the mounting orientation: the header wires exit ABOVE the window, so the whole carrier layout is mirrored (implemented as a 180 degree rotation about Z, exact because the part is X-symmetric). Header through cut-out now on the wide upper strip, shallow recess on the lower, and the cable-tie anchors move to the header edge where the cable actually leaves the board. Bezel corner locating blocks replaced with two side rails clear of the opening corner radii; retention is adhesive per spec 4 because the OLED glass blocks any mechanical clip. Boolean slivers eliminated, tiny edges 10 -> 0. |
| 2026-08-28 | Mechanical | Rev H display mount. Strengthened board retention after the Rev F/G fit test: snap nose 3.20 -> 3.35 mm (radial hook 0.100 -> 0.175, strain 2.87%) and a new sprung retaining lip across the far end, 26 mm span at 0.85% strain. All four holes cannot take sprung pegs - the narrow-end pair sit 0.70 mm from the window edge, leaving no room for the counterbore relief a durable peg needs, and an unrelieved peg reaches 6.25% strain. Header cut-out confirmed on the header edge at 16 mm. |
| 2026-08-28 | Mechanical | Rev I display mount. Ended the recurring header-orientation problem by giving BOTH PCB edges a full 16 mm through cut-out and removing the shallow recess entirely, so the board fits either way up. Costs almost nothing: a 0.60 mm recess already bore no load, so only widening it 12 -> 16 mm is chargeable, at 6.4 mm2 of bearing (99.4 -> 93.0). Rearward pin clearance cut through both tray walls to match. Verified with solder tips modelled 2.00 mm proud at both edges simultaneously - both clear. |
| 2026-08-28 | Mechanical | Rev J display mount. Completed the sprung retaining lip: it had no lead-in ramp and presented a square face to the incoming board, so it would have fought insertion rather than snapping. Now tapers 28.1 degrees over 1.50 mm from full overlap at the PCB rear plane to zero at the tip, retaining face still square; measured overlap 0.77 / 0.40 / 0.03 mm at the face, mid-ramp and tip. Removed the Rev I notches through the outside tray walls - they were never needed, the header clears the walls entirely - so both end walls are full height again. |
| 2026-08-28 | Mechanical | Rev K display mount. Removed the integrated retaining lip - a 26 mm bridge starting 3.90 mm up with an unsupported underside, which would have drooped - so no cantilever, bridge or overhang remains in the carrier, and it shrinks 48.35 -> 45.10 mm tall. All four holes now carry sprung snap pegs; the narrow pair use a 0.40 mm relief and 3.20 mm nose because a full-depth relief puts the peg root in front of the glass rear face. Added Retainer_Bar, an optional glued flat plate printed separately, with two locating pins and a shelf at the PCB rear plane. |
| 2026-08-28 | Mechanical | Rev L display mount. Moved the optional retainer bar from the end of the board to its centre, spanning the short axis into a notch in each side wall. Better on three counts: clear of the header whichever end it lands, the end wall keeps its full height instead of needing a machined shelf, and no PCB bearing is spent at the ends. At the centre there is no front-plate datum opposite the bar, so it is set 0.05 mm behind the PCB rear plane as a clearance stop - a clamp there would bow the board forward and close the 0.30 mm optical gap. |
| 2026-08-28 | Mechanical | Rev M display mount. Shifted the retainer bar 4.00 mm toward the tie-flange edge, to y +5.00..+11.00 in the final model, leaving 6.75 mm to the header keep-out. Side-wall notches move with it. The bar still lies over the open display window with no datum opposite, so it stays a 0.05 mm clearance stop rather than a clamp. |
| 2026-08-28 | Mechanical | Rev N display mount. Corrected the depth chain from a measured 1.50 mm screen recess: the glass stands 0.80 mm proud of the PCB face, not the assumed 2.00, so the front plate goes 2.30 -> 1.10 mm and the screen now sits the intended 0.30 mm behind flush. Replaced the two guessed parameters with one measured oled_glass_proud. WARNING: at 1.10 mm the plate no longer swallows the header solder tips - modelled at 2.00 mm proud they now strike the Perspex, so they must be trimmed below 1.10 mm before assembly. Snap pegs shortened accordingly; the retainer bar becomes primary retention. |
| 2026-08-28 | Docs | Display Mount Specification v1.1: locked the measured Decca interface geometry into section 2 and every downstream restatement (sections 4, 5 and 10). The v1.0 figures were pre-measurement estimates - fixing pitch 48.00 -> 49.00 mm, opening 35.50 x 15.80 -> 35.20 x 15.30 mm, hole centre from the opening edge 7.90 -> 7.65 mm - superseded by measurement at Rev C, print-confirmed at Rev D and re-confirmed by the project owner on 2026-08-28. The pitch is not recoverable by clearance: an M2 screw in a 2.40 mm hole has 0.20 mm of radial play, so 48.00 would put each screw 0.50 mm off its hole. The Rev O brief had already re-quoted the stale figures once; v1.1 exists so that cannot recur. No other specification value changed. |
| 2026-08-28 | Mechanical | Rev P display mount. Implemented the corrected rear-loaded architecture: the OLED loads from the rear, its fore/aft position is set by four rear support shoulders bearing on the PCB REAR face at z -2.70, and there is now nothing at all between the PCB front face and the Perspex - proven as a machine-checked invariant with a 0.10 mm margin in two independent tools. The Rev N front plate and the separate retainer bar are both gone; all M2 preload runs screw -> Perspex -> a 707.8 mm2 carrier seating rim -> boss -> insert, in parallel with the module rather than in series, so torque cannot reach the glass or the PCB. Retention is four cantilever fingers rooted at the carrier rear frame (0.75 x 4.00 mm, 1.73 % strain, 0.55 N friction hold, zero Z preload) plus four radial prise holes for removal; nothing enters the four PCB mounting holes, which retires Rev O's blocking unmeasured glass-envelope dimension - the nearest spring is 3.20 mm clear of the glass and clear even if the glass is the full PCB outline. Both swept corridors validated in both directions. The brief's 1.50 mm trimmed solder tips would have struck the Perspex by 0.40 mm - a module-to-panel conflict no carrier geometry can fix, since the budget is fixed at gap 0.30 + glass proud 0.80 = 1.10 mm; resolved by the owner's decision to reduce the tips, so oled_tip_proud is modelled at 1.00 mm and all 20 mandatory validations pass. Released for the geometry-validation prototype print, with front-side solder protrusion <= 1.00 mm as a mandatory assembly-preparation step. |
| 2026-08-28 | Hardware | Initial H4 OLED loom colour record entered SDA = Orange and SCL = Yellow. This entry was later found to be reversed and is superseded by the physical confirmation dated 2026-08-30 below; do not wire from this historical entry. |
| 2026-08-30 | Hardware | Physically confirmed the final H4 OLED loom: Brown = GND, Red = 3.3 V VCC, Orange = SCL to GPIO22/D22 and Yellow = SDA to GPIO21/D21. This supersedes the reversed 2026-08-28 colour record. Orange and Yellow are signals and must never be connected to 5 V. |
| 2026-08-29 | Mechanical | Corrected the open Rev P display-mount design direction after the physical OLED fell through the loose carrier. Rear insertion plus rear-face shoulders restrained the wrong direction and left forward retention to four 0.10 mm edge-friction contacts. The authoritative brief now requires flush-side insertion onto fixed rear PCB datum pads, two plain plus two sprung locating posts as the conservative starting architecture, positive geometric forward retention, a controlled local snap-nose exception only inside verified mounting-hole keep-outs, 1.00 mm maximum display-side protrusion, and physical inversion/removal testing before release. PR #2 remains open and unmerged.  *(Historical entry - superseded by the Rev P.5 release on 2026-08-30: the carrier was built, installed and physically tested and every test passed. Any "open", "blocked" or "gates release" statement in this row is closed.)* |
| 2026-08-29 | Mechanical | Recorded the corrected Rev P.2 prototype as successful for OLED retention and Perspex tolerance, then opened a bounded integration correction for collision with the non-removable original Decca lighting unit. The complete continuous end rail and integral cable-tie projection below/outboard of the sprung-post pair as installed must be deleted. The sprung posts, full pedestals, datum pads, filleted roots, side uprights, 49.00 mm M2 load paths and opposite rail remain. The replacement must be a connected open-ended frame, clear the lighting unit during installation and removal, and repeat the successful OLED regression tests. PR #2 remains open and unmerged.  *(Historical entry - superseded by the Rev P.5 release on 2026-08-30: the carrier was built, installed and physically tested and every test passed. Any "open", "blocked" or "gates release" statement in this row is closed.)* |
| 2026-08-29 | Mechanical | Replaced the Rev P M2 heat-set insert assumption after confirming that the original Decca bolts use a non-standard thread. The original bolts and matching six-sided nuts are now controlled hardware at the unchanged 49.00 mm pitch. Each rear-accessible anti-rotation pocket must use the measured 3.80 mm hex width (provisionally interpreted across flats and explicitly verified before release), 1.40 mm head-seat depth and 10.00 mm total nut envelope, preserve a positive carrier-to-Perspex hard-stop load path, and clear the OLED, wiring and lighting-unit keep-out. PR #2 remains open and unmerged.  *(Historical entry - superseded by the Rev P.5 release on 2026-08-30: the carrier was built, installed and physically tested and every test passed. Any "open", "blocked" or "gates release" statement in this row is closed.)* |
| 2026-08-29 | Mechanical | Rejected the new unmeasured `Lighting_Keepout` reference component introduced in Rev P.3 and required its removal from the Fusion assembly, generator, verification and exports. Physical installed fit remains the authority for clearance, and the previously colliding lower rail/cable-tie feature remains deleted. To prevent cabinet LED light contaminating OLED contrast, the carrier now requires a continuous integral opaque-black rear light shield over the OLED bay, with only a minimum local opening for the four input/header pins and wiring. Front insertion, sprung retention, service release, PCB clearance, 49.00 mm fixing pitch and the successful Perspex gap remain unchanged. PR #2 remains open and unmerged.  *(Historical entry - superseded by the Rev P.5 release on 2026-08-30: the carrier was built, installed and physically tested and every test passed. Any "open", "blocked" or "gates release" statement in this row is closed.)* |
| 2026-08-29 | Mechanical | Opened the Rev P.5 packaging/datum correction: reduce the plastic carrier depth 8.00 → 6.00 mm; increase the finished four-pin opening by 25% in each linear axis from 11.20 × 3.35 to 14.00 × 4.19 mm; add two integral internal side light blocks that remain within the back-plate X/Y footprint and revised Z envelope; rotate the complete OLED reference so the connector side is at the bottom; and align the visible active-area bottom edge to the measured Perspex opening bottom. The original Perspex holes remain untouched and panel-fixed at exactly 49.00 mm horizontal pitch; the OLED bay and dependent carrier geometry move relative to them. PR #2 remains open and unmerged.  *(Historical entry - superseded by the Rev P.5 release on 2026-08-30: the carrier was built, installed and physically tested and every test passed. Any "open", "blocked" or "gates release" statement in this row is closed.)* |
| 2026-08-29 | Mechanical | Extended Rev P.5 to replace the remaining two plain locating posts with sprung locating-and-retaining posts, giving four sprung posts and deleting all plain-post geometry/parameters. The converted pair may use separately tuned sprung geometry but must pass direct bonded-glass-to-hole measurement, full swept clearance, individual/combined insertion-force and strain checks, PCB-bow inspection, root validation within the 6.00 mm carrier and an accessible four-post release test with the closed rear wall. PR #2 remains open and unmerged.  *(Historical entry - superseded by the Rev P.5 release on 2026-08-30: the carrier was built, installed and physically tested and every test passed. Any "open", "blocked" or "gates release" statement in this row is closed.)* |
| 2026-08-29 | Mechanical | Superseded the Rev P.5 bottom-edge alignment rule. With the connector cut-out/open side defined as carrier bottom, both carrier fixing centres, bosses, bores, nut pockets and arms move 7.00 mm toward that bottom relative to the OLED-dependent group. The original Perspex holes remain untouched at 49.00 mm horizontal pitch; when assembled, the revised carrier holes coincide with them and the screen sits 7.00 mm higher than the preceding Rev P.5 datum. The model must report the resulting active-area visibility and repeat installed clearance testing. PR #2 remains open and unmerged.  *(Historical entry - superseded by the Rev P.5 release on 2026-08-30: the carrier was built, installed and physically tested and every test passed. Any "open", "blocked" or "gates release" statement in this row is closed.)* |
| 2026-08-29 | Hardware | Selected the existing Phihong PSA15R-050P switching adapter for the 5 V control rail: 5.0 V DC at 3.0 A (15 W). The 5 V PSU procurement item is closed; DC plug size and polarity remain a required multimeter check before connection. |
| 2026-08-29 | Hardware | Completed the open-component reconciliation for the 5 V input chain: added the matching panel DC socket, post-inlet 2 A fuse and holder, separate +5 V/GND distribution connectors, power wiring/ferrules and explicit external-adapter boundary. Corrected the readable Phase 2 list to the locked Fosi ZA3 decision and added the still-open trigger and audio harness components. |
| 2026-08-29 | Hardware | Corrected component status against the project decisions and purchase records: recorded the installed ABW1 10K potentiometers, ordered DAOKAI B09YYH2BTF MOSFET modules, delivered ShuoHui B0CFTLZFGT lamps pending fit/5 V testing, purchased Lyeteung B0CBWX98NF JST-XH harness set, selected-but-unbought WiiM Pro and Fosi ZA3, and B&W DM601 S3 as the fit-gated primary speaker target. |
| 2026-08-29 | Hardware | Purchased the Amazon TopHomer B08HGXYS4J pack of five 5.5 × 2.1 mm, two-terminal, threaded-nut panel DC sockets rated 3 A. Socket procurement is closed; physical fit and centre-positive polarity remain mandatory checks before drilling or wiring. |
| 2026-08-29 | Mechanical | Rev P.2 display mount. Rebuilt the carrier to the corrected retention architecture after the printed Rev P.1 failed its physical retention test - the OLED falls forward through the loose carrier. The failure is architectural: Rev P.1 loaded from the rear and put its only positive shoulders at the PCB REAR plane, so they restrained the opposite direction, leaving forward retention to four 0.10 mm edge tongues acting through assumed friction. Rev P.2 reverses the installation direction. The module now enters from the flush/Perspex side and seats rearward on four FIXED, rigid annular datum pads at z -2.70, concentric with the four PCB mounting holes so they bear inside the board's own keep-outs rather than an assumed component-free edge band - 38.96 mm2 of forward-facing pad, 34.10 mm2 of it on the board, across a 30.00 x 28.50 mm four-point pattern on Nom.8.60 pedestals. Forward escape is now blocked by POSITIVE GEOMETRY: two split sprung posts at the header-side holes carry a Nom.3.20 barb over a Nom.3.00 hole, a 0.10 mm radial overlap behind a square retaining face at z -1.00 that cannot cam open; swept forward travel is blocked from +0.15 mm through +12.00 mm. The display-side pair get plain Nom.2.70 posts stopping 0.25 mm behind the PCB front plane, so the pair the modelled glass overhangs is safe whatever the real envelope is - Rev K's narrow pair rested on 0.20 mm of assumed glass clearance and that dependency is not recreated. Reused from the printed Rev D/K post development unchanged: 2.80 shaft, 0.70 slot, 3.20 barb, R0.80 root fillet, 2.70 plain post; changed: root relief 1.00 -> 3.20 mm on the sprung pair, because the relief now sits BEHIND the PCB where the glass cannot cap it, which drops peak strain 1.64 -> 0.83 % (1.66 % worst case), and the hook land to 0.25 mm so the retaining face is thicker than a print layer. Seated, the carrier touches the module nowhere but the four pads: 0.10 mm axial clearance under each hook, 0.10 mm radial in each hole, zero preload, zero bending, carrier x PCB CLEAR. Deleted: the four friction fingers, their shoulders and tongues, the four radial prise holes, and the friction-versus-weight acceptance gate - neither tool contains a friction criterion now. Carrier 56.60 x 47.20 x 8.00 mm, 6.928 cm3 (9.60 mm existed only for the deleted fingers). Removal is by pinching the two exposed barbs and pushing the board out through the open rear. Validation also caught a silent Fusion API failure: createTorus ignores its centre argument in build 2704.1.53, so every torus-built root fillet was quietly coming out as a plain cylindrical collar that passed every clearance check; the generator now places the torus explicitly and raises if the boolean removes nothing. Rev P stays OPEN and unreleased. One blocking measurement remains before any print - the glass envelope at the two header-side mounting holes, never measured, needing >= 2.10 mm hole-centre to glass edge - and the retention finding closes only when a printed carrier passes a real inversion and gentle-shake test. PR #2 remains open.  *(Historical entry - superseded by the Rev P.5 release on 2026-08-30: the carrier was built, installed and physically tested and every test passed. Any "open", "blocked" or "gates release" statement in this row is closed.)* |
| 2026-08-29 | Mechanical | Rev P.3 display mount. Bounded amendment to the radio-side interface only; the Rev P.2 OLED architecture PASSED physical testing for retention and Perspex fit and is carried through unchanged - flush-side insertion, fixed rear datum pads, plain and sprung locating posts, snap retention and release, OLED Z position, 0.30 mm gap, active-area centring, 35.20 x 15.30 aperture, exact 49.00 mm pitch, carrier-to-Perspex hard stops and the existing bezel, all re-validated identical. (1) LIGHTING-UNIT CLEARANCE. The retained original Decca lighting unit cannot be removed and the continuous transverse end rail below the sprung-post pair, plus its integral cable-tie projection, rear relief, two tie slots and the wire notch, fouled it. All deleted; nothing put back inside the keep-out. The carrier is now an open-ended frame: the two side uprights terminate at y +20.50, half a millimetre short of the pocket wall line so no bridge can survive, each capped with an R1.80 half-round of its own 3.60 mm width landing alongside the retained pedestal root. Above that line the only material anywhere is the two Nom.8.60 sprung pedestal towers, and between them there is nothing over x -10.70..+10.70. Carrier extent on that side 30.60 -> 22.55 mm, so 8.05 mm of projection returned; envelope 56.60 x 47.20 x 8.00 -> 56.60 x 39.15 x 8.00 and volume 6.928 -> 4.472 cm3. Both sprung posts keep their full pedestals, Nom.6.00 datum pads, Nom.4.80 reliefs and R0.80 root fillets, and their connection to the uprights; the opposite rail, both fixing arms and both load paths are untouched. One connected solid - 1 lump in Fusion and 1 connected component over 3430 welded vertices on the mesh. The keep-out boundary is ASSERTED at the pedestal tangent because the lighting unit has never been measured; brief 12.14 confirms or refutes it, and the fallback is a smaller pedestal diameter on the sprung pair. No replacement strain relief is added - the brief allows one only outside the keep-out with demonstrated clearance, which does not exist, so the loom now exits through a fully open end and external strain relief is an open item. (2) ORIGINAL DECCA FASTENERS. The original front bolts have a NON-STANDARD thread, so the entire M2 heat-set insert architecture is deleted - m2_insert_d 3.20, m2_insert_depth 4.00, m2_insert_recess 0.50, the bore chamfer, both cylindrical insert bores, the insert backing calculation and the M2 insert and replacement M2 screw BOM entries. m2_boss_d and m2_arm_h become fix_boss_d and fix_arm_h with no thread implication. The two original bolts and their two original matching nuts are reused at the unchanged 49.00000 mm pitch. New named parameters: original_nut_hex_width 3.80, original_nut_head_seat_depth 1.40, original_nut_total_length 10.00 and a separate printer/material nut_pocket_fit_allowance 0.20. The 3.80 mm is INTERPRETED as across opposite flats and that assumption is recorded in the generator source, the topology review, the build review and as a drawing note; it is not derived from any M2, BA, UNC, metric or other catalogue nut, and the real part must be checked across flats AND across corners before release - if 3.80 is across corners the true across-flats is 3.29 and the single parameter changes. Each fixing centre now has, front to rear: a Nom.2.60 bolt clearance bore through a 2.00 mm solid ring, a positive 8.55 mm2 seating shoulder at z -2.00, a regular-hex head seat of exactly 1.40 mm at 4.00 mm across flats, a step to a 3.55 mm retaining ridge giving 0.125 mm interference per flat, a self-supporting lead-in, and a Nom.4.82 clearance bore running out of the rear face so the full 10.00 mm nut and engaged bolt are cleared. Minimum continuous boss wall 1.391 mm nominal, 1.388 measured off the mesh. Anti-rotation is proved by measuring 4.000 across flats and 4.619 across corners off the exported mesh and by showing the same nut rotated 30 degrees interferes by 1.0162 mm3. Retention is a serviceable interference ridge, not adhesive; removal is a 2 mm pin through the bolt bore. Load path: original bolt head -> Perspex -> carrier seating face -> captive original nut -> original bolt thread, with the glass 0.300 and the PCB 1.100 mm behind the seating plane and the bolt envelope clear of both. A five-station hex-pocket fit coupon (Hex_Pocket_Fit_Coupon_revP) is generated and must be printed before the carrier. Fusion gate ALL CHECKS PASS and the independent STL verifier exits 0. Rev P stays OPEN: four measurements gate the print - glass envelope, nut across flats and corners, original bolt length and the coupon fit - and installed lighting-unit clearance, rack/twist of the open frame and the captive-nut and bolt tests gate release. PR #2 remains open.  *(Historical entry - superseded by the Rev P.5 release on 2026-08-30: the carrier was built, installed and physically tested and every test passed. Any "open", "blocked" or "gates release" statement in this row is closed.)* |

| 2026-08-29 | Firmware | Replaced the unreliable four-button electrical model with sole Gram two-state selection: closed = Vinyl, open = Digital Streamer. GPIO16/17/18 released; GPIO23 retained; settings schema v2 no longer persists physical source; nine button tests revised (Specification v0.16, ADR-0011). |

| 2026-08-29 | Firmware | Implemented authenticated local-network ArduinoOTA before enclosure: gitignored credentials, non-blocking reconnect, `decca.local`, PlatformIO `espota`, dual-app partitions, five behavioural tests and safe bootstrap main (Specification v0.17, ADR-0012, FR-ADV-02). Interrupted transfers retain the running image; failed-boot automatic rollback remains Phase 3. |

| 2026-08-30 | Firmware | Passed USB-to-OTA physical acceptance: the authenticated `esp32dev-ota` upload succeeded and, after reboot, serial reported `[OTA] ready at 192.168.x.x (decca.local)` (Specification v0.18, ADR-0012, FR-ADV-02). Interrupted-transfer acceptance remains outstanding; failed-boot automatic rollback remains Phase 3. |

| 2026-08-30 | Firmware | Passed the full `esp32dev` release build and all seven on-target suites: buttons 9/9, display 10/10, hardware 3/3, lighting 7/7, OTA 5/5, pots 6/6 and settings 3/3 (43/43 total; Specification v0.19, NFR-04/05). Restored the production safe-bootstrap image by USB afterward and reconfirmed `[OTA] ready at 192.168.x.x (decca.local)`.

| 2026-08-30 | Firmware | Began fitted-Perspex display refinement after the final opening exposed a restricted visible area: rotated SH1106 rendering 180 degrees, added a persistent non-blocking 128×64 calibration frame with nested borders, 8-pixel grid, coordinate labels, asymmetric corner marks and a centre target, and exposed it from the safe-bootstrap runtime while retaining OTA service. Release build and expanded display suite passed 11/11 on target; production calibration firmware uploaded and OTA readiness reconfirmed. Straight-on photo analysis and final safe-viewport layouts remain pending (Specification v0.20). |
| 2026-08-30 | Firmware | Completed and physically accepted the fitted-Perspex display visual cycle. Photo analysis established viewport X4–123/Y10–61 and a conservative Y24–60 production band to avoid the upper parallax zone. Accepted views use 180-degree rotation, contrast 0x80, one visual priority per frame, and a bottom-right play/pause glyph instead of redundant “NOW PLAYING” text. The calibration frame remains available as a service diagnostic (Specification v0.21). |
| 2026-08-30 | Firmware | Passed the final fitted-display release build and all seven on-target suites: buttons 9/9, display 12/12, hardware 3/3, lighting 7/7, OTA 5/5, pots 6/6 and settings 3/3 (45/45 total). Restored the production image by USB; it now starts the accepted standby display and serial reconfirmed `[OTA] ready at 192.168.x.x (decca.local)`. |
| 2026-08-30 | Firmware | Bench-verified the retained H2 Red/Green on/off switch on GPIO19/D19 in both positions: closed = logical ON and open = STANDBY. Added the independent `power` module and production coordination of buttons, power, display and OTA without changing the locked system-power architecture (Specification v0.22, ADR-0003). |
| 2026-08-30 | Firmware | Added SH1106 uneven-ageing protection without changing the accepted fitted-Perspex layouts: contrast 0x80 while active, dim to 0x20 after 60 s, pixels off after 5 min, standby pixels off after 10 s, and immediate wake on relevant activity. The release build passed (RAM 49,760 bytes / 15.2%; flash 833,321 bytes / 63.6%) and all eight on-target suites passed 52/52 (buttons 9, display 14, hardware 3, lighting 7, OTA 5, pots 6, power 5, settings 3). Production was restored by USB and serial confirmed `[POWER] state=ON` plus `[OTA] ready at 192.168.x.x (decca.local)`. |
| 2026-08-30 | Firmware | Integrated all four filtered pots and the physical source selector into the production coordinator. Installed testing established VHF as the only reliable active contact: VHF closed = Digital Streamer; every other interlocked position = Vinyl. ADR-0013 supersedes ADR-0011. The source now remains on the normal dashboard until metadata takes priority. |
| 2026-08-30 | Firmware | Physically accepted the final control UI: Volume 0–100%; Bass/Treble −50..0..+50; Balance L50..0..R50 with a plain zero centre tolerance; continuous centred bars and enlarged monochrome control icons. Release build and all eight on-target suites passed 53/53 (buttons 9, display 15, hardware 3, lighting 7, OTA 5, pots 6, power 5, settings 3); production restored over COM3. Specification v0.23. |
| 2026-08-30 | Firmware | Assigned and physically accepted the original Stereo/Mono contact on TX2/GPIO17 as a debounced lighting command. Installed polarity is Stereo open/high = lights on and Mono closed/low = lights off; both snapshots passed. GPIO5 was rejected as a strapping pin. ADR-0014 supersedes ADR-0005. Firmware exposes the stable request but does not energise the separately gated GPIO25 lamp load. The credential-enabled production build passed (RAM 49,880 bytes / 15.2%; flash 837,497 bytes / 63.9%) and all eight on-target suites passed 55/55: buttons 11, display 15, hardware 3, lighting 7, OTA 5, pots 6, power 5 and settings 3 (Specification v0.24, FR-BTN-05). |
| 2026-08-31 | Hardware | Physically accepted GPIO25, one DAOKAI B09YYH2BTF MOSFET stage and the three-parallel-lamp electrical load. The improved observable test faded from safe off to duty 64 (25%), held five seconds and faded fully off; all lamps lit evenly with no full-brightness flash, flicker, abnormal heat or smell, and the lighting suite passed 7/7. Final holder fit, operating brightness and measured lamp-bank current remain open (Specification v0.25, FR-LGT-01/03/04, HW-05/12). |
| 2026-08-31 | Firmware | Compared dial illumination at 70%, 80% and 100%; owner approved 90% / duty 230 as the normal level. Settings schema v3 applies that commissioning default. Production now coordinates the accepted Stereo/Mono request through the independent lighting module: logical ON + Stereo fades to 90%, while Mono or logical standby fades to zero. The exact 90% physical lighting snapshot and lighting suite passed 7/7. Final production interaction was physically accepted in both states: Mono logged target 0 and held the lamps fully off; Stereo logged target 230 and lit the dial at 90%; OTA remained ready. The credential-enabled build passed (RAM 49,936 bytes / 15.2%; flash 839,253 bytes / 64.0%) and all eight on-target suites passed 55/55 (Specification v0.26, FR-LGT-02/03/04/05). |
| 2026-08-31 | Hardware | Recorded the installed power state: the Phihong 5 V supply now feeds the shared controller/lighting rail, the ESP32 is connected at VIN/5V and USB is removed. Selected the DFRobot DFR0457 Gravity MOSFET Power Controller for the final lamp stage and marked it open to purchase; its 0–1 kHz switching limit requires a firmware PWM adjustment and renewed physical acceptance after installation. Selected a Pi Hut pack of three WAGO 221-415 five-way connectors for star distribution: one +5 V, one common GND and one spare. The existing DAOKAI pack remains test stock and is no longer the final-installation selection. |
| 2026-08-31 | Docs | Added `docs/Open Issues.md` as the canonical unresolved-integration log and recorded HW-LGT-01. The prior switching path produced visible lamp flicker and correlated pot-overlay chatter, while the lamps were stable directly on the same 5 V supply. Preserved DFR0457 procurement, <=1 kHz PWM migration, 90% Stereo behaviour, WAGO star distribution and full physical re-acceptance as explicit closure gates. Recorded the last-known ESP32 image as the temporary 100% diagnostic build while GitHub `main` remains the 90% source of truth. Updated the handover to close merged Rev Q PR #7 and remove stale pre-integration status. |
| 2026-09-05 | Hardware/Firmware | Installed the selected DFRobot DFR0457 final lamp controller; the owner reports that the steady-light flicker is resolved. Commit `c6cb9a6` sets the owner's revised 85% / duty 217 level, changes GPIO25 PWM from 5 kHz to the DFR0457 limit of 1 kHz, advances settings schema v3 to v4 so the persisted 90% value cannot override the new target, and retains the non-blocking one-count-per-10-ms soft fade for both directions. The credential-enabled build passed, authenticated OTA succeeded, and the ESP32 returned at `decca.local` after reboot. HW-LGT-01 remains open until safe-off, fade, pot-stability, temperature and current checks pass physically. |
| 2026-08-30 | Mechanical | **Rev P.5 display mount RELEASED.** Carrier manufactured, installed and physically tested; every test passed - Perspex fit, OLED insertion and removal, four-post sprung retention, lighting-unit clearance, connector-side clearance, 6.00 mm thickness, the 14.00 x 4.19 mm connector opening, rear closure and light blocking, original captive-nut fasteners, 49.00 mm pitch, mounting points 7.00 mm lower giving the required OLED position, and powered operation. Generator and independent STL verifier both re-run: all geometric checks pass, verifier exit 0. Items CAD could not settle are recorded as closed by test, with no check altered. PR #2 updated and ready for review and merge. |
| 2026-08-30 | Mechanical | Confirmed the original captive-nut 3.80 mm dimension as the distance ACROSS OPPOSITE FLAT FACES. It was carried through Rev P.3-P.5 as an interpretation, recorded as such in the generator, both reviews and as a drawing note, and flagged for checking before release; the reading is correct. No geometry, parameter or export changes - the model always used it this way - but original_nut_hex_width is now a measured value rather than an assumption, the derived 4.39 mm across-corners figure follows arithmetically, and the nut pocket can be regenerated without further checking. Remaining modelling caveats drop from three to two: the bonded-glass envelope and the original bolt length. |

| 2026-08-30 | Docs | Completed firmware-chat close-out and durable handover. Restored the root project README, reconciled CLAUDE.md with Gram-only GPIO23 logic and the safe OTA bootstrap, corrected the Hardware Architecture verified-pin status, completed ADR traceability, aligned the formal Phase 1 BOM with the verified 5 V lamp result, and replaced the ambiguous Windows `pio` / `COM_PORT` OTA instructions with executable PlatformIO-path and actual-port commands. Added `docs/Development Handover.md` with current implementation boundaries, verified wiring, open gates, immediate OTA acceptance procedure and a new-chat continuation prompt. No firmware behaviour changed. |

| 2026-08-28 | Hardware | Recorded the installed H4 OLED loom colours: SDA GPIO21 = Orange and SCL GPIO22 = Yellow. H4 is an explicit exception to the general loom standard; its Orange conductor is a signal and must never be connected to 5 V. |
| 2026-08-30 | Mechanical | Opened **Rev Q as a bezel-only amendment**. Preserve the released Rev P.5 carrier unchanged. Replace the Rev N pair of side locating rails with a thin continuous masking lip around all four sides and corners of the measured 35.20 x 15.30 mm Perspex opening. Initial target: proven 34.90 x 15.00 mm lip envelope, 2.80 mm engagement depth and a provisional 0.40 mm wall, with fit clearance and corner relief kept parametric for test-print refinement. The lip must conceal the Perspex cut edge, sit snugly without interference and retain the powered screen presentation. |
| 2026-08-30 | Mechanical | **Built and validated Rev Q, the bezel-only continuous masking lip. OPEN - the first print is an integration prototype, not a release part.** The two Rev N side rails are replaced by one continuous 0.40 mm lip, 2.80 mm deep, around all four sides and all four corners of the measured opening, at a 34.90 x 15.00 outer envelope with 0.150 mm clearance per side. The Rev N face, envelope, R2.00 external corners, R0.40 front break, 30.40 mm window width, R0.80 window corners and both recessed adhesive pads were recovered by parsing Front_Bezel_revN.step read-only and carried over unchanged. The single deliberate deviation is the window HEIGHT, now derived from the lip at 14.200 mm rather than the Rev N 14.900 mm, because at 14.900 the lip wall would have met the face over just 0.050 mm - a sliver and an unprintable root - and it costs nothing optically since the lip already controlled the clear height. 30/30 gates PASS in Fusion, 35/35 PASS in a new independent offline mesh verifier. The frozen Rev P.5 carrier is untouched and proved so: all nine frozen Rev N/Rev P.5 files are byte-identical before and after, and every Rev Q artefact is a new file. Two items are explicitly NOT settled by CAD and gate the prototype: the Perspex opening corner radius, which has never been measured anywhere in this project and is carried as the named UNRESOLVED parameter bezel_lip_corner_r = R0.600 with a published tolerance study and a five-tab gauge coupon to measure it; and the optical cost, a clear opening of 30.40 x 14.20 mm and a visible lit band reduced from 8.100 to 7.750 mm, all of it at the top edge, whose acceptability only the powered test can decide. All six SHA-256 values in the Rev Q brief section 2 match and no change to the brief is needed; the two .py entries match the CRLF rendering rather than a plain sha256sum of this clone, a line-ending trap that reads like tampering and is now guarded by a new checker, mechanical/CAD/Decca_Display_Bezel_revQ_frozen_check.py. |
| 2026-08-30 | Mechanical | **Rebuilt Rev Q to the amended brief 7b107f2 - controlled interference fit and a two-loop inset wall. Still OPEN; the first print remains an integration prototype.** The clearance fit is replaced by a 0.10 mm per side horizontal INTERFERENCE with 0.05 mm vertical clearance; the visible opening grows to 30.90 x 15.35; the inset wall moves out to a 35.40 x 15.20 outer envelope with specified R2.00 outer corners; and the wall doubles from 0.40 to 0.80 mm because the 0.40 mm wall resolved as only ONE loop in the slicer, where the amendment requires TWO continuous 0.40 mm loops. Derived inner envelope 33.80 x 13.60 with R1.20 inner corners; effective clear optical opening 30.90 x 13.60, height controlled by the wall exactly as the brief predicts. 51/51 gates PASS in Fusion, 44/44 offline. Continuity is now proved by cross-section AREA - 76.2025 mm2 full ring and every region exact to four decimals - after BRepBody.pointContainment proved untrustworthy against the NURBS-walled body. The declared interference is confirmed present, located and bounded at exactly 0.100 mm, and vanishes when the declared relief is applied. Two forced modelling decisions are declared in full: the aperture must TAPER in Y (35.47 deg, self-supporting) because the 15.35 face opening is taller than the entire 15.20 wall and a straight wall would leave the top and bottom runs detached from the bezel face; and the window edge break is a 0.40 chamfer rather than the Rev N R0.40 fillet, Fusion having refused a fillet on the tapered NURBS edge at every radius. A 0.02 mm anti-tangency relief removed 52 zero-area triangles from the mesh. The frozen Rev P.5 carrier is untouched and proved so four ways. The corner-radius gauge is deleted and replaced by an interference fit gauge, because the corner radius is now specified and the interference is not. Open gates: the interference against a wall 8x stiffer in bending, the slicer's two loops, Perspex stress, and powered visibility - the lit band drops 8.100 -> 7.450 mm, all at the top. |
| 2026-08-30 | Mechanical | **Two owner changes to the OPEN Rev Q bezel, made after inspecting the model. Both are declared deviations from the controlled brief, both are single named parameters, and both are reversible.** (a) The two RECESSED ADHESIVE PADS ARE DELETED - the "two rectangle cut outs on the underside", 24.00 x 2.00 mm and 0.30 mm deep. Brief 3.1 asks for them preserved, but Rev N needed adhesive because it located on side rails with a clearance fit, whereas Rev Q is held by a 0.10 mm per side interference fit that makes bonded pads redundant. The seating face is now one unbroken annulus of 278.212 mm2, retention is by the interference fit alone, and removability becomes a prototype re-check. Set pads_enabled = True to restore them exactly. (b) The INSET-WALL OUTER CORNER RADIUS IS RAISED 50%, R2.00 -> R3.00, because R2.00 did not match the real Perspex opening corner; the inner radius follows at 2.20. Deepest penetration now holds at exactly the declared 0.100 mm across the whole plausible range of opening corner radii rather than only up to 2.05 mm, and the tightest wall-loop radius at the corner rises 1.400 -> 2.400 mm, so the two-loop slice gets easier. The cost is corner masking: the unmasked gap against a sharp opening grows 0.562 -> 0.836 mm. That is the safer direction while the opening corner is unmeasured - too square jams before seating, too round only leaves a little cut edge visible. Re-validated after both: 51/51 in Fusion and 44/44 offline, with every region area again matching the analytic value to four decimals against the new radii. Bezel now 0.6304 cm3, approx 0.80 g; interference volume 5.4186 mm3. The frozen Rev P.5 carrier is untouched and re-proved. Still OPEN, still not for merge. |
| 2026-08-30 | Mechanical | **Third owner change to the OPEN Rev Q bezel: the aperture is made FLUSH on the left and right, and the inset wall becomes NON-UNIFORM.** The face opening goes out 1.00 mm per side to 32.90, and the side wall thickens until its inner face lands on it, removing the 1.45 mm rearward set-back that the skirt previously stood proud by on each side. The outer envelope is unchanged at 35.40 x 15.20. The three constraints solve uniquely to a 1.25 mm wall - 3.125 extrusions at 0.40, and a uniform 1.25 would also have dragged the vertical clear opening 13.60 -> 12.70 and cost another 0.45 mm of lit band, which the owner ruled out. The owner then clarified the loop rule itself: it is AT LEAST two loops, and the sides and the top/bottom need NOT carry the same number. That releases the wall from uniformity and lets all three constraints hold at once. AS BUILT: side wall 1.250 mm (3.125 loops, DERIVED from the flush requirement), top/bottom wall 0.800 mm (2.000 loops, entered, holds the 13.600 clear height), corners sweeping 0.800 -> 1.193 mm and never below two loops. The inner corner radius follows the THICKER wall at R1.75 = R3.00 - 1.25, which is not a free choice: it puts the inner corner arc centre on the same x as the outer, so the wall sweeps smoothly and bottoms out exactly at the top/bottom tangent. Any smaller inner radius squares the corner off and thins the wall below 0.800 - at R0 it collapses to 0.189 mm. R1.75 is the smallest value that keeps two full loops all the way round, and the validator re-measures it rather than trusting the derivation. COSTS NOTHING VERTICALLY: the clear opening goes 30.90 x 13.60 -> 32.90 x 13.60, the height untouched, so the visible lit band stays at 7.450 mm. The aperture gains 2.00 mm of width and loses the side ledge entirely. COSTS INSERTION FORCE: the interference is horizontal, so it is resisted by the SIDE wall - the one that just went to 1.25 mm. Bending stiffness scales with thickness cubed, so that wall is about 31x stiffer than the original 0.40 mm and 3.8x stiffer than the 0.80 mm it replaced there. Brief 3.8 wants the printed wall to take the deflection and the Perspex left unstressed; at 1.25 mm that is a materially harder ask, which makes the fit gauge MANDATORY rather than advisable. TWO KNOCK-ON MODEL FIXES, both found by the validator and both fixed at the root rather than waived. (1) The aperture rear section used to over-run 0.05 mm below the seating plane - harmless while the aperture was 30.90 wide inside a 33.80 skirt, but with the side flush the two share a width and the over-run bit the top of the wall at all four corners, showing up as 0.84 mm2 of ring area missing at z = 2.95 while z = 0.45 and 1.60 measured correctly. It now stops exactly on the seating plane. (2) The aperture rear corner radius was the window R0.80 against the skirt R1.75, so it bulged outside the skirt corner and left a crescent-shaped 90 degree ledge hanging over the aperture - 3.40 mm2 of unsupported overhang across four corners. The rear section now carries the skirt R1.75, the profiles match exactly, and ap_root_relief is back to 0.00 because the 0.02 anti-tangency dodge existed only to paper over that mismatch. Re-validated: 51/51 in Fusion, 44/44 offline, ring area 85.5432 mm2 and every region exact, no degenerate triangles, no unsupported overhang, lit band unchanged at 7.450 mm. Frozen Rev P.5 carrier untouched and re-proved. Still OPEN, still not for merge. |
| 2026-08-31 | Mechanical | **The 0.50 mm depth reduction is REVERTED - the cause was a printing issue, not the geometry - and with that the owner SIGNS THE BEZEL OFF AS COMPLETE.** bezel_lip_depth returns to 2.800, the Rev N engagement depth recovered from the released STEP and carried unchanged through this revision until the previous entry briefly cut it. Everything that cut moved moves back: wall rear tip z = +0.700 -> +0.200, total part depth 3.500 -> 4.000, clear of the Perspex rear face 0.700 -> 0.200, OLED glass clearance 1.000 -> 0.500, carrier clearance 0.754 -> 0.339, and the insert covers 2.600 of the 3.000 mm Perspex thickness again rather than 2.300 - so the 18 percent of wall contact the cut gave up comes back, with the grip and the resistance to rocking. A PRINTING ISSUE, NOT A DESIGN ONE, AND THE DISTINCTION MATTERS. The previous entry reasoned from the bottoming-out that 2.80 might be wrong for a continuous wall even though it was proven for two short Rev N rails. The reasoning was sound but the premise was false: the obstruction was in the print. 2.80 has now survived a physical offer-up, which is the first time it has been tested outside Rev N. THE PREVIOUS RESTRUCTURE IS KEPT, AND IT IS WHY THE REVERT WAS FREE: bezel_face_t stays ENTERED at 1.20 with bezel_t DERIVED as face + insert depth, so putting the depth back returns the total to exactly 4.000 on its own and the bezel face stays 1.20 proud of the Perspex. Under the old arrangement the revert would have had to move two numbers in step and could have left the face in the wrong place. SIGNED OFF. Confirmed on printed parts across this and the previous two entries: the INTERFERENCE FIT, the OPENING CORNER (R4.25 a good match) and the OPENING DIMENSIONS themselves (36.74 x 16.45, gauge-block method). NOT separately reported: the SLICER TWO-LOOP PREVIEW and the POWERED VISIBILITY TEST - parts printed and fitted, so the wall evidently laid, but neither was run as a check and both are recorded as NOT-RUN rather than passed, worth doing if the part is ever reprinted on a different machine or profile. The 0.339 mm carrier clearance is the one figure to carry forward. RE-VALIDATED: 52/52 in Fusion, 47/47 offline. Ring area 88.8247 mm2 at three depths and every region exact. Wall measured at 720 of 720 stations, min 0.8000 max 1.2500. Interference 16.6102 mm3, deepest exactly 0.1000 in X and 0.0750 in Y. Plug test 34.40 x 14.96 passes, 34.48 x 15.04 does not. Envelope 40.00000 x 20.30000 x 4.00000, front +4.20000, rear +0.20000. Mesh 3590 triangles, manifold, single component, no degenerate triangles, volume 594.615 mm3. Bezel 0.5951 cm3, approx 0.76 g in PETG. Frozen Rev P.5 carrier untouched and re-proved: all six files byte-identical, no revN/revO/revP path in the branch diff, git blob object ids identical to origin/main. |
| 2026-08-31 | Mechanical | **THE INSERT FITS - confirmed on a printed part - and the depth comes down 0.50 mm because it bottomed out before the bezel face seated.** The owner printed the geometry sized to the re-measured opening (36.940 x 16.600 into 36.740 x 16.450, 0.100 / 0.075 mm per side) and reports the fit good. That closes the interference question that had been the primary prototype gate since the brief amendment. One correction followed: at 2.80 mm the insert bottoms out before the bezel face seats against the Perspex, so bezel_lip_depth goes to 2.300, the wall rear tip moves z = +0.200 -> +0.700, and the part is 3.500 mm deep overall instead of 4.000. WHERE 2.80 CAME FROM AND WHY IT WAS WRONG HERE: it is the Rev N rail engagement depth, recovered from the released STEP and carried through this revision as PROVEN. It was proven - for two short rails on the side flanks. A continuous wall around the whole perimeter is a different thing: it can foul anything anywhere behind the opening and has roughly 100 mm of perimeter to find something with, where the rails had 8.6 mm. The Rev N figure was good evidence for Rev N and only a starting point for Rev Q, and this is the first time anything physical has tested it. ONE RELATIONSHIP HAD TO BE INVERTED TO HONOUR "NO OTHER CHANGES": the model had bezel_face_t = bezel_t - bezel_lip_depth with bezel_t entered at 4.00, so shortening the insert would have pushed the bezel FRONT FACE from +4.200 to +4.700 and made the bezel stand half a millimetre prouder of the Perspex - a visible external change and precisely what the instruction ruled out. bezel_face_t is now ENTERED at 1.20, being the whole of the Rev N external appearance, and bezel_t is DERIVED as face + insert depth. Shortening the insert now shortens the PART and the face stays where it is. WHAT IT BUYS: the shorter skirt reaches less far behind the Perspex, so two clearances improve unasked - carrier clearance 0.339 -> 0.754 mm, which recovers most of what the wider skirt had spent against the frozen Rev P.5 carrier and takes it off the watch list, and OLED glass clearance 0.500 -> 1.000 mm, double the brief minimum. WHAT IT COSTS: the insert covers 2.30 of the 3.00 mm Perspex thickness instead of 2.60, leaving 0.70 mm of cut edge unmasked at the BACK of the opening rather than 0.20. That is invisible from the front - the masking that matters is at the front face and is unchanged - but it is 18 percent less wall in contact, so slightly less grip and slightly less resistance to rocking, and the interference volume falls 16.610 -> 13.465 mm3 for the same reason. With PETG creep already on the list, adhesive on the flat seating face matters more for it. UNCHANGED: the 40.00 x 20.30 outer envelope, the 1.20 mm face standing proud of the Perspex, the 36.940 x 16.600 insert outer, the 34.440 x 15.000 clear opening and its 8.150 mm lit band, R4.250 / R3.000 corners, the 1.250 / 0.800 wall, the 0.100 / 0.075 mm fit, the 0.200 mm lead-in, the flush rule, the straight bore and the two-loop minimum. RE-VALIDATED: 52/52 in Fusion, 47/47 offline. Ring area 88.8247 mm2 at three depths (now z = 0.95, 1.85 and 2.95) and every region exact. Wall measured at 720 of 720 stations, min 0.8000 max 1.2500. Interference 13.4650 mm3, deepest exactly 0.1000 in X and 0.0750 in Y, confined to z 0.8000..3.0000. Plug test 34.40 x 14.96 passes, 34.48 x 15.04 does not. Mesh 3590 triangles, manifold, single component, no degenerate triangles, volume 550.221 mm3. Bezel 0.5506 cm3, approx 0.70 g in PETG. Frozen Rev P.5 carrier untouched and re-proved. Still OPEN, still not for merge. |
| 2026-08-31 | Mechanical | **THE PERSPEX OPENING IS MEASURED FOR THE FIRST TIME, and it is 1.54 mm wider and 1.15 mm taller than the figure this project carried for six revisions. R4.25 is restored on physical evidence, and the insert is now DERIVED from the measurement rather than entered.** THE CORNER, FIRST: the owner printed the R4.25 part, offered it into the real opening and found the corner a good match, retracting the previous appearance-based revert in as many words ("I was wrong"). That is the first physical information about the opening corner anywhere in this project and it outranks every calculation in the model, so R4.25 is back and the visible aperture corner returns to R3.00 with it. THE OPENING, SECOND: the owner then used the printed 35.400 x 15.450 insert as a GAUGE BLOCK, pushing it to one side and reading the slop that opened opposite - 1.34 mm horizontal, 1.00 mm vertical - so the opening is 35.400 + 1.34 = 36.74 and 15.450 + 1.00 = 16.45. The Rev C figures of 35.20 x 15.30 had never been corroborated by anything physical: Rev N located on two side rails only, so no released surface had ever touched the top or bottom of the opening and panel_open_h had no support from any part ever made. Every fit figure in this revision up to this point was computed against numbers nothing had checked, which is precisely why the interference-fit refinement looked impossible and the pull-back over-corrected. THE STRUCTURE, THIRD: insert outer = measured opening + declared interference. panel_open_w and panel_open_h now drive the envelope, the split wall, the clear opening, both corner radii, the fit gauge and both validators, so re-measuring is a two-number edit. The side wall changed hands with it - it used to be derived, absorbing whatever the flush requirement left over, and against the real 36.74 opening that would have forced 2.02 mm, five extrusion loops and roughly 130x the bending stiffness of the original 0.40 mm wall, the opposite of what brief 3.8 asks for, while pinning the clear width the owner had asked to grow. Both walls are now ENTERED (1.25 sides, 0.80 top and bottom) and all three face-opening values DERIVE from the skirt, which also makes X and Y symmetric for the first time. AS BUILT: insert outer 36.940 x 16.600 R4.250; inner = face opening = clear opening 34.440 x 15.000 R3.000; fit 0.100 mm per side across and 0.075 mm per side up; tip after the lead-in 36.540 x 16.200, which is 0.100 and 0.125 mm per side UNDER the opening so the part locates before it engages. THE CLEAR OPENING IS NOW LARGER THAN REV N IN BOTH AXES - 34.44 x 15.00 against 30.40 x 14.90 - and the visible lit band goes 8.100 -> 8.150 mm, above Rev N for the first time. That is the correction of a bad input, not a design gain. TWO THINGS GOT TIGHTER AND ARE RECORDED AS SUCH. Clearance to the frozen Rev P.5 carrier falls 0.939 -> 0.339 mm: still zero interference, but the larger skirt has spent two thirds of that margin and two FDM parts at +/-0.1 mm each make 0.339 a real number. The carrier is released and frozen, so any conflict is the bezel's to resolve - check it on the first dry fit with the carrier bolted up. And the bezel flange outboard of the skirt is now 1.530 mm at the sides against 2.300 before, so the black border is visibly slimmer; judge it from the front view before printing. ACCURACY: the owner reports the slop reading as hard to take and expects a further iteration. Two error sources stack - the reading itself, and the printed part being nominally rather than actually 35.400 x 15.450 - so treat the opening as +/-0.2 mm, which is twice the interference it sets. The five gauge tabs at 0.00/0.05/0.10/0.15/0.20 mm therefore bracket the MEASUREMENT as well as the fit: a tab that drops in loose says the opening is bigger than measured, one that will not enter says it is smaller, and the notch number says by how much. RE-VALIDATED: 52/52 in Fusion, 47/47 offline. Ring area 88.8247 mm2 at three depths and by region top 22.7520, bottom 22.7520, right 10.1250, left 10.1250, corners 23.0707 mm2 - every one exact. Wall measured at 720 of 720 stations, min 0.8000 max 1.2500. Corner sweep 0.800 -> 1.216, never below two loops; corner loop radii 4.050 and 3.650, the easiest to slice at any issue. Interference 16.6102 mm3, deepest exactly 0.1000 in X and 0.0750 in Y, confined to z 0.3000..3.0000, zero once the declared relief is applied. Plug test 34.40 x 14.96 passes, 34.48 x 15.04 does not. Aperture 15.0000 at z = 3.70, 3.20 and 1.60, spread 0.0000 - one straight bore. Mesh 3590 triangles, manifold, single component, no degenerate triangles, volume 594.615 mm3. Bezel 0.5951 cm3, approx 0.76 g in PETG. A duplicated section heading left in the build report by an earlier edit was also repaired. Frozen Rev P.5 carrier untouched and re-proved. Still OPEN, still not for merge. |
| 2026-08-30 | Mechanical | **Sixth owner change to the OPEN Rev Q bezel: the corner radii are REVERTED, everything else from the fifth change kept.** Directed on seeing the front view, without a print: the R4.25 outer corner put the VISIBLE aperture corner at R3.00, because the inner radius is (corner_r - wall_x) and the flush rule makes the face opening carry it, and on a 13.85 mm tall opening that left only 7.85 mm of straight run - the aperture read as a rounded slot rather than a rectangle. Both radii therefore go back to the pair they last held with a 1.25 mm side wall: OUTER R3.00, VISIBLE CORNER R1.75, giving 10.35 mm of straight run. THAT IS THE CONSISTENT REVERT, not an arbitrary one: the R3.40 that R4.25 was built from only ever existed as R3.00 plus the outward loop, and the fifth change removed that loop when it took 0.80 mm off the width, so R3.00 is exactly the value the owner set in the second change and the geometry the third change derived from it. IT ALSO IMPROVES MASKING: the unmasked corner crescent falls from 0.601 to 0.084 mm against a plausible R2.50 opening, and from 1.147 to 0.780 mm against a perfectly sharp one. AND IT SPENDS THE CORNER MARGIN, which is the cost and is recorded as such. The insert corner must stay at least as round as the opening corner or it jams before the flanks touch - a HARD failure, against the merely cosmetic failure of being too round. R4.25 covered opening corners all the way to R4.00; R3.00 covers them only to about R2.50 (R3.00 opening -> 0.125 mm penetration with no margin left, R3.50 -> 0.331 mm and it jams, R4.00 -> 0.538 mm). panel_open_corner_r is still UNRESOLVED - the drill-shank estimate was withdrawn - so nothing in the MODEL depends on it but the PART now does, and the opening corner becomes the tightest unmeasured margin in the design. The fit-gauge tabs carry the real R3.00 corner and answer it with no equipment at all: bedded on the flanks with a light gap at the corner apex means R3.00 is round enough; rocking on the corner without seating means the opening corner is larger and bezel_lip_corner_r has to go back up, at which point the appearance trade has to be made again with a real number in hand. THIS IS THE FIRST THING THE PROTOTYPE MUST CHECK. UNCHANGED from the fifth change: the 35.400 x 15.450 outer envelope, the 0.100 / 0.075 mm per side fit, the 1.250 / 0.800 mm wall, the 32.900 x 13.850 clear opening and its 7.575 mm lit band, the straight bore, the flush rule and the two-loop minimum. RE-VALIDATED: 52/52 in Fusion, 47/47 offline. Ring area 86.1682 mm2 at three depths and by region top 23.5200, bottom 23.5200, right 11.8125, left 11.8125, corners 15.5032 mm2 - every one exact. Wall measured at 720 of 720 stations, min 0.7950 max 1.2450. Corner sweep 0.800 -> 1.193, never below two loops; corner loop radii 2.800 and 2.400. Interference 17.5339 mm3, deepest exactly 0.1000 in X and 0.0750 in Y, zero once the declared relief is applied. Plug test 32.86 x 13.81 passes, 32.94 x 13.89 does not. Mesh 5050 triangles, manifold, single component, no degenerate triangles, volume 654.488 mm3. Bezel 0.6549 cm3, approx 0.83 g in PETG. Frozen Rev P.5 carrier untouched and re-proved. Still OPEN, still not for merge. |
| 2026-08-30 | Mechanical | **Fifth owner change to the OPEN Rev Q bezel: the fit is pulled back into range, and both stop conditions triggered by the fourth change are cleared.** Directed after reading the fourth change's finding, and cross-checked with the owner before modelling: width -0.80 mm, height -1.75 mm, outer corner radius +25%. AS BUILT the inset wall is 35.400 x 15.450 with an R4.250 outer corner, giving a fit of 0.100 mm per side across and 0.075 mm per side up against the measured 35.20 x 15.30 opening. Both sit inside the 0.05-0.15 mm band a thin printed wall takes up by FLEXING rather than by pushing on the acrylic, the smaller vertical figure being deliberate because it is resisted by the thinner 0.80 mm wall. THE LEAD-IN BUYS FREE ENTRY AGAIN: at the tip the skirt is 35.000 x 15.050, which is 0.100 mm per side under the opening across and 0.125 mm per side under it up, with the full section restored by z = +0.400, so the part locates before it engages instead of fighting from first contact as the fourth change left it. THE SIDE WALL RETURNS TO 1.250 mm - the -0.80 on the width exactly undoes the outward loop the fourth change added, so the wall is back to the 3.125 loops the flush requirement derives, and the interference is resisted by a wall about 31x stiffer in bending than the original 0.40 mm rather than 70x. WHY THE CORNER ONLY EVER GOES UP: the failure modes are asymmetric. An insert corner SQUARER than the opening corner touches before the flanks do, so the part jams and never seats - a hard failure. One that is ROUNDER merely leaves a crescent of cut edge visible at each corner apex - cosmetic. Every unit of uncertainty in the unmeasured opening corner is therefore spent on the round side. At R4.25 the flanks set the fit for any opening corner up to R4.00, covering the whole plausible range for an opening only 15.30 mm tall; at R4.50 the corner would take over at 0.228 mm and at R5.00 at 0.435 mm. The price is corner masking: the unmasked crescent is 1.147 mm against a sharp opening and 0.601 mm against a plausible R2.50, and this is the one place Rev Q's masking is knowingly incomplete. A drill-shank estimate of the opening corner was offered during this work and WITHDRAWN, so panel_open_corner_r remains UNRESOLVED and nothing in the model depends on it; the fit-gauge tabs carry the real R4.25 corner and settle which way round the two are, functionally, without a gauge. COSTS OPTICALLY: the clear opening goes 32.90 x 15.60 -> 32.90 x 13.85, because the wall thickness is unchanged and the face opening is flush to it, so the aperture tracks the insert height exactly. The lit band goes 8.450 -> 7.575 mm, 0.525 mm less than Rev N, all of it off the top; the bottom loses nothing and hides 0.525 mm more unlit board. The aperture corner also opens to R3.000 (= 4.25 - 1.25) where Rev N had R0.800 - a consequence of the corner margin, not a styling choice, and squaring it up would cost about 1.5 mm of opening width for 0.75 mm of squareness. WHAT STILL GATES IT, and none of it is CAD-settleable: acrylic is BRITTLE and stores tensile stress near a tool-marked cut edge instead of deforming, which is how crazing appears weeks later; and PRINT TOLERANCE IS THE SAME SIZE AS THE FIT - roughly +/-0.10 mm on a small external dimension, tending over nominal, so an intended 0.100 mm arrives anywhere between 0.00 and 0.25 mm. PETG also creeps, so a press fit slackens over months and adhesive on the flat seating face is the reliable retention now the pads are gone. The five gauge tabs at 0.00/0.05/0.10/0.15/0.20 mm now BRACKET the declared 0.100 mm two either side for the first time. RE-VALIDATED: 52/52 in Fusion, 47/47 offline. Ring area 83.4857 mm2 at three depths and by region top 21.5200, bottom 21.5200, right 8.6875, left 8.6875, corners 23.0707 mm2 - every one exact. Wall measured at 720 of 720 stations, min 0.7950 max 1.2450. Corner sweep 0.800 -> 1.216, never below two loops; corner loop radii 4.050 and 3.650, the easiest to slice at any issue. Interference 15.3914 mm3, deepest exactly 0.1000 in X and 0.0750 in Y, confined to z 0.3000..3.0000, zero once the declared relief is applied. Plug test 32.86 x 13.81 passes, 32.94 x 13.89 does not. Aperture 13.8500 at z = 3.70, 3.20 and 1.60, spread 0.0000 - one straight bore. Mesh 3660 triangles, manifold, single component, no degenerate triangles, volume 653.322 mm3. Bezel 0.6618 cm3, approx 0.84 g in PETG. Frozen Rev P.5 carrier untouched and re-proved. Still OPEN, still not for merge. |
| 2026-08-30 | Mechanical | **Fourth owner change to the OPEN Rev Q bezel: the interference fit. The geometry is exactly as instructed and fully validated; THE FIT IS NOT, and that is the finding.** Two moves, both scoped with the owner before modelling. (1) One extra 0.40 mm wall loop is added OUTWARD on the LEFT and RIGHT outer faces only: outer envelope 35.40 -> 36.20, side wall 1.25 -> 1.65 (4.125 loops). It is applied at the corners as a TRUE OUTWARD OFFSET, which takes the outer corner R3.00 -> R3.40 - not decoration, because the inner corner radius is (corner_r - wall_x), so holding the outer at R3.00 while the wall thickened would have dragged the OPENING corner R1.75 -> R1.35. The instruction was to leave the horizontal opening alone, and it comes through bit-for-bit identical. (2) The top and bottom walls move 1.00 mm out each: outer 15.20 -> 17.20, inner 13.60 -> 15.60, wall translated not thickened and still 0.800 mm. THE FACE OPENING HAD TO FOLLOW, to 15.60 with an R1.75 corner. At 15.35 it would have become the new limiter and delivered +1.83 mm of vertical opening instead of the +2.00 mm asked for; and at R0.80 the face corner is FULLER than the skirt's R1.75, so once the two shared extents it would have become the visible corner and sharpened the clear opening from R1.75 to R0.80. R1.75 leaves what the eye sees exactly as it was. WHAT IT BUYS: the aperture is now ONE STRAIGHT FLUSH BORE - face opening, skirt inner envelope and corner radius identical, so the Y taper that earlier issues carried (36.10 deg, forced because the face opening was taller than the whole wall and a straight aperture would have left the top and bottom wall runs DETACHED from the bezel face) is designed out, the wall root lands on its full 0.800 mm, and there is no ledge, set-back or corner crescent anywhere. The offline verifier measures the opening at three heights, two in the face plate and one down in the skirt, and gets 32.9000 x 15.6000 at every one, spread 0.0000. The clear opening goes 32.90 x 13.60 -> 32.90 x 15.60 and for the first time the lip GIVES BACK opening rather than costing it: the visible lit band goes 7.450 -> 8.450 mm, which is 0.350 mm MORE than Rev N ever showed. WHAT IT COSTS, AND THIS IS THE FINDING: both moves push material outward into the Perspex opening. The horizontal interference goes 0.100 -> 0.500 mm per side and the vertical goes from a 0.050 mm CLEARANCE to 0.950 mm of INTERFERENCE. At 36.20 x 17.20 into a MEASURED 35.20 x 15.30 opening the skirt is 1.00 mm oversize across and 1.90 mm oversize up - that is not a press fit, the part cannot enter the opening at all, and the 0.20 mm lead-in no longer buys free entry either (even at the tip the skirt is 0.60 mm over the opening width). Two readings are possible and CAD cannot choose: panel_open_h = 15.30 is a MEASURED Rev C value that no Rev N surface ever touched, so it is the least-corroborated number in the model and the one the vertical fit now depends on entirely; or the 1.00 mm per side move overshoots. The measured panel figures are DELIBERATELY NOT ADJUSTED to make the numbers look right - the generator, the validator and the offline verifier all state the interference plainly and all three refuse to soften it. RE-MEASURE THE PERSPEX OPENING BEFORE PRINTING A BEZEL. Two brief stop conditions are consequently TRIGGERED, both by explicit owner direction. TWO DEFECTS FOUND AND FIXED IN THE OFFLINE VERIFIER, and one of them invalidates a figure published in the previous issue. Its inward wall walk stopped at 0.600 mm, which is less than even the 0.80 mm top wall, so it never found an exit, dropped every station and left the wall array EMPTY - the three gates depending on it were never created at all, which is not the same as passing, and the previous issue's "measured wall, 720 stations, min 0.8000, max 1.2500" was reading the gate's LABEL, which prints the expected constants, not a measurement. The walk now reaches twice the thickest wall and a new gate fails unless all 720 stations return a figure. Separately, the even-odd inside test double-counted a ray landing exactly on a tessellation seam: Fusion splits the 0.40 mm window chamfer at z = 4.000, and the walk steps in exact multiples of 0.005 from y = 8.600, so it hit y = 8.000 every time and read solid material as void. Coincident crossings are now collapsed before the parity count. RE-VALIDATED: 52/52 in Fusion, 46/46 offline. Ring area 102.1057 mm2 at three depths and by region top 23.5200, bottom 23.5200, right 17.1600, left 17.1600, corners 20.7457 mm2 - every one exact. Wall MEASURED at 720 of 720 stations, min 0.7950 max 1.6450. Corner sweep 0.800 -> 1.455, never below two loops. Interference 182.0862 mm3, deepest exactly 0.5000 in X and 0.9500 in Y, zero once the declared relief is applied on both axes. Plug test 32.86 x 15.56 passes, 32.94 x 15.64 does not. Mesh 3886 triangles, manifold, single component, no degenerate triangles, volume 629.629 mm3. No unsupported overhang; worst wall overhang 0.000 deg. Bezel 0.6300 cm3, approx 0.80 g in PETG. Frozen Rev P.5 carrier untouched and re-proved. Still OPEN, still not for merge. |

## Hardware Revisions

| Rev | Date  | Change | Notes |
|-----|---|---|---|
| A | _TBD_ | Initial design | |
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

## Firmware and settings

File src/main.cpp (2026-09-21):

/** Phase 1 coordinator: logical power/display state plus continuous OTA. */
#include <Arduino.h>
#include <cstring>
#ifndef PIO_UNIT_TESTING
#include "buttons.h"
#include "display.h"
#include "hardware.h"
#include "lighting.h"
#include "ota.h"
#include "pots.h"
#include "power.h"
#include "settings.h"
#include "version.h"
#include "wiim.h"

namespace {

decca::display::ViewState g_viewState;
decca::buttons::SourceMode g_sourceMode =
    decca::buttons::SourceMode::DigitalStreamer;
uint16_t g_potValues[4]{};
constexpr uint16_t kControlPresentationDeadband = 5;
constexpr uint32_t kConnectivityFaultRefreshMs = 1000;
decca::wiim::Status g_lastWiimStatus = decca::wiim::Status::Disabled;
uint32_t g_lastConnectivityFaultRefreshMs = 0;
decca::wiim::Status g_presentedConnectivityFault =
    decca::wiim::Status::Disabled;
decca::wiim::Playback g_lastPlayback = decca::wiim::Playback::None;
char g_lastTitle[decca::wiim::kTitleCapacity + 1]{};
char g_lastArtist[decca::wiim::kArtistCapacity + 1]{};
decca::settings::Source g_lastWiimDisplaySource =
    decca::settings::Source::DigitalStreamer;

constexpr decca::pots::Pot kPots[4] = {
    decca::pots::Pot::Volume,
    decca::pots::Pot::Bass,
    decca::pots::Pot::Treble,
    decca::pots::Pot::Balance,
};

constexpr decca::display::Control kControls[4] = {
    decca::display::Control::Volume,
    decca::display::Control::Bass,
    decca::display::Control::Treble,
    decca::display::Control::Balance,
};

void applySourceState(bool showConfirmation) {
    g_sourceMode = decca::buttons::sourceMode();
    const bool vinyl = g_sourceMode == decca::buttons::SourceMode::Vinyl;
    g_viewState.source = vinyl ? decca::settings::Source::Vinyl
                               : decca::settings::Source::DigitalStreamer;
    g_viewState.functionName = vinyl ? "VINYL" : "DIGITAL STREAMER";
    decca::wiim::requestSource(g_viewState.source);

    if (g_viewState.power == decca::display::PowerState::On) {
        decca::display::setState(g_viewState);
        if (showConfirmation) {
            decca::display::showFunction();
        }
    }

    Serial.print("[SOURCE] state=");
    Serial.println(vinyl ? "VINYL" : "DIGITAL STREAMER");
}

void readInitialPotState() {
    decca::pots::update();
    for (uint8_t i = 0; i < 4; ++i) {
        g_potValues[i] = decca::pots::value(kPots[i]);
    }
    g_viewState.volume = g_potValues[0];
    g_viewState.bass = g_potValues[1];
    g_viewState.treble = g_potValues[2];
    g_viewState.balance = g_potValues[3];
}

void updatePotState() {
    decca::pots::update();

    int8_t changedControl = -1;
    uint16_t* viewValues[4] = {
        &g_viewState.volume,
        &g_viewState.bass,
        &g_viewState.treble,
        &g_viewState.balance,
    };

    for (uint8_t i = 0; i < 4; ++i) {
        const uint16_t value = decca::pots::value(kPots[i]);
        const uint16_t change = value > g_potValues[i]
                                    ? value - g_potValues[i]
                                    : g_potValues[i] - value;
        if (change < kControlPresentationDeadband) {
            continue;
        }
        g_potValues[i] = value;
        *viewValues[i] = value;
        if (changedControl < 0) {
            changedControl = static_cast<int8_t>(i);
        }
    }

    if (changedControl >= 0 &&
        g_viewState.power == decca::display::PowerState::On) {
        decca::display::setState(g_viewState);
        const uint8_t index = static_cast<uint8_t>(changedControl);
        decca::display::showControl(kControls[index], g_potValues[index]);
    }

    if (changedControl == 0) {
        decca::wiim::requestVolume(
            static_cast<uint8_t>((g_potValues[0] + 5U) / 10U));
    }
}

void applyPowerState() {
    const bool powerOn = decca::power::isOn();
    g_viewState.power = powerOn ? decca::display::PowerState::On
                                : decca::display::PowerState::Standby;
    decca::display::setState(g_viewState);
    decca::wiim::requestPower(powerOn);

    Serial.print("[POWER] state=");
    Serial.println(powerOn ? "ON" : "STANDBY");
}

void applyWiimState() {
    decca::wiim::update();
    const decca::wiim::Snapshot& snapshot = decca::wiim::snapshot();
    const bool statusChanged = snapshot.status != g_lastWiimStatus;
    const bool displayStateChanged =
        snapshot.playback != g_lastPlayback ||
        std::strncmp(snapshot.title, g_lastTitle, sizeof(g_lastTitle)) != 0 ||
        std::strncmp(snapshot.artist, g_lastArtist, sizeof(g_lastArtist)) != 0 ||
        g_viewState.source != g_lastWiimDisplaySource ||
        g_viewState.controllerWifiBars != snapshot.controllerWifiBars;

    const bool connectivityFault =
        (snapshot.status == decca::wiim::Status::WaitingForNetwork ||
         snapshot.status == decca::wiim::Status::Error) &&
        g_viewState.power == decca::display::PowerState::On;
    if (connectivityFault) {
        const uint32_t now = millis();
        if (g_presentedConnectivityFault != snapshot.status ||
            (now - g_lastConnectivityFaultRefreshMs) >=
                kConnectivityFaultRefreshMs) {
            decca::display::showStatus(
                snapshot.status == decca::wiim::Status::WaitingForNetwork
                    ? "NO CONTROLLER WI-FI"
                    : "WIIM NOT RESPONDING");
            g_lastConnectivityFaultRefreshMs = now;
            g_presentedConnectivityFault = snapshot.status;
        }
    } else {
        g_presentedConnectivityFault = decca::wiim::Status::Disabled;
    }

    if (statusChanged) {
        g_lastWiimStatus = snapshot.status;
    }

    if (!displayStateChanged) return;
    g_lastWiimDisplaySource = g_viewState.source;
    g_lastPlayback = snapshot.playback;
    std::strncpy(g_lastTitle, snapshot.title, sizeof(g_lastTitle) - 1U);
    std::strncpy(g_lastArtist, snapshot.artist, sizeof(g_lastArtist) - 1U);
    g_lastTitle[sizeof(g_lastTitle) - 1U] = '\0';
    g_lastArtist[sizeof(g_lastArtist) - 1U] = '\0';

    const bool digital =
        g_viewState.source == decca::settings::Source::DigitalStreamer;
    g_viewState.title = digital && snapshot.metadataValid ? g_lastTitle : nullptr;
    g_viewState.artist =
        digital && snapshot.metadataValid ? g_lastArtist : nullptr;
    g_viewState.playing = snapshot.playback == decca::wiim::Playback::Playing;
    g_viewState.controllerWifiBars = snapshot.controllerWifiBars;
    decca::display::setState(g_viewState);
}

void applyLightingState() {
    const bool lightsRequested =
        decca::buttons::lightingRequest() ==
        decca::buttons::LightingRequest::On;
    const uint8_t target = decca::power::isOn() && lightsRequested
                               ? decca::settings::get().dial
                               : 0;
    if (decca::lighting::brightness(decca::lighting::Zone::Dial) == target) {
        return;
    }

    decca::lighting::setBrightness(decca::lighting::Zone::Dial, target);
    Serial.print("[LIGHTING] duty=");
    Serial.println(target);
}

}  // namespace

void setup() {
    // Establish lighting safe-off before serial, display or network setup.
    decca::hardware::init();
    Serial.begin(115200);
    Serial.print("[SYSTEM] firmware=");
    Serial.println(decca::version::kFirmwareVersion);
    decca::settings::init();
    decca::buttons::init();
    decca::pots::init();
    decca::lighting::init();
    decca::power::init(
        decca::buttons::isPressed(decca::buttons::Button::OnOff));
    applyLightingState();
    g_viewState.power = decca::power::isOn()
                            ? decca::display::PowerState::On
                            : decca::display::PowerState::Standby;
    readInitialPotState();
    decca::display::init();
    applySourceState(false);
    applyPowerState();
    decca::ota::init();
    decca::wiim::init();
    decca::wiim::requestSource(g_viewState.source);
    decca::wiim::requestVolume(
        static_cast<uint8_t>((g_potValues[0] + 5U) / 10U));
    decca::wiim::requestPower(decca::power::isOn());
}

void loop() {
    decca::buttons::update();
    updatePotState();
    if (decca::power::update(
            decca::buttons::isPressed(decca::buttons::Button::OnOff))) {
        applyPowerState();
    }
    const decca::buttons::SourceMode sourceMode = decca::buttons::sourceMode();
    if (sourceMode != g_sourceMode) {
        applySourceState(true);
    }
    applyLightingState();
    applyWiimState();
    decca::display::update();
    decca::ota::update();
}
#endif

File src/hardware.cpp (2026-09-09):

/**
 * @file    hardware.cpp
 * @brief   Board-level initialisation.
 */
#include "hardware.h"

#include <Arduino.h>
#include <Wire.h>

namespace decca::hardware {

void init() {
    // GPIO18 can float while the ESP32 resets. Take active control at the first
    // opportunity and keep it low until LEDC is attached at duty 0.
    pinMode(kDialLightingPwm, OUTPUT);
    digitalWrite(kDialLightingPwm, LOW);

    pinMode(kPotVolume, INPUT);
    pinMode(kPotBass, INPUT);
    pinMode(kPotTreble, INPUT);
    pinMode(kPotBalance, INPUT);

    analogReadResolution(kAdcResolutionBits);
    analogSetPinAttenuation(kPotVolume, ADC_11db);
    analogSetPinAttenuation(kPotBass, ADC_11db);
    analogSetPinAttenuation(kPotTreble, ADC_11db);
    analogSetPinAttenuation(kPotBalance, ADC_11db);

    pinMode(kSwitchOnOff, INPUT_PULLUP);
    pinMode(kButtonVhf, INPUT_PULLUP);
    pinMode(kSwitchStereoMono, INPUT_PULLUP);

    Wire.begin(kDisplaySda, kDisplayScl);

    ledcSetup(kDialLightingPwmChannel,
              kDialLightingPwmFrequencyHz,
              kDialLightingPwmResolutionBits);
    ledcAttachPin(kDialLightingPwm, kDialLightingPwmChannel);
    ledcWrite(kDialLightingPwmChannel, 0);
}

}  // namespace decca::hardware

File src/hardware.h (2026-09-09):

/**
 * @file    hardware.h
 * @brief   Board-level pin map and hardware initialisation.
 */
#pragma once

#include <cstdint>

namespace decca::hardware {

// GPIO32–35, display GPIO21/22, on/off GPIO14, VHF GPIO26 and lighting PWM
// GPIO18 are verified. Stereo/Mono GPIO25 logic is verified; the retained
// physical switch fault is tracked as HW-SW-01.
constexpr uint8_t kPotVolume = 32;
constexpr uint8_t kPotBass = 33;
constexpr uint8_t kPotTreble = 34;
constexpr uint8_t kPotBalance = 35;
constexpr uint8_t kSwitchOnOff = 14;
constexpr uint8_t kButtonVhf = 26;
constexpr uint8_t kSwitchStereoMono = 25;
constexpr uint8_t kDisplaySda = 21;
constexpr uint8_t kDisplayScl = 22;
constexpr uint8_t kDialLightingPwm = 18;

constexpr uint8_t kAdcResolutionBits = 12;
constexpr uint8_t kDialLightingPwmChannel = 0;
constexpr uint32_t kDialLightingPwmFrequencyHz = 1000;
constexpr uint8_t kDialLightingPwmResolutionBits = 8;

void init();

}  // namespace decca::hardware

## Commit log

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2026-08-24 feat(display): implement presentation contract [FR-DSP-02/03/06/07]
    Add the non-blocking five-frame Decca startup, mapped-function hierarchy, fixed-size now-playing state and fallback, two-second control overlays, function confirmation, and expanded behavioural coverage per ADR-0007.
    [display.h]
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2026-08-27 mech(display-mount): add rev A Fusion 360 CAD from spec v1.0
    Parametric build of the front bezel and rear OLED carrier per
    Decca_OLED_Display_Mount_Spec_v1.0, with reference bodies for the original
    3 mm Perspex panel and the Pi Hut SH1106 module. All governing dimensions are
    exposed as named user parameters.
    Validation (boolean intersection + minimum distance):
    - all eight interference pairs clear
    - OLED glass to Perspex rear face 0.300 mm, set by hard carrier datums
    - active-area centre coincident with the opening centre (X +0.0000, Y +0.0000)
    - 142.7 mm2 of distributed PCB bearing; no load path through the OLED glass
    - M2 bolt and driver corridors clear of the bezel; header service envelo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
    [Decca_Display_Mount_revA.f3d, Decca_Display_Mount_revA_assembly.step, Front_Bezel_revA.step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]
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2026-08-27 mech(display-mount): rev C from Rev B print test
    Corrects two dimensions the spec had as locked, both measured off the printed
    prototype: fixing pitch 48.00 -> 49.00 mm, and the fascia opening
    35.50 x 15.80 -> 35.20 x 15.30 mm. carrier_w is now derived as
    panel_fix_pitch + boss_od = 56.50 mm, which is 0.50 mm outside spec section 5's
    54-56 mm range - a deviation forced by the pitch correction.
    Root cause of the PCB not seating flush: the 4-pin header's display-side solder
    protrusions stand well over the 0.60 mm relief pocket Rev B provided, so they
    bottomed out and held the board off its datum. The relief is now a full
    16.00 x 6.50 mm through-slot in the front plate, outside the fascia open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
    [Decca_Display_Mount_revB.f3d, Decca_Display_Mount_revB_assembly.step, Decca_Display_Mount_revC.f3d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]
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2026-08-27 mech(display-mount): rev D from Rev C fit test
    Removes the Rev C top leaf spring and its two anchor legs. They cleared the PCB
    in the solid model, so interference analysis reported nothing, but they were
    rigid material lying across the insertion path behind the board's top corners -
    a retention feature that only works if the part can be rotated in, placed at the
    same end as the locating posts that prevent rotation. The board could not be
    inserted at all. The top now carries nothing but the two plain locating posts.
    Bottom retention reverts from the Rev C rigid lips to the Rev B sprung snap
    pegs, stiffened rather than marginally adjusted: shaft 2.70 -> 2.80, slot
    1.00 -> 0.70 (half-section 0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
    [Decca_Display_Mount_revC.f3d, Decca_Display_Mount_revC_assembly.step, Decca_Display_Mount_revD.f3d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]
2026-08-27 mech(display-mount): rev E - rear-access cable-tie anchor
    The Rev D cable-tie anchor was two slots cut through the flange in Z. That face
    is the Perspex seating plane, so the slots opened onto the panel with no gap
    behind them and no tie could be threaded. The feature was unbuildable as drawn,
    not merely tight.
    A first replacement also failed and the threading check caught it before this
    commit: a stand-off bar whose aperture ran in Y exited 0.25 mm short of the tray
    wall, so it was blocked at one end.
    Final form is two stand-off bar anchors on the flange REAR face with the
    aperture running in X, open into free space at both ends: 3.70 (Y) x 1.60 (Z)
    mm, 6.00 mm long, at x +/-5.0 to 11.0,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
    [Decca_Display_Mount_revD.f3d, Decca_Display_Mount_revD_assembly.step, Decca_Display_Mount_revE.f3d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]
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2026-08-27 mech(display-mount): rev G - mirror the layout, fix bezel location
    Mounting orientation corrected. With the set upright and the display reading the
    right way up, the header wires exit ABOVE the window; every revision up to F had
    the header below it. That is not a local fix - the header edge determines which
    end carries the wide bare-PCB strip, which sets the cavity, the display window
    and the glass position, so the whole carrier mirrors.
    Implemented by building in the old frame and rotating 180 degrees about Z. The
    part is symmetric in X, so this is exactly a Y-mirror and every feature moves
    together with no risk of a missed sign flip. PCB centre y -4.00 -> +4.00, header
    edge now y +20.75,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
    [Decca_Display_Mount_revF.f3d, Decca_Display_Mount_revF_assembly.step, Decca_Display_Mount_revG.f3d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]
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2026-08-28 mech(display-mount): rev H - retention at both ends
    Solder pin interference: the tested part was Rev F, where the through cut-out sat
    on the opposite edge from the header so the pins bottomed out on a 0.60 mm
    recess. Rev G already moved it; Rev H confirms it at 16.00 mm on the header edge,
    reaching 6.30 mm inboard against a 7.62 mm header row sitting 2.20 mm from the
    edge. Widening it to 20 mm was tried and reverted - width was never the problem
    and it cost 13 mm2 of PCB bearing.
    Retention. Snap nose 3.20 -> 3.35 mm, so the radial hook goes 0.100 -> 0.175 mm
    for 75% more grip at 2.87% peak strain, still inside PETG.
    All four holes cannot carry sprung pegs. The narrow-end pair sit 0.70 mm f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
    [Decca_Display_Mount_revG.f3d, Decca_Display_Mount_revG_assembly.step, Decca_Display_Mount_revH.f3d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]
2026-08-28 mech(display-mount): rev I - header relief at both ends
    Three revisions have gone on establishing which PCB edge carries the header, and
    two prints were lost to getting it wrong. This stops arguing about it.
    Both PCB edges now have a full 16.00 mm through cut-out at full depth through the
    2.30 mm front plate, and the shallow 0.60 mm recess is removed entirely. There is
    no longer a wrong end to get wrong: the board fits either way up.
    The cost is close to nothing. A 0.60 mm recess already stands clear of the PCB
    face, so it was contributing zero bearing - converting it to a through cut-out is
    free. The only chargeable change is widening it from 12.00 to 16.00 mm to match
    the other end, wort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
    [Decca_Display_Mount_revH.f3d, Decca_Display_Mount_revH_assembly.step, Decca_Display_Mount_revI.f3d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]
2026-08-28 mech(display-mount): rev J - complete the retaining lip, restore end walls
    End walls. Rev I cut a notch through both outside tray walls for rearward pin
    clearance. It was never needed - the header sits about 0.50 mm inside the cavity
    and its pins project straight back past a tray only 5.80 mm deep, so they clear
    the walls entirely. Both notches removed; both end walls are full height again,
    verified at the rear face.
    The retaining lip. Yes, it is a retainer standing in for the two sprung pegs that
    the narrow end cannot carry, and it was not finished. As built in Rev H/I it
    presented a square face to the incoming board - nothing to cam it open - so it
    would have fought insertion rather than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
    [Decca_Display_Mount_revI.f3d, Decca_Display_Mount_revI_assembly.step, Decca_Display_Mount_revJ.f3d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]
2026-08-28 mech(display-mount): rev K - four sprung pegs, no cantilever, optional bar
    The Rev J integrated retaining lip is removed. It was a 26 mm bridge starting
    3.90 mm up with an unsupported underside; it would have drooped, and a drooped
    spring is the wrong shape in the one dimension that matters. No cantilever,
    bridge or unsupported overhang now remains anywhere in the carrier, which also
    shrinks from 48.35 to 45.10 mm tall since the lip's anchor legs needed 3.25 mm of
    extra cavity.
    Correction: I previously said four sprung pegs was impossible because the 4.80 mm
    counterbore needs 2.40 mm of material all round and the narrow end has 0.70 mm to
    the window edge. That was wrong - the counterbore is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
    [Decca_Display_Mount_revJ.f3d, Decca_Display_Mount_revJ_assembly.step, Decca_Display_Mount_revK.f3d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]
2026-08-28 mech(display-mount): rev L - retainer bar across the board centre
    Moves the optional retainer bar from the end of the board to its centre, where it
    spans the short axis and drops into a notch in each side wall. Better on three
    counts: it is clear of the header whichever end that lands at, so it inherits the
    orientation-proofing of Rev I; the end wall keeps its full height instead of
    needing the machined shelf Rev K cut into it; and no PCB datum bearing is spent
    at the ends.
    One thing genuinely changes with the move. At the ends the bar had front-plate
    datum directly opposite it and could safely clamp. At the centre there is only
    the open display window behind the board - nothing opposes the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
    [Decca_Display_Mount_revK.f3d, Decca_Display_Mount_revK_assembly.step, Decca_Display_Mount_revL.f3d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]
2026-08-28 mech(display-mount): rev M - offset the retainer bar toward the tie flange
    Shifts the retainer bar 4.00 mm toward the tie-flange / header edge, from
    y +1.00..+7.00 to y +5.00..+11.00 in the final model, leaving 6.75 mm to the
    header keep-out. The side-wall notches move with it. Driven by a new parameter
    bar_y_off, measured toward the tie-flange edge in the final model; the build
    frame is mirrored, so the offset is applied negatively there.
    The bar still lies over the open display window with no front-plate datum
    opposite it, so it remains a clearance stop and not a clamp: front face 0.05 mm
    behind the PCB rear plane, verified at 0.050 mm minimum distance. That was
    re-checked at the new posi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
    [Decca_Display_Mount_revL.f3d, Decca_Display_Mount_revM.f3d, Decca_Display_Mount_revM_assembly.step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]
2026-08-28 mech(display-mount): rev N - correct the depth chain, screen sits flush
    Measured on the printed part: the glass sat 1.50 mm behind the flush seating face
    instead of the intended 0.30. The 1.20 mm error traces to one wrong assumption -
    oled_glass_standoff 0.60 plus oled_glass_t 1.40 gave 2.00 mm of glass proud of
    the PCB front face, where the real figure is 0.80 mm. The front plate was
    therefore 1.20 mm too thick and held the board that far back.
    Both guessed parameters are replaced by a single measurement-derived
    oled_glass_proud = 0.80, and the plate follows: 2.30 -> 1.10 mm. Glass front face
    is now at z -0.30, the intended 0.30 mm behind flush, verified.
    WARNING - this creates a hard con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
    [Decca_Display_Mount_revM.f3d, Decca_Display_Mount_revM_assembly.step, Decca_Display_Mount_revN.f3d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]
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2026-08-28 mech(display-mount): rev P - rear-loaded carrier, nothing ahead of the PCB
    Implements the corrected rear-loaded architecture from the Rev O redesign
    specification. Clean design in its own new Fusion document; no geometry and no
    design decision is carried over from the closed Rev O implementation branch.
    The topology, front to rear: Perspex, a 0.30 mm controlled optical gap, OLED
    glass, OLED PCB, four rear support shoulders bearing on the PCB REAR face at
    z -2.70, then the carrier. The Rev N 1.10 mm front plate and the separate
    retainer bar are both deleted.
    Nothing lies between the OLED PCB front face and the Perspex. That is stated as
    a machine-checked invariant rather than an intention -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
    [Decca_Display_Mount_revP.f3d, Decca_Display_Mount_revP_assembly.step, Rear_Display_Carrier_revP.step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]
2026-08-28 mech(display-mount): rev P released - tips reduced, all validations pass
    The project owner has confirmed the OLED's front-side solder protrusion will be
    reduced, which closes the only open item on Rev P.
    oled_tip_proud goes 1.50 -> 1.00 mm, the accepted preparation limit. The budget
    is fixed by the optical chain at gap 0.30 + glass proud 0.80 = 1.10 mm, so
    1.00 mm leaves 0.10 mm of clearance to the Perspex; 1.10 mm is the hard ceiling.
    The full 0.40 -> 2.00 mm sweep is retained in the validation record as the
    evidence for where that limit comes from, along with the note that 1.50 mm was
    never compatible with a 0.30 mm gap under any carrier architecture.
    The carrier does not change. Rear_Di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
    [Decca_Display_Mount_revP.f3d, Decca_Display_Mount_revP_assembly.step]
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2026-08-29 mech(display-mount): rev P.2 - physical retention failure, corrected architecture
    The printed Rev P carrier failed its retention test: the OLED falls forward
    through the loose carrier. The "released / all validations pass" status is
    withdrawn. Rev P is OPEN.
    The failure is architectural, not a tolerance adjustment. Rev P.1 loaded the
    module from the rear and put its only positive shoulders at the PCB REAR plane,
    so those shoulders restrained the opposite direction. Once the board passed
    them, nothing prevented further forward travel. The only loose-carrier restraint
    was four 0.10 mm edge tongues acting through assumed friction. The old gate
    checked that the shoulders existed, that the tongu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
    [Decca_Display_Mount_revP.f3d, Decca_Display_Mount_revP_assembly.step, Rear_Display_Carrier_revP.step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]
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2026-08-29 docs(bom): reconcile open components
    Add the missing 5 V input, protection and distribution parts; distinguish procurement status; and reconcile the readable Phase 2 list with the locked ZA3 architecture.
    [phase1.csv, phase2.csv]
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2026-08-29 mech(display-mount): rev P.3 - lighting-unit clearance and original captive nuts
    Rev P.2 PASSED physically for OLED retention and Perspex fit. That architecture
    is carried through untouched and re-validated identical: flush-side insertion,
    fixed rear PCB datum pads, plain and sprung locating posts, snap retention and
    release, OLED Z position, 0.30 mm gap, active-area centring, 35.20 x 15.30
    aperture, exact 49.00 mm pitch, carrier-to-Perspex hard stops, existing bezel.
    This is a bounded amendment to the radio-side interface only.
    1. LIGHTING-UNIT CLEARANCE
    The retained original Decca lighting unit cannot be removed, and the continuous
    transverse end rail below the sprung-post pair fouled i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
    [Decca_Display_Mount_revP.f3d, Decca_Display_Mount_revP_assembly.step, Hex_Pocket_Fit_Coupon_revP.step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]
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2026-08-29 mech(display-mount): rev P.4 - delete the synthetic keepout, close the rear OLED bay
    Bounded correction on top of Rev P.3, in the same open PR. The Rev P.2
    architecture that passed physically is untouched: front/Perspex-side insertion,
    fixed rear PCB datum pads, plain and sprung locating posts, positive
    loose-carrier retention, deliberate removal, the OLED Z position and 0.30 mm
    Perspex gap, active-area centring, the 35.20 x 15.30 aperture, the exact
    49.00 mm pitch, the original captive-nut fastener interface and the
    carrier-to-Perspex hard-stop load path. The Rev P.3 lower end-rail and
    cable-tie deletion is retained exactly as printed.
    1. Remove the synthetic lighting keepout (brief 8.1)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
    [Decca_Display_Mount_revP.f3d, Decca_Display_Mount_revP_assembly.step, Hex_Pocket_Fit_Coupon_revP.step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]
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2026-08-29 mech(display-mount): rev P.5 - four sprung posts, 180 deg datum, 6.00 mm carrier
    Mandatory amendment implementing brief 5.3 and 8.4 together, because they
    interact: the module is rotated, the carrier is shortened, and the posts have to
    be re-solved inside the new envelope. Unlike Rev P.3 and P.4 this changes
    load-bearing numbers, so nothing is inherited unchecked.
    1. Four sprung retaining posts (brief 5.3)
    Both plain locating posts are deleted and replaced by sprung
    locating-and-retaining posts. All four PCB mounting holes now hold a split
    sprung post with a positive retaining nose.
    Deleted completely: plain_post_d, plain_relief_d, plain_relief_depth,
    plain_lead, plain_setback, plain_post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
    [Decca_Display_Mount_revP.f3d, Decca_Display_Mount_revP_assembly.step, Hex_Pocket_Fit_Coupon_revP.step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]
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2026-08-29 mech(display-mount): rev P.5 - move both fixing centres 7.00 mm toward the bottom
    Mandatory amendment to the Rev P.5 work in PR #2, implementing brief 8.4 as
    amended at main d7ac584. BOTTOM is -Y: the open, cut-away side of the carrier
    that carries the four-pin connector opening.
    1. The correction
    Both carrier fixing centres move exactly 7.00 mm toward that bottom relative to
    the complete OLED-dependent group. New named parameter:
    carrier_fix_y_from_previous = -7.00 mm
    The moved features are the two bores, the two structural bosses, the two captive
    -nut hex pockets, the two retention ridges, the two fixing arms and the local
    hard-stop / load-path faces. They stay on one common horizo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
    [Decca_Display_Mount_revP.f3d, Decca_Display_Mount_revP_assembly.step, Hex_Pocket_Fit_Coupon_revP.step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]
2026-08-29 mech(display-mount): rev P.5 RELEASED - prototype built and physically validated
    The Rev P.5 carrier has been manufactured, installed in the radio and tested.
    Every physical test passed:
    Perspex fit and tolerances PASS
    OLED front insertion and removal PASS
    all four sprung posts, retention PASS
    no collision with the original Decca lighting unit PASS
    bottom / open connector-side clearance PASS
    reduced 6.00 mm carrier thickness PASS
    enlarged 14.00 x 4.19 mm four-pin connector opening PASS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
    [Decca_Display_Mount_revP.f3d, Decca_Display_Mount_revP_assembly.step, Hex_Pocket_Fit_Coupon_revP.step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]
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2026-08-30 mech(display-bezel): rev Q OPEN - continuous full-perimeter masking lip
    Bezel only. The released Rev P.5 carrier is frozen and is proved unchanged.
    Replaces the two Rev N side locating rails with ONE continuous rearward
    masking lip around the left, right, top, bottom and all four corners of the
    measured 35.20 x 15.30 mm Perspex opening. The lip conceals the visible cut
    edge and locates the bezel. It works on clearance, not interference: it is
    not a snap, not a clamp and not a press fit, and it carries no load.
    Retention remains removable adhesive on the unchanged recessed pads.
    AS BUILT
    lip outer envelope 34.900 x 15.000
    lip inner envelope 34.100 x 14.200 derived from t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
    [Bezel_Corner_Gauge_revQ.step, Bezel_Corner_Gauge_revQ_COUPON_R040.stl, Bezel_Corner_Gauge_revQ_COUPON_R060.stl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]
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2026-08-30 mech(display-bezel): rev Q - interference fit and a two-loop inset wall
    Rebuilt to brief commit 7b107f2 ("require two-loop inset wall"), which
    supersedes ebfa277 via edab34b ("define Rev Q interference fit"). Still
    bezel only. Still OPEN. The released Rev P.5 carrier is frozen and proved
    unchanged.
    WHAT THE AMENDMENTS CHANGED
    first issue as built now
    bezel face opening 30.40 x 14.90 30.90 x 15.35
    inset-wall outer envelope 34.90 x 15.00 35.40 x 15.20
    horizontal fit 0.15 clearance 0.10 INTERFERENCE per side
    vertical fit 0.15 clearance 0.05 clearance per side
    wall 0.40 (one loop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
    [Bezel_Corner_Gauge_revQ.step, Bezel_Corner_Gauge_revQ_COUPON_R040.stl, Bezel_Corner_Gauge_revQ_COUPON_R060.stl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]
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2026-08-30 mech(display-bezel): untrack a stale hand-exported Front_Bezel_revQ.3mf
    Committed by accident in 065f39c via `git add -A`. It is not a generated
    artefact: it was hand-exported from Fusion at 13:07:58, about half an hour
    before the pad-deletion and R3.00 rebuild, and it still contains the
    SUPERSEDED geometry - the two adhesive pads are present (8 vertices at
    z = +3.300) and the wall corners are the old R2.00.
    Tracking it under that name is a live hazard: anyone reaching for a
    slicer-ready file would take the 3MF over the STL and print the wrong part.
    Untracked only - the file is left in place on disk. The generated meshes
    of record remain Front_Bezel_revQ.stl and the Bezel_Fit_Gauge_revQ_*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
    [Front_Bezel_revQ.3mf]
2026-08-30 mech(display-bezel): rev Q - flush aperture, split 1.25/0.80 inset wall
    Third owner change to the OPEN Rev Q bezel. The horizontal opening goes out
    1.00 mm per side and the side wall thickens until its inner face lands on
    it, so the aperture is FLUSH on the left and right - the 1.45 mm rearward
    set-back the skirt stood proud by is gone. The outer envelope is unchanged.
    THE THREE CONSTRAINTS COLLIDED WITH THE LOOP RULE
    opening 32.90 + fixed 35.40 outer + flush -> wall = 1.25 mm exactly
    1.25 / 0.40 = 3.125 extrusions -> not a whole number
    and applying 1.25 uniformly would have dragged the vertical clear opening
    13.60 -> 12.70 and cost another 0.45 mm of lit band, which th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
    [Bezel_Fit_Gauge_revQ.step, Bezel_Fit_Gauge_revQ_GAUGE_I000.stl, Bezel_Fit_Gauge_revQ_GAUGE_I005.stl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]
2026-08-30 mech(display-bezel): generate the Rev Q 3MF, stop re-importing a stale one
    A hand-exported Front_Bezel_revQ.3mf has now been swept into the repo twice
    by `git add -A`, each time carrying SUPERSEDED geometry - it still has the
    two adhesive pads (8 vertices at z = +3.300) and predates both the R3.00
    corner and the flush split wall. Untracking it by hand did not stick,
    because the file is still on disk and the next `git add -A` picks it up
    again.
    Fixed at the root instead of policed:
    - export() now writes mechanical/STL/Front_Bezel_revQ.3mf from the live
    model, alongside the STL, so the tracked 3MF is always the CURRENT
    geometry. 3MF also carries units and per-object settings, which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
    [Decca_Display_Bezel_revQ.f3d, Front_Bezel_revQ.3mf, Front_Bezel_revQ.step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]
2026-08-30 mech(display-bezel): rev Q - the interference fit, and it will not enter
    Fourth owner change to the OPEN Rev Q bezel. The geometry is exactly as
    instructed and fully validated. THE FIT IS NOT, and that is the finding.
    TWO MOVES, both scoped with the owner before modelling.
    1. one extra 0.40 mm wall loop OUTWARD on the LEFT and RIGHT faces only
    outer 35.40 -> 36.20 side wall 1.25 -> 1.65 (4.125 loops)
    2. the top and bottom walls move 1.00 mm out each
    outer 15.20 -> 17.20 inner 13.60 -> 15.60
    Move 1 is applied at the corners as a TRUE OUTWARD OFFSET, which takes the
    outer corner R3.00 -> R3.40. That is not decoration. The inner corner radius
    is (corner_r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
    [Bezel_Fit_Gauge_revQ.step, Bezel_Fit_Gauge_revQ_GAUGE_I000.stl, Bezel_Fit_Gauge_revQ_GAUGE_I005.stl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]
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2026-08-30 mech(display-bezel): rev Q - pull the fit back into range
    Fifth owner change to the OPEN Rev Q bezel, directed after reading the
    fourth change's finding and cross-checked before modelling.
    width 36.20 -> 35.40 (-0.80)
    height 17.20 -> 15.45 (-1.75)
    corner R3.40 -> R4.25 (+25%)
    THIS IS THE FIT THE REVISION NEEDED
    skirt opening 35.20 x 15.30
    width 35.400 +0.100 mm/side interference
    height 15.450 +0.075 mm/side interference
    Both land inside the 0.05-0.15 mm band a thin printed wall takes up by
    FLEXING rather than by pushing on the acrylic, and the smaller vertical
    figure is deliberate - it is resisted by the thinner 0.80 mm w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
    [Bezel_Fit_Gauge_revQ.step, Bezel_Fit_Gauge_revQ_GAUGE_I000.stl, Bezel_Fit_Gauge_revQ_GAUGE_I005.stl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]
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2026-08-30 mech(display-bezel): rev Q - revert the corner radii
    Sixth owner change to the OPEN Rev Q bezel, directed on seeing the front view
    without a print: "I can see without printing that is wrong. Revert the corner
    radiuses, keep the other amends."
    before after
    outer corner R4.250 R3.000
    visible aperture R3.000 R1.750
    everything else unchanged
    WHY R3.00 IS THE CONSISTENT REVERT
    The inner radius is (corner_r - wall_x) and the flush rule makes the face
    opening carry it, so R4.25 put the VISIBLE aperture corner at R3.00. On a
    13.85 mm tall opening that left only 7.85 mm of straight run and the aperture
    read as a rounded slot rather than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
    [Bezel_Fit_Gauge_revQ.step, Bezel_Fit_Gauge_revQ_GAUGE_I000.stl, Bezel_Fit_Gauge_revQ_GAUGE_I005.stl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]
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
